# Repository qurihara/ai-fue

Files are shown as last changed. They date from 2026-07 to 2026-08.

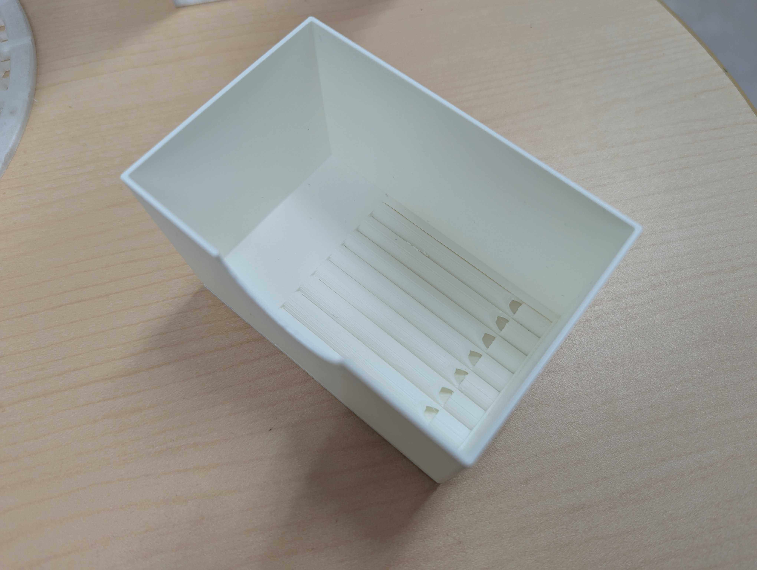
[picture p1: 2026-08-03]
paper/figs/2of3_box.jpg

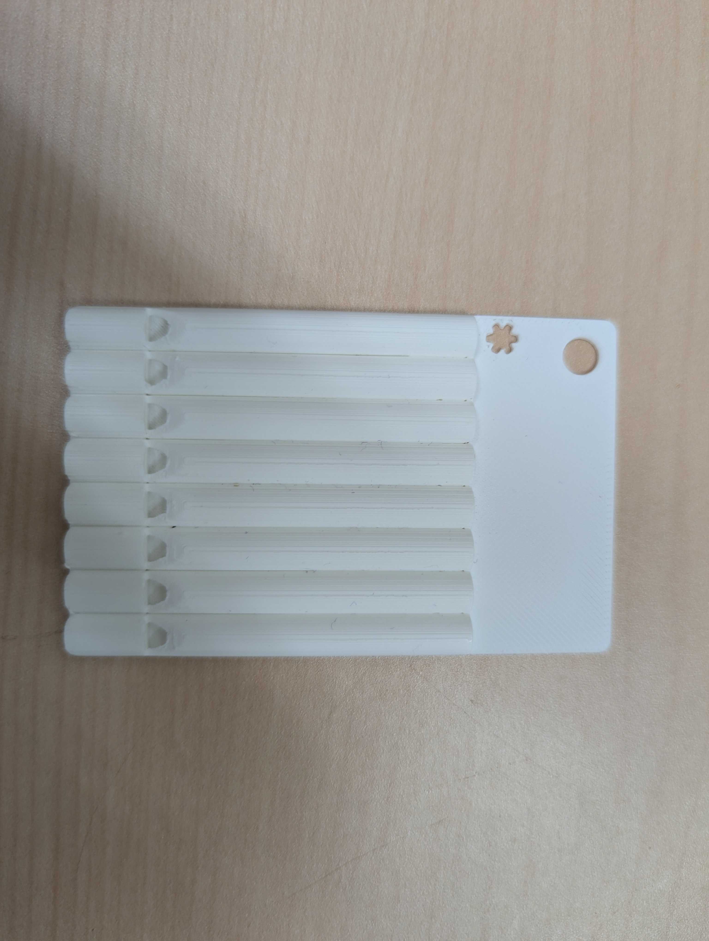
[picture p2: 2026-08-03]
paper/figs/card.jpg

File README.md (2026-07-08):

# ai-fue — AI笛作り (compact scale-flute generator)

3Dプリント可能な「音階笛」をプログラムで生成するツールキット。
[/kuri-lab/AI笛作り] の再始動プロジェクト。母体研究:
[2024夏→秋→2025夏、栗原の楽器作り研究] / https://protopedia.net/prototype/6821

## しくみ

1本の笛 = **発音ヘッド**（`recorderhead.stl`、経験的にF#チューニング済み）
＋ **ボア円柱**（高さ = チューニング表の `length_inside`）。
両者を z=0 に立て x/y 中央寄せし、メッシュを**そのまま結合**する。

> boolean union は使わない。BambuStudio 等のスライサがスライス時に重なりを
> union するため堅牢（2025年に FreeCAD の boolean が繰り返し壊れた反省）。
> 各プリミティブは個別に water-tight。

`recorderhead.stl` が `assets/` に無い間は、パイプライン検証用の
**プレースホルダヘッド**（音響的に無効・要差し替え）で動く。

## チューニング表 `data/tuning_fsharp.csv`

F#5..F#6 の13半音。列: `note, length_outside, length_inside, filename, note_in_c`。
合計100mm（`length_outside + length_inside = 100`）。`length_inside` が印刷する円柱高。

## ToneDecoder 互換

`fue/notes.py` が音階↔MIDI↔hex を一元管理（auth.html とバイト互換）。
「パスワード」= MIDIノート列のhex表記。例 `5558564F` = MIDI 85,88,86,79 = C#6 E6 D6 G5。
https://github.com/qurihara/ToneDecoder

## 使い方

```bash
# パスワード(hex)から笛を生成（リボルバー配置）
python3 fue/build.py --pass-hex 5558564F --style ring

# 音階列から（1UPキノコ）
python3 fue/build.py --notes "C6 G#5 A#5 C6 A#5 C6" --style ring

# パンフルート列
python3 fue/build.py --notes "F#5 G5 A5 B5" --style row

# 別の本体STLを使う（既定は assets/body_v6.stl）
python3 fue/build.py --pass-hex 5558564F --body assets/body_v6.stl
```

出力は `out/` に STL。`--style ring` は回して吹く用の円環、`--style row` はパンフルート列。
F#5..F#6 の外の音は自動で演奏可能オクターブに折り返す。

STLを保存すると同時に、A1 miniでそのまま印刷できる 3mf（`out/<名前>_a1mini.3mf`）も自動で書き出す（`--no-3mf` で抑止）。
既存のSTLから単体で作るときは次のようにする。

```bash
python3 fue/make_3mf.py out/flute_ring_5558564F.stl                 # A1 mini（既定）
python3 fue/make_3mf.py out/compact_calibration_comb.stl --printer h2d   # H2D
```

### 3mf の作り方（導電性ゲームコントローラの方式を踏襲）

Bambu Studio が実際に生成した動作実績のある3mfを骨組みとして持ち、形状とモデル設定だけを差し替える。

- **A1 mini**: 骨組みはコントローラ用3mf。印刷設定（`templates/a1mini_project_settings.config`）は
  単一フィラメント版に固定してあり、「mixed filament is not supported」で弾かれないようにしている。
  ベッド180×180の中央へ自動配置。BambuStudioのCLIでスライスが通り（return code 0）、G-codeまで生成できることを確認済み。
- **H2D**: 骨組みは栗原さんの印刷実績のあるH2D 3mf（`templates/h2d_skeleton.3mf`）。ベッド350×320の中央へ配置。
  H2Dはデュアル押出機のため、フィラメントの最終割り当ては Bambu Studio 側で調整する前提
  （MCP/CLIでのH2D自動スライスは現状通らないため、3mfの整形性のみ検証）。

### 音程測定・較正Webアプリ

`docs/index.html`（GitHub Pagesで公開）。印刷した笛を吹くと周波数と音名を測る。較正コームの各音を測って、
結果をコピーしてClaudeへ貼り付けると、管長と音程の対応表を作れる。音程検出は pitchy を使用（ToneDecoderと同系統）。

## 状態 / TODO

- [x] 音階↔MIDI↔hex マッピング（ToneDecoder互換・自己検証済み）
- [x] チューニング表復元
- [x] straight-bore 笛生成 + row/ring レイアウト + 台座（numpy-stl, water-tight検証）
- [x] 実機の笛本体 v6 を組み込み（本体＋内挿する棒＝length_inside）
- [x] A1 mini 印刷用 3mf の自動生成（CLIスライス通過を確認）
- [ ] 実機チューニング再検証（v6は再設計版のため旧F#表の再測定が必要）
- [x] **コンパクト化（目標①）**: 実績ヘッド＋必要長の閉管。棒も死んだ材料も無し。全長=26.5mm＋管長。管長60mmで全長86.5mm（従来169mmの約半分）
- [x] **管長↔音程の実測較正**（H2Dで4本測定、`f = 91891.5/(L+14.23)`、RMS 0.28mm。片閉じ管の1/4波長則）
- [x] **音階列→音程の合ったコンパクト笛**（`fue/compact.py --notes` / `--pass-hex`）
- [x] **ボア折返しで背を縮小**（`fue/fold.py`、trimesh+manifold3d）。C6は直管112mm→3折り54mm。サポート無しで印刷（要実機確認）
- [ ] 折り補正・細ボア・小ヘッドの実測較正（テストパネル `panel_fold_c6` / `panel_high_octave`）
- [x] **全体を直方体に統一（箱モジュール・A案）**（`fue/box.py`）。3モデル（折りなし/折り1/折り2）とも共通16mmフットプリントの直方体に。実績の円筒ヘッドを角shellで内包し窓面だけ開口＝音は不変で既存較正を流用
- [ ] **角ネイティブ フィッポルヘッド（B案）の実機ボイシング**（`fue/box.py --fipple-comb`）。円筒ヘッド不使用の完全一体押し出し。要 較正やり直し
- [ ] 断面の涙滴/菱形化
- [ ] ② リボルバー/ジェノバ回転機構、③ 3Dモデルへの秘密音階埋め込み

### コンパクト笛（目標①）

```bash
# 較正コーム（管長を変えた笛を一列に。1回印刷して各笛の音程を測り、管長↔音程の表を作る）
python3 fue/compact.py                      # 既定 管長 40,70,100,130mm の4本
python3 fue/compact.py --comb 40,80,120     # 本数を減らして時短

# 単一のコンパクト笛（管長を直接指定）
python3 fue/compact.py --single 60          # 全長 86.5mm

# 音階列から、音程の合ったコンパクト笛を生成（較正済み）
python3 fue/compact.py --notes "C6 D6 E6 F6 G6 A6 B6 C7" --style row   # ドレミの音階笛
python3 fue/compact.py --pass-hex 5558564F --style ring                # パスワードから
python3 fue/compact.py --notes "C6 D6 E6" --printer h2d                # H2D用3mf
```

較正式は `f = 91891.5 / (L + 14.23)`（L=管長mm, f=周波数Hz）。2026/7/1にH2Dで管長40/70/100/130mmの
4本を印刷し実測してフィットした（RMS 0.28mm）。片閉じ管の1/4波長則そのもので、端補正は約14mm。
`fue/compact.py` の `CALIB_K` / `CALIB_DELTA` に格納。再測定で更新できる。

`assets/head_v6.stl` は v6本体の上端26.5mm（吹き口＋ウインドウェイ＋フィッポル窓）を切り出した実績ヘッド。
その下へ必要な長さの中空管と閉端キャップを足す。管長と音程の対応は端補正等で物理式では正確に出ないため、
較正コームを印刷して実測で対応表を作る想定。音程が確定すれば、音階列から直接コンパクト笛の並びを生成できる。

### 箱モジュール（目標①・全体を直方体に）`fue/box.py`

小型笛の外形を1個の直方体に統一してモジュール性を上げる（スタック／タイル／目標③の3Dモデル埋め込みに直結）。
3モデル（折りなし／折り1／折り2）とも**共通フットプリント奥行き16mm**の直方体にする。折るほど背は低く・幅が広い。
実行には `fold.py` / `plenum.py` と同じ trimesh + manifold3d が要る。

```bash
# A案（推奨）: 実績の円筒ヘッドを角shellで内包し、窓面だけ凹ませて開口＝音は不変（既存較正を流用）
python3 fue/box.py --note C6 --N 1     # 折りなし   16×16×100mm
python3 fue/box.py --note C6 --N 2     # 折り1     22×16×69mm
python3 fue/box.py --note C6 --N 3     # 折り2     32×16×57mm
python3 fue/box.py --note C6 --panel   # 3モデルを同じ音で横一列（out/box_panel_C6.stl + a1mini.3mf）

# B案（実験的）: 角ネイティブのフィッポルヘッド（円筒ヘッド不使用の完全一体押し出し）。音は変わるので要 実機ボイシング
python3 fue/box.py --fipple-comb       # flue-labiumオフセットとcutupを振ったボイシング変奏コーム
```

A案は**円筒ヘッドとボアをそのまま内包**するので音響は不変。外側16角柱の四隅は詰め物になるが少量で、
窓（歌口）の1面だけ角shellを凹ませて噴流の前を開けてある（塞ぐと鳴らない）。まずA案で確実に一体化し、
B案は「鳴るボイシング」を変奏コームで見つけてから管長較正に進む2段構え。

### 極小笛 mini-c-v2 と パンフルート（目標①・最小化の本命）`fue/mini.py`

`mini/recorder-mini-c-v2.stl`（7×7×40mmの極小閉管リコーダー・印刷&発音実績）の発音ヘッドを
z=18で切り出し、上に任意長の閉じボアを生やして音程を振る。**flat（寝かせ印刷・窓横向き・丸ボアの
面内蛇行）** が本命で、横向き丸ボアがブリッジで架かるため実質サポートフリー・背が低く安定。

**実機較正（閉端・A1 mini）:** `ENDCORR=1.9`（端補正）＋ `FLAT_FOLD_CORR=3.5mm/折`（折り補正。折り1回
ごとに実効長が縮み音程が上がる。旧compact.pyの3.3mmと一致）。C6/E6は狙い±25c以内でドンピシャ。
発音性のスイートスポットは **N=2（1折り）**。高音(G6〜C7)はヘッド固有コア(≈F7)に近づくと不安定
＝1ヘッドの綺麗な帯域は約1オクターブ。2オクターブにはヘッドのサイズ違い（ファミリー化）が要る。

**端穴の教訓:** 蛇行の折り返し(半径r=3)が端キャップ(旧2mm)を突き抜けて+x端に穴が開いた
→ `H=z_high+r+end_wall(1.2)` で解決（flat_fluteは閉端）。

```bash
python3 fue/mini.py --flat --note C6 --flat 2      # 単一flat笛（面内蛇行N本）
python3 fue/mini.py --flat-comb                    # flat測定コーム(C7/A6/F6/C6)
python3 fue/mini.py --fold-sweep C6 --Ns 1,2,3     # 音固定・折り数スイープ（折り補正/発音性の計測）
python3 fue/mini.py --pan-flute                    # 1オクターブ パンフルート（z方向スタック・一体）
```

**パンフルート `pan_flute`:** 1オクターブ(C6..C7)の管を z方向に積んだ一体ブロック（土台なし・
51×14×56mm）。`mirror_y`（段ごとにy鏡像＝窓を+y/-yへ）でハーモニカ的な配置に、`notes` の並べ替えで
カリンバ配列などに。段間が近い(1mm壁)と音響結合してフラット化・偶数倍音が出るのが課題（互い違い等で回避を検討中）。

**A1 mini 印刷（MCP）:** 定着に必須の設定（ベッド65℃ Textured PEI＋ブリム＋support critical_regions_only）
を持つ `temp/box_brim_profile.json` に、開始gcode(M620 AMSロード＋G29)を移植した `temp/box_brim_ams_profile.json`
でスライス → `bambu-swaplist-batch` skillの `make_swap.py` でswap化 → `print_3mf(ams_slots=[0])`。
反復印刷はflow/振動キャリブOFF・レベリングON（同一フィラメントで流量キャリブ毎回は無駄）。

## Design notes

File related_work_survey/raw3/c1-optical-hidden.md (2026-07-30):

# 反例検証：「隠蔽と可読性の両立は光学符号には原理的に得られない」は成立するか

対象となる主張（CipherFlute側）
- 主張A：符号を担体の外観にまったく現さずに機械可読に保てる。光学的な符号は表面に露出していなければ読めないため日用品に埋めると読めなくなるが、共鳴管は物体の内部空洞として存在でき、外部に必要なのは窓と吸込口という小さな開口だけである。この隠蔽と可読性の両立は光学符号には原理的に得られない構造的な差である。
- 主張B：既知の値を持つ基準素子を同じ物体に同居させ、比で読んで環境変動を打ち消すという構造的な自己補正は、造形物への情報埋め込みの文脈で前例がない。

評価者の反論
- AirCodeは符号を表面下の空隙として埋め、通常照明下では外観を変えず、投影と撮影で機械可読にしている。
- InfraredTagsは肉眼では見えない内部のQRコードやArUcoマーカーを低価格の近赤外カメラで最大250センチメートルから読む。
- したがって「符号が表面に露出していなければ光学的に読めない」という前提自体が偽である。

結論を先に書く。**この反論は正しい。** 主張Aのうち「光学的な符号は表面に露出していなければ読めない」という前提は、一次資料に当たると成り立たない。したがって「隠蔽と可読性の両立は光学符号には原理的に得られない」という主張Aは撤回する必要がある。ただし、両方式には材料と読み取り装置に関する強い制約があり、そこにCipherFluteとの差分が残る。以下、一次資料の記述で確認した内容を順に書く。

---

## 1. 書誌の確認

### AirCode

| 項目 | 内容 |
| --- | --- |
| 題名 | AirCode: Unobtrusive Physical Tags for Digital Fabrication |
| 著者 | Dingzeyu Li, Avinash S. Nair, Shree K. Nayar, Changxi Zheng（Columbia University） |
| 会議 | Proceedings of the 30th Annual ACM Symposium on User Interface Software and Technology（UIST 2017） |
| 年・ページ | 2017年、449〜460ページ |
| DOI | 10.1145/3126594.3126635 |

確認先
- Crossref（DOIの解決先）：https://api.crossref.org/works/10.1145/3126594.3126635
- DBLP：https://dblp.org/search/publ/api?q=AirCode%20Unobtrusive%20Physical%20Tags&format=json
- 著者公開版（arXiv、本文と補足資料を含む）：https://arxiv.org/abs/1707.05754 および https://arxiv.org/pdf/1707.05754

以下の引用はすべてarXiv版（1707.05754v2）の本文から取った。arXiv版の1ページ目に `DOI: https://doi.org/10.1145/3126594.3126635` が印字されており、UIST 2017版と同一の原稿であると判断した。なお、ACM Digital Libraryの本文ページは取得時にHTTP 403を返したため、出版社ページ本体は読めていない。

### InfraredTags

| 項目 | 内容 |
| --- | --- |
| 題名 | InfraredTags: Embedding Invisible AR Markers and Barcodes Using Low-Cost, Infrared-Based 3D Printing and Imaging Tools |
| 著者 | Mustafa Doga Dogan, Ahmad Taka, Michael Lu, Yunyi Zhu, Akshat Kumar, Aakar Gupta, Stefanie Mueller（Aakar Guptaのみ Facebook Reality Labs、他はMIT CSAIL） |
| 会議 | CHI Conference on Human Factors in Computing Systems（CHI '22）、2022年4月29日〜5月5日、New Orleans |
| 論文番号・ページ | Article 269、12ページ |
| DOI | 10.1145/3491102.3501951 |

確認先
- DBLP：https://dblp.org/search/publ/api?q=InfraredTags+Embedding+Invisible+AR+Markers&format=json
- 著者公開版（MIT CSAIL HCI Engineering Group）：https://hcie.csail.mit.edu/research/infraredtags/infraredtags.html
- 本文PDF：https://groups.csail.mit.edu/hcie/files/research-projects/infraredtags/2022-CHI-InfraredTags-paper.pdf

以下の引用はこの著者公開版PDFから取った。

---

## 2. AirCodeのタグは肉眼で見えないのか

### 論文が外観について述べていること

見えないと明言している。原文をそのまま引く（訳は筆者による）。

図1のキャプション（1ページ目）
> "An AirCode tag is embedded inside the object, without changing its geometry or appearance. (d) The fabricated tag is invisible under environmental lighting."

（AirCodeタグは物体の内部に埋め込まれ、その形状も外観も変えない。(d) 製造されたタグは環境光の下では見えない。）

概要
> "the air pockets affect only the scattering light transport under the surface, and thus are hard to notice to our naked eyes. But, by using a computational imaging method, the tags become detectable."

（空気ポケットは表面下の散乱光輸送だけに影響するので、肉眼では気づきにくい。しかし計算撮像の手法を使えば、タグは検出可能になる。）

不可視性を数値で担保している箇所（Human Vision Sensitivityの節）
> "Exploiting the results of [2], we choose air pocket size and depth such that the resulting contrast (or the change of surface radiosity) is within 5%. This way, by construction the air pockets are invisible to the human eye"

（[2]の結果を利用し、生じるコントラスト（すなわち表面放射輝度の変化）が5%以内になるように空気ポケットの大きさと深さを選ぶ。こうすることで、構成上、空気ポケットは人間の目には見えないものになる。）

ここでいう5%は、Bijlらの心理物理実験で示されたガウシアン状のぼやけた斑点に対する人間のコントラスト感度閾値である。論文はさらに、極端な照明下でも見えないままであることを実験で確認したと書いている（補足資料の図18のキャプション）。

> "Under different extreme lighting, the embedded AirCode tags remain invisible. We capture these photos while moving a strong light source around the statue and the mug. The light source we use is a 45W photography light bulb at 6500K."

（さまざまな極端な照明の下でも、埋め込まれたAirCodeタグは見えないままである。これらの写真は、強い光源を彫像とマグカップの周りで動かしながら撮影した。使用した光源は6500Kの45Wの撮影用電球である。）

### 判定

「AirCodeのタグは通常照明下で肉眼に見えない」という評価者の指摘は、論文の記述どおりであり、正しい。

---

## 3. AirCodeの読み出しに何が必要か

### 装置の構成

Fabrication and Imaging Setupの節に明記されている。

> "For global component imaging, we project checkerboard illumination patterns using a Mitsubishi PK20 DLP projector (800×600 resolution). Images were captured using a Point Grey Grasshopper3 monochrome linear camera (2048×1536 resolution). We use a monochrome camera to avoid Bayer demosaicing, as we consider scattering at a single wavelength."

したがって必要なのは、DLPプロジェクタ1台（三菱PK20、800×600）と、モノクロ産業用カメラ1台（Point Grey Grasshopper3、2048×1536）である。さらに次の2つが加わる。

偏光板について（Polarizationの節）
> "We mitigate the negative effect of specular light by placing linear polarizers in front of both the projector and the camera lens [41, 6]. ... we place the two polarizers that are out of phase with each other to maximally eliminate the specular light."

（プロジェクタとカメラレンズの両方の前に直線偏光板を置く。2枚の偏光板は互いに位相をずらして配置し、鏡面反射光を最大限に取り除く。）

波長について（Wavelength Choiceの節）
> "we take advantage of our full control of the projector and illuminate the object with the longest light wavelength, the red light. ... In all of our imaging experiments, we use red light unless otherwise specified."

（プロジェクタを完全に制御できることを活かし、最も長い波長である赤色光で物体を照らす。すべての撮像実験では、特に断らない限り赤色光を使う。）

つまり、プロジェクタとカメラと交差偏光板からなる据え置きの光学ベンチを構成し、赤色の市松模様を何度もずらしながら投影して、NayarらのDirect-Global分離を行う。手に持って向けるだけの装置ではない。

### 撮像にかかる時間

Discussion and Future Workの節に明記されている。

> "the capturing process still takes 3-4 minutes. This is because a checkerboard sweeping takes about 10 seconds. To reduce imaging noise, we take multiple sweeps and average them."

（撮像の処理には依然として3〜4分かかる。市松模様の走査1回に約10秒かかるためである。撮像ノイズを減らすため、複数回の走査を行って平均する。）

さらにノイズ対策として、Fabrication and Imaging Setupの節に次の記述がある。

> "Under low-light, the output from this camera sensor is noisy. We, therefore, averaged 16 images for each projected checkerboard pattern."

（低照度ではこのカメラセンサの出力はノイズが多い。そのため、投影する市松模様1枚ごとに16枚の画像を平均した。）

InfraredTags側もAirCodeの所要時間を表1で「3-4 minutes」と記載しており、2つの一次資料で一致している。

### 物体との距離

**確認できなかった。** 論文には、カメラおよびプロジェクタと物体との距離を示す数値が見当たらない。論文中に出てくる75センチメートルという数値は、カメラの距離ではなく、人間がタグを見るときの標準的な視距離として不可視性の解析に使われたものである。

> "In our problem, an AirCode tag has a size typically around 2cm. When viewed from a normal distance (e.g., around 75cm) away, the view angle spanned by the codes is around 100 min arc."

代わりに論文が示しているのは角度の許容範囲である。

> "Figure 17 shows that our method is able to read the subsurface codes for rotations in the range of [-40, 40] with respect to the camera view direction."

（図17は、カメラの視線方向に対して[-40度, 40度]の範囲の回転であれば表面下の符号を読めることを示している。）

### 必要な照明条件

論文は読み取り時の周囲照度を数値で規定していない。ただし方式上、プロジェクタが投じる構造化光そのものが照明であり、そのうえで低照度でのセンサノイズを16枚平均で潰していると書かれている。したがって、周囲の環境光は制御された（暗めの）状態が前提だと読める。この点は論文が明示的に書いていないので、推測であることを断っておく。

### 材料と製造装置の制約（重要）

AirCodeが機能する条件は、材料が均質で半透明であることに強く依存する。

> "We fabricated objects with subsurface air pocket tags using Stratasys Eden260VS, a PolyJet 3D printer with 16-micron layer accuracy (Z direction) and 200-micron planar accuracy (XY plane). We use a white opaque material (VeroWhitePlus, RGD835) and a water-soluble support material (SUP707)."

限界について、論文自身が次のように書いている。

> "Our analysis assumes that the 3D printing material is largely homogeneous and semitransparent. While this assumption is valid for many 3D printing systems that fabricate with plastic materials, other printers cannot produce nearly homogeneous materials. For example, many fused-deposition modeling (FDM) printers deposit relatively thick filaments, and the printed object is not homogeneous. Moreover, it is a common postprocess to paint the surface of a 3D printed object. While our method can account for semitransparent paint, it will fail if the paint is completely opaque."

（我々の解析は、3Dプリント材料がおおむね均質で半透明であることを仮定している。この仮定はプラスチックで造形する多くの3Dプリント方式では妥当だが、他のプリンタではほぼ均質な材料を作れない。たとえば多くの熱溶解積層方式のプリンタは比較的太いフィラメントを積むため、造形物は均質にならない。さらに、3Dプリント物の表面を塗装するのは一般的な後処理である。半透明の塗料なら我々の手法で扱えるが、完全に不透明な塗料であれば失敗する。）

またタグの深さは表面直下に限られる。透過アルベドの解析から `dmax = 3mm`、機械的強度から `dmin = 1mm` と定めている。タグの寸法は2センチメートル角で約106ビット、5センチメートル角で500ビット超である。

---

## 4. InfraredTagsは肉眼で見えないのか

見えないと明言している。概要の冒頭に次のようにある。

> "We present InfraredTags, which are 2D markers and barcodes imperceptible to the naked eye that can be 3D printed as part of objects, and detected rapidly by low-cost near-infrared cameras."

（InfraredTagsを提案する。これは肉眼では知覚できない2次元マーカーおよびバーコードであり、物体の一部として3Dプリントでき、低価格の近赤外カメラで素早く検出できる。）

不可視性の担保も、AirCodeと同じ5%のコントラスト閾値で行っている（Shell Thicknessの節）。

> "our goal is to find a value that achieves a contrast in the image smaller than 5% when the image is taken with a regular camera (i.e., with an IR cut-off filter). ... We chose 5% because this is the contrast value at which humans cannot differentiate contrast anymore [3]."

具体的な殻の厚さは表2にある。単一材料（IR PLAのみ）で殻1.08ミリメートル・符号2.00ミリメートル、多材料（IR PLA＋白PLA）で殻1.32ミリメートル・符号0.50ミリメートル、IR PLA＋黒PLAで殻1.08ミリメートル、IR PLA＋青PLAで殻1.20ミリメートルである。

ここで見落としてはならないのは、母材そのものの制約である。

> "We acquired the IR filament from manufacturer 3dk.berlin [1] (ca. $5.86/100g). It is made out of polylactic acid (PLA) ... To the naked eye, the filament has a slightly translucent black color, however, when 3D printed in multiple layers it looks opaque."

さらに議論の節で、色が黒に限られることを認めている。

> "While we only used black IR PLA in this project, manufacturers could produce filaments of other colors that have similar transmission characteristics"

つまり、物体全体を特定メーカーの黒い赤外透過フィラメントで印刷しなければならない。任意の材料・任意の色の日用品に後から埋めることはできない。

---

## 5. InfraredTagsの読み出しに何が必要か

### 市販のスマートフォン単体で読めるのか

**読めない。追加の撮像モジュールが要る。** 論文は明確に、専用の後付けモジュールを自作したと書いている。

> "Today, several recent smartphones already come with an IR camera either on the front (Apple iPhone X) or the rear (OnePlus 8 Pro), however, the phones' APIs may not allow developers to access these for non-native applications. Furthermore, not all mobile phones contain such a camera at the moment. To make our method compatible independent of the platform, we built an additional imaging add-on that can easily be attached to existing mobile phones."

（今日、いくつかの最近のスマートフォンは前面（iPhone X）または背面（OnePlus 8 Pro）に赤外カメラを備えている。しかし、電話機の提供する応用機能の窓口が、開発者に対してこれらを純正以外の応用から使わせない可能性がある。さらに、現時点ではすべての携帯電話がそうしたカメラを備えているわけではない。手法を機種に依存しないようにするため、既存の携帯電話に簡単に取り付けられる追加の撮像用付属品を作った。）

モジュールの構成（Attaching the IR camera moduleの節）
> "our add-on contains an infrared camera (model: Raspberry Pi NoIR). This camera can see infrared light since it has the IR cut-off filter removed that normally blocks IR light in regular cameras. Additionally, to remove the noise from visible light and improve detection, we added a visible light cut-off filter, as well as 2 IR LEDs (940nm) which illuminate the object when it is dark. This add-on has two 3D printed parts: a smartphone case from flexible TPU filament that can be reprinted based on the user's phone model, and the imaging module from rigid PLA filament that can be slid into this case. The imaging module has a Raspberry Pi Zero board and a battery and weighs 132g."

したがって必要なものは、赤外カットフィルタを外したカメラ（Raspberry Pi NoIR）、可視光カットフィルタ、940ナノメートルの赤外発光ダイオード2個、Raspberry Pi Zero基板、電池、そしてTPUで印刷した専用ケースである。

加えて、処理は端末上で完結しない。

> "the imaging module continuously streams the images to our image processing server. If the server detects any tags, it sends the location and the encoded message to the smartphone app to show to the user."

（撮像モジュールは画像を我々の画像処理サーバへ連続的に送り続ける。サーバがタグを検出すれば、位置と符号化されたメッセージをスマートフォンの応用へ送り、利用者に表示する。）

なお論文は、赤外カットフィルタを手で外した通常のUSBウェブカメラでも読めると述べている。

> "Even conventional USB webcams for personal computers can be used for this purpose by manually removing their infrared cut-off filter."

いずれにせよ、改造していない市販のスマートフォンだけでは読めない。

### 費用と重さ

- 赤外透過フィラメント：100グラムあたり約5.86米ドル（"ca. $5.86/100g"）
- Raspberry Pi NoIRカメラ：約20米ドル（"such as the Raspberry Pi NoIR ($20)"）
- 比較対象として挙げられている高価な赤外カメラ：FLIR ONE Proが400米ドル超（"may cost more than $400"）
- 撮像モジュールの重さ：132グラム（"weighs 132g"）
- **モジュール全体の合計費用は確認できなかった。** 論文はカメラ単体とフィラメントの価格しか書いておらず、可視光カットフィルタ、Raspberry Pi Zero、電池を含む総額を示していない。

### 必要な近赤外の照度

Lighting conditionsの節に数値がある。

> "We measured the minimum NIR intensity needed to detect 4x4 ArUco markers using a lux meter which had a visible light cut-off filter (720nm) attached. We found that just a tiny amount of NIR is sufficient for this, i.e., that at least 1.1 lux is needed for single-material prints, and 0.2 lux for multi-material prints."

（720ナノメートルの可視光カットフィルタを取り付けた照度計を使い、4×4のArUcoマーカーを検出するのに必要な最小の近赤外強度を測った。ごくわずかな近赤外で十分であり、単一材料の造形物には少なくとも1.1ルクス、多材料の造形物には0.2ルクスが必要だと分かった。）

続けて、実運用の照明環境についても書いている。

> "Because sunlight also contains NIR wavelengths, the tags are detectable outdoors and also in an indoor areas that have windows during daytime. We also noticed that many lamps used for indoor lighting emit enough NIR to detect the codes at nighttime (e.g., 1.5 lux in our office). Furthermore, the IR LEDs on our imaging module (Section 4.2) provide high enough intensity to sufficiently illuminate multi-material markers even in complete darkness"

つまり、屋外や窓のある屋内では太陽光の近赤外成分で足り、夜間も一般的な室内照明の近赤外成分（著者らの居室で1.5ルクス）で足り、完全な暗闇でもモジュール上の赤外発光ダイオードで多材料の符号なら読める。単一材料の場合は完全な暗闇では不足すると認めている。

> "In the future, brighter LEDs can be added to support single-material prints in such difficult detection scenarios."

### 読み取り距離

概要に「250センチメートル」がある。

> "Our evaluation shows that the tags can be detected with little near-infrared illumination (0.2lux) and from distances as far as 250cm."

本文のDistanceの段落によれば、この評価は4×4のArUcoマーカーについて、マーカーの幅を10ミリメートルから80ミリメートルまで振って最大検出距離を測ったものである。

> "The marker size range we evaluated was 10-80mm for 4x4 ArUco markers, which would translate to a range for 42-336mm for 21x21 QR codes (can store up to 25 numeric characters). The results are given in Figure 10a, which shows that multi-material codes can be detected from further away than single single-material ones."

**どのマーカー寸法で250センチメートルに達したのかは、図10aが図版であるため本文の文字情報からは確認できなかった。** 250センチメートルは評価した範囲の最大値であり、マーカーの大きさに依存する値である点は注意が要る。QRコードの検出精度を測った実験は15センチメートルから80センチメートルの範囲で行われている。

> "We captured 124 images of a 21x21 QR code from different distances (15-80cm from the camera)."

その条件でのQRコードの復号精度は、フィルタのパラメータの組み合わせを3通り試して79.03%である（表3）。

### 復号にかかる時間

> "On average, it takes 6ms to decode a 4x4 ArUco marker and 14ms to decode a 21x21 QR code from a single original frame. The images we use as input are 512x288 pixels"

単一のフレームから復号するので、実時間で動く。これはAirCodeの3〜4分と比べて桁違いに速く、CipherFluteの吹奏による読み出しよりも速い。

### 最小のマーカー寸法

> "we determined that the smallest detectable 4x4 ArUco marker printable is 9mm wide for single-material prints and 6mm wide for multi-material prints."

---

## 6. 日用品に埋め込んだ実例はあるか

### AirCode

論文が示す実物は、Moai像、三角形の引き出し、マグカップ、iPhoneを支える猫の置物、ケーブル収納、工具立て、そして紙の透かしである。マグカップや引き出しは日用品と呼べる。ただし、これらはすべて著者らがPolyJetプリンタ（Stratasys Eden260VS）でVeroWhitePlusを使って自ら造形したものである。既製の日用品にあとから埋め込んだ例ではない。

> "We demonstrate with two objects (see Figure 3). In the triangular drawer (Figure 3-a), we embed three different AirCode tags on each side of the drawer. In the mug (Figure 3-b), we embed six tags under the curved surface of the mug."

紙への拡張だけは材料が異なる。

> "here we embed watermarks in a paper by stacking a few thinner papers together. We carve a pattern on one paper and sandwich it in other papers, and then stick all thin papers together."

### InfraredTags

応用の節で、家庭用スピーカー、サーモスタット、無線ルータ、マグカップ、ゲーム用のハンドルを示している。

> "In the application shown in Figure 7a and b, a user points their smartphone camera at the room and smart home appliances are identified through their InfraredTags, which are imperceptible to the human eye."

> "Figure 9 shows a 3D printed wheel with no electronics, being used as a game controller."

これらも、方式の制約上、黒い赤外透過PLAで印刷した筐体でなければならない。論文は既製の家電の元の筐体に埋め込んだとは書いていない。

### まとめ

**両者とも日用品の形をした造形物への埋め込みは示している。ただし、どちらも「その方式が要求する特定の材料で自ら造形した物体」に限られており、任意の材料でできた既製の日用品にあとから埋める例は示していない。**

---

## 7. 判定

### 主張Aについて

**反論は正しい。主張Aは成立しない。**

主張Aの中核は「光学的な符号は表面に露出していなければ読めない」という前提にある。この前提は偽である。AirCodeは表面から1〜3ミリメートルの深さにある空気ポケットを、投影と撮影による大域成分の分離で読む。InfraredTagsは表面から1.08〜1.32ミリメートルの殻の内側にあるQRコードやArUcoマーカーを、近赤外カメラで読む。どちらも肉眼のコントラスト閾値5%を下回るように設計されており、外観を変えていない。したがって「隠蔽と可読性の両立は光学符号には原理的に得られない」とは書けない。

さらに、主張Aの言い回しにはCipherFluteにとって不利な事実が隠れている。AirCodeとInfraredTagsは外部に開口をまったく必要としない。CipherFluteは窓と吸込口という2つの開口を外気に露出させなければならない。「外部に必要なのは小さな開口だけである」という言い方は、開口が不要な方式が実在する以上、優位性の主張にならない。むしろ外観の点では、CipherFluteのほうが露出が多い。

### 主張Bについて

**この反例の検証中に、主張Bも強い形では成り立たないことが分かった。**

AirCodeは、符号の格子の中に「既知の値を持つセル」を散らして配置し、それを使って復号器を現場で訓練している。Code Generationの節に次のようにある。

> "More remarkably, we place a few known bits. The blue cells are always filled with printing material as bits of 1, while the orange cells are filled with air pockets to indicate bits of 0. These bits are scattered on the grid to enable on-the-fly supervised training for our decoding algorithm."

（さらに注目すべきこととして、いくつかの既知のビットを配置する。青いセルは常に造形材料で埋めて1のビットとし、オレンジのセルは空気ポケットで埋めて0のビットとする。これらのビットは格子上に散らして配置され、復号アルゴリズムのその場での教師あり学習を可能にする。）

Decodingの節では、この既知ビットで訓練した分類器の特徴量を局所的な明るさの変化に合わせて正規化するとも書いている。

> "Each feature vector is normalized to adapt to local intensity changes."

これは、既知の値を持つ基準素子を同じ物体に同居させ、データと同時に読んで撮像条件と造形の個体差を打ち消す仕組みである。CipherFluteの基準笛とは、補正する物理量（一方は画像の明るさ、他方は音速すなわち気温と息の強さ）も、補正の演算（一方は分類器の訓練と正規化、他方は周波数の比）も異なる。しかし「同一物体に既知の基準を同居させて環境変動を吸収する」という構造そのものには前例がある。したがって「前例がない」とは書けない。「既存例は撮像系の変動を吸収するために使われており、担体の物理量（気温による音速変化）を打ち消すために基準素子の比を使った例は見当たらない」という程度まで主張を弱める必要がある。ただし、造形物への情報埋め込みの文献を網羅的に調べたわけではないので、この弱めた形が成立するかどうかは別途の確認が要る。

---

## 8. CipherFluteに残る差分

主張Aは撤回するとして、では何が残るのか。依頼された4つの観点で整理する。誇張も過小評価もせずに書く。

### 8.1 装置の必要性

**ここが最大の残る差分である。**

- AirCodeは、DLPプロジェクタ（三菱PK20）、モノクロ産業用カメラ（Point Grey Grasshopper3）、両者の前に置く交差した直線偏光板からなる据え置きの光学ベンチを必要とする。手持ちで物体に向けるという使い方はできない。
- InfraredTagsは、赤外カットフィルタを外したカメラ、可視光カットフィルタ、940ナノメートルの赤外発光ダイオード2個、Raspberry Pi Zero、電池を組んだ132グラムの付属品をスマートフォンに装着する必要がある。さらに画像処理はサーバ側で行う構成になっている。改造していない市販スマートフォン単体では読めない。
- CipherFluteは、利用者が既に持っているスマートフォンのマイクだけで読む。追加の部品も、改造も、専用のフィラメントも要らない。

**この差は「原理的」ではなく「装置の入手性と携帯性」の差である。** 光学で隠しつつ読むことは可能だが、そのために専用の撮像系が要る。音響で読むのは、既存の端末に既に載っている入力装置で足りる。主張は「光学では不可能」ではなく「光学では専用装置が要るが、音響では要らない」という形に書き換えるべきである。

なお、CipherFlute側の論文はこの点を既に第4章の性質(4)として「特別な機器なしに、息とスマートフォンだけで復元できる」と書いている。この記述は一次資料に照らして妥当であり、変更の必要はない。

### 8.2 読み出しの時間

**ここはCipherFluteが一方的に有利とは言えない。正直に書く必要がある。**

- AirCodeは3〜4分かかる。CipherFluteより明らかに遅い。
- InfraredTagsは1フレームから復号し、4×4のArUcoマーカーで6ミリ秒、21×21のQRコードで14ミリ秒である。実時間で動く。CipherFluteは笛を1本ずつ吹いて読むため、本数に比例した秒単位の時間がかかる。**InfraredTagsのほうが速い。**

したがって「光学は遅い」と一般化してはならない。AirCodeに限れば遅いが、それはAirCodeが構造化光の掃引を必要とするからであり、InfraredTagsはその問題を解いている。InfraredTags自身が表1で、AirCodeの「3-4 minutes」やInfraStructsの「2 minutes for a 100x100 pixel scan」に対して自分たちは「On the order of milliseconds」だと明示的に比較している。

### 8.3 外観

**ここもCipherFluteが有利とは言えない。**

- AirCodeとInfraredTagsは、いずれも肉眼のコントラスト閾値5%を下回るように設計されており、外部に開口をまったく持たない。外観上、符号の存在はどこにも現れない。
- CipherFluteは、窓と吸込口という2つの開口を外気に露出させなければならない。開口自体は小さいが、ゼロではない。

CipherFluteに残る外観上の利点は、符号の見えなさではなく、**材料と色の自由度**である。

- AirCodeは、均質で半透明な材料（PolyJet方式のVeroWhitePlusなど）を要求する。論文自身が、熱溶解積層方式では材料が均質にならないこと、不透明な塗装をすると失敗することを限界として認めている。
- InfraredTagsは、特定メーカーの赤外透過PLA（3dk.berlin製、黒）で物体全体を印刷することを要求する。論文自身が、他の色は今後の課題だと書いている。加えて、同じメーカーの異なる時期のスプールで透過特性が変わったので、スプールごとに較正をやり直すよう勧めている。
- CipherFluteは共鳴管の形状だけで符号を担うので、材料の光学的性質に依存しない。PLA、PETG、TPU、金属、どの色でも原理的には成り立つ。この点は、家庭用の3Dプリンタで、手元にある任意のフィラメントで作れるという実用上の差につながる。

したがって主張は「外観に符号が現れない」ではなく、「符号の担い手が形状であるため、担体の材料と色を選ばない」と書き換えるべきである。

### 8.4 読み出しの行為

**ここは構造的な差として残る。**

AirCodeもInfraredTagsも、読み出しは無音であり、所有者の身体的な関与を必要としない。装置を持ち、どこに向ければよいかを知っている者が、物体に触れることなく、所有者に気づかれずに読める。AirCodeは物体を光学ベンチに置く必要があるので実際には持ち去りが要るが、InfraredTagsは最大250センチメートル離れた位置から読める。

CipherFluteは、誰かが息を吹き込まなければ音が出ない。読み出しは必ず能動的な身体行為を伴い、その行為は音として周囲に露出する。これは秘匿の仕組みではなく手続きの性質であり、CipherFlute側の論文が既に性質(3)として「正規の読み出しが目立つ」と書いているとおりである。立会人の前で儀式として実行できるという利点も、この性質から出る。

ただし、この差を過大評価してはならない。CipherFlute側の論文が第4章で自ら明示しているとおり、管の長さは静的な形状なので、攻撃者は吹かずにノギスや透過撮像で読める。つまり「吹かなければ読めない」わけではない。残るのは「正規の手続きが音を伴う」という一点だけであり、攻撃者に対する防御にはならない。

なお、InfraredTags自身も発見しやすさの問題を限界として認めている。

> "For InfraredTags to be detected, the user should orient the near-infrared camera such that the embedded marker is in the frame. However, similar to related projects such as AirCode [20] and InfraStructs [34], this might be challenging since the marker is invisible to users and thus they might not know where exactly on the object to point the camera at."

これは光学方式にとって不利な点だが、CipherFluteの窓と吸込口も同じ問題を抱える（どの開口を吹けばよいか分からない）ので、差分にはならない。

---

## 9. 論文への具体的な反映案

1. 「隠蔽と可読性の両立は光学符号には原理的に得られない」という文は削除する。一次資料に照らして偽である。
2. 代わりに、光学方式との差を次の3点に絞って書く。第一に、読み出し装置が既存のスマートフォンのマイクで足り、専用の撮像系（プロジェクタとカメラの光学ベンチ、または赤外カメラ付属品）を必要としないこと。第二に、符号の担い手が形状であるため、担体の材料と色を選ばず、任意の家庭用フィラメントで作れること。第三に、正規の読み出しが能動的な吹奏を伴い、音として露出すること。
3. 読み出しの速さは差分として主張しない。InfraredTagsはミリ秒で読む。
4. 外観については「符号がまったく見えない」を主張しない。窓と吸込口は露出する。AirCodeとInfraredTagsは開口ゼロである。
5. InfraredTags（Doganら、CHI 2022、DOI 10.1145/3491102.3501951）を関連研究に追加する。現行稿はAirCode（文献[3]）とInfraStructs（文献[4]）しか挙げていないが、InfraredTagsは「安価な装置で速く読める隠された光学符号」という最も強い比較対象であり、これを挙げずに光学方式の限界を論じると、査読で必ず指摘される。
6. 基準笛の自己補正について「前例がない」とは書かない。AirCodeが既知ビットによる現場訓練という形で同種の仕組みを持っている。「撮像系の変動を吸収する既知ビットの例はあるが、担体の物理量（気温による音速変化）を比で打ち消す例は見当たらない」という限定した書き方にする。

---

## 10. 確認できなかったこと

- ACM Digital Libraryの本文ページは、AirCode・InfraredTagsとも取得時にHTTP 403を返したため読めていない。書誌はCrossrefとDBLPで、本文は著者公開版（arXivおよびMIT CSAILの公開PDF）で確認した。
- AirCodeにおける、カメラおよびプロジェクタと物体との距離は、論文に数値が見当たらない。
- AirCodeの読み取り時に必要な周囲照度は、論文に数値が見当たらない。
- InfraredTagsの撮像モジュール全体の合計費用は、論文に記載がない。カメラ単体20米ドルとフィラメント100グラム約5.86米ドルのみが示されている。
- InfraredTagsの250センチメートルという最大検出距離が、どのマーカー寸法に対応するかは、図10aが図版であるため文字情報から特定できなかった。評価したマーカー幅の範囲は10〜80ミリメートルである。
- 主張Bを弱めた形（担体の物理量を基準素子の比で打ち消す例の有無）については、造形物への情報埋め込みの文献を網羅的に調べていないため、成立するかどうかを判定していない。

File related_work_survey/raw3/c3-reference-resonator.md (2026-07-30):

# C3　反例検証：基準共鳴器を同居させて比で読み共通モードを除く設計

対象とする主張は、CipherFluteの新規性主張のうち「既知の値を持つ基準素子を同じ物体に同居させ、比で読んで環境変動を打ち消すという構造的な自己補正は、造形物への情報埋め込みの文脈で前例がない」という部分である。評価者はこれに対して、Smith と Senturia が1995年に同じ構成を「conventional sensing setup」と呼んでいること、および2014年に表面弾性波共鳴器の一方を基準に使う無線受動センサが実装されていることを反例として挙げた。

調査日は2026年7月30日である。

## 0. 結論

反例は正しい。評価者が挙げた2件はどちらも実在し、内容も評価者の説明どおりである。とくにSmithとSenturiaの論文は、基準共鳴器と検出共鳴器の二つを置いて比を取る構成を、自分たちの新規性としてではなく前提となる「従来の構成」として明示的に記述している。したがって「基準素子を同居させ比で読んで共通モードを打ち消す」という着想そのものをCipherFluteの新規性として主張することは成立しない。ただし後述するとおり、主張を「共鳴管を3Dプリントで一体成形した情報担体における実装と、そのもとでの読み取り誤り率の測定」に限定して書き換えれば、誇張のない形で残せる。

## 1. 反例1：Smith と Senturia（1995年）

### 1.1 書誌の確定

- 著者は James H. Smith（Sandia National Laboratories）と Stephen D. Senturia（Massachusetts Institute of Technology）である。
- 題名は "Self-Consistent Temperature Compensation for Resonant Sensors with Application to Quartz Bulk Acoustic Wave Chemical Sensors" である。
- 掲載は Proceedings of the International Solid-State Sensors and Actuators Conference（TRANSDUCERS '95）、開催地はスウェーデンのストックホルム、掲載ページは724ページから727ページ、発行者は IEEE、発行年は1995年である。
- デジタルオブジェクト識別子は 10.1109/SENSOR.1995.721934 である。

確認先は次の2つである。

- 著者所属機関が公開している原稿本文（Sandia National Laboratories）: https://www.sandia.gov/app/uploads/sites/145/2021/11/5_7SelfConsistent.pdf
- Crossref の書誌レコード: https://api.crossref.org/works/10.1109/sensor.1995.721934

Sandiaが公開している原稿の1ページ目の版面上部には "Transducers, June 1995." と刷られており、Crossrefの登録内容と一致する。本文はこのPDFから `pdftotext -layout` で抽出して読んだ。

### 1.2 原文の記述

温度補償の節の冒頭に次の一文がある。

> "The temperature compensation scheme uses the conventional sensing setup of two resonators, a sense resonator (with frequency f1) and a reference resonator (with frequency f2)."

評価者が指摘した "conventional sensing setup" という語は、この文のとおり原文に存在する。著者自身が、検出共鳴器と基準共鳴器を二つ置く構成を「従来からある構成」と位置づけたうえで、その上に自分たちの回路上の工夫を載せている。

比を取ることについては、次の記述がある。

> "Thus the result of the counting operation (N) can be represented by the divider (D) and the ratio of f1 to f2."

そして共通モードの除去については、式 `N = D f1/f2 = D f01 T(t) X(x) / (f02 T(t) X(0)) = D f01 X(x) / f02` を導いたうえで、次のように述べている。

> "Thus the first-order effects of temperature and other common mode interferents can be eliminated from the final signal."

温度依存項 `T(t)` が分子と分母で同じであるために比を取ると消える、という論法であり、CipherFluteの基準笛の説明とまったく同じ構造である。

さらに、著者たちは1995年の時点ですでにこの種の手法に先行研究があることを明示している。

> "A number of methods for temperature compensation utilizing two resonators have been described in the literature [1, 2]."

> "A method similar to the compensation scheme used here has been previously described for use with external frequency counters, although no temperature-stability data was reported [4]."

参照されている文献は、[1] が Slobodnik, Colvin, Roberts, Silva, "A Digitally Compensated SAW Oscillator", Proc. 1981 Ultrasonics Symposium, pp. 135–138、[2] が Alder, Fox, Przybylko, Rezgui, Snook, Analyst, 114(9), p. 1163, 1989、[4] が Joshi, "A Temperature Compensated High Voltage Probe Using Surface Acoustic Waves", Proc. 1982 Ultrasonics Symposium, pp. 317–320 である。つまり二共鳴器による温度補償という考え方は、1995年よりさらに10年以上さかのぼる。

なお、この論文自身の新規性は「比を取ること」ではなく「基準共鳴器の周波数を分周して周波数カウンタの時間基準そのものに使い、比の計算を外部の演算ではなくカウント動作の中で行い、それを共鳴器駆動用の集積回路に載せたこと」である。結論部でも、比較対象は二つの外部カウンタの読みを引き算する従来手法である。

> "This circuit has shown approximately an order of magnitude improvement in compensation over the conventional frequency-subtraction temperature compensation method using external frequency counters."

化学センサとしての使い方についても、被覆した検出用共鳴器と無被覆の基準用共鳴器を並べる図が示されている（図4の説明文）。

> "Use of a poly-(isobutylene)-coated sense resonator and an uncoated reference resonator to sense three different concentrations of trichloroethylene (4.4%, 0.9%, and 0.2%)."

## 2. 反例2：Wang ら（2014年）

### 2.1 書誌の確定

- 著者は Wen Wang、Xufeng Xue、Yangqing Huang、Xinlu Liu である。
- 題名は "A Novel Wireless and Temperature-Compensated SAW Vibration Sensor" である。
- 掲載は Sensors 誌の第14巻第11号、20702ページから20712ページ、発行年は2014年である。
- デジタルオブジェクト識別子は 10.3390/s141120702 であり、PubMed識別子は25372617、PubMed Central識別子は PMC4279507 である。
- 受理と公開の日付は、受領が2014年9月23日、採録が2014年10月27日、公開が2014年11月3日である。

確認先は次の2つである。

- Crossref の書誌レコード: https://api.crossref.org/works/10.3390/s141120702
- PubMed Central の全文: https://pmc.ncbi.nlm.nih.gov/articles/PMC4279507/

出版社であるMDPIのページ（https://www.mdpi.com/1424-8220/14/11/20702）は自動取得が拒否されたため、CrossrefとPubMed Centralで確定させた。評価者が示したデジタルオブジェクト識別子のリンクは、実際にこのMDPIのページへ転送される。

### 2.2 原文の記述

同一の水晶片持ち梁の上に一端子型の表面弾性波共鳴器を二つ作り込み、一方を検出用、他方を基準用としている。

> "One resonator acts as the sensing device adjacent to the clamped end for maximum strain sensitivity, and the other one is used as the reference located on clamped end for temperature compensation for vibration sensor through the differential approach."

効果についても数値が示されている。

> "the difference frequency-dependence is only 18.6 Hz/°C in testing temperature range of 20∼120, far less than the cross-temperature sensitivity of the single sensing resonator (8.6 kHz/°C)"

ここで注意すべき差異が一つある。この論文が取っているのは周波数の比ではなく差である。共通モードを打ち消すという目的と、基準素子を同じ物体に同居させるという構造は同じであるが、演算は差分である。比を取る形での記述はSmithとSenturiaの側にある。

この論文において著者たちが自分の新規性としているのは、無線受動の振動センサとして片持ち梁の寸法と表面弾性波素子の設計を最適化して高い感度を得たことであり、差動構成そのものは達成手段として位置づけられている。

> "This sensor presents many advantages over other currently available vibration sensors: (1) it provides high sensitivity through optimal design by using the established theory model on response mechanism; (2) the temperature dependence is compensated effectively by using the differential structure..."

## 3. 分野における確立度

「基準素子を同居させて共通モードを除く」という設計が、微小電気機械システム、水晶振動子、表面弾性波デバイスの各分野でどの程度定着しているかを、総説と査読論文の一次資料で確認した。

### 3.1 微小電気機械システムの総説

- 著者は Yusi Zhu、Zhan Zhao、Zhen Fang、Lidong Du である。
- 題名は "Dual-Resonator-Based (DRB) and Multiple-Resonator-Based (MRB) MEMS Sensors: A Review" である。
- 掲載は Micromachines 誌の第12巻第11号、論文番号1361、発行年は2021年である。
- デジタルオブジェクト識別子は 10.3390/mi12111361 である。
- 確認先は https://api.crossref.org/works/10.3390/mi12111361 と https://pmc.ncbi.nlm.nih.gov/articles/PMC8621490/ である。

この総説には次の一文がある。

> "Therefore, environmental effect is cancelled to the first order with the ratio-based output."

「比による出力では環境の影響が一次の範囲で打ち消される」という言明が、2021年の総説において当然の前提として書かれている。総説という形式で「複数共鳴器を使う微小電気機械システムのセンサ」がひとまとまりの研究領域として整理されている事実そのものが、この設計が確立していることの証拠である。ただしこの総説の本文に "reference resonator" という語そのものは出現せず、差動構成やモード局在型の語彙で書かれている点は正確に述べておく。

### 3.2 水晶振動子の分野

- 著者は Marianna Magni、Diego Scaccabarozzi、Bortolino Saggin である。
- 題名は "Compensation of Thermal Gradients Effects on a Quartz Crystal Microbalance" である。
- 掲載は Sensors 誌の第23巻第1号、論文番号24であり、電子公開は2022年12月20日である。
- デジタルオブジェクト識別子は 10.3390/s23010024 である。
- 確認先は https://api.crossref.org/works/10.3390/s23010024 と https://pmc.ncbi.nlm.nih.gov/articles/PMC9824633/ である。

序論に次の記述がある。

> "Compensation of temperature effects based on the dual crystal configuration exploits the beating frequency of a reference crystal and the active one. The system is conceived to remove the effect of the average crystal temperature, assuming that both crystals have the same temperature, but the effect of temperature gradients is neglected."

基準用の水晶と実働の水晶を組み合わせる構成が、既知の標準的手法として紹介されており、この論文の新規性はその手法が温度勾配を無視している点を改良することにある。つまり2022年の時点では、基準素子との組み合わせ自体はすでに批判的検討の対象になる程度に古い。

### 3.3 表面弾性波デバイスの分野

第2節で確認した Wang ら（2014年）が、この分野における実装例そのものである。加えて、SmithとSenturiaが1995年に引用した Slobodnik ら（1981年）と Joshi（1982年）は、いずれも Ultrasonics Symposium における表面弾性波デバイスの温度補償の論文である。

なお、表面弾性波センサの総説として Mandal と Banerjee の "Surface Acoustic Wave (SAW) Sensors: Physics, Materials, and Applications"（Sensors, 22巻, 論文番号820, 2022年, デジタルオブジェクト識別子 10.3390/s22030820, 確認先 https://pmc.ncbi.nlm.nih.gov/articles/PMC8839725/ ）を当たったが、基準素子や二重遅延線による共通モード補償に触れた記述は見つからなかった。表面弾性波の分野で総説レベルの明示的な記述を押さえることは、今回の調査ではできなかった。

## 4. 判定

反例は正しい。

「既知の値を持つ基準素子を同じ物体に同居させ、比を取って共通モードの環境変動を一次の範囲で打ち消す」という設計は、遅くとも1981年から1995年の間に共鳴型センサの分野で標準的な構成として確立しており、1995年の時点で当事者自身が "conventional sensing setup" と書いている。2014年には表面弾性波共鳴器での実装例があり、2021年と2022年の総説および査読論文でも既知の手法として扱われている。したがって、この着想を一般的な形で「前例がない」と述べることはできない。

一方で、次の3点は反例によって否定されていない。

第一に、CipherFluteの基準素子は電子回路も電源も持たない受動的な共鳴管であり、読み取りは人間の呼気と携帯電話の内蔵マイクだけで行われる。挙げられた反例はいずれも発振回路と周波数カウンタを前提とする。

第二に、CipherFluteの基準素子は「センサの環境補償」ではなく「離散符号の復号における基準」として働く。打ち消す対象は温度だけでなく吹奏者の息の強さや個体差であり、出力は連続量の測定値ではなく離散スロットの番号である。この用途の違いは、評価指標が測定確度ではなく記号誤り率になる点に現れる。

第三に、造形物への情報埋め込みという文脈における前例の有無は、今回の調査では確定していない。参考として、受動音響で情報を担う3Dプリント造形物の代表例である Lamello（Savage、Head、Hartmann、Goldman、Mysore、Li、Proceedings of CHI 2015、著者公開版 https://people.eecs.berkeley.edu/~bjoern/papers/savage-lamello-chi2015.pdf ）の本文を全文抽出して調べたところ、"reference"、"calibration"、"temperature" のいずれの語も本文中に出現せず、既知周波数の基準要素を同時造形する設計は取られていなかった。ただしこれは1件の確認にすぎず、この文脈での網羅的な調査には至っていない。

## 5. 書き換え案

現在の論文本文（`paper/v11_text_dump.txt` の第163行から第167行、および貢献を列挙した第29行）では、基準笛について「通信で使われるパイロット信号と同じ発想であり」と既存概念への言及がすでに入っている。ここをさらに正確にするには、次の2点を直すとよい。

第一に、貢献の記述から「新しい」という含意を外し、既知の原理の移植であることを明示する。たとえば次のように書き換える。

> 第二に、共鳴型センサで確立している基準素子との比による共通モード補償の考え方を、電源も回路も持たない受動的な共鳴管の離散符号復号へ移し、温度と吹奏条件の変動下での記号誤り率を実測して有効性を示す。

第二に、3.3節の説明にひとこと出典を添える。たとえば次のように書く。

> この考え方自体は新しいものではなく、検出用の共鳴器と基準用の共鳴器を並べて比あるいは差で読むことで温度などの共通変動を打ち消す構成は、共鳴型センサの分野で古くから用いられてきた［Smith and Senturia 1995］。本研究の位置づけは、この原理を電子回路も電源も持たない受動的な共鳴管に移し、連続量の測定ではなく離散スロットの復号に用いた点にある。

このように書けば、査読者が反例を出したときに崩れる部分がなくなる。逆に「前例がない」と書き続けた場合、この分野を知る査読者からは高い確度で指摘を受ける。

## 6. 確認できなかったこと

- 出版社であるMDPIの論文ページ（https://www.mdpi.com/1424-8220/14/11/20702 ）は HTTP 403 で取得できなかったため、Crossref と PubMed Central を一次確認先として用いた。
- IEEE Xplore における Smith と Senturia の論文ページ本体は取得していない。書誌は Crossref の登録内容と、著者所属機関が公開している原稿本文で確定させた。
- 表面弾性波デバイスの分野について、基準素子との差または比による共通モード補償を「標準的手法」と明記した総説レベルの一次資料を見つけることはできなかった。個別論文と1981年および1982年の会議録の引用にとどまる。
- 造形物への情報埋め込みという文脈における基準素子の同時造形の前例について、網羅的な調査は行っていない。Lamello 1件を確認したのみである。

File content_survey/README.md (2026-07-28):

# 暗号笛関連コンテンツ探し

CipherFlute（暗号笛）の研究紹介で引用するための、大衆文化における「音を鍵として使う」描写の調査結果。

- 調査日: 2026年7月26日
- 生データ: `sound_auth_catalog.json`（作品209件、うち裏取り済み113件、一部確認55件、明確な否定4件）
- 調査方法: 3つの多角調査（脚本の全文検証、10の切り口による掃き出し、残った穴の詰め）を実行した。延べ182のエージェントが1000万トークン規模でWeb検索と一次資料の取得を行った。

## 依頼の3件についての結論

### 1. 『グーニーズ』(The Goonies, 1985) — 記憶はおおむね正しい

骨のパイプオルガンで音を鳴らして先へ進む場面は確実に実在する。ただし細部に2点の訂正がある。

- **「和音進行」ではない**。宝の地図の裏に手書きされた**数小節の楽譜**を、1音ずつそのとおりに弾く。既存の名曲ではなく本作のために書かれた音型である。
- **開くのは「扉」ではなく「通路を塞ぐ巨岩」**。正しい音を鳴らすたびに1インチずつ開く。

誤った音（脚本の表記は SOUR CHORD）を鳴らすたびに床の一区画が抜け落ち、約30メートル下の石筍の上へ落ちかける。地図の謎かけ自体が「間違いが多すぎれば命はない」と警告している。

さらに面白いのは、**地図の経年劣化で一部の音符が判読不能になっている**点である。アンディは最後の音を当てずっぽうで弾かざるを得ない。鍵素材の一部が欠損した状態で復号を試みるという、誤り訂正の話そのものである。

- 場所: 製作側が「Organ Chamber（オルガンの間）」と呼ぶ洞窟内の一室。撮影用脚本のシーン148〜156。
- 出典: Chris Columbus 第4稿（1985年1月11日青稿、Internet Archive と scriptslug の2経路で同一文言を確認）、American Cinematographer 誌1985年12月号、ILM公式40周年オーラルヒストリー。
- 注意: American Cinematographer 誌は開く対象を跳ね橋(drawbridge)と書いており脚本の巨岩と食い違う。引用は脚本の記述を採るのが安全である。
- 配信: **U-NEXTで見放題**。Amazon Prime Videoは400円の有料レンタルのみ。Netflix・Disney+は配信なし。

### 2. 『ハドソン・ホーク』(Hudson Hawk, 1991) — 記憶違いであり、元ネタは『ザ・コア』

**『ハドソン・ホーク』にその場面は存在しない。** 撮影用脚本の全文検索でも、公開版の英語字幕の全文でも、gum / wrapper / whistle / tone / 2600 / DTMF のいずれも、音で装置を起動する意味では一度も現れない。本作で音楽が担うのは別の役割で、ホークと相棒は「Swinging on a Star」などを歌い、**その曲の長さを体内時計代わりにして強盗の作業時間を計る**。

**記憶の実際の出どころは『ザ・コア』(The Core, 2003) とみてほぼ間違いない。** ハッカーの青年タズ・"ラット"・フィンチが、主人公キーズ博士の**携帯電話を取り上げ、櫛とチューインガムの銀色の包み紙で即席の笛のようなものをこしらえ、それを電話に吹き込んで**操作を加え、「これでこの電話は長距離通話がずっと無料だ」と告げる。

栗原さんの記憶にある「携帯電話に向かって」「ガムの包み紙で即席に作った笛のような道具で」「特定の音を送ると」「システムが作動する」の4要素がすべて揃っている。日本語の映画ブログでも語り草になっている場面である。なおこの描写は1960〜70年代の電話フリーキングを下敷きにした楽屋落ちで、2003年当時のデジタル交換機や携帯電話網では実際には成り立たないと IMDb の間違い欄でも指摘されている。

『ハドソン・ホーク』の側にも記憶を引き寄せる要素は複数あった。相棒の綽名が**「トミー・ファイヴ・トーン（五つの音）」**であること、CIA工作員の暗号名がチョコレート菓子の名前であること、そして音楽が仕掛けを進行させる印象を強く残すことである。

もう一つの有力な元ネタ候補が **『007 リビング・デイライツ』(1987)** である。QがボンドMに渡すキーホルダー型の装置は、「ルール・ブリタニア」の冒頭を口笛で吹くと催涙ガスを噴射し、冷やかしの口笛（wolf whistle）を吹くと爆発する。**吹く曲によって機能が切り替わる**という点で、音を鍵として使う思想そのものである。

- 配信: 『ハドソン・ホーク』はU-NEXTで見放題。『007 リビング・デイライツ』は4サービスとも見放題なし（U-NEXTで199円前後のレンタル）。

### 3. 『ゼルダの伝説』シリーズ — 初代ではなく『時のオカリナ』以降が本命

**初代『ゼルダの伝説』(1986) の笛に、旋律を入力する認証要素は無い。** 任天堂公式マニュアルは「人々は笛がリンクのために道を開くと言う」と伝聞形で述べるにとどまり、断定的に説明されている効果はトライフォースの最後の欠片を集めた後に第9迷宮入口へワープする機能だけである。求められるのは笛を所持していることであって、正しい音を知っていることではない。

CipherFluteの類比として適切なのは『時のオカリナ』以降である。

| 作品 | 仕組み | 認証性 |
|---|---|---|
| 時のオカリナ (1998) | 十字キーとAボタンが5つの音階に対応し、プレイヤーが6音の旋律を自分で入力する | **強く該当**。「ゼルダの子守唄」は王家に連なる者だけが知る旋律という設定で、知識そのものが鍵 |
| ムジュラの仮面 (2000) | 逆順に吹く「逆さ歌」、同じ音を重ねて吹く「重ね歌」。神殿ごとに異なる曲 | 該当。半分だけのゴロンの子守歌は断片のままでは効かない |
| 夢をみる島 (1993) | 8つの楽器を集めて合奏する「目覚めの歌」 | 該当。**8つの断片を全部集めないと開かない = しきい値が k=N の秘密分散** |
| 風のタクト (2002) | 指揮棒で3拍子や4拍子を振り、賢者と合奏する | **きわめて明確に該当**。曲という知識と、賢者という他者の存在の両方が要る |
| 大地の汽笛 (2009) | パンフルート。マイクへの**実際の吹き込み**とタッチによる運指の組み合わせ | 該当。光の石像が提示した音のパターンを正しく返す |
| スカイウォードソード (2011) | ハープをリズムに合わせて弾く。音高よりタイミングの一致を判定 | 該当。勇者の詩は三箇所から一節ずつ集める |
| トワイライトプリンセス (2006) | 提示された旋律を遠吠えで復唱する（音高の一致判定） | 該当。**チャレンジ・レスポンスそのもの** |

---

## 研究紹介に特に効きそうな事例

### 音を鍵にする方式の長所と弱点が同時に描かれているもの

**『007 ムーンレイカー』(1979)** — ヴェネツィアの秘密研究所の扉で、研究員が数字パネルに暗証番号を打つと**押した数字ごとに音階が鳴り**、その5音は『未知との遭遇』の五音動機そのものである。ボンドは**音を聞き取って同じ列を打ち直して侵入する**。音を鍵にする方式と、その音が漏れれば破れるという弱点が、一場面に同居している。（U-NEXTで199円レンタル、Amazon Prime Videoで400円レンタル。見放題はなし）

**『ワンダーウーマン』「Judgment from Outer Space」前後編（1977年1月15日・17日放送）** — 異星人アンドロスが特別な口笛で自分の宇宙船のハッチを開けてみせ、後編でワンダーウーマンが**その口笛を耳で覚えて真似ることでハッチを開け、船内の力場も解除する**。音を鍵にする描写と、それを耳で聞いて真似ることで破る描写が同じ二部作に並ぶ。ファンサイトが「惑星評議会の技術はiPhone並みのセキュリティも必要だ」と皮肉っている。（U-NEXTで見放題。邦題は「空飛ぶ鉄腕美女ワンダーウーマン」）
※「6音」という数字の出どころはTV Tropesで、それ以上に信頼できる出典は見つからなかった。音数を断定して引用しないほうがよい。

**『スニーカーズ』(1992)** — 声紋認証の「Hi. My name is Martin Bishop. My voice is my passport. Verify me.」は、まず**正規の登録フレーズとして観客に提示される**。チームは標的のブランデスをデートに誘い出して「passport」という単語を言わせ、編集して繋ぎ合わせた音声を扉の前で再生して開ける。世間ではしばしば「My voice is my passport. Verify me.」と引用されるが、実際には名乗りが前置きされる三文構成で、**同じ定型文を正規利用者も攻撃者も唱える**点が要点である。（4サービスとも見放題なし。Amazon Prime Videoで400円レンタル）

**『ディスオナード デス・オブ・ジ・アウトサイダー』(2017)** — 歌声と旋律の錠を、録音の再生で破る。声紋を鍵にする設計への反例。

### 秘密分散に直結するもの

**『007 ユア・アイズ・オンリー』(1981)** — Q課のアイデンティグラフ室の扉に音楽錠が付いていて、鍵は7音、旋律は『私を愛したスパイ』主題歌「Nobody Does It Better」の冒頭である。**Qが5音まで弾いて手を止め、ボンドが残りの2音を補って扉が開く。** 鍵を二人で分担して入力する描写として読める。

**『ゼルダの伝説 夢をみる島』** — 8つの楽器を全部集めないと目覚めの歌にならない（k=Nのしきい値）。

**『舞-乙HiME』** — 旋律と歌詞を三人がそれぞれ一節ずつ保持する分割形式。

### 較正・精度・誤り訂正に直結するもの

**『極限脱出 9時間9人9の扉』(2009)** — 一等船室の脱出扉はピアノを弾いて開ける。楽譜を手に入れたあと、**そのピアノが正しく調律されていないことが判明し、本当の課題は楽譜の音を狂った鍵盤上の正しい位置に読み替えること**になる。演奏される曲はウェストミンスターの鐘である。装置の較正がずれている状況を人間側が補正するという、CipherFluteがずっと格闘してきた問題そのものである。

**『テイルスピン』「For Whom the Bell Klangs」前後編（1990年11月27日・28日放送）** — 失われた古代都市ティナブラ（鐘の都）は都市全体が音と倍音の原理の上に築かれていて、扉や門はそれぞれ異なる音高に反応する。パート2で考古学者ケイティが碑文から**扉を開ける音が「B（シ）」であること**を読み取り、歌える者を探す。必要な音高の精度という論点の実例。（Disney+で見放題）

**『グーニーズ』の判読不能になった音符** — 鍵素材の欠損。

### 「鍵が音である以上、発音体は何でもよい」を示すもの

**『冒険野郎マクガイバー』第1シーズン第5話「The Heist」（1985年11月3日放送）** — 悪役の金庫はトーン・ロックで、正規の持ち主はキーホルダーの装置から**4つのトーン**を鳴らして開ける。マクガイバーはメルロー1本と4個のワイングラスを用意し、注ぐ量を変えて音程を作り分けて金庫を開ける。しかも**飼っているオウムの声を音程の基準として使う**。同じ鍵が、電子音・ワイングラスの共鳴・鳥の声という三つの発音体をまたいで扱われている。
※「1オクターブ高い」と言ってからワインを飲む（＝液体を減らす）演出は、グラスの縁をこする場合は逆に音が高くなるはずで、物理的には矛盾している。引用するなら承知のうえで。
※日本では1985年版の配信は4サービスとも確認できなかった。Amazon Prime Videoと日本のHuluにある「MACGYVER／マクガイバー」は2016年のリメイク版で別作品である。

### チャレンジ・レスポンスの実例

**『ターミネーター2』(1991)** — Blu-ray版で約43分過ぎ。ジョンが里親宅に電話するが、応答したのはジャネルになりすましたT-1000である。T-800が受話器を取り、まず自分の声でジョンに「What's the dog's name?」と尋ねてジョンから「Max」を得る。次に**ジョンの声を真似て**電話口に「Wolfie」という偽の名を問いかけ、相手が訂正せずに受け入れたことで偽物だと判明する。
※**偽名を口にしたのはジョンではなくT-800である**（ジョンが言ったという記憶は誤り）。首輪の名札「MAX」を見てT-1000が騙されたと気づく場面は劇場公開版では削除され、特別編で復活している。（U-NEXTで見放題）

### 脅威モデルの裏返し（音が漏洩経路になる）

**現金自動預払機のキーパッドは、数字ごとに異なる音程をあえて割り当てない。** これは俗説ではなく、決済業界の認定規格に逐語で書かれた必須要件である。

> PCI PIN Transaction Security (PTS) Point of Interaction (POI) v6.1 要件B3:
> "If PIN entry is accompanied by audible tones, the tone for each entered PIN digit is indistinguishable from the tone for any other entered PIN digit."

同じ文言は v3.1（2011年、要件A5）と v4.0（2013年、要件A11）にもあり、少なくとも2011年から一貫している。物理セキュリティ要件A5には、音・電磁放射・消費電力から入力桁を判定することが現実的に不可能でなければならないとも書かれている。実機の測定でも、市販PINパッド2機種は全キー共通の単一周波数（2900Hzと2500Hz）を出していた。

対比の側も正確である。押しボタン電話は ITU-T Q.23 で、低群と高群から1つずつ選んだ2周波の組をキーごとに割り当てると規定されている。さらにPCI SSCの文書「Protecting Telephone-Based Payment Card Data」v3.0（2018年）は、**訓練された耳なら電話のキー音から数字を聞き取れる**と公式に認めている。

**ただし重要な留保がある。** 音の高さを揃えても打鍵の時刻は漏れる。ESORICS 2020 の Cardaioli らは、ATMのフィードバック音から打鍵時刻を平均誤差1.8ミリ秒・検出率98パーセントで復元し、そこから得た打鍵間隔で暗証番号の推測回数を大幅に減らせることを示した。**音の内容を秘匿しても、音が鳴った事実と時刻は秘匿できない。**

関連して **音響サイドチャネル攻撃**（Genkin・Shamir・Tromer, CRYPTO 2014）は、計算機が復号中に発する音から4096ビットのRSA秘密鍵を丸ごと抽出できることを示した。市販の携帯電話を30センチに置いて成功し、指向性マイクなら4メートル離れても鍵を得られた。

### 実話の先行事例

**キャプテン・クランチの笛と2600ヘルツ** — シリアル『カプン・クランチ』の景品のプラスチック製ボースン笛は、二つある穴の一方を塞ぐと約2600ヘルツを出す。当時の北米長距離網は帯域内信号方式で、2600ヘルツが「この中継線は空いている」を意味した。通話中にこの音を送ると遠端の交換機だけが通話終了と誤認し、利用者は生きた中継回線をつかんだまま残る。**量産された安価な玩具の笛が、そのまま現実の機械に対する音の鍵として機能した実例**である。
※よく語られる「ドレイパーがその笛の使い道を発見した」という筋は誤りで、名乗りの由来としては正しいが発見者ではない。

**ジョー・エングレシア（ジョイバブルズ）** — 生まれつき全盲で絶対音感を持ち、四歳のころから受話器に向かって口笛を吹くだけで交換機を操作できることに気づいた。装置は要らず、**彼の唇そのものが鍵だった**。1968年に大学生として長距離通話を1回1ドルで売り、電話会社に摘発された。
※「2600ヘルツを口笛で正確に出せた」と踏み込む強い主張は、3票の検証で否決された。断定しないほうがよい。

**ゼニス・スペースコマンド（1956年のテレビ用リモコン）** — 電池を使わず、**長さの違う4本のアルミ棒を叩いて固有振動数の超音波を出し、周波数の違いで命令を区別した**。電源不要の機械的な音響キーという点で、CipherFluteの直接の先祖にあたる実在の製品である。（今回の調査では未検証のまま残ったので、引用するなら裏を取ること）

### 明確に否定されたもの（記憶違い・都市伝説）

- **『インディ・ジョーンズ／最後の聖戦』**: 三つの試練はいずれも音と無関係である（回転刃、神の名を綴る敷石、強制遠近法による偽装橋）。冒険映画の定番だという印象は事実に反する。
- **『ダ・ヴィンチ・コード』『ナショナル・トレジャー』**: 音が錠を開ける場面は一箇所も無い。ただしクリプテックスの**誤入力で中身が破壊される自己破壊機構**は、誤りに寛容であるべきか厳格であるべきかという設計論として引用価値がある。
- **『ウォー・ゲーム』(1983)**: しばしば「キャプテン・クランチへの目配せ」と紹介されるが、デヴィッドが公衆電話でやっているのは缶のプルタブによる**回路の短絡**であって、音のトーンを送り込む手口ではない。
- **『ハドソン・ホーク』**: 上述のとおり。

---

## 日本の作品

| 作品 | 仕組み | 認証性 | 配信 |
|---|---|---|---|
| **メイドインアビス** | 白笛は一級遺物「命を響く石」を削り出して作り、**「命の紋」で所有者ただ一人と結ばれる**。紋の合う者が鳴らすと遺物が応じ、合わない者が吹いても応じない | **該当**。所持と本人性の二要素に近い | Netflix・Amazon Prime Video・U-NEXTで見放題 |
| **名探偵コナン**（黒ずくめの組織のボスの連絡先 #969#6261） | 携帯電話のテンキーを押したときのプッシュ音が童謡**「七つの子」**の旋律をなぞる。コナンは旋律から番号を復元する | **該当**。旋律を知る者だけが番号に到達できる | 単行本第46巻、アニメ第394〜396話 |
| **名探偵コナン 戦慄の楽譜** (2008) | 終盤、コナンと怜子が**二人で声でDTMFの二つの周波数をそれぞれ発声し、合成音で110番に発信する**。また灰原がリコーダーで音階を暗号に変換して伝える | 該当しない（機械への命令） | Netflix・Disney+・U-NEXT・Amazon Prime Videoで見放題 |
| **マグマ大使** (1965) | 笛を3回吹くとマグマ大使、2回でモル、1回でガムが応答する。**吹いた回数が宛先を指定するコード** | 部分的に該当 | 1966年の実写版は4サービスとも配信なし（「マグマ大使」として配信されているのは1993年のアニメ版） |
| **人造人間キカイダー** (1972) | プロフェッサー・ギルの笛の音が、良心回路の不完全なジローを苦しめて命令に従わせる | 該当しない | U-NEXTで見放題 |
| **仮面ライダーキバ**（フエッスル）/ **響鬼**（音叉） | 笛や音叉の音が変身システムや武器を起動する | 該当しない（対応する道具を持てば誰でも作動する） | — |
| **機動警察パトレイバー the Movie** (1989) | 特定の低周波と建築物の共振が、機械の暴走を引き起こす | 該当しない（逆向きの事例） | U-NEXTで見放題 |
| **ONE PIECE エピソード オブ 空島** | 一音の誤りも許されない演奏。欠けた鍵は記憶による補完で復元される | 要確認 | — |
| **舞-乙HiME** | 旋律と歌詞を三人が一節ずつ保持する分割形式 | 要確認 | — |
| **モスラ** (1961) | 小美人の歌がモスラを呼ぶ | 要確認 | — |
| **NARUTO**（多由也の魔笛） | 旋律と運指の組み合わせで、召喚した怪物の行動が変わる | 要確認 | — |

---

## 全体の傾向として言えること

1. **「音を鍵にする」描写は、ほぼ必ず「その音を盗み聞きして真似る」描写とセットで現れる。** ムーンレイカー、ワンダーウーマン、スニーカーズ、ディスオナードがいずれもそうである。大衆文化のほうが先に、音を鍵にする方式のリプレイ攻撃への弱さを直感していたことになる。これはCipherFluteの脅威モデル（音は公開チャネルであり、秘匿はデジタルのShamir層のみが担う）と正確に一致する。
2. **「知識」と「所持」と「本人性」のどれを鍵にしているかで、作品はきれいに分かれる。** グーニーズと時のオカリナは知識、初代ゼルダと魔笛は所持、ハリー・ポッターの蛇語とスニーカーズの声紋は本人性である。**メイドインアビスの白笛だけが、所持と本人性を同時に要求している。**
3. **音を鍵にすると音が漏洩経路になる、という裏返しが現実には規格として明文化されている。** ATMのキーパッドの要件がそれである。研究紹介では、フィクションの華やかな事例と、この地味な規格の一文を並べると効く。
4. **電源不要の機械的な音響キーは、1956年のゼニス・スペースコマンドという実在の先祖を持つ。**

---

# 追記（2026年7月26日）— 配信一覧、ゼニス・スペースコマンドの裏取り、神話・昔話

## 配信一覧（2026年7月25〜26日時点）

◎＝見放題、△＝有料レンタルまたは購入、×＝取り扱いなし。日本のHuluはHJ Holdings運営でDisney+とは別サービスなので、Disney+欄には入れていない。配信は頻繁に変わるので、視聴前に各サービスで確認すること。

### 映画

| 作品 | Netflix | Prime Video | Disney+ | U-NEXT |
|---|:-:|:-:|:-:|:-:|
| ザ・コア (2003) | × | △100円 | × | ◎ |
| グーニーズ (1985) | × | △400円 | × | ◎ |
| ハドソン・ホーク (1991) | × | △400〜600円 | × | ◎ |
| ターミネーター2 (1991) | × | △300〜605円 | × | ◎ |
| ハッカーズ (1995) ※邦題「サイバーネット」 | × | × | × | ◎ |
| マーズ・アタック！ (1996) | × | △440円 | × | ◎ |
| バットマン ビギンズ (2005) | × | △400円 | × | ◎ |
| 知りすぎていた男 (1956) | × | △400円 | × | ◎（情報が割れる） |
| バルカン超特急 (1938) | × | ◎ | × | ◎ |
| ミッション:インポッシブル (1996) | × | ◎ | × | ◎ |
| プロメテウス (2012) | ◎ | △300円 | ◎ | × |
| ハリー・ポッターと賢者の石／秘密の部屋 | ◎ | ◎ | × | ◎ |
| パディントン2 (2017) | ◎ | △300円 | × | ◎ |
| 怪盗グルーのミニオン危機一発 (2013) | × | ◎（情報が割れる） | × | ◎ |
| パイレーツ・オブ・カリビアン／ワールド・エンド | × | △400円 | ◎ | × |
| ナルニア国物語／カスピアン王子の角笛 | × | △400円 | ◎ | × |
| マスターズ／超空の覇者 (1987) | × | ◎ | × | × |
| スター・トレックIV 故郷への長い道 (1986) | × | △440円 | × | ◎ |
| 未知との遭遇 (1977) | × | ◎か×（情報が割れる） | × | ◎か×（同左） |
| 007 ムーンレイカー (1979) | × | △400円 | × | △199円 |
| 007 ユア・アイズ・オンリー (1981) | × | △400円 | × | △199円 |
| 007 リビング・デイライツ (1987) | × | △400〜600円 | × | △199円 |
| 007 ダイヤモンドは永遠に (1971) | × | △400円 | × | △199円 |
| スニーカーズ (1992) | × | △400円 | × | × |
| 夢のチョコレート工場 (1971) | × | △440円 | × | ◎か×（情報が割れる） |
| ウォー・ゲーム (1983) | × | チャンネル「MGM+」（月額500円）でのみ◎ | × | × |
| インディ・ジョーンズ／最後の聖戦 ※音の鍵は無い | ◎ | ◎か△ | × | ◎ |

### テレビシリーズ

| 作品 | Netflix | Prime Video | Disney+ | U-NEXT |
|---|:-:|:-:|:-:|:-:|
| ワンダーウーマン「Judgment from Outer Space」 | × | △ | × | ◎（HBO Max枠） |
| テイルスピン「For Whom the Bell Klangs」 | × | × | ◎ | × |
| LOST シーズン3最終話 | × | △200円/話 | ◎ | × |
| CSI:科学捜査班「Suckers」(S4E13) | × | × | ◎（日Huluに全話） | ◎（当該話の収録は未確認） |
| スター・トレック：ピカード シーズン3 | × | ◎ | × | × |
| アドベンチャー・タイム「What Was Missing」 | × | × | × | ◎ |
| ストレンジャー・シングス | ◎ | × | × | × |
| ホワイトカラー | × | ◎ | ◎ | × |
| 冒険野郎マクガイバー（1985年版） | × | × | × | × |
| 新スタートレック／宇宙大作戦 | × | × | × | × |
| ドクター・フー 旧シリーズ | × | × | × | × |
| スクービー・ドゥー各種 | × | × | × | × |

マクガイバーは日本に配信が来ていない。Prime Videoと日本のHuluにある「MACGYVER／マクガイバー」は2016年のリメイク版で別作品である。

### 日本の作品

| 作品 | Netflix | Prime Video | Disney+ | U-NEXT |
|---|:-:|:-:|:-:|:-:|
| メイドインアビス（TVアニメ） | ◎ | ◎ | × | ◎ |
| 名探偵コナン（TVアニメ本編） | ◎ 3シーズンのみ | ◎ 31シーズン | ◎ 31シーズン | ◎ |
| 名探偵コナン 戦慄の楽譜 (2008) | ◎ | ◎ | ◎ | ◎ |
| 機動警察パトレイバー the Movie | × | チャンネル「アニメタイムズ」で◎ | × | ◎ |
| 人造人間キカイダー (1972) | × | チャンネル「MY HERO」で◎ | × | ◎ |
| 仮面ライダーキバ (2008) | × | △3,696円 | × | ◎ |
| 仮面ライダー555 (2003) | × | △110円/話 | × | ◎ |
| 恐竜戦隊ジュウレンジャー | × | チャンネル「MY HERO」で◎ | × | ◎ |
| 仮面ライダー響鬼 (2005) | × | △3,696円 | × | × |
| モスラ (1961) | ◎ | △300円 | × | ◎ |
| NARUTO -ナルト-（2002年版） | ◎ | ◎ | × | ◎ 1シーズン |
| 舞-乙HiME | × | ◎ | × | × |
| 戦姫絶唱シンフォギア | × | ◎ | × | × |
| ONE PIECE エピソード オブ 空島 | × | チャンネル「Anime Times」等で◎ | × | △440円 |
| マグマ大使（1966年の実写版） | × | × | × | × |

マグマ大使は、各サービスに「マグマ大使」として並んでいるのは1993年のアニメ版である。実写版は配信がない。

**U-NEXT契約者なら、確認すべき映像はほぼ網羅できる。** 足りないのは007の4本（各199円レンタル）、スニーカーズ、テイルスピンとLOST（Disney+）、そして日本では見られないマクガイバーである。

## ゼニス・スペースコマンド（1956）— 裏が取れた

Zenith公式の企業史ページに逐語で書かれている。

> "The first such remote control used four rods, each approximately 2-1/2 inches long"
> "The transmitter used no batteries; it was built around aluminum rods that were light in weight"
> 棒は "very carefully cut to lengths that would generate four slightly different frequencies"

割り当ては**チャンネル送り・チャンネル戻し・音声の入切・電源の入切の4機能**である。1956年秋に生産開始、開発はRobert Adler、前身は1955年のEugene Polley「Flash-Matic」（光式）。1956年から1982年までに900万台以上が売れた。The Henry Ford の収蔵品解説も「ボタンを押すと内部の小さなハンマーがアルミ棒を叩き超音波を出す。テレビはそのクリック音を命令として解釈した」と一致する。

**引用するうえで最も効くのは誤動作の話である。** 鍵束の触れ合う音、犬の首輪の鑑札、電話のベルが、たまたま近い超音波を出してチャンネルを変えてしまうことが頻繁に起きた。**音を鍵にする方式の誤受理が、実際に量産品で起きた歴史上の実例**であり、暗号笛のスロット間隔とマージンの議論にそのまま接続できる。

留保が一点ある。4本が具体的に何キロヘルツずつだったかの数値は、Zenith公式にもThe Henry Fordにも書かれていない。二次資料は40キロヘルツ帯としているが個々の値は確認できていない。**「4本のアルミ棒で4つのわずかに異なる周波数」までは公式で断定でき、具体的な数値は断定しないほうが安全**である。

出典: https://zenith.com/heritage/remote-background/ / https://www.thehenryford.org/collections/explore/artifact/365218 / https://content.time.com/time/specials/packages/article/0,28804,2023689_2023681_2023586,00.html / https://hackaday.com/2017/04/02/command-alexa-with-a-completely-mechanical-vintage-remote-control/

## ゼルダの読み替え（訂正）

初回のまとめは「音階認証か」という軸だけで見て初代の笛を切り捨てたが、本来の関心は「笛を吹くと扉が開く・楽器を鳴らすとギミックが働く」全般だった。**その枠で見るなら初代『ゼルダの伝説』(1986) も該当する。** リコーダーを吹くと湖の水が引いて第7迷宮への階段が現れる。

| 作品 | 楽器 | 何が起きるか |
|---|---|---|
| ゼルダの伝説 (1986) | リコーダー | 湖が干上がって第7迷宮の階段が現れる／既訪の迷宮へワープ |
| 神々のトライフォース (1991) | オカリナ | 呼び出しによる移動 |
| 夢をみる島 (1993) | 8つの楽器 | 全部揃えて奏でると風のさかなの卵が開く |
| 時のオカリナ (1998) | オカリナ | 時の歌で時の扉が開く／太陽の歌で墓が開き昼夜が入れ替わる／嵐の歌で雨が降る |
| ムジュラの仮面 (2000) | オカリナ | 逆さ歌で時が戻る／重ね歌で時の流れが遅くなる |
| 風のタクト (2002) | 指揮棒 | 風向きを変える／賢者との合奏で神殿が力を取り戻す |
| トワイライトプリンセス (2006) | 遠吠え | 提示された旋律を返すと相手が現れる |
| 大地の汽笛 (2009) | パンフルート | 本体のマイクへ実際に吹き込む |
| スカイウォードソード (2011) | ハープ | 演奏で異界への門が開く |

## 神話・伝承・古典で、演奏や歌が物事を起こすもの

単に生物を呼び寄せる・操るだけのものは除外した。

### 手順（回数・順序）が定められているもの

- **エリコの城壁と角笛**（旧約聖書ヨシュア記6章）: 七人の祭司が七つの雄羊の角笛を携え、六日は一日一周、七日目は七周してから吹き鳴らし、全民が鬨の声を上げると城壁が崩れる。**回数と順序が厳密に定められている**点で、この一覧でもっとも「手順そのものが鍵」に近い。
- **ヨハネの黙示録の七つのラッパ**（8章から11章）: 七人の御使いが順に吹き、一つごとに定められた災厄が起きる。音の列に意味の順序がある。
- **師曠の清角**（『韓非子』十過）: 晋の平公の求めに応じて師曠が清角を奏でる。**一奏すると北西から黒雲が起こり、再奏すると大風と大雨が来て幕を裂き祭器を壊し廊の瓦を落とす。** 晋は三年の大旱に見舞われ、平公自身も病んだ。原文は「一奏之，有玄雲從西北方起；再奏之，大風至，大雨隨之，裂帷幕，破俎豆，隳廊瓦」。演奏の回数が段階的に効果を強める。

### 音そのものが物体を動かすもの

- **アムピーオーンの竪琴**（ギリシア神話）: 竪琴を弾くと**石が自ら地から起き上がり、テーバイの城壁として自分で組み上がった。** 兄弟ゼトスは石を手で運んで汗をかいたという対比で語られる。パウサニアス『ギリシア案内記』9.5.6-8 は、テーバイ人がアムピーオーンの墓のふもとの粗石を「竪琴に従った石」として旅人に見せたと記録している。建造そのものが音の産物という、最も物理的な例である。
- **オルフェウスの竪琴**: 岩と木を動かし、冥界の王の心を動かす。ケルベロスを眠らせる部分は生物なので除外する。

### 音が世界の状態を変えるもの

- **万波息笛（マンパシクチョク）**（新羅の伝承、『三国遺事』）: 吹けば敵兵が退き、病が癒え、旱に雨が降り、長雨に晴れ、風が静まり波が平らぐ。国宝として保管された。
- **タンセーンのラーガ**（ムガル朝インド）: ラーガ・ディーパクを歌うと消えていた灯明に火が灯り、メーグ・マルハールを歌うと雨が降る。**ただしこれは伝説であり史実ではない。** アクバルの宮廷史家アブル・ファズルは技量を絶賛しているが奇跡は記していない。旋法（音の集合そのもの）が符号になっている点が面白い。
- **カレワラのカンテレ**（フィンランド叙事詩）: ヴァイナモイネンの演奏に万物が聞き入る。
- **ダグザの竪琴**（アイルランド『マグ・トゥレドの戦い』）: **真名を呼ぶと壁から飛んで持ち主の手に来る。** 三つの調べ（眠り・笑い・嘆き）を弾き分ける。楽器と持ち主が名前で結ばれている点で、メイドインアビスの白笛に近い。
- **モーツァルト『魔笛』**(1791): 魔法の笛の音が、タミーノとパミーナを火と水の試練に通す。

### 音が閉じたものを開けさせるもの

- **天の石屋戸**（『古事記』）: 天宇受賣命が桶を伏せて踏み鳴らし、神々がどっと笑う。その音に誘われて天照大御神が岩戸を細く開ける。**機構が開くのではなく、中にいる者が自分の意思で開ける**点で他と性格が違う。
- **源博雅と玄象**（『今昔物語集』巻二十四）: 鬼に奪われた琵琶の名器を、その音色だけを頼りに羅城門で見つけ出す。扉は開かないが、**音色による個体の同定**であり、暗号笛の造形ばらつきによる個体識別（PUF）に最も近い古典である。

### 除外したもの（生物を呼ぶ・操るだけのもの）

ハーメルンの笛吹き男、クリシュナの笛、オルフェウスとケルベロス、ダビデの竪琴、メルクリウスの葦笛とアルゴス、『風の谷のナウシカ』の蟲笛、『マグマ大使』の笛、『ドラえもん』のハメルンチャルメラ。

なお『アリババと四十人の盗賊』の「開けゴマ」は、音ではなく語の意味に依存する音声の合言葉なので別枠として扱うのが正確である。

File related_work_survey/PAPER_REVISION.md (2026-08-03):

# 論文の全面改訂の方針

2026年7月30日に全面的に書き直した。**旧版（改訂案として節ごとの差し替え文を並べたもの）は破棄した。** 理由は、論旨の重心が変わったため、既存の文章を部分的に直す方式では新しい主張に沿った文章にならないからである。**新しい本文を白紙から書き起こす。**

根拠は `SURVEY.md`（調査の記録、一部は訂正済み）と `REVIEW_AND_REPOSITIONING.md`（外部評価の検証と位置づけの立て直し。こちらが最新）にある。

## 新しい重心

> **特別な装置を持たない人が、そのへんにある楽器ひとつで復号できる、電源も電子部品も持たない秘密の担体。**

旧稿は「暗号資産のリカバリーシードの物理バックアップの新方式」として自分を売っていた。**この土俵では、仮定を最善にしても勝てない。** 容量ではCompactSeedQR（128bitが70mm角1枚）に、電源不要の徹底度ではcodex32（紙と鉛筆だけで復号でき計算機すら不要）に、耐火性では市販の金属板（29ユーロ、耐火試験済み）に、読み出し速度ではカメラ1回に負ける。いずれも実装の未熟さではなく物理と経済の差である。

**勝てるのは「読み出しに機械が要らない」という一点だけであり、そこは誰も埋めていない。**

| | 日用品に偽装できる | 符号として見えている |
| --- | --- | --- |
| **機械なしで人が読める** | **本研究（空白）** | codex32、視覚暗号、大川さんと栃窪さんの方式、SeedQRの手読み |
| **機械が必須** | AirCode、InfraredTags、DNA-of-things、Acoustic Barcodes、Blowhole、Lamello | — |

## 重心から決まること

**書き方の原則が3つ出てくる。**

第一に、**娯楽性を主張に使わない。** 半音刻みを選んだ理由は「エンタテインメント価値」ではなく「**既存の鍵盤楽器がそのまま対照表になるから**」である。音楽性は主張ではなく、可読性を選んだ結果として副次的に生じる性質であり、1文触れて先へ進む。旧稿3.2節の「音感に優れた人により認識・記憶されやすいという欠点にもなる」は削る。**物理層に秘匿を求めないと宣言している以上、人が聞き取れることによる損失はゼロである。**

第二に、**評価実験を入れない。** WISS 2026の募集要項は「『評価（User StudyやEvaluation）』については、記述が無い場合でも減点対象とはしません」と明記し、重視するのは「アイデアの斬新さ」と「デモや実装による有効性のアピール」である。したがって統計を伴うユーザスタディは不要で、**鍵盤楽器または較正用コームで1回復号してみせる実演**を1つ置けばよい。存在証明として1回通ればよく、「音感のある人なら分かるのは自明ではないか」という批判も受けない。

第三に、**主張と証拠を1対1に対応させる。** 旧稿は概要で「128bit暗号のエンコードとデコードを検証した」と書いていたが、実機の通しは4桁の数「2026」だけであった。**実証していないことを実証したと書くのは、引用漏れよりも重い正確性の失敗である。**

## 章立て

| 新 | 内容 | 旧稿との対応 |
| --- | --- | --- |
| 1 | はじめに（機械が要らないことを中心に置く） | 1章を全面的に書き直す |
| 2 | 関連研究（6小節。大幅に増やす） | 2章を全面的に書き直す |
| 3 | 設計（読み出しの3経路を新設して中核に置く） | 3章を再構成する |
| 4 | 脅威モデル（エントロピーと製造時の側チャネルを追加） | 4章に2項目を足す |
| 5 | 実装と実証（装置なしの復号の実演を新設） | 5章と6章を統合する |
| 6 | 議論と限界 | 7章を再構成する |
| 7 | おわりに | 8章 |
| 8 | 未来ビジョン | 9章（ページ数に含まれない） |

## 各章に何を書くか

### 1章　はじめに

課題の立て方を変える。旧稿は「金属板は秘密の保管物に見えるので狙われる」から入っていた。**新稿は「保管した秘密を将来ほんとうに読み出せるのか」から入る。**

- 少量の秘密（暗証番号や合言葉から、128bitのリカバリーシードまで）を物理的に保管する需要がある。
- 既存の担体は、紙、金属板、二次元コードである。いずれも**符号が見えているから読める**。見えているから、隠すと読めなくなる。
- そして**読み出しに何が要るかが、担体の寿命を決める**。リカバリーシードは10年20年の話であり、応用ソフトウェアや特定のカメラに依存する形式はその期間で壊れる。
- 提案は、3Dプリントした笛の音の高さに符号化することである。**日用品の内部空洞として存在でき、外に必要なのは窓と吸込口だけである。**
- **中心の主張。読み出しに特別な装置が要らない。** スマートフォンで読めるだけでなく、**鍵盤楽器ひとつ、あるいは較正用のコーム1本があれば、人間が読める。**
- 貢献は4点（下の「主張してよいこと」を参照）。

### 2章　関連研究

6小節に増やす。旧稿は3小節しかなく、直接の先行研究を2件落としていた。

**2.1　造形物への情報埋め込み。** InfraStructs、AirCode、LayerCode、G-ID、StructCode、Seedmarkers、AnisoTag、InfraredTags、InfoPrint。国内の3系統（神奈川工科大学の上平さんら、日本電信電話の久保さんらのFabAuth、大阪大学の宮武さんら）。**この節では「隠しながら読めること自体は既に実現している」と正直に書く。** 差分は装置と材料の制約に置く。

**2.2　音で読む無電源の物体。** WhooshのFluteCase（**旧稿は未引用。最重要**）、Blowhole、Acoustic Barcodes、Lamello、Acoustic Voxels、SoundOff、Print-and-Play。FluteCaseとの差分は「情報の向き」で書く。

**2.3　3Dプリントされた笛の設計。** Printone（**旧稿は未引用**）、Dabinら、demakein、openwind、モデル共有基盤の実装。**管長から音高を計算することに新規性はないと明記する。**

**2.4　音でデータを送る通信方式。** Schenkerの二群音声周波数符号、ITU-Tの勧告、8B/10B、ggwave、Audio Networking。

**2.5　秘密の物理的バックアップ。** SLIP-39、SSKR、codex32、SeedQR、QR SafeShare、金属板、Casascius、視覚暗号、大川さんと栃窪さんの方式、カードベース暗号、伊藤さんらの3Dプリント装置。**「電源不要の物理媒体に誤り訂正付きで秘密を格納する」ことにcodex32という先例があると明記する。**

**2.6　位置づけ。** 比較表（下の「表」を参照）。

### 3章　設計

**3.5節「読み出しの3つの経路」を新設し、章の中核に置く。** これが新しい重心を支える節である。

1. 機械の経路（スマートフォンの復号ページ。速く、誤り訂正つき）
2. 楽器の経路（鍵盤楽器で同音を探し、鍵の数を数える）
3. コームの経路（較正用コームと突き合わせる。**電子機器がどこにも登場しない**）

**同音判定であって音程推定ではないことを強調する。** 2つの音が同じ高さかどうかの判定はほぼ誰にでもでき、ずれればうなりが聞こえ、合えば消える。ギターの調弦と同じ原理である。2kHz帯で1セントは約1.2Hzなので、うなりが数Hzで聞き取れれば数セントの精度が出る。**スロット幅100セントに対して桁違いに細かい。**

**基準笛の役割を3つに整理する。** 温度と息の共通変動の打ち消し、絶対音感を不要にすること、そして楽器がA=440Hzに合っている必要をなくすこと。

**隣接同音禁止の最適性を書く。** 記号がq種類で隣り合う記号が同じにならない制約のもとでの容量の上限は log₂(q−1) bit であり、本方式の差分写像は有限長でもこれをちょうど達成する。**先例（Goldmanら、Acoustic Barcodes）を認めたうえで、最適であることを主張する。**

### 4章　脅威モデル

旧稿の骨格（主張しないことを先に書く）は良いので残す。2項目を足す。

- **秘密のエントロピーが小さいときに何が守れなくなるか。** 検証値の公開は、低エントロピーの秘密では秘密の公開に近い。カードの20.8bitで暗号化しても強度は20.8bitである。
- **製造時の側チャネル。** ネットワークから切り離すことはデータの経路を守るだけで、造形機の音・振動・電力・磁界は守れない。スライサとファームウェアの真正性まで運用に含める必要がある。

### 5章　実装と実証

**5.4節「装置を用いない復号」を新設する。** 鍵盤楽器または較正用コームで1回復号してみせる。図1枚と短い記述でよい。

**5.3節の通しの実証は、実際にやったことだけを書く。** 4桁の数「2026」を5本の笛で往復させた。128bitについては、片側24本の発音と相対位置の設計どおりであることを確認した段階だと正直に書く。

### 6章　議論と限界

- **「機械が要らない」の適用範囲を書き分ける。** 完全に成立するのは誤り訂正を付けないカジュアルな用途である。128bit級ではReed–Solomonの復号を手で回すのは現実的でないので、機械の経路が主で人の経路は確認や非常時の補助になる。**曖昧にすると突かれるが、書き分ければ設計の強さになる。**
- 限界（容量と密度で負けること、偽装の効果に天井があること、逐次吹奏では息の補正が効かないこと、複製が容易で痕跡が残らないこと、アプリと端末を信頼せざるを得ないこと）。
- 今後の課題（同時吹鳴、紙の対照表による手復号、素材、偽装の定量化）。

## 主張してよいこと（貢献の4点）

1. **読み出しに機械が要らないこと。** 鍵盤楽器ひとつ、あるいは較正用コーム1本で人が読める。同音判定なので訓練を要しない。半音刻みは、既存の鍵盤楽器を対照表として使えるようにするための選択である。
2. **担体の材料と色を選ばないこと。** 符号の担い手が形状なので、担体の光学的性質にいっさい依存せず、任意の家庭用フィラメントで作れる。AirCodeは均質で半透明な材料を、InfraredTagsは特定の黒い赤外透過フィラメントで物体全体を印刷することを要求する。
3. **既知の音高の基準体を同じ物体に同居させ、比で読んで環境変動を打ち消すことを、受動的な共鳴管と離散符号の復号へ移したこと。** 原理そのものは共鳴型センサで確立している（Smith and Senturia 1995 が "conventional sensing setup" と呼んでいる）ので、移植であることを明示する。
4. **どの層が秘密を守り、どの層は守らないのかを明示した脅威モデル。** 造形タグ13件のいずれも脅威モデルを持たない。ただしQR SafeShareが同じ立場を実物として先に公開しており、Secure Information Embedding in Forensic 3D Fingerprinting が明示的な攻撃者モデルを置いていることは注記する。

## 書いてはならないこと

反例が原典で確定しているものである。

| 書いてはならない | 反証 |
| --- | --- |
| 隠蔽と可読性の両立は光学符号には原理的に得られない | AirCodeとInfraredTagsは**外部開口ゼロ**で内部の符号を読む。露出は本研究のほうが多い |
| 光学方式は読み出しが遅い | InfraredTagsは単一フレームから6msから14ms、250cmから |
| 基準体との比による正規化に前例がない | Smith and Senturia 1995。AirCodeも既知値セルでその場訓練と正規化を行う |
| 100bitを超える秘密を電源なしの日用品に埋めた先行研究がない | DNA-of-thingsが老眼鏡に約1120万bit。著者自身が抄録でsteganographyと明記 |
| 半音格子を符号語彙にした例がない | Whooshが管長式 L = 14.956 × 2^(i/12) と識別語彙を同じ節に書いている。Lamelloはalphabet sizeとde Bruijn列 |
| 電源も電子部品も持たない3Dプリントの笛を複数本融合し吹いて読む | WhooshのFluteCase、US4821670A、US5113784、US10147410B2 |
| 管長と音高の対応式にもとづいて設計し実機で検証した | Printone、demakein、openwind。US5251569Aの明細書が1991年に「通常の場合」と記載 |
| 1つの印刷物から複数の音高を出す | Printoneが指孔5個で9音 |
| 薄くサポート材なしで鳴る平板型のフィップル笛を作った | Flat Pocket Whistle（ダウンロード97,000件） |
| 隣り合う記号が同じにならない制約を導入した | Acoustic Barcodesが0の連続禁止を明記、Goldmanら2013 |
| 電源不要の物理媒体に誤り訂正符号付きで秘密を格納した | codex32。しかも復号に電子機器を要しない |
| この分野で脅威モデルを持つのは初めてである | Secure Information Embedding in Forensic 3D Fingerprinting（2024） |
| 網羅的に探して存在しなかった | 「今回の検索範囲では確認できなかった」と書く |

## 使う数値

### 確定しているもの（一次資料で確認済み）

比較表に使う先行研究の実証容量である。全13件の本文を取得して確認した。

| 研究 | 読み出しに要する装置 | 動作 | 実証容量 | 誤り訂正 | 脅威モデル |
| --- | --- | --- | --- | --- | --- |
| InfraStructs (2013) | テラヘルツ分光装置 | 受動 | 27 bit | なし | なし |
| Acoustic Voxels (2016) | スマートフォン1台 | 白色雑音／叩く | 4 bit | なし | なし |
| AirCode (2017) | プロジェクタとカメラと偏光板（撮像3〜4分） | 受動 | 約106 bit（2cm角）、約500 bit（5cm角） | Reed–Solomon（冗長40%） | なし |
| LayerCode (2019) | 一般的なカメラ | 受動 | 24 bit（近赤外の変種は12 bit） | なし（あえて付けないと明記） | なし |
| G-ID (2020) | スマホカメラと小型光源 | 受動 | 7.672 bit（204通り）、14.065 bit（17,136通り） | 訂正なし（36通りのうち2通りを誤り検査に予約） | なし |
| Acoustic Barcodes (2012) | 圧電接触マイク | こする | **訂正後12 bit**（4096通り）。生の符号長は最大24 bit | 拡張Golay、短縮BCH、短縮Hamming | なし |
| Lamello (2015) | 接触マイク | はじく | 2.0 bit相当（櫛歯4枚で適合率93%） | なし | なし |
| Blowhole (2018) | ノートPC内蔵マイク | 吹く | 2.585 bit相当（6個を98%）、上限9個で3.170 bit相当 | なし | なし |
| Seedmarkers (2021) | 一般的なカメラ | 受動 | 23.437 bit（11,358,880通り） | なし（著者が欠点と明記） | なし |
| InfraredTags (2022) | 自作の近赤外撮像モジュール（20ドル、132g） | 受動 | 83.05 bit相当（21×21のQRコード） | QRコード規格の機能に依拠 | なし |
| AnisoTag (2023) | 自作の検出装置（レーザーと光導電素子16個） | 滑らせる | 51 bit（クレジットカード同寸）、画像処理併用で160 bit | 記述なし | なし |
| StructCode (2023) | 一般的なカラーカメラ | 受動 | 最大228.23 bit | なし（対応表の暗号化に一言） | なし |
| SoundOff (2025) | 超音波マイク（384kHz） | 受動 | 3.907 bit相当（15個を93.75%） | なし | なし |
| FluteCase (2016) | スマートウォッチのマイク | 吹く | **情報量の概念がない**（8鍵の選択） | なし | なし |

**表に添える注意。** AnisoTagが本文で「同寸のタグでAnisoTagは51 bit、LayerCodeは25 bit、acoustic barcodeは40 bitを符号化する」と三者比較を書いている。寸法はクレジットカードと同寸である。**本研究のカード実装はこの3つと直接並べられるので、査読者が持ち出す前に自分から書く。**

**引用の事故を避けること。** Blowholeの予稿集のファイル名は `gi2018-18.pdf` である。`gi2018-16.pdf` はFittsの法則に関する無関係な論文であり、番号を誤ると存在しない引用になる。

### 【要確認】著者に判断を仰ぐべきもの

**スロット体系が3つ並存している。** 実装を読んだ結果である。

| 場所 | 音域 | スロット数 | 隣接同音禁止 | パリティ |
| --- | --- | --- | --- | --- |
| `fue/cipher_codec.py` の既定値 | F#6〜F#7 | 13 | 無効 | 2 |
| `docs/cipher/cipher_config.json`（復号ページの既定） | G#6〜F#7 | **11** | — | 0 |
| `fue/cipher_card.py`、`fue/spool_128bit.py`、`fue/bookstand_flutes.py` の `SLOT12` | G#6〜G7 | **12** | 有効 | 2 |
| 旧稿の本文 | F#6〜F#7 | **13** | — | — |

**実際に印刷した物体はすべて12スロット（G#6〜G7）・隣接同音禁止である。** したがって新稿は12スロットで統一して書くのが実装と一致する。1本あたりの生の容量は log₂12 = 3.585 bit、隣接同音禁止のもとでは log₂11 = 3.459 bit である。

ただし復号ページの既定が11スロットなので、**符号化と復号で設定が食い違っていないかを確認する必要がある**（設定をURLで渡しているため、実際には物体ごとに正しい設定が渡っている可能性が高い）。

**較正定数も複数ある。**

| 対象 | 式 | 出典 |
| --- | --- | --- |
| 厚壁ヘッド（mini10） | f = 86718/(L − 11.81) | 旧稿5.1節 |
| 外形統一版（実装の既定） | f = 91891.5/(L + 14.23) | `fue/cipher_codec.py` の `calib_k`、`calib_delta` |

**どちらを本文の代表値とするかは著者の判断による。** 埋め込んだ物体は外形統一版を使っているので、そちらを主とし、厚壁ヘッドの値は較正の節で併記するのが実装と一致する。

## 秘密分散の扱い（案Bで確定）

論文にはこう書く（著者承認済みの文面）。

> 秘密分散の断片を運ぶ場合、業界標準のSLIP-39に準拠すれば、断片1つが200bitとなり笛64本を要するが、標準の道具で復元でき、紙や金属板に保管した断片と混在できる。一方、物体の同一性がメンバー番号を担うことを利用して付加情報を省けば、断片の値128bitのみで足り笛49本に収まるが、復元には本手法の知識が必要になる。相互運用性と符号量のどちらを取るかは、運用の設計変数である。

そのうえで**実装したのは後者である**と明記する。旧稿の表5にあった「断片は各148 bit」という数字は誤りなので、上の記述に置き換える。

**SLIP-39には関連研究として触れる価値のある設計がもう1つある。** パスフレーズが正しいかを検証する方法を意図的に持たないため、違うパスフレーズからは違う、しかし一見正当なシードが得られる。強要されたときに囮のパスフレーズを渡せるという、**もみ消し可能性のための設計**である。本研究が物理層の偽装で狙っているものを**データ層で実現した既存の標準**にあたるので、脅威モデルか関連研究で1文触れる。

## 実装は変更しない

検証の過程で挙げた3点は、いずれも**実装の修正を要しない**ことが確認された。直すのは論文の文章だけである。印刷済みのものも1つも無駄にならず、笛を増やす必要もない。詳細は `REVIEW_AND_REPOSITIONING.md` の「実装は変えなくてよい」の節にある。

## 追加する参考文献

`REFERENCES_TO_ADD.md` にすべての書誌と確認先のURLがある。**最小限に絞るなら次の8件が必須である。** WhooshのFluteCase、Printone、codex32、SeedQR、QR SafeShare、SoundOff、InfraredTags、造形機の音響側チャネル（Chhetriら）。

国内の近接研究として、久保さんらのFabAuth、上平さんらの一連の研究、水木さんらのカードベース暗号、伊藤さんらの3Dプリント装置、大川さんと栃窪さんの視覚復号型秘密分散も入れる。**WISSの読者が最初に想起する研究群なので、落とすと国内先行を調べていないと見なされる。**

## ページ数について

**当面は気にしない。** 言うべきことが言える分量で書き、削り方は後から著者が判断する。最終的な制限は本文6ページ以内（参考文献、謝辞、未来ビジョンは含まない）である。

削る候補は次のとおりである。通信方式の歴史を一段落から一文へ、利用プロファイルの表を削除、ユースケースをカードと128bitの担体の2つに絞る、印刷の向きの実験を結果2文だけにする、モスキート音の節を削除、未実施の評価の小節を一段落にまとめる、脅威モデルの2つの表を1つに統合する、比較表を5件程度に絞る。

一方で、**差分符号化により1つの音高の誤りが2記号へ波及するため、Reed–Solomon符号のブロックをインターリーブして分散させる**という設計は残す。この研究に固有の工学的内容であり、一般的な制約符号の理論を長く書くより価値がある。

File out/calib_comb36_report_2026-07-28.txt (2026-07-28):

較正コーム36本 2026-07-28 実測の集計（確定版）
生データ: out/calib_comb36_measured_2026-07-28.txt

前提
  吹いた向きは36番側から1番側（測定値から判定。正順との費用比は58対723）。
  1番から3番（G#6・A6・A#6）は造形不良で鳴らず、34番から36番は吹いていない。
  低音4音が並ぶ21番から24番と29番から32番は、続けて吹く測り方では対応が
  1スロットずれても同程度に尤もらしいので、1本ずつ吹き直した値を使っている。
  較正定数の当てはめには、STLから実測した空洞の長さを使った。
  G#6だけは外形の長さに頭打ちされて設計より1.57mm短い。他の11音は0.09mm以内。

較正コーム36本の集計（吹鳴3回ぶん）

[位置ごとの測定値]
  番号 音名   測定値                     狙いからのずれ  吹鳴ばらつき
    1  G#6  （鳴らず）                            - cent       - cent
    2  A6   （鳴らず）                            - cent       - cent
    3  A#6  （鳴らず）                            - cent       - cent
    4  B6   1986.3 1992.2 2003.9         +16.2 cent     7.8 cent
    5  C7   2158.0 2147.6 2141.9         +45.8 cent     6.6 cent
    6  C#7  2276.7 2319.2 2299.9         +62.2 cent    16.0 cent
    7  D7   2399.5 2407.7 2396.9         +37.9 cent     4.1 cent
    8  D#7  2597.1 2600.7 2537.0         +60.9 cent    24.1 cent
    9  E7   2756.5 2770.1 2756.5         +79.6 cent     4.9 cent
   10  F7   2888.7 2896.0 2963.1         +73.9 cent    24.3 cent
   11  F#7  3073.2 3090.5 3101.4         +73.5 cent     8.0 cent
   12  G7   3258.2 3261.6 3268.6         +68.6 cent     2.8 cent
   13  C7   2158.8 2192.0 2132.8         +55.4 cent    23.7 cent
   14  C#7  2296.4 2345.3 2275.7         +67.5 cent    26.8 cent
   15  D7   2388.2 2438.4 2438.6         +52.5 cent    20.8 cent
   16  D#7  2540.8 2545.5 2571.4         +43.6 cent    11.2 cent
   17  E7   2709.0 2706.2 2760.1         +56.8 cent    19.2 cent
   18  F7   2873.6 2911.7 2886.0         +58.8 cent    11.6 cent
   19  F#7  3070.3 3080.7 3096.8         +70.3 cent     7.5 cent
   20  G7   3247.1 3267.7 3283.2         +70.3 cent     9.6 cent
   21  G#6  1740.2                       +80.4 cent       - cent
   22  A6   1804.7                       +43.4 cent       - cent
   23  A#6  1910.2                       +41.8 cent       - cent
   24  B6   2009.8                       +29.8 cent       - cent
   25  E7   2714.6 2701.2 2724.6         +49.5 cent     7.5 cent
   26  F7   2933.2 2890.6 2919.6         +73.2 cent    12.9 cent
   27  F#7  3057.0 3048.5 3102.5         +62.8 cent    16.3 cent
   28  G7   3258.4 3262.8 3250.9         +65.8 cent     3.2 cent
   29  G#6  1728.5                       +68.7 cent       - cent
   30  A6   1803.6                       +42.4 cent       - cent
   31  A#6  1917.4                       +48.3 cent       - cent
   32  B6   2029.9                       +47.0 cent       - cent
   33  C7   2133.7 2133.5 2089.3         +21.1 cent    21.0 cent
   34  C#7  （鳴らず）                            - cent       - cent
   35  D7   （鳴らず）                            - cent       - cent
   36  D#7  （鳴らず）                            - cent       - cent

[音ごとの集計（同じ音の3本）]
  音名   本数 鳴った  平均のずれ   3本の散らばり
  G#6     3    2      +74.6 cent     8.3 cent
  A6      3    2      +42.9 cent     0.7 cent
  A#6     3    2      +45.0 cent     4.6 cent
  B6      3    3      +31.0 cent    15.4 cent
  C7      3    3      +40.8 cent    17.7 cent
  C#7     3    2      +64.8 cent     3.8 cent
  D7      3    2      +45.2 cent    10.3 cent
  D#7     3    2      +52.2 cent    12.2 cent
  E7      3    3      +61.9 cent    15.7 cent
  F7      3    3      +68.6 cent     8.5 cent
  F#7     3    3      +68.9 cent     5.5 cent
  G7      3    3      +68.2 cent     2.3 cent

[鳴らなかった位置（造形不良）]
  6本／36本。1番(G#6)、2番(A6)、3番(A#6)、34番(C#7)、35番(D7)、36番(D#7)

[指標]
  吹き方のばらつき: 15.2 セント（自由度44）
  造形のばらつき  : 11.0 セント（自由度18、そのまま）
  造形のばらつき  : 吹き方のばらつきに埋もれて検出できない
      → 本どうしの散らばりは、吹き方のばらつきだけで説明がつく大きさである。
      → 造形のばらつきは多くとも 11.0 セント程度と言える（それ以上の主張はできない）。
      → 50セント刻みには有利な結果だが、確かめるには吹き方のばらつきを小さくした測り直しが要る。
  全音に共通するずれ: +55.4 セント（基準笛との比で読むので復号では消える）
  音によって違うずれ: 13.6 セント（実効値）、最大は B6 の -24.4 セント
      → ずれはほぼ全音一律なので、較正定数を直すだけで済む。
  G7: 3本中3本が鳴った。共通のずれを引いた残りは +13.3、+15.0、+10.4 セントである。
      → 3本とも±50セント以内なので、12スロット体系を既定へ昇格できる。

[較正定数の再推定]
  現行 A=88811.7 e=-8.612
  再推定 A=87985.1 e=-10.010（30本で当てはめ、残差の実効値 11.3 セント、管長は実測値）
  out/cipher_mini10_calib.txt をこの値へ書き換えると、以後の笛がこの較正で刷られる。

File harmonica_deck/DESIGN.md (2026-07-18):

# ハーモニカライク・カード笛デッキ 設計

ダイアトニック・ハーモニカは調ごとに1本あり、転調したらその調のものに持ち替える。C のハーモニカは
（同じ白鍵で）**C メジャーと、その平行調 A マイナー**の両方を担当する。これをコード笛カードで再現し、
**1枚のカード＝1本のハーモニカ（1調）**、クレジットカードサイズのデッキにする。

コード笛の素性は本体リポジトリの `fue/chordflute.py` と `fue/namecard.py`、クリーン音域の実測は
cosense「AI笛作り」を参照。

---

## (1) C のハーモニカで鳴らせるコード＝1枚が含むべきコードセット

### 実機ハーモニカ（Richter配列）で実際に出るコード
10穴ダイアトニック（C）は吹き（blow）と吸い（draw）でコードが決まる:
- **吹き**: C E G の並び ＝ **C major**（トニック）
- **吸い（低音側）**: D G B D … ＝ **G(7)**（ドミナント。G B D + F で G7）
- **吸い（中央）**: D F A ＝ **D minor**（ii）

つまり実機は「吹けば I、吸えば V7 と ii」くらいに限られる（ベンドしない普通吹き）。これが
「普通に吹いて鳴らせるコード」の実態。

### カード笛は各管を独立に吹けるので、ダイアトニック和音を全部並べられる
我々のカードは吹き/吸いの制約が無く、隣り合う管を選んで吹く。だから **その調のダイアトニック三和音を
すべて**カードに載せられる（実機の上位互換）。C major ＝ A minor（白鍵7音 C D E F G A B）の
ダイアトニック三和音は:

| 度数(C major / A minor) | 和音 | 種類 |
|---|---|---|
| I / III | C  | major |
| ii / iv | Dm | minor |
| iii / v | Em | minor |
| IV / VI | F  | major |
| V / VII | G  | major |
| vi / i | Am | minor |
| vii° / ii°| Bdim | dim（常用しない） |

**主要和音の和集合**＝ C major の I·IV·V（C F G）＋ A minor の i·iv·v（Am Dm Em）
＝ **{C, F, G, Am, Dm, Em} の6つ**。これが1枚が含むべきコアのコードセット。
（Bdim は実用されないので割愛。和声的短調のドミナント E major は導音 G# を要し白鍵に無い＝後述の制約。）

---

## (2) メジャーとマイナーで別カードが要るか → **要らない（1枚で両方）**

平行長短調は**同じ7音**（C major と A minor はどちらも白鍵）。だから1枚のカードに7音を三度連鎖で
並べれば、隣接3本がメジャーの和音にも平行ナチュラルマイナーの和音にもなる。実際、本デッキの
8本カード（下記）は隣接3本で

    Dm · F · Am · C · Em · G   （＝ ii·IV·vi·I·iii·V）

の6和音を出し、これは **C major の I·IV·V·ii·iii·vi** と **A minor(自然的短音階) の i·iv·v·III·VI·VII** を
**まるごと両方**含む。よって **メジャー＋平行ナチュラルマイナーは1枚で足りる**。

### 唯一の例外＝和声的短調のドミナント
A マイナーを「終止感のある短調」にするには V=**E major**（E G# B）が要り、これは導音 **G#** を含む。
G# は C major の白鍵に無いので、この1枚（＝白鍵ハーモニカ）では出せない。**これは実機のダイアトニック・
ハーモニカとまったく同じ制約**。もし和声的短調まで欲しければ、導音を上げた「短調専用カード」を別に作る
（→ 拡張として12枚の短調デッキ。ナチュラルマイナーは既に本デッキでカバー済みなので、追加価値は
和声的短調のドミナントだけ）。**基本デッキではメジャー1枚＝平行ナチュラルマイナー兼用**とする。

---

## (3) ハーモニカの調の種類 → **12種（クロマチックの全キー）**

ダイアトニック・ハーモニカは12キーで売られる: **C, Db, D, Eb, E, F, F#, G, Ab, A, Bb, B**。
（Low版・High版はオクターブ違いの同一キー。ナチュラル/ハーモニックマイナー・チューニング品も各12キーで
存在するが、キーの種類としては12。）よって

> **基本デッキ＝12枚**（各キーのメジャー＋平行ナチュラルマイナー兼用カード）。

これで24調（12メジャー＋12平行短調）を担当できる。

### 全12調が本当に作れるか（幾何の裏づけ）
コード笛のクリーン音域 **F6→E7 は半音でちょうど長7度＝12ピッチクラスが1つずつ入る「窓」**。
だから**どの調の7音も、オクターブ一意でこの窓に必ず収まる**。実際に12調すべてを生成して
watertight・クレジットカード寸法に収まることを確認済み（`deck_preview.png`、`cards/`）。

---

## (4) カード仕様（クレジットカード）

- 外形 **85.60 × 53.98 × 4.0 mm**（ISO/IEC 7810 ID-1）。
- **8本の半割り笛**を三度連鎖（度数 **2·4·6·1·3·5·7·2**）で並べる。8本＝幅約53.9mmが短辺53.98mmに
  ちょうど収まる（片側0.04mm）。四隅の角丸は両端の笛口元を守るため 1.2mm。
- 隣接3本（ステップ1）で6和音 **ii·IV·vi·I·iii·V**。度数2が両端に重複＝同じ長さの管が左右端に来る
  （幾何的に無問題。両端の管が ii と V の両方に効く）。
- 並びは既定で反転（大きい＝低い音の笛が並びの大側）。刻印は帯にステンシル貫通穴で調性（例 `C / Am`）を
  z軸180°回転で入れる（`fue/stencil.py`・`fue/namecard.py` の既定）。
- 刻印フォント＝**Black Ops One**（`fue/fonts/` に同梱・SIL Open Font License）。設計段階で橋が入った
  本物のステンシル書体なので、字の中の島（O/A/D等）が脱落せず美しく確実に型抜きできる。全12ラベルで
  島0・全グリフ（`#` `/` 小文字 `b`）を検証済み。非ステンシルフォントを渡した場合の橋の自動生成も
  `stencil.py` にフォールバックとして残す。
- 板0.5mm壁のため、印刷は**外壁/内壁線幅0.5mmのcareful条件**が前提（実機成立の要点、cosense参照）。

### 各カードの並びと和音（生成器の実出力）

| カード | 並び (F6→E7窓) | 隣接3本の6和音 |
|---|---|---|
| C / Am | D7 F6 A6 C7 E7 G6 B6 D7 | Dm F Am C Em G |
| G / Em | A6 C7 E7 G6 B6 D7 F#6 A6  | Am C Em G Bm D |
| D / Bm | E7 G6 B6 D7 F#6 A6 C#7 E7 | Em G Bm D F#m A |
| A / F#m  | B6 D7 F#6 A6 C#7 E7 G#6 B6| Bm D F#m A C#m E |
| E / C#m  | F#6 A6 C#7 E7 G#6 B6 D#7 F#6 | F#m A C#m E G#m B |
| B / G#m  | C#7 E7 G#6 B6 D#7 F#6 A#6 C#7 | C#m E G#m B D#m F# |
| F# / D#m | G#6 B6 D#7 F#6 A#6 C#7 F6 G#6 | G#m B D#m F# A#m C# |
| Db / Bbm | D#7 F#6 A#6 C#7 F6 G#6 C7 D#7 | D#m F# A#m C# Fm G# |
| Ab / Fm  | A#6 C#7 F6 G#6 C7 D#7 G6 A#6 | A#m C# Fm G# Cm D# |
| Eb / Cm  | F6 G#6 C7 D#7 G6 A#6 D7 F6 | Fm G# Cm D# Gm A# |
| Bb / Gm  | C7 D#7 G6 A#6 D7 F6 A6 C7  | Cm D# Gm A# Dm F |
| F / Dm | G6 A#6 D7 F6 A6 C7 E7 G6 | Gm A# Dm F Am C |

（和音名はシャープ表記。A#=Bb, D#=Eb, G#=Ab, C#=Db。カード刻印は慣用の平行短調ラベル。）

---

## 演奏の統一性（すべてのカードを「同じように吹ける」か）

ハーモニカのアナロジーで最重要なのは「1つの運指を覚えれば、キーの違うハーモニカに持ち替えても同じ操作で
移調して演奏できる」こと。本デッキはこれを満たしている:

- **機能→位置の対応は全カード同一**。全調で度数連鎖 2·4·6·1·3·5·7·2 を使うので、
  「位置0-2=ii、1-3=IV、2-4=vi、3-5=I、4-6=iii、5-7=V」がどのカードでも同じ。
  例: どのカードでも「位置3-5の3本を吹く＝そのキーの I（トニック）」。和音の中身だけが移調する。
- **吹き口インターフェースも全カード同一**。8つの吹き口はすべて片端(x=0)に整列し、ピッチ6.70mm一定。
  口を当てる面は全カードまったく同じ格子。

つまり「同じ運指で移調」が成立している。

### では、なぜカードごとに笛の長さ（階段の形）が違って見えるのか
違うのは**足側の管長（＝隠れたチューニング）だけ**。理由は、コード笛のクリーン音域が
**F6→E7＝長7度（約1オクターブに1歩足りない）しかない**ため、各キーの7音をこの狭い窓に「折り畳んで」
収めているから。ある機能の音でも、キーが変わるとピッチクラスが変わり、窓の中で長さが飛ぶ（窓端で巻き戻る）。
これは**実機ハーモニカが、キーごとに違うチューニングのリードを、同一の穴配置の裏に隠している**のと同じ構図。
吹き口（インターフェース）は同一、隠れた長さ（チューニング）だけが違う。

### 「階段の形」まで完全に同一にしたい場合（剛体移調）
全カードで長さパターンまで同一にする＝1枚を丸ごと平行移動した剛体移調にするには、トニックを動かしても
全音が収まる **1.5〜2オクターブ以上のクリーン音域**が要る。現行の半割り笛は高音側の約長7度しか綺麗に
鳴らないので剛体移調は全12調では成立しない（遠いキーで音域外に出て鳴らない）。実現するには、低音・高音で
ヘッドサイズを変えた**笛ファミリー化**（リコーダー属のような大小のヘッド）が必要で、これは別途の大きな設計。
→ 当面は「機能→位置は同一・チューニングだけ窓に折り畳む」現行方式を推奨（全調がクリーン域で確実に鳴る）。

---

## 実機化での注意（cosense実測より）

- **印刷信頼性**: 堅く鳴るのは概ね〜D7(2349Hz)。窓の上端 D#7/E7 の管は個体差でムラが出やすい。窓が
  F6→E7 なので各カードに上端寄りの管が1本前後含まれる（その和音の1音が弱く出る可能性）。低音側 F6 は余裕。
- **0.5mm壁**: 素の0.08mmスライスでは全滅（かすれ無音）。**線幅を壁厚0.5mmに合わせる**と鳴る（H2D白PLAで
  実証）。デッキ印刷もこの条件で。材料切り分け（PLA Basic/PETG）が別途進行中。
- **演奏**: 隣接3本を同時に吹く／転がす。8本・ピッチ6.7mmで幅いっぱいなので、口の当て方に慣れが要る。

## 生成方法

```
# 解析だけ（STLを作らず全調のコード表を出す）
mesh_venv/bin/python harmonica_deck/deck.py --analyze
# 12枚のSTLを harmonica_deck/cards/ に生成
mesh_venv/bin/python harmonica_deck/deck.py
```

`deck.py` は本体の `fue/chordflute.py`（三度連鎖・窓配置）と `fue/namecard.py`（カード融合・刻印）を
再利用する。低レベルのスライス・印刷は既存スキル／別セッションの印刷キューに委ねる。

## ファイル

- `deck.py` … デッキ生成器（12調・8本カード）
- `cards/card_*.stl` … 12枚のカードSTL（クレジットカード・調性刻印つき）
- `deck_preview.png` … 12枚一覧プレビュー
- `DESIGN.md` … 本文書

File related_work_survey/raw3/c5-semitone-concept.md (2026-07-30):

# 反例検証 c5: 半音格子を符号語彙とする発想は先行研究に存在しないのか（語ではなく概念で探し直す）

調査日: 2026年7月30日
調査者: 反例検証担当（第三段）
検証対象の批判: 「`semitone` という語が0件だから半音格子を符号語彙とする発想は先行研究に存在しないという結論は、単語の不在と概念の不在を混同している。Whooshは本文で管長を 2^(i/12) によって定めており、`semitone` という語がなくても概念として半音格子を使っている」

---

## 0. 結論

**この批判は正しい。反例は成立する。**

概念で探し直した結果、次の三つが一次資料で確認できた。

第一に、Whoosh の FluteCase は、管長を公比 2^(1/12) の等比数列で定めているだけでなく、そこから生じる8つの離散した共鳴周波数を「どの領域を吹いたかを見分けるため」に使うと本文に明記している。すなわち「等比数列で並べる」ことと「その離散周波数の集合を識別の語彙として使う」ことの両方が、2016年に既に一つの論文の中で揃っている。単語の不在を根拠に概念の不在を言うことはできない。

第二に、公比が半音比かどうかを問わなければ、「受動的な造形物に複数の共鳴体を並べ、その離散周波数の集合を識別や符号化の語彙として使う」研究は複数存在する。CHI 2015 の Lamello は櫛歯の長さを変えて7つの離散周波数を作り、どの歯が叩かれたかを識別し、さらにドブラン列で位置を符号化している。Journal of Applied Physics 2022 の水中音響バーコードは、球の半径を変えて共鳴峰の有無を3ビットの二進符号として読み出している。

第三に、平均律の格子そのものを符号の語彙として使う先行例も存在する。Google の特許「Communicating data with audible harmonies」は、平均律の音名から成る音階を記号写像として指定している。日本語文献では、中沢誠と山崎芳男による「1/12Nオクターブ分析を用いた音の符号化」が、12音平均律に基づく対数等間隔の周波数分割を符号化の格子として使い、分割数 N を設計変数として扱っている。

したがって、SURVEY.md 第180行の「半音刻みの格子を符号の語彙とする発想は、この系譜の後続に一切現れない」という文は、そのままでは維持できない。ただし後述するとおり、CipherFlute に残るものは依然としてある。格子そのものではなく、格子の使い方の側にある。

---

## 1. 観点1: 櫛歯、管、板、共鳴器を等比数列で並べた受動的なデバイス

### 1.1 Whoosh / FluteCase（ISWC 2016）——決定的な反例

| 項目 | 内容 |
|---|---|
| 題名 | Whoosh: Non-Voice Acoustics for Low-Cost, Hands-Free, and Rapid Input on Smartwatches |
| 著者 | Gabriel Reyes, Dingtian Zhang, Sarthak Ghosh, Pratik Shah, Jason Wu, Aman Parnami, Bailey Bercik, Thad Starner, Gregory D. Abowd, W. Keith Edwards |
| 掲載 | Proceedings of the 2016 ACM International Symposium on Wearable Computers, pp. 120-127 |
| DOI | 10.1145/2971763.2971765 |
| 書誌の確認先 | https://api.crossref.org/works/10.1145/2971763.2971765 （題名、著者10名、会議名、120-127ページ、2016年をそのまま返した） |
| 全文の確認先 | https://sites.cc.gatech.edu/fac/keith/pubs/iswc2016-whoosh.pdf （本調査で自分で取得し、pdftotext で本文を抽出して該当箇所を目視した） |

本文6ページの該当箇所を抽出したままの形で示す。

> "The cases have 8 closed pipe tubes of different lengths, each with an open hole. ... The eight tubes are designed to resonate at eight distinct frequencies between 2kHz to 10kHz, allowing blows near particular regions of the watch face to be readily disambiguated."

日本語訳: 「ケースは長さの異なる8本の閉管を持ち、それぞれに開いた穴が一つある。（中略）8本の管は2キロヘルツから10キロヘルツの間の8つの異なる周波数で共鳴するよう設計されており、これにより時計面の特定の領域の近くへの吹奏を容易に見分けられる。」

そして設計式が続く。

> "The length of each tube is defined by:  L = 14.956 ∗ 2^(i/12) [mm] (2)  where L is the length of each tube as a function of i, which denotes the ith tube."

日本語訳: 「各管の長さは次式で定義される。ここで L は i の関数としての各管の長さであり、i は i 番目の管を表す。」

さらに図5Gの説明文にも次の一文がある。

> "(G) bezel blows (labeled on the figure) starting from the lowest to highest resonant frequency."

日本語訳: 「(G) 最低の共鳴周波数から最高の共鳴周波数へと順に並べたベゼル吹き（図中に名前を付した）。」

この三つを並べると、批判の言うとおりのことが確認できる。第一に、公比は 2^(1/12) であり、これは平均律の半音比そのものである。第二に、その8つの離散周波数は「見分ける（disambiguate）」ために設計されたと明言されている。すなわち離散周波数の集合が識別の語彙として使われている。第三に、著者たちは図の説明で管を共鳴周波数の順に並べており、周波数の並びを構造として意識している。

`semitone` という語が0回であることは事実だが、それは概念の不在を意味しない。前段の推論は誤りである。

なお、前段の報告（raw2/v1-whoosh-flutecase.md）が指摘した差分は今回も変わらず成り立つ。読み取り側はメル周波数ケプストラム係数とサポートベクターマシンによる利用者ごとの学習分類であって、基本周波数の推定と量子化ではない。また管長は論文に公開された固定の定数であり、すべての複製が同一形状になることを意図している。この二点は後述する。

### 1.2 Lamello（CHI 2015）——語彙としての離散周波数は先取りされている。ただし等比ではない

| 項目 | 内容 |
|---|---|
| 題名 | Lamello: Passive Acoustic Sensing for Tangible Input Components |
| 著者 | Valkyrie Savage, Andrew Head, Björn Hartmann, Dan B. Goldman, Gautham Mysore, Wilmot Li |
| 掲載 | Proceedings of the 33rd Annual ACM Conference on Human Factors in Computing Systems, pp. 1277-1280 |
| DOI | 10.1145/2702123.2702207 |
| 書誌の確認先 | https://api.crossref.org/works/10.1145/2702123.2702207 （題名、著者6名、CHI 2015、1277-1280ページ、2015年を返した） |
| 全文の確認先 | https://people.eecs.berkeley.edu/~bjoern/papers/savage-lamello-chi2015.pdf （本調査で自分で取得し、pdftotext で抽出した） |

Lamello は、長さの違う櫛歯（tine）を並べた受動的な3Dプリント部品であり、叩かれた歯の基本周波数から「どの歯が叩かれたか」を判定する。名前は親指ピアノの類（ラメロフォン）に由来すると本文が述べている。

重要なのは、Lamello が離散周波数の集合を明示的に符号の語彙として扱っている点である。

> "Encoding information: We use unique f0s to differentiate buttons and directions on a D-pad. For position sensing, f0 can increase across the range of motion. If more distinctions are needed than can be reliably recognized by varying f0, we create de Bruijn patterns. ... A de Bruijn sequence D(k, n) is one which, given an alphabet size k and a subsequence length n, contains each subsequence exactly once: we can uniquely infer sequence position from n recognitions."

日本語訳: 「情報の符号化: 我々は固有の基本周波数を使って、ボタンと十字キーの方向を区別する。位置検出については、可動域にわたって基本周波数を増加させることができる。基本周波数を変えることで確実に認識できる数より多くの区別が必要なら、ドブラン模様を作る。（中略）ドブラン列 D(k, n) とは、字母の大きさ k と部分列の長さ n が与えられたとき、各部分列をちょうど一度ずつ含む列である。すなわち n 回の認識から列中の位置を一意に推定できる。」

`alphabet size k`（字母の大きさ）という語がそのまま使われている。つまり「離散した基本周波数の集合を字母とし、その列で情報を符号化する」という発想は、2015年に完全に成立している。この点は CipherFlute の新規性ではない。

ただし**格子は等比ではない**。本文は次のように書いている。

> "for dials and sliders that encode position with linearly increasing tine lengths"

日本語訳: 「歯の長さを線形に増加させて位置を符号化するダイヤルとスライダについては」

論文が報告した7本の歯の基本周波数（図6）は、スライダが 924, 1103, 1340, 1662, 2116, 2784, 3824 ヘルツ、ダイヤルが 840, 1003, 1218, 1511, 1923, 2530, 3478 ヘルツである。私がこれらから計算した結果を示す（論文が報告した値ではなく私の計算である）。

| 隣接する2本の間隔（セント） | スライダ | ダイヤル |
|---|---|---|
| 1本目と2本目 | 306.6 | 307.0 |
| 2本目と3本目 | 337.0 | 336.2 |
| 3本目と4本目 | 372.8 | 373.2 |
| 4本目と5本目 | 418.1 | 417.4 |
| 5本目と6本目 | 475.0 | 474.9 |
| 6本目と7本目 | 549.5 | 550.9 |

対数軸上の間隔は307セントから550セントへ単調に広がっており、等間隔からはほど遠い。片持ち梁の基本周波数は長さの2乗に反比例するので、1/√f が長さに比例するはずである。実際に 1/√f の隣接差を計算すると、スライダで 278.7, 279.2, 278.9, 279.0, 278.7, 278.1（いずれも10のマイナス5乗単位）となり、0.4パーセント以内で一定である。すなわち歯の長さは厳密に等差数列であり、周波数は等比数列ではない。

さらに Lamello 自身が、周波数の配り方をまだ決めていないと述べている。

> "Future work can also probe optimal frequency distributions to avoid overlap between tine harmonics."

日本語訳: 「今後の課題として、歯の倍音どうしの重なりを避けるための最適な周波数分布を調べることもできる。」

したがって「対数軸上で等間隔に切る」という選択は Lamello にはない。Lamello が達成できなかったのは2キロヘルツを超える帯域の分類であり（7本のときの再現率はスライダで56パーセント、ダイヤルで54パーセントまで落ちる）、その原因を高い周波数のエネルギーの低さと減衰の速さに帰している。

### 1.3 水中音響バーコード（Journal of Applied Physics 2022）——符号語彙だが等分割は線形

| 項目 | 内容 |
|---|---|
| 題名 | Passive underwater acoustic barcodes using Rayleigh wave resonance |
| 著者 | Yanling Zhou, Jun Fan, Jinfeng Huang, Bin Wang |
| 掲載 | Journal of Applied Physics, 131巻12号, 論文番号124901, 2022年 |
| DOI | 10.1063/5.0086290 |
| 書誌の確認先 | https://api.crossref.org/works?query.title=Passive+underwater+acoustic+barcodes+using+Rayleigh+wave+resonance |
| 全文の確認先 | https://arxiv.org/pdf/2107.13860 （本調査で自分で取得し、pdftotext で抽出した。出版社のページ https://pubs.aip.org/aip/jap/article-abstract/131/12/124901/2836637/ は403を返して読めなかった） |

アクリル球のレイリー波共鳴を使い、球の半径を変えて後方散乱の共鳴峰の位置を制御し、周波数領域に白黒のバーコードを作る研究である。抽出した本文から関係する記述を示す。

> "The frequency spectrum of the broadband signal over the range 6-10.5 kHz is divided into three uniform subbands, and each subband width is Δf = 1.5 kHz."

日本語訳: 「6キロヘルツから10.5キロヘルツの範囲の広帯域信号の周波数スペクトルは、三つの一様な副帯域に分割され、各副帯域の幅は1.5キロヘルツである。」

> "spheres with radii of a1 = 0.045 m, a2 = 0.05 m, a3 = 0.06 m, and a4 = 0.065 m are separately selected."

日本語訳: 「半径 0.045メートル、0.05メートル、0.06メートル、0.065メートルの球がそれぞれ選ばれた。」

そして「Binary codes 001 010 100 101 110 011 111」という表があり、7通りの組み合わせが3ビットの二進符号に対応する。

すなわち「受動的な物体の共鳴周波数の集合を符号語彙として読み出す」という枠組みは成立しているが、帯域の分割は一様（線形）であり、半径も等比数列ではない（比は 1.111, 1.200, 1.083 とばらばらである）。したがって対数格子の反例にはならない。ただし「物体の形状が符号を担い、読み取り側は事前にその値を知らない」という向きは、Whoosh よりも CipherFlute に近い。この点は素直に認めるべきである。

なお、この論文は参考文献として Harrison らの Acoustic Barcodes（UIST 2012, DOI 10.1145/2380116.2380187, 563-568ページ, https://api.crossref.org/works/10.1145/2380116.2380187 で確認）を引いている。Acoustic Barcodes は刻みの間隔から時間領域で二進の識別子を作るものであり、周波数の格子は使っていない。

### 1.4 反例にならなかったもの

- **FabAuth（CHI Extended Abstracts 2019）**。題名は Printed Objects Identification Using Resonant Properties of Their Inner Structures、著者は Yuki Kubo, Kana Eguchi, Ryosuke Aoki, Shigekuni Kondo, Shozo Azuma, Takuya Indo、1-6ページ、DOI 10.1145/3290607.3313005（https://api.crossref.org/works/10.1145/3290607.3313005 で確認）。3Dプリント物体の内部構造の違いから生じる共鳴特性の差で個体を識別する。ただし共鳴周波数は設計された格子上に置かれるのではなく、任意の内部構造から創発するものを照合するだけである。本文は dl.acm.org が403を返して読めず、内容は検索結果の要約に留まる。
- **SoundOff（IMWUT 2025）**。題名は SoundOff: Low-cost Passive Ultrasound Tags for Non-invasive and Non-Intrusive Smart Home Sensing、著者は Yibo Fu, Vivian Shen, Víctor Riera Naranjo, Bolei Deng, Alex Adams, Josiah Hester、9巻4号、DOI 10.1145/3770666（https://api.crossref.org/works/10.1145/3770666 で確認）。電子部品を持たない受動的な超音波発生タグを幾何形状の違いで数千通り作り分けるという、CipherFlute に近い枠組みである。ただし本文が読めず（ACM は403、NSF の公開版は2026年12月2日まで公開猶予）、周波数を対数格子上に置いているかどうかは**確認できなかった**。今後の追跡対象として最優先で挙げておく。

---

## 2. 観点2: 周波数の集合を対数軸上で等間隔に配置して識別に使う研究（音響以外を含む）

### 2.1 人工基底膜と蝸牛模倣の共振子アレイ

長さの異なる片持ち梁を並べて、蝸牛の場所ごとの周波数対応を機械的に再現する研究群がある。一次資料として次を確認した。

| 項目 | 内容 |
|---|---|
| 題名 | Mechanical frequency selectivity of an artificial basilar membrane using a beam array with narrow supports |
| 著者 | Sangwon Kim, Won Joon Song, Jongmoon Jang, Jeong Hun Jang, Hongsoo Choi |
| 掲載 | Journal of Micromechanics and Microengineering, 23巻9号, 論文番号095018, 2013年 |
| DOI | 10.1088/0960-1317/23/9/095018 |
| 確認先 | https://iopscience.iop.org/article/10.1088/0960-1317/23/9/095018 （要旨全文を取得した） |

要旨には「Each ABM contained 16 beams with various lengths in a one-dimensional array」（各人工基底膜は一次元配列に長さの異なる16本の梁を含む）とあり、周波数選択性の範囲は2キロヘルツから20キロヘルツと書かれている。ただし**長さの与え方が等比なのか等差なのかは要旨に書かれていない**。

もう一つ、Scientific Reports の Jang らの論文（A microelectromechanical system artificial basilar membrane based on a piezoelectric cantilever array and its characterization using an animal model, Scientific Reports 5巻 論文番号12447, 2015年, DOI 10.1038/srep12447, https://pmc.ncbi.nlm.nih.gov/articles/PMC4521187/ で確認）も見たが、「片持ち梁の幅は300マイクロメートル、長さは600から1350マイクロメートルまで変化させた」とあるだけで、分布則の記述は見つからなかった。

検索結果の要約には「resonance frequency of the beam changes exponentially along the array」（梁の共鳴周波数は配列に沿って指数関数的に変化する）という文が Electronic Materials Letters の別論文（DOI 10.1007/s13391-014-4053-2）について現れたが、出版社のページが認証を要求して開けず、**一次資料では確認できなかった**。

いずれにせよ、この系譜は「音を分析するための共振子の並び」であって、「情報を符号化するための語彙」ではない。CipherFlute の新規性への脅威としては弱い。ただし「対数的に周波数を並べた受動的な共振子アレイ」という物理の作り方それ自体が既知であることは、控えめに認めておくべきである。

### 2.2 チップレスRFIDのスペクトル署名

複数の共振器をそれぞれ別の周波数に同調させ、共鳴峰の有無で1ビットずつ符号化するという方式は確立している。すなわち「離散周波数の集合を符号語彙にする」という発想は電波の領域では標準的である。ただし今回調べた範囲では、周波数の割り当てを対数軸上の等間隔にすると明記した一次資料は見つからなかった。見つかったものはいずれも帯域を一様に割る方式か、共振器の形状から決まる位置をそのまま使う方式であった。したがって**観点2に対する反例としては、対数格子の部分は確認できなかった**。

---

## 3. 観点3: 楽器の音階を情報の符号語彙として使った研究

### 3.1 Communicating data with audible harmonies（Google の特許）

| 項目 | 内容 |
|---|---|
| 題名 | Communicating data with audible harmonies |
| 発明者 | Boris Smus, Pascal Tom Getreuer |
| 権利者 | Google LLC |
| 特許番号と日付 | US 9,755,764 B2（出願優先日2015年6月24日、登録2017年9月5日）、および継続出願の US 9,882,658 B2（登録2018年1月30日） |
| 確認先 | https://patents.google.com/patent/US9755764B2/en および https://patents.google.com/patent/US9882658B2/en |

記号写像（symbol map）が特定の調の特定の音階を指定し、その音階の音と和音から記号を作ると書かれている。取得した本文には次の記述がある。

> "the symbol map may specify that the C pentatonic major scale is to be used, meaning that symbols will be formed by selecting notes and chords from the notes of that scale (e.g., [C, D, E, G, A])."

日本語訳: 「記号写像はハ長調のペンタトニック音階を使うと指定することができ、これは記号がその音階の音（たとえばド、レ、ミ、ソ、ラ）から音と和音を選ぶことで作られることを意味する。」

周波数は平均律の値（たとえば C4 は 261.6 ヘルツ、D5 は 587.3 ヘルツ）で与えられている。すなわち「平均律の格子上の離散音高を記号の字母とする」という発想は、2015年の優先日を持つ特許として既に存在する。ただし、これは能動的なスピーカから音を出す音響通信であり、物理的な共鳴体を持つ物体ではない。

なお、検索結果の要約には「半音の間隔をビット0に、全音の間隔をビット1に対応させる」という趣旨の文が現れたが、私が二つの特許本文に当たった限りではその記述を見つけられなかった。**この点は確認できなかった**ものとして扱う。

### 3.2 音楽性信号への符号化による携帯端末用音響通信（三重大学 修士論文, 2014年）

| 項目 | 内容 |
|---|---|
| 題名 | 音楽性信号への符号化による携帯端末用音響通信 |
| 著者 | 大石 智久 |
| 種別 | 三重大学大学院工学研究科情報工学専攻 修士論文（2014年） |
| 確認先 | https://cir.nii.ac.jp/crid/2120307889675241344 および機関リポジトリ https://mie-u.repo.nii.ac.jp/records/9533 |

12音階から協和する音を選んで和音を組み、データのビット値（1と0）を音の有無に一対一で対応させ、音楽理論に従って和音を切り替えながら送信する方式である。CM7、DM7、G7、CM7 という進行を4拍ごとに循環させる実装が書かれている。すなわち「音階を符号の語彙にする」という発想は日本語の学位論文としても存在する。

---

## 4. 観点4: 対数的な周波数の刻みを設計変数として決めた研究

### 4.1 1/12Nオクターブ分析を用いた音の符号化（中沢誠, 山崎芳男, 2003年）

| 項目 | 内容 |
|---|---|
| 題名 | 1/12Nオクターブ分析を用いた音の符号化 |
| 著者 | 中沢 誠, 山崎 芳男（早稲田大学国際情報通信研究科） |
| 掲載 | GITS/GITI research bulletin, 2002巻, 81-85ページ, 2003年, 早稲田大学 |
| 確認先 | https://cir.nii.ac.jp/crid/1572261551695122304 |

これが観点4に最も近い。人間の聴覚が音高に対して比で一定の感度を持つことと、楽譜が12音平均律に基づくことを根拠に、1オクターブを12N分割した対数等間隔の格子を分析と符号化の格子として採用している。分割数 N と分析の基準周波数を自由に選べることを設計の自由度として扱い、聴覚特性を考慮したうえで 705.6 キロビット毎秒の信号をおよそ80.0キロビット毎秒から130.0キロビット毎秒まで落とせたと報告している。

すなわち「対数軸上で半音（またはその N 分の1）刻みに周波数を切り、その格子を符号化に使い、刻みの細かさを設計変数として品質と量の兼ね合いで決める」という発想は、2003年の日本語文献に存在する。これは CipherFlute の「等間隔のセントで切って復号の判定を確実にする」という考え方と、目的こそ違うが構造は同じである。

### 4.2 定Q変換（Brown, 1991年）

| 項目 | 内容 |
|---|---|
| 題名 | Calculation of a constant Q spectral transform |
| 著者 | Judith C. Brown |
| 掲載 | The Journal of the Acoustical Society of America, 89巻1号, 425-434ページ, 1991年 |
| DOI | 10.1121/1.400476 |
| 書誌の確認先 | https://api.crossref.org/works?query.title=Calculation+of+a+constant+Q+spectral+transform&query.author=Brown |

周波数の分点を等比数列に置き、1オクターブあたりの分点数を平均律の半音（あるいは四分音）に合わせることで、音楽の音高の識別に適した分析を行う手法である。書誌は Crossref で確認したが、入手できた全文の写し（https://www.ee.columbia.edu/~dpwe/papers/Brown91-cqt.pdf）は画像として取り込まれた走査版であり、文字が抽出できなかったため、**分点の式そのものを一次資料の文言として引用することはできなかった**。したがってここでは「対数等間隔の周波数格子を音高識別の語彙として使う手法が1991年から標準的に存在する」という一般的な事実を、書誌の確認までに留めて記す。

---

## 5. どこまで探して、何が見つからなかったか

### 5.1 実際にかけた検索

英語の検索語として次を試した。geometric progression resonator array logarithmically spaced resonant frequencies identification tag、Lamello passive acoustic sensing 3D printed tine comb frequency、Acoustic Voxels 3D printed acoustic filters tagging、artificial basilar membrane cantilever beam array exponentially varying length、chipless RFID logarithmically spaced resonant frequencies bit encoding、frequency spacing chipless RFID tag design tradeoff detection error constant fractional bandwidth、musical scale notes as data encoding vocabulary acoustic communication、data over sound semitone spacing frequency shift keying、graded metamaterial resonator array geometric progression rainbow trapping、passive resonator tag logarithmic geometric frequency spacing barcode identification、acoustic barcodes Harrison Xiao Hudson UIST 2012、Rayleigh wave resonance underwater acoustic barcode、3D printed passive object encoded identifier tuned resonant pitches musical scale、SoundOff passive ultrasound tags。

Crossref の書誌検索の機能（query.bibliographic）に対して、logarithmically spaced resonant frequencies identification tag と geometric progression resonator array encoding と artificial basilar membrane beam array exponentially varying resonance frequency の三つをかけた。いずれも語句の一致に引きずられた雑多な結果を返し、当たりは Broadband Transducer Composed of Three Elements with Proportionately Spaced Resonant Frequencies（JASA 1960）くらいであった。これは広帯域変換器の設計であって符号化ではない。

日本語では CiNii Research の検索に対して、「共鳴 等比 周波数 符号化」（0件）、「共鳴器アレイ 周波数 識別」（0件）、「音階 符号化 音響 情報埋め込み」（0件）、「共鳴管 識別」（0件）、「音階 符号化」（6件）、「1/12Nオクターブ分析」（1件）、「音楽性信号への符号化による携帯端末用音響通信」（1件）をかけた。当たりは第4節と第3節に挙げた2件である。

### 5.2 見つからなかったもの

次のものは、探した範囲では見つからなかった。

- **公比 2^(1/12) の等比数列で共鳴体を並べ、その音高を絶対値として推定して量子化し、多ビットのデータとして読み出す造形物**。Whoosh は等比で並べるが読み方が学習分類であり、Lamello は読み方が周波数照合だが並べ方が等差である。両方を兼ねた先行例は見つからなかった。
- **チップレスRFIDで周波数の割り当てを対数等間隔にすると明記した一次資料**。
- **人工基底膜の梁の長さを等比数列で与えると明記した一次資料**（二次的な要約にはその記述があったが、一次資料には到達できなかった）。
- **半音の間隔と全音の間隔をビット0とビット1に対応させるという記述**（検索結果の要約には現れたが、二つの特許の本文には見つけられなかった）。

### 5.3 読めなかった資料

- https://pubs.aip.org/... （AIP、403を返した。arXiv 版で代替した）
- https://dl.acm.org/... （ACM、403を返した。Crossref と著者公開版で代替した。FabAuth と SoundOff の本文は代替できなかった）
- https://link.springer.com/article/10.1007/s13391-014-4053-2 （認証画面に転送された）
- https://www.mdpi.com/1424-8220/15/8/18851 （403を返した）
- https://www.researchgate.net/... （403を返した）
- https://www.cs.columbia.edu/cg/lego/acoustic-voxels-siggraph-2016-slides-li-et-al.pdf （10メガバイトの上限を超えて取得できず、Acoustic Voxels の音響タグの周波数の置き方は確認できなかった）
- https://www.ee.columbia.edu/~dpwe/papers/Brown91-cqt.pdf （走査画像で文字が抽出できなかった）

---

## 6. この反例のもとで CipherFlute に残るもの

誇張も過小評価もせずに書く。

**放棄すべき主張**。「半音格子を符号の語彙とする発想は先行研究に存在しない」とは書けない。等比数列で共鳴管を並べること（Whoosh）、離散周波数の集合を字母として列で符号化すること（Lamello）、平均律の音階を記号の字母にすること（Google の特許、大石の修士論文）、対数等間隔の格子の細かさを設計変数にすること（中沢と山崎）は、いずれも先行例がある。また「semitone という語が0件だった」という語句照合の結果を新規性の根拠に使うことは、今後やめるべきである。語の不在は概念の不在ではない。

**それでも残る主張**。残るのは格子そのものではなく、格子の使い方の側にある。具体的には次の四つである。

第一に、**情報の向きである**。Whoosh の管長は論文に公開された定数であり、すべての複製が同一形状になることを意図している。情報は形状ではなく利用者の選択に載る。Lamello も同じで、歯の長さは部品の設計に固定されており、情報は利用者の操作に載る。CipherFlute はこれと逆で、格子上のどの位置に管を置くかが個体ごとに違い、その違いこそが運ぶべき値である。読み取り側は事前にその値を知らない。水中音響バーコードだけはこの向きが同じだが、そちらは対数格子を使っていない。

第二に、**読み方である**。Whoosh はメル周波数ケプストラム係数とサポートベクターマシンによる利用者ごとの学習分類であり、基本周波数を推定しない。したがって未知の管長を読むことができない。Lamello は基本周波数を照合するが、照合先は部品ごとに与えられる既知の周波数表であって、格子ではない。CipherFlute は絶対的な音高を推定して格子上に量子化するので、事前に知らない値を読める。

第三に、**格子の刻みを何から決めたかである**。Lamello は最適な周波数分布を今後の課題として明示的に残している。中沢と山崎は聴覚特性と符号量から刻みを決めており、造形の誤差や吹奏の揺らぎからではない。CipherFlute が刻みを実測の造形誤差と吹奏誤差から決めているのなら、その決め方は先行例と違う。ただしこれは「対数格子を設計変数にする」という発想そのものの新規性ではなく、「何を根拠に決めたか」の新規性であるから、論文では慎重に、決め方の具体を数字で示す形で書くべきである。

第四に、**符号列としての扱いである**。Lamello はドブラン列を使って字母数を減らしているが、誤り訂正は行っていない。多ビットの容量、符号語への連結、誤り訂正の付与という組み立ては、今回見た先行例のいずれにもない。

まとめると、CipherFlute が主張できるのは「半音格子を使うこと」ではなく、「半音格子を、未知の値を運ぶ担体の形状として使い、絶対音高の推定と量子化で読み、造形と吹奏の実測誤差から刻みを決め、誤り訂正を載せて多ビットの秘密として運ぶこと」の組み合わせである。個々の部品はいずれも先行例があるので、論文では組み合わせであることを明示し、部品ごとの先行例を正しく引くのがよい。とくに Whoosh は「半音比の等比数列で受動的な多管構造を作った先行例」として、Lamello は「離散周波数の集合を字母として列で符号化した先行例」として、明示的に引くべきである。

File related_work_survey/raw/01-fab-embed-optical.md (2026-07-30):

# 造形物への情報埋め込み（光学読み取り）

本稿は CipherFlute の関連研究調査のうち、「デジタルファブリケーションで作った物体の内部や表面に情報を埋め込み、撮像装置で読み出す」という切り口を担当したものである。読み出しの原理は光学に限定せず、赤外線、蛍光、熱、テラヘルツ、X線、電波、磁気、生体分子まで含めて洗い出した。書誌情報は原則としてdblp、Crossref、OpenAlex、arXiv、出版社ページ、著者・研究室の公式ページ、J-STAGE、CiNii Research、Europe PMC、PubMed、WISS予稿集ページのいずれかを直接取得して確認し、確認先のURLを各項目に記した。2026年7月30日に別の担当者が全項目を独立に再検証しており、その経緯は末尾の「検証の記録」に書いた。

## この切り口の要約

この分野は2013年の InfraStructs 以降、十年以上にわたって連続的に積み上げられており、CipherFlute が「日用品に符号を埋め込む」と主張する部分については、光学系の先行研究が圧倒的に厚い。到達点を数字で押さえると次のようになる。AirCode は2センチメートル角の埋め込みタグに約106ビット、5センチメートル角に約500ビットを収め、しかもリードソロモン符号で40パーセントの冗長度を与えている。InfraredTags は赤外線を透過するフィラメントと内部空隙で21×21のQRコードを物体内部に丸ごと隠し、外見はまったく変わらない。AnisoTag はクレジットカードと同じ寸法の面に51ビット、RGBカメラと画像処理を併用する構成なら160ビットを刻み、読み取り装置は10ドル程度で作れる。上平員丈らの一連の研究は、数センチメートルの造形物の内部に空洞や近赤外蛍光染料や強磁性セルを作り込み、X線、サーモグラフィ、近赤外線で数百ビットを非破壊で読み出す方法を2015年から継続的に発表している。したがって「消費者向けFDMプリンタで日用品に情報を仕込み、電子部品も電源も使わずに読み出す」という枠組み自体は、まったく新しくない。

一方で、この分野の全論文に共通する空白がはっきり見えた。第一に、脅威モデルを明示した研究がほぼ皆無である。AirCode、InfraredTags、LayerCode、G-ID、AnisoTag のいずれも、攻撃者が誰で、何を守り、何を守らないのかを書いていない。唯一の例外は2024年の Secure Information Embedding in Forensic 3D Fingerprinting で、これは破断と隠匿を行う敵を明示して符号理論で対処している。第二に、読み出しに所有者の身体的な行為を要する設計が存在しない。光学系はすべて、物体を撮像装置の前に置きさえすれば所有者の関与なく読める。第三に、秘密分散や暗号資産のリカバリーシードの保管を目的として設計された造形タグは見つからなかった。第四に、基準素子を同一物体に混ぜて環境変動を正規化する設計も、隣接シンボルの同値禁止のような遷移保証も、造形タグの文脈では見当たらなかった。CipherFlute の新規性は、埋め込みという行為そのものではなく、この四点に置くのが正確である。

## 新規性への脅威が大きい文献

### 1. InfraredTags: Embedding Invisible AR Markers and Barcodes Using Low-Cost, Infrared-Based 3D Printing and Imaging Tools

- 著者: Mustafa Doga Dogan, Ahmad Taka, Michael Lu, Yunyi Zhu, Akshat Kumar, Aakar Gupta, Stefanie Mueller
- 発表: CHI 2022, pages 269:1-269:12, DOI 10.1145/3491102.3501951
- 確認先: https://dblp.org/search/publ/api?q=InfraredTags&format=json （書誌）、https://ar5iv.labs.arxiv.org/html/2202.06165 （本文）

赤外線を透過する市販フィラメントで物体本体を印刷し、内部に空隙を作ることでタグのビットを表現する。可視光では完全に不透明な普通の物体に見えるが、近赤外線カメラで撮ると内部の空隙が輝度差として現れ、QRコードやArUcoマーカーが読める。本文で用いているのは21×21のQRコード（数字なら25文字まで）と4×4のArUcoマーカーである。読み取り装置は Raspberry Pi NoIR カメラ、940ナノメートルの赤外線LEDを2個、可視光カットフィルタ、Raspberry Pi Zero を組み合わせた132グラムのモジュールで、TPUのケースでスマートフォンに取り付ける（ケースは柔らかいTPUで刷り、撮像モジュール本体は硬いPLAで刷って差し込む）。照明については、多材料で印刷した符号なら0.2ルクス、単一材料で印刷した符号なら1.1ルクスの微弱な赤外照明で検出でき、250センチメートル離れても読める。

CipherFlute との関係は正面衝突である。消費者向けFDMプリンタで、追加の電子部品も電源も使わず、日用品の外見をまったく損なわずに機械可読な情報を埋め込むという枠組みが完全に一致する。しかも情報量は笛40本から49本ぶんの128ビットを大きく上回り、体積あたりの密度も比較にならない。差分として主張できるのは、赤外線を透過する特殊なフィラメントを必要としない点、追加の撮像モジュールを必要としない点、読み出しが所有者の身体的な行為（吹くこと）と結びついている点の三つに限られる。

脅威の度合いは高である。「日用品に隠して埋め込み、消費者向け機材で読む」という主張のうち、隠蔽性と容量の両面で CipherFlute より優れた手段がすでに存在するため、論文はこの研究との差分を数字で書かないと立たない。

### 2. 上平員丈・鈴木雅洋らによる造形物内部への情報埋め込みの一連の研究

代表的な文献を五つ挙げる。いずれも書誌情報を一次資料で確認した。

- Masahiro Suzuki, Pailin Dechrueng, Soravit Techavichian, Piyarat Silapasuphakornwong, Hideyuki Torii, Kazutake Uehira, "Embedding Information into Objects Fabricated With 3-D Printers by Forming Fine Cavities inside Them", IS&T International Symposium on Electronic Imaging: Media Watermarking, Security, and Forensics, vol. 29, no. 7, pp. 6-9, 2017, DOI 10.2352/ISSN.2470-1173.2017.7.MWSF-317
  確認先: https://library.imaging.org/ei/articles/29/7/art00002 （出版社の論文ページで題名・著者6名・巻号・頁・抄録を確認した）
- Kazutake Uehira, Masahiro Suzuki, Piyarat Silapasuphakornwong, Hideyuki Torii, Youichi Takashima, "Copyright Protection for 3D Printing by Embedding Information Inside 3D-Printed Objects", International Workshop on Digital Watermarking (IWDW) 2016, Lecture Notes in Computer Science, vol. 10082, pp. 370-378, Springer, 2017, DOI 10.1007/978-3-319-53465-7_27
  確認先: https://link.springer.com/chapter/10.1007/978-3-319-53465-7_27 （出版社ページでLNCSの巻号10082と頁370-378を確認した）
- Hideo Kasuga, Piyarat Silapasuphakornwong, Hideyuki Torii, Masahiro Suzuki, Kazutake Uehira, "Technique to Embed Information in 3D Printed Objects Using Near Infrared Fluorescent Dye", IIEEJ Transactions on Image Electronics and Visual Computing, vol. 8, no. 1, pp. 2-9, 2020, DOI 10.11371/tievciieej.8.1_2
  確認先: https://www.jstage.jst.go.jp/article/tievciieej/8/1/8_2/_article （J-STAGEで題名・著者5名・巻号・頁・抄録を確認した）
- Piyarat Silapasuphakornwong, Hideyuki Torii, Kazutake Uehira, Apisara Funsian, Kewalee Asawapithulsert, Tattawat Sermpong, "Embedding Information in 3D Printed Objects Using Double Layered near Infrared Fluorescent Dye", International Journal of Materials, Mechanics and Manufacturing, vol. 7, no. 6, pp. 230-234, 2019, DOI 10.18178/ijmmm.2019.7.6.465
  確認先: https://api.crossref.org/works/10.18178/ijmmm.2019.7.6.465 （Crossrefに出版社が登録した書誌で著者6名・巻号・頁・年を確認した。上のIIEEJ論文と同じ二層構成の手法を扱っている）
- Masahiro Suzuki, Piyarat Silapasuphakornwong, Youichi Takashima, Hideyuki Torii, Kazutake Uehira, "Number of Detectable Gradations in X-Ray Photographs of Cavities Inside 3-D Printed Objects", IEICE Transactions on Information and Systems, vol. E100.D, no. 6, pp. 1364-1367, 2017, DOI 10.1587/transinf.2016EDL8213
  確認先: https://api.crossref.org/works/10.1587/transinf.2016EDL8213 （Crossrefで題名・著者5名・巻号・頁を確認した。内部空洞をX線で読むときに識別できる階調数を扱った短報である）

この研究群は、造形中に物体内部へ微小な空洞、高反射率の突起、近赤外蛍光染料の層、金属混入樹脂、強磁性フィラメントのセルなどを作り込み、X線撮影、サーモグラフィ、近赤外線の透過像や反射像、磁力計で非破壊に読み出す。Electronic Imaging 2017の論文は抄録で、数センチメートルの大きさの造形物であれば著作権情報として十分な量、すなわち数百ビットを埋め込めると明記している。IIEEJ論文では蛍光染料の層を二つの深さに作り分けて4状態を作り、深層学習で判別することで情報量を倍にしている。2021年の IS&T Printing for Fabrication（NIP37）では強磁性セルを再着磁して書き換え可能にした（Piyarat Silapasuphakornwong, Hideyuki Torii, Masahiro Suzuki, Kazutake Uehira, "Effects of Embedded Depth of Internal Printed Ferromagnetic Cell on Data Clarity of Rewritable 3D Objects", NIP & Digital Fabrication Conference, vol. 37, pp. 28-31, 2021, DOI 10.2352/ISSN.2169-4451.2021.37.28、確認先 https://library.imaging.org/admin/apis/public/api/ist/website/downloadArticle/print4fab/37/1/art00004_1 で本文PDFの取得を確認し、巻号と頁は https://api.crossref.org/works/10.2352/ISSN.2169-4451.2021.37.28 で確認した）。金属混入樹脂とサーモグラフィの組み合わせは Piyarat Silapasuphakornwong, Chaiwuth Sithiwichankit, Kazutake Uehira, "Information Embedding in 3D Printed Objects Using Metal-Infused PLA and Reading with Thermography", NIP & Digital Fabrication Conference, vol. 34, pp. 202-207, 2018, DOI 10.2352/issn.2169-4451.2018.34.202 にある（確認先 https://api.crossref.org/works/10.2352/issn.2169-4451.2018.34.202 ）。この系列の起点が2015年であることは Masahiro Suzuki, Piyarat Silapasuphakornwong, Kazutake Uehira, Hiroshi Unno, Youichi Takashima, "Copyright Protection for 3D Printing by Embedding Information Inside Real Fabricated Objects", VISAPP 2015, pp. 180-185, DOI 10.5220/0005342401800185 で確認した（確認先 https://dblp.org/rec/conf/visapp/SuzukiSUUT15 ）。日本語の技術報告も多数あり、中村耕介・鈴木雅洋・高嶋洋一・鳥井秀幸・上平員丈「内壁の構造化による3Dプリンター造形物への情報埋め込み技術」電子情報通信学会技術研究報告、第116巻第132号、19頁、2016年7月が確認できる（確認先 https://cir.nii.ac.jp/crid/1520009407351160576 で著者5名・誌名・巻号・頁・年月を確認した）。

CipherFlute との関係は、内部構造で情報を担わせるという発想の直接の先行研究にあたる。CipherFlute の笛は内部の空洞（管）の長さで符号を表すが、これは「内部に空洞を作って情報を表す」という上平らの枠組みの一変種と読める。読み出しの物理が撮像ではなく共鳴音である点だけが異なる。

脅威の度合いは高である。造形物内部の空洞に数百ビットを入れて非破壊で読むという主張が2015年からすでに確立しており、しかも著作権保護という安全性寄りの動機まで持っている。CipherFlute はこの研究群を引用したうえで、「読み出しに専用撮像装置ではなく人間の息とマイクを使う」ことがなぜ意味を持つのかを説明しなければならない。

### 3. AnisoTag: 3D Printed Tag on 2D Surface via Reflection Anisotropy

- 著者: Zehua Ma, Hang Zhou, Weiming Zhang
- 発表: CHI 2023, pages 420:1-420:15, DOI 10.1145/3544548.3581024
- 確認先: https://api.crossref.org/works/10.1145/3544548.3581024 （出版社が登録した書誌）、https://dblp.org/search/publ/api?q=AnisoTag&format=json （論文番号420。dblpの検索APIは混雑時にHTTP 500を返すことがある）、https://ar5iv.labs.arxiv.org/html/2301.10599 （本文の数値）

3Dプリンタが作る表面微細構造の異方性反射を使い、平滑な円筒状の微細くぼみの角度で情報を符号化する。コリメートしたレーザーを当てると、くぼみの角度に応じて異なる照明パターンが反射する。既定の構成では53.98ミリメートル×85.6ミリメートル、つまりクレジットカードと同じ面に水平方向17区画×3ビットで51ビットを収める。RGBカメラと画像処理を併用する構成では160ビットまで伸びる（本文6.2節）。読み取り装置は3ドルのクラスIIIAレーザーポインタ、半径1.5センチメートルの円周上に並べた16個のフォトレジスタ、7ドルのSTM32F103マイクロコントローラで構成され、カメラを必要としない。

CipherFlute との関係は、カード型実装との形状の一致が痛い。CipherFlute はクレジットカード大のカードに笛を並べる実装を持つが、同じ面積に AnisoTag は51ビットから160ビットを、外見をほとんど変えずに、10ドル程度の装置で読める形で刻む。CipherFlute のカード1枚あたりのビット数と直接比較される。

脅威の度合いは中である。CipherFlute の主要な主張を壊しはしないが、カード型の実装を「情報を運ぶ媒体」として提示するときには必ず比較対象になる。差分は、AnisoTag が専用の読み取り治具を要するのに対し CipherFlute は口とマイクだけで済む点、および AnisoTag が表面のみで内部を使わない点である。

### 4. BrightMarker: 3D Printed Fluorescent Markers for Object Tracking

- 著者: Mustafa Doga Dogan, Raul Garcia-Martin, Patrick William Haertel, Jamison John O'Keefe, Ahmad Taka, Akarsh Aurora, Raul Sanchez-Reillo, Stefanie Mueller
- 発表: UIST 2023, pages 55:1-55:13, DOI 10.1145/3586183.3606758
- 確認先: https://api.crossref.org/works/10.1145/3586183.3606758 （出版社が登録した書誌）、https://dblp.org/search/publ/api?q=BrightMarker&format=json （論文番号55。dblpの検索APIは混雑時にHTTP 500を返すことがある）、https://hcie.csail.mit.edu/research/brightmarker/brightmarker.html （著者順と本文の数値）

赤外蛍光フィラメントを使い、入射光の波長をずらして返す性質でマーカーを物体内部に埋め込む。赤外カメラ側で長波長透過フィルタによりマーカー以外の要素を落とすため、物体表面の色にかかわらず高いコントラストで追跡できる。1インチ角の小さなマーカーでも2メートル以上離れて追跡でき、既存の不可視マーキング手法を検出率で上回ると主張している（プロジェクトページ本文に「even small markers (1"x1") can be tracked at distances exceeding 2m」とある。速度実験では InfraredTags の平均検出率60.73パーセントに対して BrightMarker が上回ったと報告している）。既存の携帯端末やAR・VRヘッドセットに取り付けるハードウェアモジュールを作っている。

CipherFlute との関係は、InfraredTags の後継として「日用品に見えない印を埋める」路線の最新到達点にあたる。CipherFlute が「見えない情報を日用品に入れる」ことの価値を論じるとき、この系列の到達点を無視できない。

脅威の度合いは中である。主眼が追跡であって少量の秘密情報の保管ではないため主張は直接ぶつからないが、隠蔽性の水準を示す基準として必ず引用して差分を述べる必要がある。

### 5. 3D printing wireless connected objects

- 著者: Vikram Iyer, Justin Chan, Shyamnath Gollakota
- 発表: ACM Transactions on Graphics, vol. 36, no. 6, pages 242:1-242:13, 2017（SIGGRAPH Asia 2017）, DOI 10.1145/3130800.3130822
- 確認先: https://api.crossref.org/works/10.1145/3130800.3130822 （出版社が登録した書誌。第36巻第6号）、https://dblp.org/search/publ/api?q=wireless+connected+objects+Gollakota&format=json （論文番号242。dblpの検索APIは混雑時にHTTP 503を返すことがある）、https://printedwifi.cs.washington.edu/ （手法の記述。プロジェクトページは第三著者を Shyam Gollakota と略記しているが、出版社の書誌は Shyamnath Gollakota である）

電池も電子部品も使わず、市販の3Dプリンタと市販のフィラメントだけで無線通信するオブジェクトを作る研究である。バックスキャッタでWi-Fi受信機に直接データを送る機構に加えて、鉄粉入りフィラメントを使って磁界の形で物体内部にデータを埋め込み、市販スマートフォンの磁力計で復号する仕組みを含んでいる。眼鏡フレームや腕輪に磁気データを埋めた例が示されている。後続の Wireless Analytics for 3D Printed Objects（Vikram Iyer, Justin Chan, Ian Culhane, Jennifer Mankoff, Shyam Gollakota, UIST 2018、確認先 https://printedanalytics.cs.washington.edu/ ）では、ラチェットと歯車で通信圏外の事象を記録して後から読み出す機構まで作っている。

CipherFlute との関係は、「電子部品も電源も持たない印刷物体に情報を仕込み、追加装置なしの市販スマートフォンで読み出す」という主張が完全に一致する点にある。CipherFlute はマイクを使い、この研究は磁力計を使うという違いしかない。しかも磁気の読み出しは所有者の身体的な行為を必要としない。

脅威の度合いは中である。CipherFlute の「電源不要・電子部品不要・市販端末で読める」という主張は、この研究が2017年にすでに達成している。差分として言えるのは、特殊な鉄粉入りフィラメントを必要としない点と、埋め込んだ笛が物体の意匠に溶け込む点である。

### 6. InfoPrint: Embedding Interactive Information in 3D Prints Using Low-Cost Readily-Available Printers and Materials

- 著者: Weiwei Jiang, Chaofan Wang, Zhanna Sarsenbayeva, Andrew Irlitti, Jing Wei, Jarrod Knibbe, Tilman Dingler, Jorge Goncalves, Vassilis Kostakos
- 発表: Proceedings of the ACM on Interactive, Mobile, Wearable and Ubiquitous Technologies (IMWUT), vol. 7, no. 3, pages 102:1-102:29, 2023, DOI 10.1145/3610933
- 確認先: https://dblp.org/search/publ/api?q=InfoPrint+Embedding+Interactive+Information&format=json （書誌と論文番号102）、抄録は https://api.openalex.org/works/doi:10.1145/3610933 で確認した

安価な市販のデュアルエクストルーダFDMプリンタと一般的なPLAだけを使い、材料の熱特性の違いで情報を物体内部に埋め込む。物体に触れて温度を移したあと、サーマルカメラ付きスマートフォンで撮ると隠された情報が現れる。近赤外撮像への一般化も示している。物体に触るという人間の行為が読み出しの引き金になる点が特徴である。

CipherFlute との関係は、「人間の行為（触る）を経て初めて情報が現れる」という設計思想が、CipherFlute の「吹く」に最も近い先行例である点にある。ただし触れるだけで読めるので、所有者でなくても読める。

脅威の度合いは中である。特殊材料を使わず市販の一般材料だけで日用品に情報を隠す点、および人間の行為を読み出しに組み込む点の二つで先行しているため、CipherFlute の「材料を選ばない」「行為が読み出しの一部」という論点は差分を丁寧に書く必要がある。

### 7. 内部構造パターンの差異を利用した3Dプリントオブジェクト識別手法

- 著者: 久保勇貴、江口佳那、青木良輔、近藤重邦、東正造、犬童拓也（日本電信電話株式会社）
- 発表: WISS 2019（インタラクティブシステムとソフトウェアに関するワークショップ）、口頭発表8
- 確認先: https://www.wiss.org/WISS2019Proceedings/ （題名と著者6名、所属がNTTであること）、本文PDF https://www.wiss.org/WISS2019Proceedings/oral/8.pdf 、査読コメント https://www.wiss.org/WISS2019Proceedings/oral/8.html

提案手法には FabAuth という名前が付いている。スライサの標準機能である内部充填パターンの設定を変えることで、外見が同一の3Dプリント造形物に固有の振動特性を割り当て、その違いから識別する。読み出しはアクティブ音響センシングによる音響周波数応答の解析であり、加振と受振にピエゾ素子を使い、機械学習で判別する。予稿の概要は「平均識別精度99.3%にて8つのオブジェクトを識別できることを確認した」と述べている。査読コメントでは、実用的な用途が不明である点、ピエゾ素子の設置位置の許容範囲が狭い点、識別できる個体数の増加に対する拡張性が不明である点が指摘されている。さらに、権利保護のためにタグを付けたいという動機と、誰でも同じ設定で複製できる充填パターンをタグに使うことのあいだに矛盾があるのではないかという指摘もある。

CipherFlute との関係は二重に危険である。第一に、投稿先である WISS に「3Dプリント造形物の内部構造に情報を持たせ、振動という力学的・音響的な現象で読み出す」という論文がすでに存在する。第二に、著者らが日本の同一コミュニティに属するため、査読者が想起する可能性が高い。ただし識別できるのは少数のクラスであって、ビット列の格納ではない。

脅威の度合いは中である。CipherFlute のビット容量と誤り訂正、日用品への偽装という論点は残るが、「内部構造に情報を持たせて非光学的に読む」という着想の先行例として必ず引用し、識別と情報格納の違いを明確に述べる必要がある。

### 8. Secure Information Embedding in Forensic 3D Fingerprinting

- 著者: Canran Wang, Jinwen Wang, Mi Zhou, Vinh Pham, Senyue Hao, Chao Zhou, Ning Zhang, Netanel Raviv
- 発表: arXiv preprint arXiv:2403.04918, 2024年3月7日投稿（第5版が2025年2月3日）
- 確認先: https://arxiv.org/abs/2403.04918 （題名・著者8名・投稿日と改訂日・抄録を確認した。査読付き会議や雑誌に採録された記録は見つからず、現時点ではプレプリントである）

提案手法には SIDE（Secure Information Embedding and Extraction）という名前が付いている。3Dプリント造形物に法科学的な指紋情報を埋め込む枠組みで、敵が造形物を破断して一部の断片を隠すという明示的な脅威モデルを置き、断片化と欠損に耐える符号理論的な埋め込みを設計している。さらに埋め込み処理そのものを Trusted Execution Environment で保護する。動機は、消費者向け3Dプリンタによる追跡不能な偽造品や銃器の製造を防ぐことにある。

CipherFlute との関係は、造形物への情報埋め込みに明示的な攻撃者モデルと符号理論を持ち込んだ数少ない例である点にある。CipherFlute が「この分野で脅威モデルを明示したのは我々が初めてである」と書くと、この研究に反証される。

脅威の度合いは中である。目的が正反対（こちらは所有者に無断で追跡するための埋め込み、CipherFlute は所有者のための秘密保管）なので主張は衝突しないが、「脅威モデルの明示」という新規性の言い方は必ず調整が必要である。

### 9. すでに把握している六件についての追加の数値

論文が既に挙げている六件についても、差分を数字で書くために必要な情報を一次資料から取り直した。

- InfraStructs（Karl D. D. Willis, Andrew D. Wilson, ACM Transactions on Graphics, vol. 32, no. 4, pp. 138:1-138:10, 2013, DOI 10.1145/2461912.2461936、確認先 https://www.microsoft.com/en-us/research/publication/infrastructs-fabricating-information-inside-physical-objects-imaging-terahertz-region/ および本文PDF https://www.microsoft.com/en-us/research/wp-content/uploads/2016/10/WillisSiggraph2013.pdf ）。単純な一次元タグで8ビット、行列型タグで27ビットを実証している。行列型タグは3×3×3の立体格子であり、レーザーカットしたポリスチレンの層を3Dプリントしたケースに収めて作っている。読み出しには Picometrix T-Ray 4000 というテラヘルツ時間領域分光装置が要り、走査速度が毎秒約100画素なので100×100画素の走査に約2分かかる。リードソロモン符号は将来課題として言及されるにとどまる。認証や偽造防止に触れるが、攻撃者モデルは書いていない。
- AirCode（Dingzeyu Li, Avinash S. Nair, Shree K. Nayar, Changxi Zheng, UIST 2017, pp. 449-460, DOI 10.1145/3126594.3126635、確認先 https://arxiv.org/abs/1707.05754 および本文PDF https://www.cs.columbia.edu/cg/aircode/aircode-uist-2017-li-et-al.pdf ）。2センチメートル角で約106ビット、5センチメートル角で500ビット超。読み出しにはプロジェクタとカメラ、偏光板を使った直接成分と大域成分の分離が必要で、撮像に3分から4分かかる。重要なのは、リードソロモン符号で40パーセントの冗長度を与えている点である。つまり「造形タグにリードソロモン符号を使う」こと自体はすでに先行例がある。安全性や攻撃者の議論はない。
- LayerCode（Henrique Teles Maia, Dingzeyu Li, Yuan Yang, Changxi Zheng, ACM Transactions on Graphics, vol. 38, no. 4, pp. 112:1-112:14, 2019, DOI 10.1145/3306346.3322960、確認先 https://dblp.org/search/publ/api?q=LayerCode&format=json および本文PDF https://www.cs.columbia.edu/cg/layercode/LayerCode_Maia_et_al_2019_lowRez.pdf ）。24ビットの符号を用い、近赤外の変種では12ビットである。読み出しは普通のカメラで、近赤外の変種でも近赤外フィルタと光源（テレビのリモコンで足りる）を足すだけでよい。二つの連続する層の厚さの比で1を表し、比が1のときに0を表すという設計で、印刷方向や曲率に対して不変になっている。誤り訂正は「任意の符号を載せられるが本実験では純粋な性能を見るためあえて付けない」と明記している。
- G-ID（Mustafa Doga Dogan, Faraz Faruqi, Andrew Day Churchill, Kenneth Friedman, Leon Cheng, Sriram Subramanian, Stefanie Mueller, CHI 2020, pp. 1-13, DOI 10.1145/3313831.3376202、確認先 https://dblp.org/search/publ/api?q=G-ID+Identifying+3D+Prints&format=json および本文PDF https://groups.csail.mit.edu/hcie/files/research-projects/G-ID/2020-CHI-GID-paper.pdf ）。カメラのみで204通り、光源を併用して17,136通り、すなわち約7.7ビットから約14ビットに相当する。読み取りは市販スマートフォンのカメラだけで足り、内部の充填を見る場合にのみ小型懐中電灯（Nitecore Tini）を造形物の側面に当てる。偽造対策の応用例には触れるが、攻撃者モデルはない。
- StructCode（Mustafa Doga Dogan, Vivian Hsinyueh Chan, Richard Qi, Grace Tang, Thijs Roumen, Stefanie Mueller, SCF 2023, pp. 6:1-6:13, DOI 10.1145/3623263.3623353、確認先 https://api.crossref.org/works/10.1145/3623263.3623353 およびプロジェクトページ https://hcie.csail.mit.edu/research/structcode/structcode.html ）。レーザーカットの指型継手で3値符号により約12文字、リビングヒンジで最大21文字を格納する。読み出しは携帯端末やヘッドセットのRGBカメラで足りる（この点は同じ著者の博士論文 arXiv:2407.11748 に「StructCode only requires a conventional RGB camera for detection, and thus can be used on off-the-shelf mobile devices and headsets」とある）。プロジェクトページには「最も機微なタグでは符号とラベルの対応を暗号化してその利用者だけが持てばよい」という一文があり、秘匿を暗号に負わせる発想が既に述べられている点は注意を要する。
- Seedmarkers（Christopher Getschmann, Florian Echtler, TEI 2021, pp. 26:1-26:11, DOI 10.1145/3430524.3440645、確認先 https://dblp.org/search/publ/api?q=Seedmarkers&format=json ）。重み付きボロノイ図で位相的な最適化を行い、任意形状の面に埋め込める形状非依存の位相マーカーを生成する。読み出しは普通のカメラで、3自由度または6自由度の追跡に対応する。
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

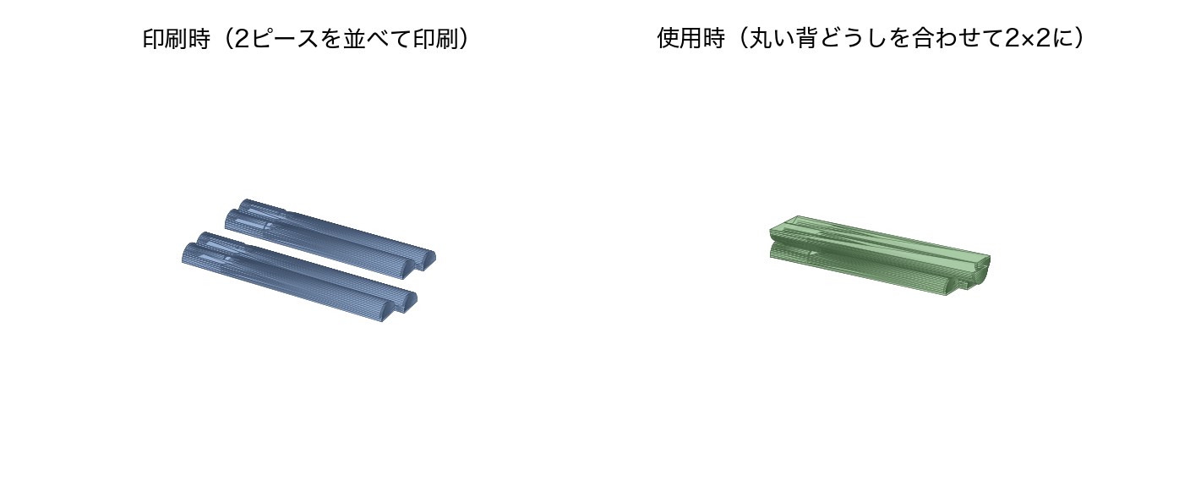
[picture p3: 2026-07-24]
paper/figs/fig5_pairs.png

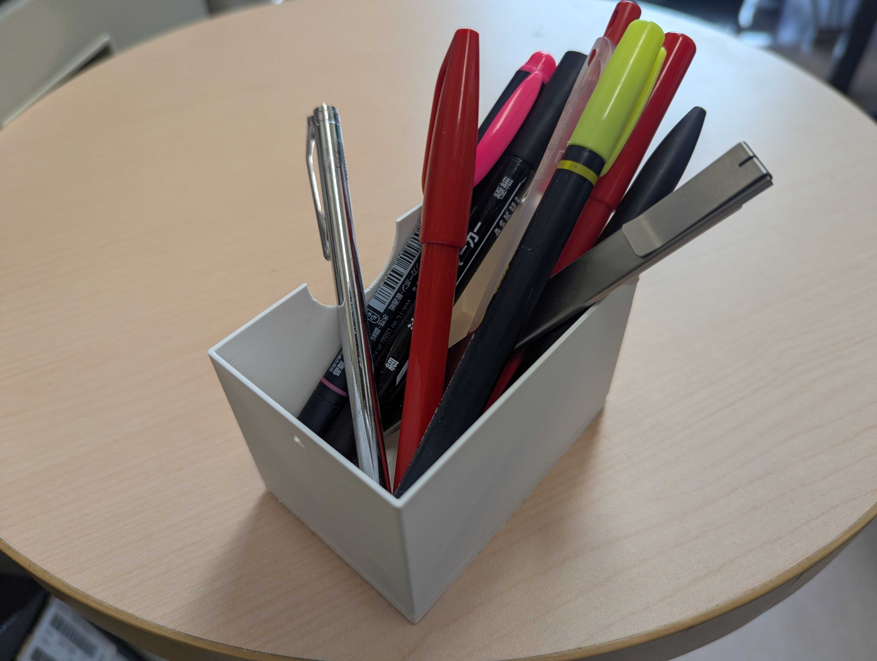
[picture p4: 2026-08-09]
paper/figs/2of3_box_with_pens.jpg

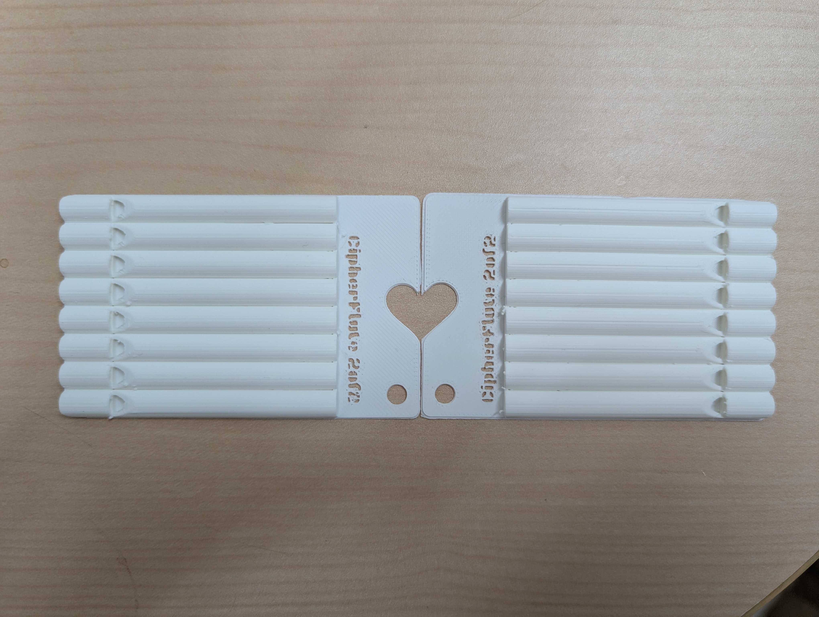
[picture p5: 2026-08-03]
paper/figs/pair_cards.jpg

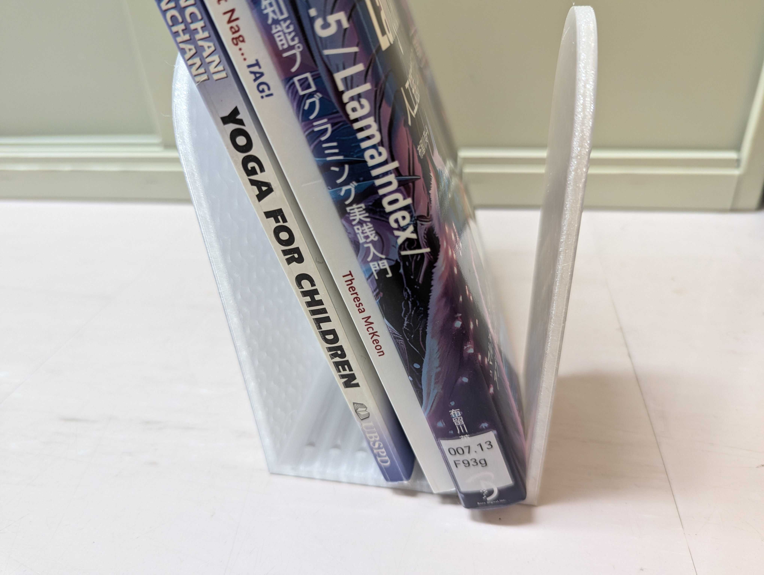
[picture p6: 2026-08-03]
paper/figs/2of3_bookstand2.jpg

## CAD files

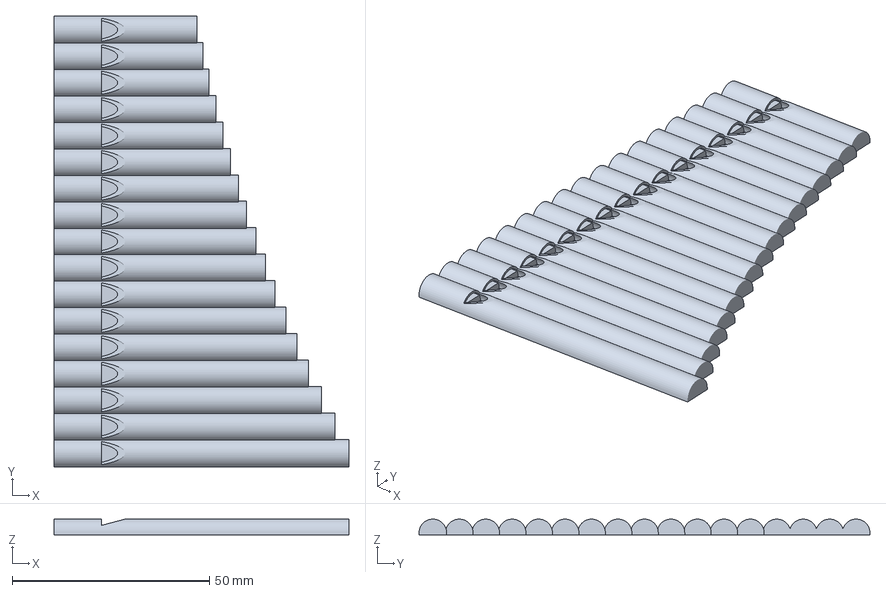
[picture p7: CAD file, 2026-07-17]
out/halfcut_scale_fullrange.swap.3mf
74.7 x 114.2 x 4.00 mm

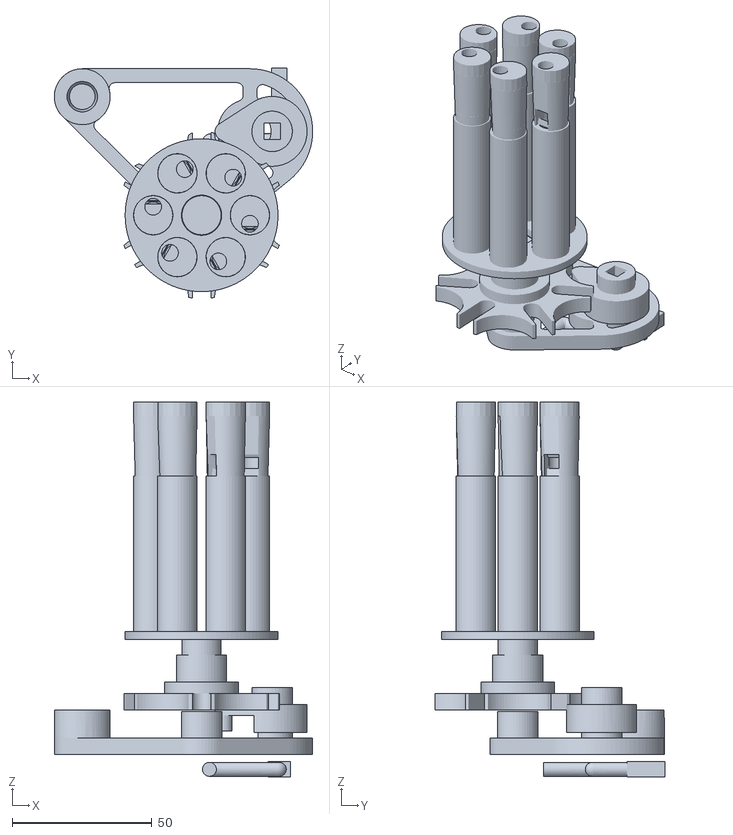
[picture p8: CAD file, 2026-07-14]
out/revolver_asm_v1.stl
92.4 x 82.3 x 134.1

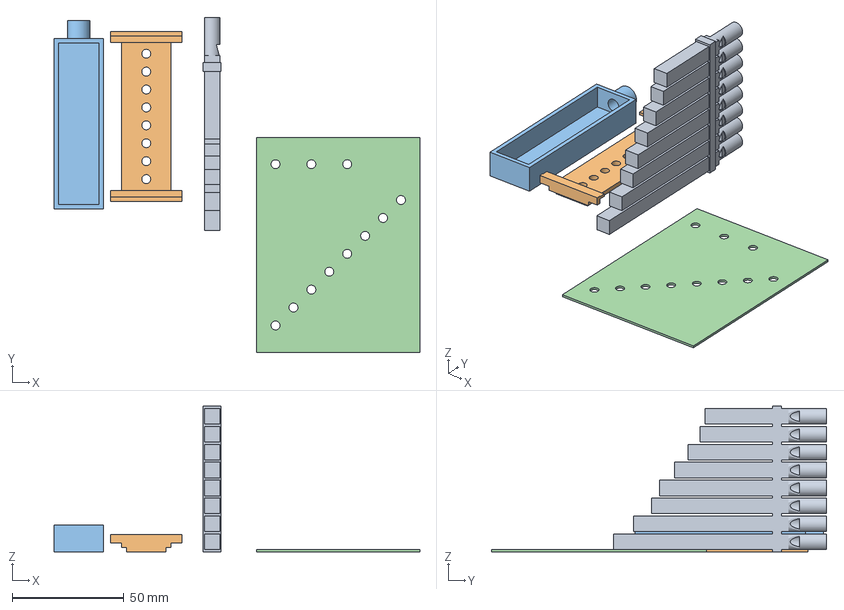
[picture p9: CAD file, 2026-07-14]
out/organ_full_set_4obj.3mf
163.4 x 149.4 x 65.0 mm
panflute
reader_lid
reader_base
sheet

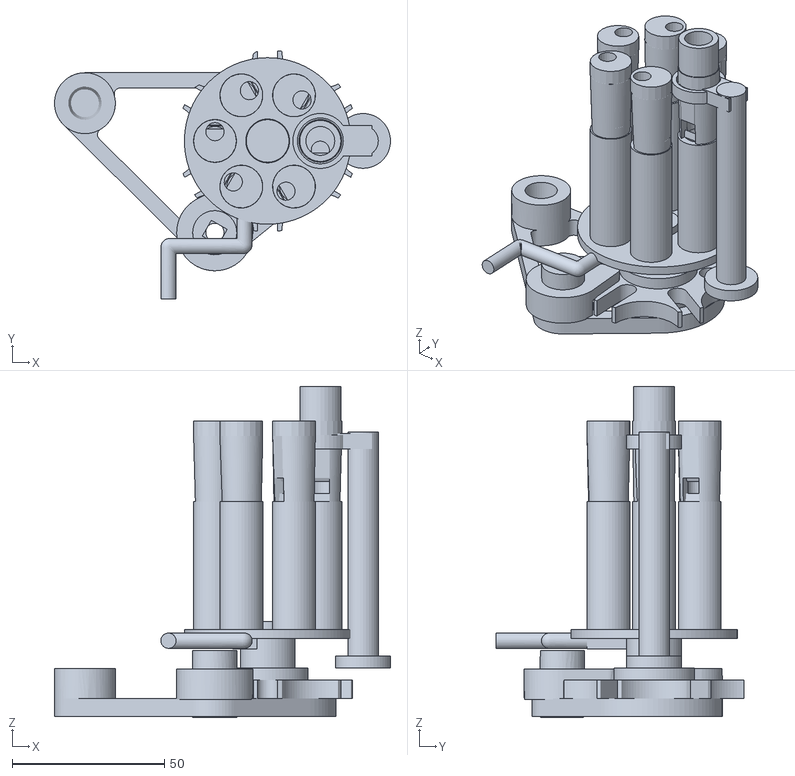
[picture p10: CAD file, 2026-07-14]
out/revolver_assembled_current.stl
110.3 x 81.6 x 108.8

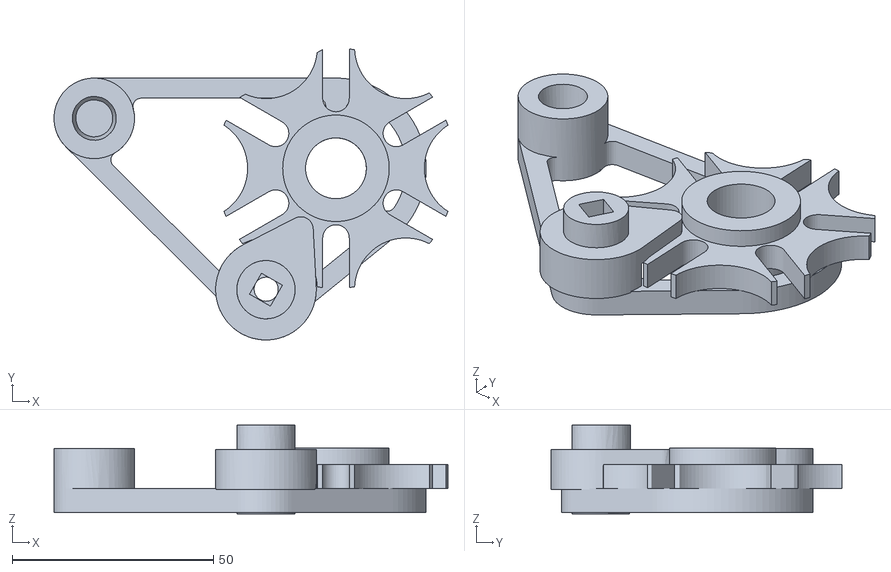
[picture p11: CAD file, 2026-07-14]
out/geneva_ref_asm_v4.stl
97.8 x 72.3 x 22.0

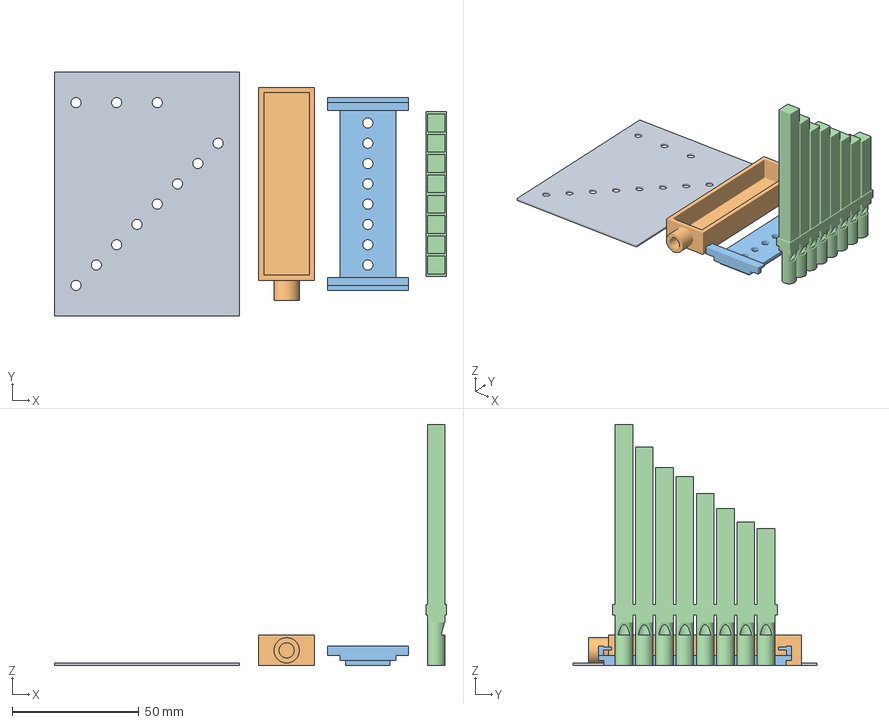
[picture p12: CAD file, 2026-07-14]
out/organ_full_set_objects.3mf
154.5 x 96.0 x 95.0 mm
sheet
reader_base
reader_lid
panflute

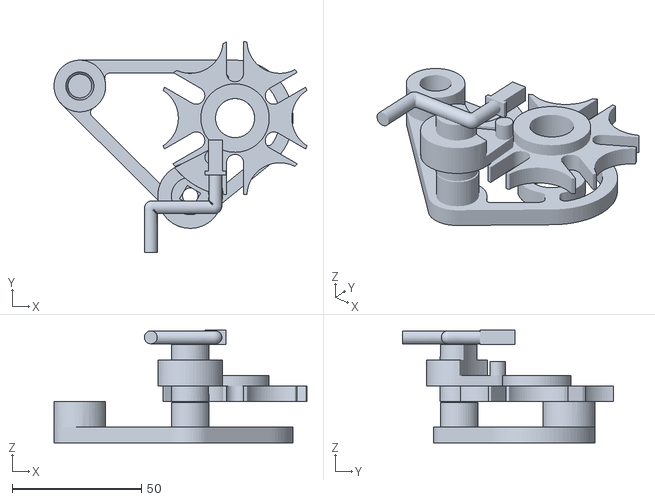
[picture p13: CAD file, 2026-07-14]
out/geneva_ref_assembled.stl
97.8 x 81.6 x 43.5

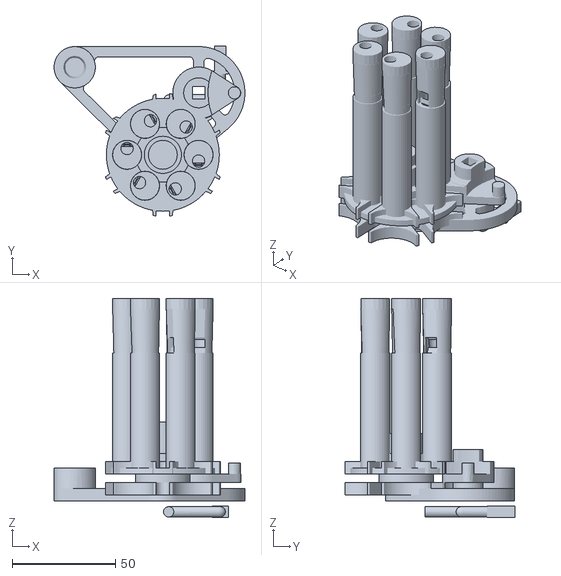
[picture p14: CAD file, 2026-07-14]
out/revolver_assembled_SWAP.stl
92.4 x 82.3 x 106.0

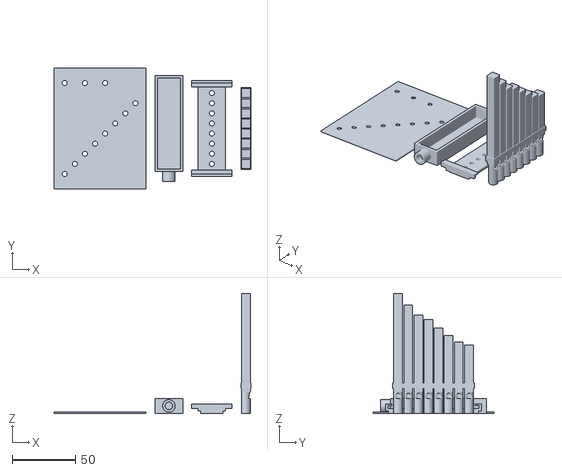
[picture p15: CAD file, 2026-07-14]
out/organ_full_set_plate.stl
156.0 x 96.0 x 95.0

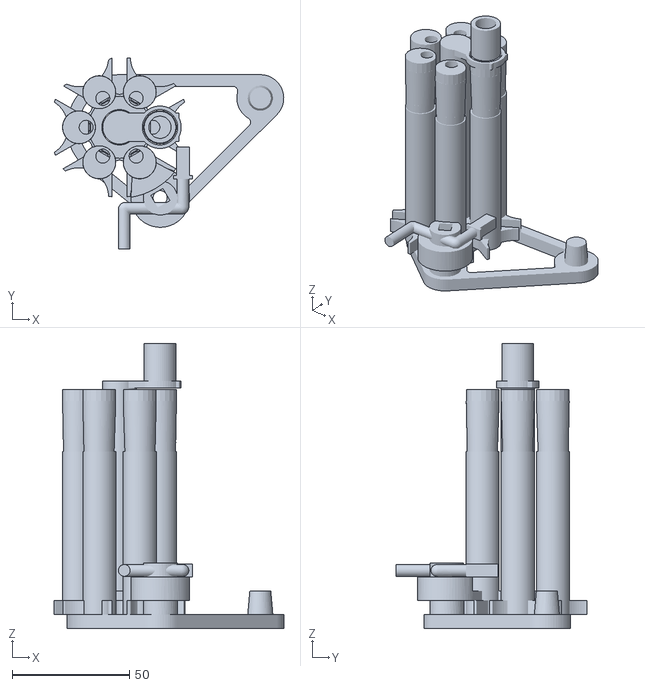
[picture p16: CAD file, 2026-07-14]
out/revolver_geneva_assembled.stl
97.8 x 81.6 x 121.4

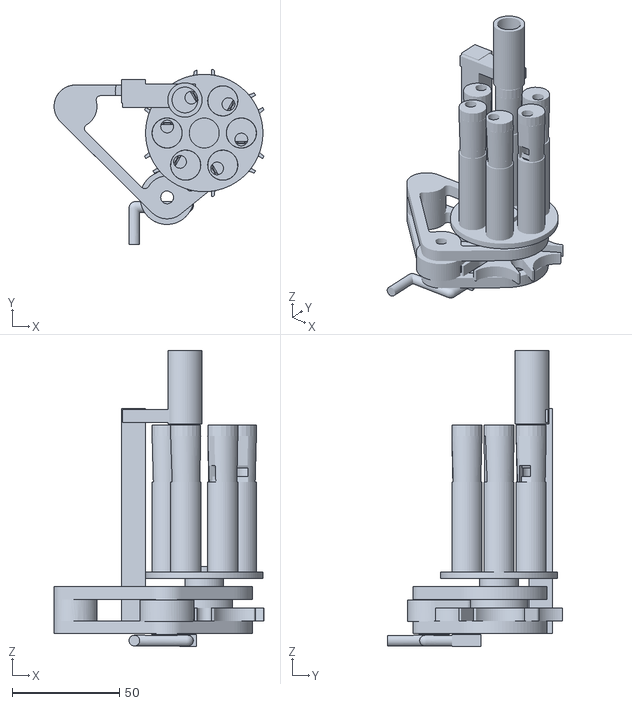
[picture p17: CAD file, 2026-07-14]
out/revolver_assembled_v6.stl
97.8 x 81.6 x 138.0

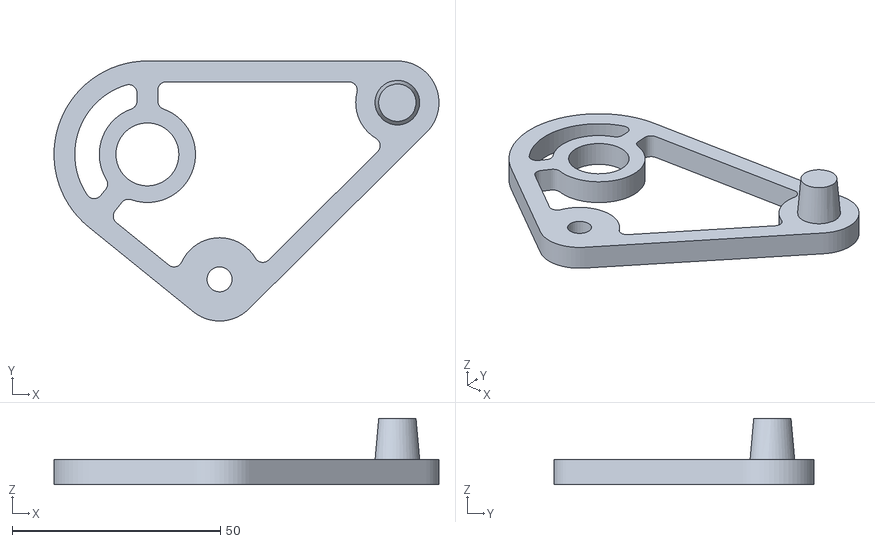
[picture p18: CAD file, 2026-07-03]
assets/geneva_ref/ref_frameA.stl
92.4 x 62.4 x 15.9

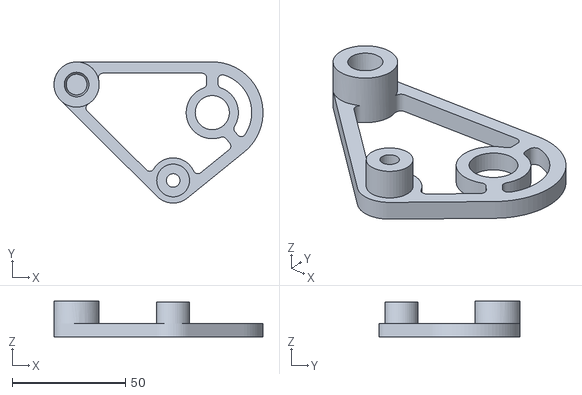
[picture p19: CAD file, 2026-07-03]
assets/geneva_ref_split/part0.stl
92.4 x 62.4 x 15.9

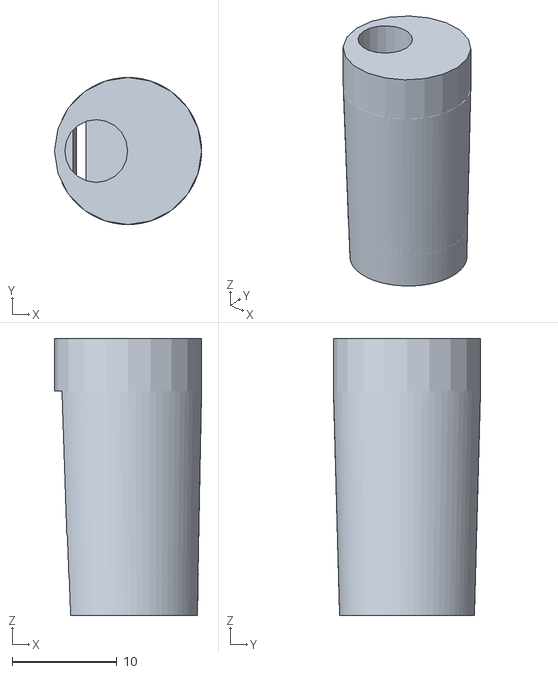
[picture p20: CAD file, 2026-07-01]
assets/head_v6.stl
14.1 x 14.1 x 26.5

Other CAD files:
out/halfcut_scale_fullrange.stl
out/revolver_geneva_assembled_a1mini.3mf
out/organ_full_set_1plate.swap.3mf
assets/body_v6.stl
assets/geneva_ref/ref_crank.stl
assets/geneva_ref/ref_driver.stl
assets/geneva_ref/ref_frameB.stl
assets/geneva_ref/ref_wheel.stl
assets/geneva_ref_split/part1.stl
assets/geneva_ref_split/part2.stl
assets/geneva_ref_split/part3.stl
assets/geneva_ref_split/part4.stl
assets/rod_v6.stl
assets/slide-recorder-head-v5.stl
assets/slide-recorder-head-v5x8.stl
assets/slide-recorder-head-v6.stl
harmonica_deck/cards/card_A_Fsm.stl
harmonica_deck/cards/card_Ab_Fm.stl
harmonica_deck/cards/card_B_Gsm.stl
harmonica_deck/cards/card_Bb_Gm.stl
harmonica_deck/cards/card_D_Bm.stl
harmonica_deck/cards/card_Db_Bbm.stl
harmonica_deck/cards/card_E_Csm.stl
harmonica_deck/cards/card_Eb_Cm.stl
harmonica_deck/cards/card_F_Dm.stl
harmonica_deck/cards/card_Fs_Dsm.stl
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

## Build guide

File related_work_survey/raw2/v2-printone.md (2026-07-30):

# v2 追検証: Printone を原典で確定し、印刷笛の音高精度をセントで報告した研究を整理する

検証日は2026年7月30日である。検証者は前段の調査とは別に、対象論文の本体（ACM Transactions on Graphics 版の全14ページ）を実際に取得して全文を読み、数値と語彙をすべて原文で照合した。前段の調査で未達成のまま残されていた「PrintoneのACM Transactions on Graphics版の本文に到達できていない」という項目は、この検証で解消した。

---

## 0. 結論の要旨

前段の報告は**おおむね正しいが、最も重要な数値の解釈に一箇所の重大な誤解がある**。

「56個の目標周波数のうち53個が実測範囲に入った」という記述は、短縮版（International Symposium on Musical Acoustics 2017）に一字一句そのまま存在する。しかし本体であるACM Transactions on Graphics版は、同じ評価について**まったく違う数え方をしており、「104個の目標周波数のうち、目標を出せなかったのは4個だけであった」と書いている**。さらに決定的なのは、この「実測範囲」がセント単位の精度を表す量ではまったくないという点である。実測範囲とは、**吹く速さを徐々に上げていったときに明瞭な音が鳴った最低周波数から最高周波数までの幅**である。つまりこの評価が言っているのは「奏者が吹き方を調整すれば目標音を出せる」ということであって、「設計どおりの音高が何セントの精度で出た」ということではない。Printoneの本文には「セント」という語が一度も現れない。

したがって、前段の「Printoneは目標周波数への合わせ込みを実機で検証しているため、CipherFluteの実測評価も同じ土俵で比較される」という警告は、**同じ土俵ではないという方向に修正されるべきである**。Printoneは吹き方で音高を動かせることを前提として、目標がその可動範囲に入るかどうかを見ている。CipherFluteは逆に、吹き方によるずれを基準笛で打ち消して離散スロットに落とすことを目指している。両者は音高の扱いに対する態度が正反対である。

一方で、「境界要素法で共鳴周波数を予測しながらフィップル吹き口を配置する」ことと「情報を符号として載せる発想がまったく無い」ことは、いずれも原典で完全に裏が取れた。

---

## 1. 対象論文の書誌を確定する

### 本体

Nobuyuki Umetani, Athina Panotopoulou, Ryan Schmidt, Emily Whiting, "Printone: Interactive Resonance Simulation for Free-form Print-wind Instrument Design", ACM Transactions on Graphics, 第35巻第6号, 論文番号184, pp. 184:1-184:14, 2016年11月11日（SIGGRAPH Asia 2016 Technical Papers, 12月5日から8日, マカオ）。所属はUmetaniとSchmidtがAutodesk Research、PanotopoulouがDartmouth CollegeとAutodesk Research、WhitingがDartmouth Collegeである。

- 書誌の確認先は https://doi.org/10.1145/2980179.2980250 に対するコンテンツネゴシエーションであり、著者4名・掲載誌名・巻号・ページ・出版年・出版者を直接取得して照合した。なおCrossrefに登録されている題名は副題のない「Printone」だけであり、ページは「1-14」と登録されている。
- **本文の確認先は https://www.dropbox.com/s/xyt2ixcpisl3wpi/2016_sigga_printone.pdf である。** これは著者本人が運営する研究室ページ https://cgenglab.github.io/en/publication/sigga16_printone/ が公開版として掲げているリンクであり、全14ページのPDFを取得できた。ACM Digital LibraryとDartmouth大学のページ（https://www.cs.dartmouth.edu/~athina/papers/a184-umetani.pdf）はいずれもHTTP 403を返して取得できなかったため、著者公開版で代替した。PDFの内部の題名情報にも「Printone: Interactive Resonance Simulation for ree-form Print-wind Instrument Design」と記録されており（先頭のFが欠けているのは製作時の不具合である）、本体であることを確認した。
- 補足資料の動画は https://www.youtube.com/watch?v=dWHYLqcCPuU で公開されている。

### 短縮版

Nobuyuki Umetani, Athina Panotopoulou, Ryan Schmidt, Emily Whiting, "Printone: Interactive Resonance Simulation for Print-wind Instrument Design", Proceedings of the 2017 International Symposium on Musical Acoustics, 6月18日から22日, モントリオール, カナダ, pp. 18-21, 2017年。

- 確認先は https://isma2017.cirmmt.mcgill.ca/proceedings/pdf/ISMA_2017_paper_47.pdf であり、全4ページの本文を取得した。各ページの下部に18から21までのページ番号が印字されていることも確認した。題名から「Free-form」が落ちている点は本体と異なる。
- 短縮版は本体を参考文献[1]として自己引用し、「ACM Trans. Graph., vol. 35, no. 6, pp. 184:1-184:14, Nov. 2016」と記載している。前段の報告が論文番号184の根拠としてこれを挙げていたのは正しい。

---

## 2. 確認事項への回答

### 2.1 境界要素法で共鳴周波数を予測しながらフィップル吹き口を配置するという記述は本当にあるか

**本当にある。完全に裏が取れた。**

境界要素法については、本体の概要が「we present a novel efficient method to estimate the resonance frequency based on the boundary element method by formulating the resonance problem as a minimum eigenvalue problem」と述べている。本文の第5節では、ヘルムホルツ方程式を境界要素法で離散化して A(k)p = f という行列形式に落とし、波数 k について非線形に変化する係数行列 A(k) の最小固有値が小さくなる波数を共鳴と定義している。第6節では、この非線形固有値問題を波数について一次のテイラー展開で近似し、一般化非エルミート固有値問題に帰着させて逆べき乗法で解くという高速化を示している。

吹き口の配置については、本体の第4節「User Interface」の冒頭が「The 3D user interface consists of geometric editing tools to place finger holes and the fipple.」と明記している。同節の「Geometric editing」の項は、利用者が物体表面をクリックしてフィップルと指孔を置き、フィップルの向きも調整できると述べている。しかも「Design procedure」の項は、フィップルの位置を変えると達成済みの共鳴周波数がすべて変わってしまうため、設計の最初に吹き口を置くよう推奨し、図17の形状ではフィップルの移動によって共鳴周波数が最大20ヘルツ変化したという実測値まで挙げている。つまり吹き口の配置と共鳴予測は明確に連動している。

フィップルを選んだ理由も明示されている。「Our mouthpiece is the fipple, which is commonly used for recorders or ocarinas.」と述べ、リードを避けた理由として「the vibration properties of reeds are very sensitive to material stiffness and thus are difficult to fabricate with commonly available FDM printers」と説明している。**家庭用の熱溶解積層方式で作りやすいからフィップルを選ぶという判断は、CipherFluteとまったく同じである。**

なお、フィップルの発音そのものは物理的に解いていない。本体の第3節は、吹き口の振動と共鳴の結合を無視して「passive resonator（受動共鳴器）」として扱うと明言し、結合を解くには計算流体力学による乱流解析が必要であるとしている。したがってPrintoneが計算しているのは共鳴器の共鳴周波数であって、笛が実際に鳴らす音そのものではない。

### 2.2 「16本を製作し56個の目標周波数のうち53個が実測範囲に入った」は本当にその論文に書かれているか。書かれているならその「実測範囲」は何セントに相当するか

これは**三つに分けて答える必要がある**。

**(a) 「16本」は本体に書かれている。** 本体の第9節「Results」の冒頭が「Figure 1, 10, 15 and 17 show sixteen wind instruments created using our tool.」と述べている。短縮版も「Figure 1 and Figure 3 show five out of sixteen wind instruments created using our tool.」と述べており、16本という総数は両版で一致する。

**(b) 「56個中53個」は短縮版にだけ書かれており、本体はまったく違う数を挙げている。** 短縮版の第5節は「We observe that the target frequencies generally (53 out of 56 target frequencies) fall within measured ranges」と書いており、前段の報告の引用は正確である。しかし本体の同じ「Accuracy」の段落は、次のように書いている。

> 「Among the 104 target frequencies we created with various instrument shapes, we experienced only 4 instances where the instrument could not play a target frequency: at the highest frequencies of BEETHOVEN, BUNNY, LIZARD and FLUTE3.」

つまり本体は**目標周波数を104個作って、出せなかったのは4個だけであった**と述べている。本体の全文を機械的に検索したが、「56」という数は14ページのどこにも現れず（唯一の一致はページ番号である）、「53」も参考文献のページ番号としてしか現れない。

この二つの数の食い違いについて、失敗した本数の側は説明がつく。本体が名指しした4本の失敗のうち、BEETHOVEN、BUNNY、LIZARDの3本は短縮版の図3にも載っている形状であり、残るFLUTE3は本体の図10にしかない笛である。したがって短縮版の「3個の失敗」は、短縮版が載せた範囲での失敗数として整合する。しかし**母数の側は整合しない**。本体の図17に列挙された笛の目標音数を合計すると65音になり、短縮版が言う56にも本体が言う104にも一致しない。短縮版の「56」がどの範囲を数えたものかは、両版の本文からは確定できなかった。**論文に書くのであれば、本体の「104個中4個が失敗」を使うべきである。** これが著者が全16本について報告した公式の数である。

**(c) 「実測範囲」はセント単位の精度ではない。ここが前段の報告の最大の誤解である。** 本体の該当箇所を引く。

> 「Red lines are the target frequencies, while the measured frequencies are shown as ranges between the light and dark green lines. This range occurs because the sound is influenced by the speed of blowing (higher speed produces higher frequencies). We gradually increased the blowing speed and recorded the lowest and highest frequencies that produce clear sound.」

すなわち実測範囲とは、**吹く速さを徐々に上げながら、明瞭な音が出た最低の周波数と最高の周波数を記録した幅**である。続く文が「i.e., the user can play the exact tones with proper blowing speed. This type of fine-scale tuning by adjusting the blowing speed is very common in wind instruments.」と述べているとおり、この評価の主張は「奏者が吹き方を選べば目標音に当てられる」ということである。設計誤差の大きさを示す量ではまったくない。したがって「53個が実測範囲に入った」を音高精度の実績として読むのは誤りである。

**本体の全文に「cent」および「cents」という語は一度も現れない。** 機械的な語境界検索で0件であることを確認した。Printoneはセント単位の精度をいっさい報告していない。

ただし本体には、セントに換算できる数値がいくつか別の文脈で書かれている。以下の換算は検証者による計算であり、論文が書いた値ではないことを明記する。

| 論文が報告している値 | 出典箇所 | 検証者によるセント換算 |
| --- | --- | --- |
| 失敗した4個は目標より最大3パーセント低い（「These frequencies are at most 3% lower than the target frequency」） | 本体 第9節 Accuracy | 約マイナス52.7セント |
| 受動共鳴の実測とシミュレーションの差は最大10ヘルツ（「We observed up to 10 Hz deviation between the simulation and the experiment」、立方体は一辺4センチメートル） | 本体 第9節 Accuracy | 1000ヘルツ付近で約17.2セント、1500ヘルツで約11.5セント、3000ヘルツで約5.8セント |
| フィップルの位置を移すと共鳴周波数が最大20ヘルツ変化する | 本体 第4節 Design procedure | 1000ヘルツ付近で約34.3セント |
| 感度解析による一次近似の誤差は10パーセント未満（孔径の変化が半音相当のとき） | 本体 第7節 | 対話中の粗い近似の誤差であり、完成品の音高精度ではない |

論文自身が精度の妥当性を主張する論拠は、「Since changes in the blowing speed can easily compensate for a 10Hz error, we believe the parameters we used are reasonable.」という一文である。**10ヘルツ程度の誤差は吹き方で吸収できるから十分だ**という立場であり、CipherFluteが必要とする「吹き方によらず離散スロットに落ちること」とは要求が真逆である。同様に材料の議論でも「at the object scales we explored, fabrication error is small compared to the range of frequencies the mouthpiece can produce by changing the blowing speed」と述べており、造形誤差を吹奏可変範囲より小さいという相対評価で片づけている。

### 2.3 複数の音を1つの物体で出す設計を扱っているか。同時発音か切り替えか

**扱っている。ただし完全に切り替えであり、同時発音ではない。**

本体は1つの物体に1つのフィップルと3個から5個の指孔を設け、指孔の開閉の組合せで4音から9音を出している。図17に列挙された笛の内訳は、指孔3個で4音または5音、指孔4個で6音から8音、指孔5個で9音（DOUGHNUT）である。本体は「we have been able to achieve between 5 to 8 target frequencies for the shapes we have tested, with three to four finger holes」と述べ、設計手順の節では「N holes are sufficient to produce N+1 target tones」「there are actually 2^N finger configurations for N holes, fewer holes can also be used」と、指孔の組合せ論を明示的に使っている。

同時発音については、本体の全文に「simultaneous」「chord」「polyphony」に相当する語が**いずれも0件**である。基本周波数のみを対象とし、倍音も音色も扱わないと繰り返し明言しており（「we do not simulate the timbre of the instrument」）、出力は常に単音である。目的も単音の旋律を奏でること（「play a specific song」「familiar songs」）に限られている。吹き口も1個だけであり、複数のフィップルを1物体に共存させる設計は現れない。

したがって「1つの印刷物から複数の異なる音高を得る」ことそれ自体は、Printoneが2016年に達成済みである。**しかもDOUGHNUTは1物体で9個の異なる音高を出しており、CipherFluteの13スロットという語彙の大きさと桁は同じである。** ここはCipherFluteが新規性として主張してはいけない部分である。区別できるのは、Printoneが「1本の笛を指で切り替えて旋律を奏でる」構成であるのに対し、CipherFluteが「多数の単音笛を並べて順に吹き、音高の並びを符号列として読む」構成である点だけである。

### 2.4 情報を符号として載せる発想がまったく無いことの確認

**まったく無い。機械的な語彙検索で確定した。**

本体の全文（14ページ、約11万文字の抽出テキスト）に対して語境界つきの検索を行った結果は次のとおりである。

| 語 | 出現回数 | 備考 |
| --- | --- | --- |
| bit / bits | 0 / 0 | |
| code / codes / coding | 0 / 0 / 0 | |
| encode / encoding / decode | 0 / 0 / 0 | |
| information | 1 | 「the sensitivity information（感度情報）」を使って孔径を最適化するという文脈だけである |
| data | 1 | 「measured ground truth data（実測の真値データ）」という文脈だけである |
| secret | 0 | |
| message | 0 | |
| identification | 0 | |
| identify | 1 | 「To identify the resonance frequencies（共鳴周波数を同定するには）」という文脈だけである |
| tag / tags | 0 / 0 | |
| watermark | 0 | |
| steganography | 0 | |
| cryptography | 0 | |
| key | 0 | |
| storage / store | 0 / 0 | |
| capacity | 0 | |
| symbol / alphabet | 0 / 0 | |

「情報」「符号」「ビット」「秘密」「識別子」「記憶」「容量」に相当する語が、情報を物体に載せる意味では**一度も使われていない**。Printoneの目的は一貫して「自由形状の物体を機能する管楽器に変えて旋律を奏でさせること」であり、限界と将来課題の節も音色のシミュレーションと吹き口の設計最適化を挙げるにとどまる。**この確認は、CipherFluteの符号化という貢献がPrintoneに先取りされていないことを積極的に支持する証拠である。**

### 2.5 追加の重要な発見: 造形方法が根本的に違う

前段の報告には現れていないが、論文に書くうえで決定的に重要な差がある。Printoneの造形は次のとおりである。

> 「We print the designed wind instruments using PLA filament on a MakerBot Replicator 2 printer, which is a widely available printer/material combination. In order to create an empty cavity inside the shape, we cut the model in half, print each half separately, and then glue the halves together. The cutting was done manually using a standard mesh editing software, with the cut placed such that we can remove the support material inside the cavity after printing.」

つまりPrintoneは、**空洞を作るために模型を手作業で半分に割り、別々に印刷し、内部のサポート材を取り除いてから接着している**。粉末方式の装置なら分割は不要だと述べているが、実際に使ったのは家庭用の熱溶解積層方式の装置である。材料の影響を調べるために追加でPolyJet方式（Objet Connex 260、VeroWhitePlus材）と光造形方式（Autodesk Ember、紫外線硬化樹脂）でも印刷しているが、基本音に可聴な差はなかったと報告している。

CipherFluteは、円筒を軸方向に半分に割った断面という形を選ぶことで、**サポート材なしの平置き一体印刷**を実現し、分割も接着も後処理も要らない。さらに同じ物体に多数本を融合できる。この造形上の性質は、Printoneが明示的に妥協した点をまさに解消するものであり、CipherFluteの実装上の貢献としてはっきり主張できる。逆にPrintoneを引用しないままだと、この差が読者に見えない。

---

## 3. 印刷した笛の音高精度をセント単位で報告した研究の整理

### 3.1 Matthew Dabin ら（NIME 2016）の数値は原典で完全に一致した

Matthew Dabin, Terumi Narushima, Stephen Beirne, Christian Ritz, Kraig Grady, "3D Modelling and Printing of Microtonal Flutes", Proceedings of the 16th International Conference on New Interfaces for Musical Expression (NIME 2016), pp. 286-290, 2016年7月11日から15日, グリフィス大学, ブリスベン。

確認先は https://www.nime.org/proceedings/2016/nime2016_paper0056.pdf であり、本文と表1を取得して照合した。書誌は https://nime.org/proc/nime2016_dabin/ で確認した。

表1の原文の数値をそのまま書き出す。第7から第12下方倍音にあたる6音と、オーバーブローによる2音について、目標周波数との差をセントで報告している。

| 下方倍音 | 目標(ヘルツ) | リコーダー1(ヘルツ) | 差(セント) | リコーダー2(ヘルツ) | 差(セント) | リコーダー2改(ヘルツ) | 差(セント) |
| --- | --- | --- | --- | --- | --- | --- | --- |
| 12分の1 | 616 | 628 | +34 | 617 | 1 | 612 | -10 |
| 11分の1 | 672 | 681 | +23 | 664 | -21 | 673 | 5 |
| 10分の1 | 739 | 749 | +24 | 738 | -3 | 745 | 14 |
| 9分の1 | 821 | 828 | +14 | 810 | -24 | 815 | -13 |
| 8分の1 | 924 | 932 | +16 | 908 | -30 | 923.5 | -1 |
| 7分の1 | 1056 | 1060 | +6 | 1031 | -40 | 1049 | -12 |
| 12分の1（オーバーブロー） | 1232 | 1246 | +19 | 1228 | -5 | 1236 | 5 |
| 11分の1（オーバーブロー） | 1344 | 1359 | +20 | 1335 | -11 | 1351 | 9 |

前段の報告が挙げた数値は**すべて正しい**。リコーダー1は+6から+34セント、リコーダー2は-40から+1セント、指孔2個をやすりで手修正したリコーダー2改は-13から+14セントである。

目標についても原文を確認した。「our goal is to continue to improve the pitch accuracy of our 3D-printed designs to no more than a five cent error so that manual adjustments are not needed.」であり、5セント以内という将来目標も正しい。

評価方法は、無響環境でBehringer ECM8000測定用マイクロフォンとBehringer ADA8000プリアンプで録音し、Melodyneソフトウェアで音高を求めるものである。

### 3.2 同じ研究グループの短報が「既存モデルは30セント程度」という有用な基準を与えている

Christian Ritz, Matthew Dabin, Terumi Narushima, Kraig Grady, Stephen Beirne, "3D printing for custom design and manufacture of microtonal flutes", SPIE Newsroom, 2015年9月18日。書誌の確認先は https://doi.org/10.1117/2.1201508.006082 であり、本文は https://spie.org/news/6082-3d-printing-for-custom-design-and-manufacture-of-microtonal-flutes で取得した。

この短報は「existing mathematical models gave approximate solutions to finger hole locations, usually with an accuracy of 30 cents compared with the desired frequency」と述べ、続けて「Our goal is to achieve no more than a five-cent error, which we consider to be an acceptable deviation for wind instruments such as the flute」と書いている。

**「既存の数理モデルによる指孔位置の解は目標周波数に対して通常30セント程度の精度である」という一文は、CipherFluteが100セント刻みという粗い量子化を選ぶ判断を外部から裏づける、きわめて使いやすい基準である。** 前段の報告にはこの30セントという数値が現れていなかったので、新たな収穫として記録する。ただし査読論文ではなく学会の広報媒体の短報であることに注意が必要である。

### 3.3 セント単位の報告はDabinらがほぼ唯一であることを、前段の資料群全体に対して機械的に確認した

前段の調査で取得された文献群（作業領域に蓄積されていた抽出テキスト群、印刷楽器・受動音響タグ・音響センシング・物理符号など全切り口にわたる119件のテキストファイル、うち内容のある3000文字超のものが106件、合計約768万文字）に対して、語境界つきで「cent」および「cents」を機械的に検索した。結果は次のとおりである。

- **印刷した楽器の音高精度をセントで報告しているのは、Dabinら（NIME 2016）ただ1件であった。**（「cents」が5件、「cent」が1件であり、いずれも音高の差または5セント以内という目標の文脈である。）
- Printone は本体（ACM Transactions on Graphics 2016）も短縮版（International Symposium on Musical Acoustics 2017）も、ともに0件である。
- FlueBricks（CHI 2026）は0件である。
- Blowhole（Graphics Interface 2018）は0件である。
- 残る一致はすべて通貨のセント（封印の単価が75セント、無線タグの単価が10セントなど）であり、音高とは無関係であった。

したがって前段の「音高精度をセント単位で報告した査読文献はDabinらがほぼ唯一である」という判断は、**この文献群のもとで正しい**と確認できた。しかもDabinらの装置はPolyJet方式であり、家庭用の熱溶解積層方式で多数本の笛の音高分布をセントで測った報告は、依然として見つかっていない。

### 3.4 参考: 楽器音響の分野にはセント単位の報告があるが、印刷とは結びついていない

Nathan Szwarcberg, Tom Colinot, Christophe Vergez, Michaël Jousserand, "Geometric sensitivity of modal parameters in wind instrument models: a case study on saxophone intonation", Acta Acustica, 第9巻, 論文番号57, 2025年。確認先は https://doi.org/10.1051/aacus/2025039 に対するコンテンツネゴシエーションと、本文 https://acta-acustica.edpsciences.org/articles/aacus/full_html/2025/01/aacus250082/aacus250082.html である。

サクソフォンの音程の非調和性をセントで報告しており（例として上流側の孔で最小プラス68.8セント、下流側の孔でプラス18.6セント、レジスターホールの半径を0.2ミリメートル小さくすると3.4セント改善するという見積もり）、幾何形状の微小な変化が音程に効く感度を定量化している。3Dプリントは扱わず、情報の符号化も扱わない。

**この研究は、CipherFluteが「寸法の小さな誤差が音高に効く」ことを述べる際の音響学側の裏づけとして使える。** 同時に、セント単位で音程を論じることは楽器音響では当然の作法であって、CipherFluteがセントで測ること自体には新規性がないことも示す。

---

## 4. demakein と openwind の位置づけ

### demakein

作者はPaul Francis Harrisonである。公式ページ http://www.logarithmic.net/pfh/design の自己説明は「Software to design and make woodwind instruments using a 3D printer or CNC mill. The 'design' phase determines the size and placements of holes, and shape of the bore.」である。つまり**設計段階で孔の寸法と位置、およびボアの形状を決める**ソフトウェアである。組み込みの楽器はフルート、ホイッスル（フィップル笛）、ショームであり、いずれも移調や変形の指定ができるパラメトリックな楽器として用意されている。Pythonに慣れた利用者は「play exactly the scale you want」（望む音階をそのまま鳴らす）ように独自の楽器を記述できると書かれている。バージョン1.1が2025年7月に公開され、Python 3へ移行している。

**査読論文としての位置づけはまったく無い。** 公式ページに論文の引用はなく、学術的な発表媒体を持たない。ただしDabinら（NIME 2016）が参考文献[10]としてこのソフトウェアを引用しているので、印刷楽器の分野の査読論文がこの道具を認知していることは確認できる。

なお、公式ページが自動最適化を行うと明言しているかどうかは、今回の取得でも断定できなかった。前段の報告が書いた「与えた運指と音階に対して正しい音が出るように数値最適化する」という記述のうち、「孔の寸法と位置とボア形状を設計段階で決める」ことは自己説明のとおりであるが、それが最適化アルゴリズムによるものだという明示は公式ページには見当たらない。実装コードを読まないかぎり断定できない。

### openwind

InriaのMakutuチームが開発するPythonライブラリであり、ライセンスはGPL-3.0である。公式ページ https://openwind.inria.fr/ が挙げる機能は三つである。第一に入力インピーダンスの計算であり、放射、断面変化、側孔、各種のボア形状を扱う。第二に音のシミュレーションであり、リードや唇の力学と管の音響を結合して時間領域の有限差分で解く。第三に楽器形状の最適化であり、**測定したインピーダンスからボア形状を復元する逆問題を含む**。

**openwindには査読論文としての位置づけが明確に存在する。** 三つ確認した。

1. Augustin Ernoult, Christophe Vergez, Samy Missoum, Philippe Guillemain, Michael Jousserand, "Woodwind instrument design optimization based on impedance characteristics with geometric constraints", The Journal of the Acoustical Society of America, 第148巻第5号, pp. 2864-2877, 2020年11月1日。確認先は https://doi.org/10.1121/10.0002449 に対するコンテンツネゴシエーションである。
2. Augustin Ernoult, Juliette Chabassier, Samuel Rodriguez, Augustin Humeau, "Full waveform inversion for bore reconstruction of woodwind-like instruments", Acta Acustica, 第5巻, 論文番号47, 2021年。確認先は https://doi.org/10.1051/aacus/2021038 に対するコンテンツネゴシエーションである。
3. A. Ernoult, J. Cabaret, J. Chabassier, "Openwind: a software to simulate wind instruments, as a tool for acoustic teachers", Proceedings of the 10th Convention of the European Acoustics Association Forum Acusticum 2023, pp. 4873-4876, 出版者はEuropean Acoustics Associationである。確認先は https://doi.org/10.61782/fa.2023.0233 に対するコンテンツネゴシエーションであり、公開版は https://inria.hal.science/hal-04217988 にある。これは道具そのものを主題とする査読つき会議論文である。

したがって前段の整理は正しい。**「管の形状から音高を求める順問題」も「音の測定から管形状を復元する逆問題」も、査読論文として確立した技術である。** とくに逆問題の存在は、CipherFluteが脅威モデルで宣言している「物理層に秘匿の力はない」という主張を補強する材料になる。音を録るだけでも管の形状が推定できる技術が公開ライブラリとして存在するのだから、「音を録られたら読まれる」という前提は誇張ではなく実在の技術に裏づけられている。

なお、openwindの公式ページのうち、引用先を列挙しているとされる contributions.html と publications.html はいずれもHTTP 404を返した。上記の3件は検索結果とHAL、およびCrossrefの登録情報から確定した。

---

## 5. 前段の報告に対する判定

### 正しかったこと

- Printoneが境界要素法で共鳴周波数を予測し、フィップル吹き口と指孔を配置する対話的な設計道具であること。
- フィップルを選んだ理由が家庭用の熱溶解積層方式で作りやすいことであり、CipherFluteと同じ発音機構であること。
- 16本の楽器を設計・印刷したこと。
- 短縮版に「56個の目標周波数のうち53個が実測範囲に入った」と書かれていること（引用そのものは正確である）。
- 共鳴を非線形行列の最小固有値問題として定式化し、一次のテイラー展開で一般化固有値問題に帰着させていること。
- 指孔径の連続変更中は感度解析による一次近似で毎秒30フレーム以上を保ち、待機中に数秒かけて精確な計算を回すこと。
- 目標周波数を複数の運指について指定して指孔径を自動最適化するAutoTune機能があること。
- 音色を扱わず基本周波数だけを対象とすると明記していること。
- 短縮版が道具全体の平均動作速度を毎秒5フレームと報告していること。
- Dabinら（NIME 2016）が報告したセント値と、5セント以内という将来目標を掲げていること。
- 印刷楽器の音高精度をセントで報告した査読文献がDabinらほぼ唯一であること。
- demakeinが査読論文を持たない設計道具であり、openwindが査読論文に裏づけられた順問題と逆問題の道具であること。

### 誤り、または重大に不十分だったこと

1. **「実測範囲」の意味を取り違えている。** これが最大の誤りである。実測範囲は吹く速さを上げながら明瞭に鳴った最低周波数から最高周波数までの幅であり、設計精度を表す量ではない。前段の要約は文言としては「吹く速さを徐々に上げながら明瞭に鳴る最低周波数と最高周波数を記録し」と正しく書いているのに、脅威の判定では「Printoneが目標周波数への合わせ込みを実機で検証しているため、CipherFluteの実測評価も同じ土俵で比較される」と結論しており、両者が同じ土俵だという誤った含意を残している。実際には音高精度に対する要求が正反対である。
2. **本体の公式の数値である「104個中4個が失敗」を見落としている。** 短縮版の「56個中53個」だけを引いており、しかも「16本を製作し56個の目標周波数のうち」と続けたために、56個が16本すべてを数えたものだと読める。本体は104個を数えている。論文に書くなら104個中4個を使うべきである。
3. **Printoneがセントをいっさい報告していないという事実を明示していない。** 前段は「セント換算の定量値を取れていない」と未達成項目に書いていたが、正しくは「原典にセント表記が存在しない」である。これは調査の欠落ではなく原典の性質である。
4. **造形方法の根本的な違いを見落としている。** Printoneは模型を半分に割って別々に印刷し、内部のサポート材を除去して接着している。CipherFluteのサポートなし一体平置き印刷との差は、実装上の貢献として主張できる重要な論点である。
5. **1つの物体から出せる音高の数を押さえていない。** Printoneは指孔5個のDOUGHNUTで9音を出している。CipherFluteの13スロットと桁が同じであり、「1つの印刷物から多数の音高を出す」ことを新規性に数えられないという厳しい事実である。
6. **Ritzらの短報にある「既存モデルは30セント程度の精度」という数値を拾っていない。** CipherFluteの100セント刻みを正当化する最良の外部基準である。

---

## 6. この文献群のもとでCipherFluteに残る新規性の厳しい判断

前段は「Printoneが印刷された笛の計算設計という技術的貢献をほぼ完全に先取りしている」と判定した。原典に当たった結果、**この判定は結論としては維持されるが、理由は前段が書いたものとは違う**。

まず、崩れた主張を並べる。第一に、「管の長さと音の高さの対応を計算して笛の形を決め、家庭用の熱溶解積層方式で印刷し、狙った音高が出ることを実機で確かめる」という工程は、Printoneが2016年に、より一般的な自由形状に対して、より厳密な物理（境界要素法による三次元の波動方程式）で達成している。しかもPrintoneが引く先行研究のとおり、円筒管の共鳴を管長から求める一次元モデルは、Printone自身が「既知の単純な近似式」として本文の図3で紹介して脇に置いた出発点である。CipherFluteの f = A/(L+e) は、まさにその脇に置かれた側の式である。**したがって「管長と周波数の対応式を作った」ことに新規性はいっさい無い。**これは10年前の論文が前提として図解している既知の関係であり、demakeinが2012年から実装し、openwindが査読論文つきで一般化している領域である。CipherFluteは較正定数AとeをPETGや自機の造形条件に合わせて実測で当てはめたにすぎず、それは工学的な較正であって学術的な新規性ではない。

第二に、「1つの印刷物から複数の音高を出す」ことにも新規性が無い。Printoneは指孔の組合せで最大9音を1物体から出している。

第三に、「印刷した笛の音高を実機で測って目標と比べる」ことにも新規性が無い。PrintoneとDabinらの両方がやっている。

次に、残る新規性を述べる。**残るものは、前段が書いたとおり「符号化」の側にあり、それは原典の確認によってむしろ強固になった。** 具体的には次の四つである。

1. **音高の並びを符号語として読むという発想そのものが、Printoneに完全に存在しない。** 語彙検索で「bit」「code」「encode」「information」「data」「secret」「message」「capacity」「symbol」がいずれも情報を載せる意味では0件であることを確認した。Printoneの音高は演奏されるための音であって、読み取られるための記号ではない。この差は言葉遊びではなく、設計目標が根本的に違うことの帰結である。Printoneは「吹き方で音高を動かせるから目標に当てられる」ことを長所として報告する。CipherFluteは「吹き方で音高が動くこと」を打ち消すべき雑音として扱う。**同じ物理現象に対して、一方が可変性を資源とみなし、他方が可変性を敵とみなしている。** ここがCipherFluteの土台である。
2. **音高が既知の基準笛を同居させて比で読む較正は、この文献群に見つからなかった。** Printoneは吹く速さによる幅を「奏者が調整すればよいもの」として受け入れ、Dabinらは奏者の影響を「常に存在するもの」として受け入れる。物体の中に較正用の音源を混ぜて相対量で読む設計は、通信のパイロット信号からの転用としてCipherFlute固有と言える。
3. **誤り訂正符号と隣接同音禁止の制約を、物理的な形状設計の制約として持ち込む発想は見つからなかった。** Printoneが解いているのは「目標周波数を達成する形状を探す」最適化であり、「読み出し誤りに耐える符号語の集合を設計する」問題ではない。
4. **サポート材なしで平置き一体印刷できる小型フィップル笛を、多数本融合して日用品に偽装して埋め込む構成は見つからなかった。** Printoneは1物体を1つの楽器にし、しかも空洞を作るために分割と接着を要した。CipherFluteは分割も接着も要らない。ただし「多数の管を1つの印刷物にまとめる」ことそのものには前例があるので（前段が挙げたSzabóのパンフルート合奏体、FlueBricksの息を分配する連結部）、融合そのものではなく「単音笛を情報担体として日用品に偽装する」点に限って主張すべきである。

以上を踏まえた厳しい結論は次のとおりである。**CipherFluteは「管の長さと音の高さの対応式にもとづく符号化」という貢献の主張のうち、前半の「対応式」を新規性として掲げてはならない。掲げれば直ちに反証される。主張できるのは後半の「符号化」だけである。** すなわち貢献の言い方は、「既知の管長と周波数の関係を、離散スロットからなる符号の語彙として再定義し、基準笛による正規化と誤り訂正と隣接制約を伴う読み出し系として組み立てた」という形に限定すべきである。設計計算の新規性は明示的に放棄したほうが、査読者に対してかえって強い立場になる。

そして実務上の指示を一つ加える。**Printoneは必ず引用しなければならない。** 引用しないことの危険は前段が書いたとおりだが、引用したうえで書くべき差分は前段が想定したものとは違う。書くべきは「対話的な自由形状設計が不要な理由」ではなく、**「Printoneが長所として報告した吹奏による音高可変性が、情報を読み出す目的では最大の敵になること」**である。この一文があれば、CipherFluteが基準笛と100セント刻みという設計を選んだ理由が、先行研究との関係のなかで自然に説明される。あわせてDabinらの数十セント規模の実測値とRitzらの「既存モデルは30セント程度」という基準を並べれば、100セント刻みという粗い量子化は妥協ではなく必然として読める。

---

## 7. 確認できなかったこと

1. **短縮版の「56個の目標周波数」がどの範囲を数えたものかを確定できなかった。** 本体の図17に列挙された笛の目標音数の合計は65であり、56とも104とも一致しない。本体と短縮版のいずれの本文にも母数の内訳が書かれていない。失敗した3本が短縮版の図に載っている3本（BEETHOVEN、BUNNY、LIZARD）と整合することは確認したが、母数の56は説明がつかないまま残った。
2. **Printoneの実測範囲の幅そのものを数値で取り出せなかった。** 幅は図17と図10のグラフとして示されるだけで、最低値と最高値の表は本文に無い。したがって「吹き方で何セント動くのか」という、CipherFluteにとって最も知りたい数値は原典から読み取れない。図の画素を測れば概算できるが、それは論文に書ける精度の値ではない。もし論文で「吹奏による音高変動が数十セント規模である」と書きたいなら、CipherFlute自身の実測で示すべきである。
3. **Printoneの補足資料（Appendix Aを含む supplemental material）を取得していない。** 本文が「see (A.5) in the supplemental material」と参照しており、スケーリング不変性の証明が入っている。符号化には影響しないが、一次元近似との関係を数理的に厳密に書きたい場合は必要になる。
4. **demakeinが実際に最適化アルゴリズムを使っているかを、実装コードで確認していない。** 公式ページの自己説明は「孔の寸法と位置とボアの形状を決める」までであり、それが最適化によるものかどうかは断定できない。CipherFluteの経験式との包含関係を厳密に述べるには、リポジトリのコードを読む必要がある。
5. **openwindの公式な引用要請ページに到達できていない。** contributions.html と publications.html はいずれもHTTP 404であった。上記の3件は検索結果、HAL、Crossrefから確定したが、プロジェクトが「これを引用せよ」と指定している論文がどれかは確認できていない。
6. **Printone以後の被引用をたどっていない。** Printoneを引用した後続研究のなかに、音高を符号として読む方向へ進んだものがあるかどうかを確認していない。Semantic Scholarの被引用一覧を当たるべきである。
7. **前段が未確認として残した Blowhole の本文の数値は、この検証でも解消していない。** 抽出テキストは作業領域に存在するものの、本検証の対象範囲外としたため、識別クラス数や正解率をあらためて照合していない。CipherFluteの最重要の比較対象であるから、別途確定させるべきである。

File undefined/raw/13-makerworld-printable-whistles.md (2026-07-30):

# モデル共有基盤における3Dプリントの笛と情報を埋め込んだモデル

この文書は、CipherFluteの新規性を検討するために、3Dモデル共有基盤（MakerWorld、Printables、Thingiverse、Cults3D）に実際に公開されているモデルを一件ずつブラウザで開いて調べた結果である。学術論文ではなく実物のページを一次資料として扱い、確認したページのURLと、そのページ上で確認できた数値をそのまま記載した。数値はすべて2026年7月30日に確認したものである。

なお、この調査では検索エンジンの利用枠を使い切ったため、各基盤の内部検索機能とサイトマップを直接叩くという方法をとった。そのぶん基盤内部の網羅性は高いが、基盤の外側（ニュース記事や市場調査レポート）についてはWikipediaなどの二次資料に頼った箇所がある。該当箇所は明示した。

---

## この切り口の要約

3Dプリントできる笛は、モデル共有基盤において巨大かつ成熟したジャンルである。Printablesでは「whistle」の検索で1,150件が該当し、最上位のFlat Pocket Whistleは厚さ3mm、43×22mmで財布に入る平板型の笛で、いいね12,926件、ダウンロード97,000件、実作と書き込みの合計2,965件、リミックス99件に達している。MakerWorldでも同種の平板型笛や超大音量笛が数万ダウンロード級で多数存在する。したがってCipherFluteが前提とする「薄く小さくサポート材なしで平置き印刷でき、確実に鳴るフィップル笛」という工作技術それ自体は、すでにコミュニティの共有財産であって新規ではない。さらにdp makesのWhistle Pan Fluteは「長さの異なる笛を一列につないだ」構成を明言しており、CipherFluteの物理形態（複数の笛を融合した一体物）に最も近い先行実装である。音高の設計についても、ThreeD-Michaelは4.2kHzから23kHzまで周波数を明示した犬笛のシリーズを公開し、スマートフォンのアプリで周波数を検証する手順まで書いている。半音階を扱うモデルも存在し、Chromatic Pan Fluteの作者は「管長を理論値どおりに計算すると高音側が高くなりすぎて下げられないので全管に2cm足して直した」と書いており、CipherFluteが f = A/(L+e) の e で扱う端補正に相当する現象を経験的に把握している。

一方で、笛の音高を符号として情報を運ぶモデルは、4つの基盤のいずれにも1件も見つからなかった。多音笛はすべて「同時に鳴らして大音量や不快な音を作る」ためのものであり、1本ずつ順に吹いて記号列として読む発想は存在しない。他方、暗号資産の復元情報を3Dプリント物に「機械可読な符号として」載せる系譜はすでに確立している。QR SafeShareは秘密をShamirの秘密分散またはXORで分割し、各シェアを3MFとして書き出して3Dプリントする道具であり、脅威モデルの立て方（数学的な安全性は秘密分散だけが担い、物理層は走査コストを上げるだけ）がCipherFluteとほぼ同型である。SeedQRおよびその3Dプリント用テンプレートも同じ位置にある。CipherFluteの新規性は、この既存の系譜のなかで「読み出し経路が光学ではなく音である」ことと「日用品に偽装できる」ことに絞られる。

---

## 基盤の規模（公開されている数字）

第四の設問に対する回答である。各基盤の公式なプレスリリース上の数字は見つけられなかったので、各基盤が自ら公開しているサイトマップと検索画面の表示から数えた。サイトマップは検索エンジン向けに基盤自身が生成している一次データである。

| 基盤 | 公開モデル数の推定 | 数え方 |
|---|---|---|
| MakerWorld | 約2,329,861件 | サイトマップ索引（https://makerworld.com/sitemaps/index.xml ）に models.xml のページが p=0 から p=2329 まで2,330枚あり、1枚に10,000のURLが入るが、同一モデルが10言語分並ぶので1枚あたり1,000モデルである。最終ページ（p=2329）は8,610URL、すなわち861モデルであった。したがって2,329×1,000＋861＝2,329,861件となる。 |
| Thingiverse | 約2,248,046件 | sitemap_thing_1.xml から sitemap_thing_45.xml まで45枚あり、1枚50,000件、最終ページのみ48,046件であった。sitemap_thing_46.xml はHTTP 500を返し、45枚で打ち止めであることも確かめた。 |
| Printables | 約1,383,000件 | sitemap-model.xml が1,383ページあり、1ページ1,000件であった（最終ページ p=1383 も1,000件で満杯であった）。 |
| Cults3D | 3.5M（350万件）と自称 | 検索窓のプレースホルダに "Search 3.5M designs…" と表示される。ただし内訳の定義は示されていない。 |

- MakerWorldの1枚あたり1,000モデルという数え方は、実際に p=0 を取得して確かめた。10,000件のURLに含まれるモデルIDは1,000種であり、言語は en、zh、de、fr、it、es、ja、ko、sv、pt の10種であった。
- MakerWorldのサイトマップの先頭に置かれているモデルは、Bambu Lab自身が2023年4月13日に公開した「Bambu Christmas Cabin」（https://makerworld.com/en/models/12682-bambu-christmas-cabin 、投稿者名はBambu Lab、作成日時は2023-04-13、ダウンロード8,984件）である。サイトマップはモデルIDの昇順に並んでいるので、これが最古のモデルだと考えられる。つまりMakerWorldは公開から3年3か月で約233万件に達し、2008年開設のThingiverse（約225万件）を件数で追い抜き、Printables（約138万件）の1.7倍規模になっている。この成長速度は、CipherFluteが「日用品に埋め込んだモデルを配布する」ことを想定するうえでの流通基盤の実勢を示す数字として使える。
- 検索語「whistle」の該当件数は、Printablesが1,150件、Cults3Dが836件、MakerWorldが2,021件であった（いずれも2026年7月30日の再確認値である。前回の調査時点ではCults3Dが838件、MakerWorldが2,018件であった）。MakerWorldについては、検索画面の表示が「モデル (999+)」で打ち切られるため、件数は基盤自身の内部APIである https://makerworld.com/api/v1/search-service/select/all?keyword=... が返す design.total の値を用いた。ただしこの値はあいまい一致を含む緩い数字であって、厳密な該当件数としては扱えない。同じ方法で「ocarina」は1,180件、「pan flute」は1,069件を返す一方、笛と無関係な「flute cipher」でも1,191件、「shamir secret sharing」でも1,266件、「acoustic barcode」でも1,238件を返すからである。Thingiverseは検索結果が「Showing 10,000 results」で打ち切られるため件数が取れなかった（この打ち切り表示も再確認した）。
- Bambu Lab社の規模については、Wikipedia英語版のBambu Labの項に、年間売上が15億人民元に迫るというEqualOceanの記事が出典として挙げられている（https://en.wikipedia.org/wiki/Bambu_Lab 、出典の題名は "Bambu Lab, Consumer-Grade 3D Printing Manufacturer, Nears CNY 1.5 Billion in Annual Revene"、参照日は2025年2月11日）。この15億人民元という数字は出典の題名に現れるものであって、Wikipediaの本文が「2024年の」年間売上と明記しているわけではない。二次資料であり、EqualOceanの原典まで当たれていない。
- 業界地図として、Thingiverseは2026年2月12日にMyMiniFactoryに買収された。Thingiverse自身のブログ記事「Thingiverse joins the MyMiniFactory family!」（Arun Chapman、2026年2月12日、https://www.thingiverse.com/blog?p=thingiverse-joins-the-myminifactory-family ）で確認した。同記事は「MyMiniFactory has acquired 100% of Thingiverse」と明記している。Printablesを運営するPrusa Research、MakerWorldを運営するBambu Labと合わせ、造形機メーカーが共有基盤を垂直統合する構図になっている。

---

## 新規性への脅威が大きい文献

脅威の大きい順に並べた。ここでいう「文献」は、実際に公開されているモデルのページ、付随するソフトウェア、および仕様文書である。

### 1. QR SafeShare — 秘密をShamirの秘密分散で分割し、各シェアを3Dプリント可能なQRコードとして書き出す道具

- 題名: QR SafeShare – Split and protect secrets in QR codes / QR SafeShare
- 著者: Jurgen（GitHubのアカウント名は cmd1982）
- 発表: GitHubリポジトリの最初のコミットが2025年9月11日、MakerWorldに2026年1月14日公開、Printablesに公開（2026年7月26日更新）、専用サイトを併設
- 確認先のURL:
  - https://makerworld.com/en/models/2244875-qr-safeshare （投稿者名Jurgen、作成日時2026-01-14、ダウンロード0件、いいね1件、造形プロファイル0件）
  - https://www.printables.com/model/1419250-qr-safeshare-split-and-protect-secrets-in-qr-codes （投稿者名Jurgen、2026年7月26日更新、いいね2件、ダウンロード6件、閲覧159件、ファイル4個）
  - https://qrsafeshare.com/ （道具の本体。「split secrets into offline QR fragments」と掲げる）
  - https://github.com/cmd1982/qr-safeshare （スター3件、ライセンスは "QR SafeShare License (Non-Commercial)"、コミット129件。GitHub APIで確認したところ、リポジトリ作成と最初のコミット "Initial commit" がいずれも2025年9月11日、最後のプッシュが2025年10月5日であった）
- 内容の要約: ブラウザ内で完結する道具であり、パスワードや暗号資産の復元用フレーズを複数のQRコードに分割する。分割方式としてShamirの秘密分散（例として3個作って2個で復元する構成）とXORによる2分の2分割を選べる。各シェアを3MFファイルとして書き出せるので、そのまま3Dプリントして完全にオフラインの耐久バックアップにできる。作者は自ら「CryptoSteelは頑丈だが、泥棒に見つかればフレーズ全体が即座に渡ってしまう」「物理バックアップを2つに割るのも安全ではない、半分ずつが既に部分情報を漏らすからだ」と既存手法の弱点を整理し、そのうえで秘密分散に安全性を負わせている。さらに「QR SafeShare Sleeve」という覆いを併せて印刷することを勧め、その理由を「本気の攻撃者は壊して開けられるが、覆いはその場での素早い、気づかれない走査を防ぎ、不正なアクセスに必要な労力を上げる」と説明している。
- CipherFluteとの関係: CipherFluteの脅威モデルの骨格、すなわち「物理層と符号層には暗号学的な秘匿の力はまったく無い」「秘匿はShamirの秘密分散やSLIP-39だけが担う」「物理層が担うのは探索コストの引き上げと正当な利用者の手軽さだけである」という3点を、この道具はすでにそのまま実装し、文章として明言している。運ぶ情報も同じく暗号資産の復元用フレーズである。異なるのは読み出し経路だけであり、こちらは光学的なQRコード、CipherFluteは吹いた音である。
- 脅威の度合い: 高。CipherFluteの応用上の主張「3Dプリント物を秘密分散のシェアの器にする」と、脅威モデルの主張「安全性は秘密分散に、物理層は探索コストの引き上げに」の両方が、すでに実物として存在してしまっている。CipherFluteはこれを必ず引用し、差分を「読み出しが音であること」「日用品への偽装で符号の存在そのものを隠せること」「電源も撮像装置も不要で人間の口と耳だけで読めること」に明確に絞り込む必要がある。時間的な前後関係については、最初のコミットが2025年9月11日であることを確認したので、WISS 2026に投稿するCipherFluteからみて明確に先行する研究外の実装として扱わなければならない。
- 検証の注記: 上に引用した4つの文言は、いずれもPrintablesのページ本文に原文で存在することを確かめた。原文は "A CryptoSteel is tough, but if a burglar finds it, they instantly have your entire phrase."、"Splitting a physical backup in two isn't secure either, because each half already exposes part of your phrase and you yourself are left knowing only half of it."、"While a determined attacker could force it open, the sleeve prevents quick or unnoticed scans and raises the effort required for unauthorized access."、および "Each QR code on its own is worthless." である。Shamirの秘密分散を3個のうち2個で復元する例、XORによる2分の2分割、3MFでの書き出し、覆い（Sleeve）の推奨も、すべてページ本文に記述がある。

### 2. SeedQRとCompactSeedQR、およびその3Dプリント用テンプレート — 復元用シードを機械可読な符号として物理媒体に載せる確立した規格

- 題名: SeedQR（およびCompactSeedQR）仕様、ならびに「21x21 Modular QR-Code for Seedsigner」「21x21 SeedQR template」
- 著者: SeedSignerプロジェクト（仕様）、happy（アカウント名は happyonion_1659843、Printablesのモデル）、arlm（Cults3Dのフォーク）
- 発表: 仕様はSeedSignerのリポジトリに文書化、Printablesのモデルは2024年3月18日更新、Cults3Dのフォークは2025年3月20日公開
- 確認先のURL:
  - https://github.com/SeedSigner/seedsigner/tree/dev/docs/seed_qr （README.md、img、printable_templates を含む。本文は https://raw.githubusercontent.com/SeedSigner/seedsigner/dev/docs/seed_qr/README.md で確認した）
  - https://www.printables.com/model/786967-21x21-modular-qr-code-for-seedsigner （いいね11件、ダウンロード90件、閲覧952件、ファイル3個）
  - https://cults3d.com/en/3d-model/various/21x21-seedqr-template （投稿者arlm、2025年3月20日、無料。作者自身が「an unchanged fork」すなわち上記Printablesのモデルの無改変のフォークであると書いている）
- 内容の要約: SeedQRは、BIP39の復元用フレーズをQRコードに載せるための最小化された符号化方式である。標準方式は各語をBIP39単語表の索引（0から2047）に直し、4桁のゼロ詰め十進数として連結してQRの数値モードで詰める。CompactSeedQRは索引を11ビット二進数に直してビット列として連結し、末尾のチェックサムに相当するビット（12語で4ビット、24語で8ビット）は数学的に導けるので省く。仕様書の原文は「The checksum is trivially calculated from the prior bits」と述べている。この圧縮により12語のシードは25×25から21×21へ、24語は29×29から25×25へ縮み、金属板に手で打刻する面積が12語で61パーセント、24語で65パーセントに減る、すなわち35から40パーセント減る。以上の数値はすべて仕様書の本文で裏を取った。3Dプリント用テンプレートは70×70×6mmの板である（Printablesのページに "Dimension Plate: 70x70x6mm" と明記されている）。なお題名にある「Modular」が具体的にどういう組み替えを指すのかは、ページの説明文には書かれていない。
- CipherFluteとの関係: 「128ビットの復元用情報を、最小の物理量で、機械可読な符号として物理媒体に固定する」という問題設定が完全に一致している。CipherFluteが13スロットの語彙で1本あたり約3.7ビットを運び、40本から49本で128ビットを運ぶという計算をしているのに対し、CompactSeedQRは11ビット×12語からチェックサムを引いて128ビットにするという同じ最適化を、すでに規格として済ませている。チェックサムを省いて後で導く発想も、CipherFluteの誤り訂正符号の設計と同じ土俵にある。
- 脅威の度合い: 高。CipherFluteの「符号としての情報量の設計」と「復元用シードを物理媒体に載せる」という部分は、この規格の前でほとんど新規性を主張できない。CipherFluteは、SeedQRが撮像装置を必要とし、また模様として見れば符号の存在が明白であることに対して、音による読み出しと日用品への偽装がどう違うのかを述べる必要がある。なおCipherFluteの現在の先行研究一覧にはSLIP-39とSSKRが入っているが、SeedQRは入っていない。この抜けは埋めるべきである。

### 3. Bitcoin binary seed storage（BIP39 12語）とBitCard — クレジットカード大の3Dプリント板に穴でシードを符号化し、偽装で探索コストを上げると明言した実装

- 題名: Bitcoin binary seed storage. BIP39 12 words. / Bitcoin BitCard. Seed storage 1248 card size.
- 著者: ErnestoFer
- 発表: Thingiverse、2024年10月28日
- 確認先のURL:
  - https://www.thingiverse.com/thing:6811428 （題名「Bitcoin binary seed storage. BIP39 12 words.」、公開日2024年10月28日、いいね1件、コメント2件、ファイル1個）
  - https://www.thingiverse.com/thing:6811420 （題名「Bitcoin BitCard. Seed storage 1248 card size.」、公開日2024年10月28日、いいね12件、コメント0件、ファイル1個）
- 内容の要約: クレジットカードと同じ寸法の3Dプリント板であり、釘などで穴を開けて記録する。前者は最大12語を二進数に直して記録し、後者は最大24語をBIP39の公式単語表（bitcoin/bips のenglish.txt）の索引に直して記録する。作者は用途を3点挙げている。第一に、樹脂製なので金属探知機に反応せず空港を通過できる。第二に、財布に入るので携帯できる。第三に、「これらのカードの目的は暗号の層をもう一枚重ねることであり、12語や24語が何を意味するか完全に分かっている者からビットコイン保有者を守ることである」。原文は "the purpose of these cards is to add an extra layer of encryption, protecting bitcoiners from individuals who fully understand what 12/24 words mean" である。金属板の欠点を論じたポッドキャスト（Renato Amoedo教授の発言）が着想の元だと述べている。なお後者の題名にある「1248」が1・2・4・8の重みを指すことは、題名からの推測であって説明文には明記されていない。
- CipherFluteとの関係: CipherFluteが物理層に負わせている役割、すなわち「日用品への偽装によって探索コストを上げる」という論法が、そのままの言葉で書かれている。また媒体の形状（クレジットカード大の薄板）も、CipherFluteのカード実装と一致している。異なるのは、読み出しが目視と手作業であり、笛のような能動的な発音を伴わない点である。
- 脅威の度合い: 中。CipherFluteの主要な主張である音による読み出しは無傷だが、「カード形状の3Dプリント物にシードを符号として刻み、偽装で探索コストを上げる」という発想の部分は先行している。引用して差分を述べる必要がある。

### 4. Whistle Pan Flute — 長さの異なるフィップル笛を一列に融合した、サポート材なしで印刷できるモデル

- 題名: Whistle Pan flute
- 著者: dp makes
- 発表: Printablesに2023年のPrintables「Musical Instruments」コンテストの応募作として公開（最終更新2024年11月18日、入賞作）、MakerWorldに2023年8月8日公開
- 確認先のURL:
  - https://makerworld.com/en/models/13026-whistle-pan-flute （作成日時2023-08-08、ダウンロード49,149件、いいね12,767件、印刷36,729件、造形プロファイル9種、コメント4,738件、コレクション登録34,557件）
  - https://www.printables.com/model/444168-whistle-pan-flute （いいね10,835件、ダウンロード表示は「48 k」、閲覧135千件、実作と書き込みの合計516件、コレクション登録11,614件、レビュー370件）
- 内容の要約: 作者は説明文で「長さの異なる笛をつないで一列にすることでパンフルートを作るという私の考えは、面白く創造的なものだと思う」「注意深く笛を選んで並べれば、従来のパンフルートより広い音域が得られるかもしれない」と述べている。原文は "I think my idea of creating a \"Whistle Pan flute\" by connecting whistles of different lengths in a line is an interesting and creative one." および "By carefully selecting and aligning the whistles, it may be possible to achieve a greater range of notes than a traditional pan flute." である。印刷設定はサポートなし、層厚0.2mm、インフィル15パーセントである。「このモデルは進行中であり、良いホイッスル・フルートの音が出るモデルになるまで調律を続ける」とも書いている。無断転載を受けたためライセンスを再配布禁止に変更したという注記もある。Printablesのページには「Awarded in the contest Musical Instruments」と表示されており、385件の応募のなかで入賞していることも確認した。
- CipherFluteとの関係: CipherFluteの物理形態、すなわち「複数のフィップル笛を長さを変えて融合し、サポート材なしで平置き印刷する一体物」という構成に最も近い先行実装である。ダウンロード数が両基盤合計で約9万7千件に達しており、無名の実験ではなく広く知られたモデルである。
- 脅威の度合い: 中。CipherFluteが物理形態そのものを新規性として主張するなら、この1件で大きく弱まる。ただしこのモデルは楽器であって、各管を符号のスロットとして読む設計は無く、調律も作者が「継続中」と述べる段階にとどまる。CipherFluteは「複数の笛を融合する」ことではなく「融合した笛の集合を半音刻みのスロット語彙として読み、基準笛で正規化し、誤り訂正を付ける」ことに新規性を置くべきである。

### 5. Flat Pocket Whistle — 厚さ3mmで財布に入る平板型フィップル笛、Printablesの笛カテゴリ最上位

- 題名: Flat Pocket Whistle
- 著者: Jonas Daehnert（Printablesのアカウント名は PhoneDesigner）
- 発表: Printables、2023年6月以降に段階的に更新（最終更新2026年3月28日）
- 確認先のURL: https://www.printables.com/model/495173-flat-pocket-whistle （いいね12,926件、ダウンロード97,000件、実作と書き込みの合計2,965件、閲覧227,000件、リミックス99件、コレクション登録14,231件、レビュー1,154件、評価4.9）。ページ上のタブ表示は「Makes & Comments 2,965」であり、2,965件は実作報告と書き込みを合算した数である。実作報告だけの件数はページ上では分離されていない。
- 内容の要約: 厚さ3mmで財布に入り、平板でありながら非常に大きな音が出ると説明されている。音については「明瞭な二重音である。寸法が小さいため音はかなり高いが、注意を引くには十分である」と述べ、音声サンプルを添付している。原文は "It has a clear double tone. Due to the size, the sound is quite high. But it is enough to get attention. An audio sample is attached." である。寸法は43×22×3mm、43×22×4mm、43×22×5mm、39×11.5×3mmの4種である。印刷はノズル0.4mm、層厚0.2mm以下、外周2本、サポートなしを推奨し、「上下の壁厚が0.6mmしかないので第一層が完璧であることが極めて重要である」と書いている。うまく鳴らない場合の対処として層厚と外周数の調整、上下ソリッド層を各5層以上にすることを挙げている。
- CipherFluteとの関係: CipherFluteの発音体は厚さ4mm、幅7mmであり、この平板型笛と同じ設計空間にある。0.6mmの薄壁が第一層の品質に強く依存するという記述は、CipherFluteのメモにある「0.5mm壁は実機で安定造形できず無音になる」という経験と一致し、薄壁フィップル笛の造形限界がコミュニティで共有された知識であることを示す。
- 脅威の度合い: 中。CipherFluteの「厚さ4mmの平板でサポートなしに鳴る笛を作った」という工作面の主張は、この先行実装の前では新規性を主張しにくい。背景として必ず引用し、CipherFluteの寄与は薄板化ではなく符号化にあると位置づけ直すべきである。

### 6. 周波数を明示した犬笛のシリーズ（4.2kHzから23kHzまで） — 目標周波数を狙って印刷し、スマートフォンで検証する実践

- 題名: Dog Whistle 7 kHz、10 kHz Dog Whistle、Ultrasonic Dog Whistle 21 kHz、Ultrasonic Dog Whistle 23 kHz、Dog Whistle 9 kHz、18 kHz Dog Whistle、Dog Whistle 4.2 kHz、First 3d printable Ultrasonic Whistle ほか
- 著者: ThreeD-Michael（Printablesのアカウント名は ThreeDMichael）
- 発表: Printables（7kHz版、10kHz版、23kHz版はいずれも2024年3月17日更新）およびMakerWorld
- 確認先のURL:
  - https://www.printables.com/model/808031-dog-whistle-7-khz （いいね638件、ダウンロード5,852件、閲覧13,000件、実作と書き込みの合計50件、レビュー35件、評価4.9）
  - https://www.printables.com/model/664240-10-khz-dog-whistle （いいね1,224件、ダウンロード9,376件、閲覧24千件、レビュー69件）
  - https://www.printables.com/model/732469-ultrasonic-dog-whistle-23-khz （いいね1,014件、ダウンロード13.3千件、閲覧26千件、レビュー68件、評価4.3）
  - https://makerworld.com/en/models/151111-ultrasonic-dog-whistle-23-khz （作成日時2024-01-21、ダウンロード18,185件、いいね2,316件、印刷15,438件）
  - https://www.printables.com/@ThreeDMichael/models （公開モデル76件。笛の系列として Dog Whistle 4.2 kHz、Long Range Dog Whistle 5.2 kHz／5.7 kHz／6.2 kHz、Dog Whistle 7 kHz、Dog Whistle 9 kHz、10 kHz から19 kHz までの各1kHz刻み、Ultrasonic Dog Whistle 21 kHz／22 kHz／23 kHz、First 3d printable Ultrasonic Whistle、Ultimate Referee Whistle、Loudest Emergency Whistle、Steam Train Whistle が並んでいることを一覧で確認した。すなわち周波数を明示した笛の下限は4.2kHz、上限は23kHzである）
- 内容の要約: 作者は「安定した周波数」を特徴として掲げ、犬ごとに反応する周波数が違うので音高の異なる一連の笛を用意したと説明している。印刷条件として線幅0.4mm、層厚0.2mm、上下6層を指定し、さらに「Zシームが笛の内部の狭い空気通路に来てはいけない」としてシーム位置を画像で指定し、Cura、PrusaSlicer、Bambu Studioでのシーム制御の設定名まで書いている。仕上げの鋭いエッジを得るために低速で印刷せよとも書く。周波数を確認したい人にはAndroidの測定アプリを案内している。23kHzのモデルでは「波長が短いため笛の内部の微細構造が0.4mmノズルの限界に達しており、すべてのプリンタでは動作しない」「22kHzでは多くのスマートフォンが録音できない」と限界を明示している。
- CipherFluteとの関係: 「目標周波数を決めて笛を設計し、印刷し、スマートフォンで実測して確認する」という作業ループが、すでにコミュニティの標準的な実践として成立していることを示す。CipherFluteが13スロットの半音刻みを設計するときの前提技術は、この水準の知識のうえに乗っている。またZシームの位置が空気通路を塞ぐという指摘は、CipherFluteが実機で遭遇する造形不良（固まった不良に対するインターリーブの必要性など）と同じ問題である。
- 脅威の度合い: 中。CipherFluteが「印刷した笛の周波数を設計で狙える」ことを寄与として挙げるなら、この一連のモデルが先行する。ただし単一周波数の設計であり、スロット語彙、基準笛による正規化、誤り訂正は無い。差分を述べるために引用すべきである。

### 7. TeleTunes Octo Tune Major Flute / Whistle (F#) と3Dprintableflutes.comのカタログ — 平置きサポートなしで音階が出る笛の商業的な系列

- 題名: TeleTunes Octo Tune Major Flute / Whistle (F#)（MakerWorld上の正式な題名にハイフンは無い。前回の記載「Octo-Tune」は誤りである）
- 著者: Tele Tunes（アカウント名は TeleTunes）
- 発表: MakerWorld、2024年5月22日
- 確認先のURL:
  - https://makerworld.com/en/models/471686-teletunes-octo-tune-major-flute-whistle-f （作成日時2024-05-22、ダウンロード31,371件、いいね5,314件、印刷27,313件、造形プロファイル8種、コメント2,777件）
  - https://www.3dprintableflutes.com/ （販売サイト。トップページで確認できたのは Best Sellers、Latest Flutes、Maker's Picks の各4件という抜粋の掲示だけであり、掲載総数は表示されていない）
- 内容の要約: 捻れた管を持つ縦笛であり、F#メジャーの音階が出る。作者は「指穴を造形板側にして平らに印刷し、サポートは一切要らない」と明記している。演奏はネイティブアメリカンフルートやペニーホイッスルに近く、端から順に穴を開けて音階を上げるが、管が捻れているため上3つの穴だけ順序が反転する。印刷上の注意として「管楽器の3Dプリントは難しく結果はばらつく。小さな不完全さや寸法誤差が最終結果に大きく影響する。同じ機械、同じ設定、同じフィラメントでも複数回の印刷で異なる結果になりうる」と率直に書いている。風道を研磨すると音が明瞭になりオーバーブローも容易になるが調律に影響するとも述べている。説明文の末尾で自身のサイトに「70本以上の印刷可能な笛のカタログ」があると案内している。
- CipherFluteとの関係: 「平置き、サポートなし、指穴を下向き」という印刷方針はCipherFluteと同じである。さらに「同一条件でも印刷ごとに結果がばらつく」という記述は、CipherFluteが基準笛による比読みを導入する動機（気温や息の強さだけでなく造形のばらつきも吸収する必要がある）を外部から裏づける。F#メジャーという調の選択が、CipherFluteのクリーン域F#6からF#7と偶然一致しているのも興味深い。
- 脅威の度合い: 中。音階が出る印刷笛の設計と、その調律の難しさに関する実務知識が先行しているため、CipherFluteは「音高を設計できる」ことではなく「音高のばらつきを基準笛と誤り訂正で工学的に押さえ込んだ」ことを寄与として立てる必要がある。

### 8. 多音笛の系列（12音、6音、4音、3音、8音） — 複数のフィップルを一体化して同時に鳴らすモデル群

- 題名と著者、確認先のURL:
  - Infinity Whistle!  12 Tone.  Extremely Loud Benchy（bloodVixen、2024年7月29日、ダウンロード13,985件、いいね3,589件、印刷10,128件）https://makerworld.com/en/models/562104-infinity-whistle-12-tone-extremely-loud-benchy
  - Super Loud 6 Tone Whistle - Thunderstorm V4（Chox、2026年7月1日、ダウンロード17,697件、いいね4,772件、印刷17,118件。公開から1か月足らずの新作であり、数字は日ごとに増えている）https://makerworld.com/en/models/2999228-super-loud-6-tone-whistle-thunderstorm-v4
  - Echo | 3 tone whistle（LetsMakeThings、2015年12月12日、いいね24,731件、実作134件、リミックス7件、書き込み169件）https://www.thingiverse.com/thing:1192426
  - Micro fischietto bitonale（ACstudio、2025年3月6日、ダウンロード20,483件、いいね3,927件、印刷15,475件）https://makerworld.com/en/models/1181642-small-two-tone-whistle 。MakerWorldに登録されている題名はイタリア語の「Micro fischietto bitonale」であり、英語圏の表示や短縮URLに現れる「Small Two Tone Whistle」は自動翻訳と短縮URLの側の表記である。
  - Eight whistles ( 8 grams of consumables required)（淘淘和小年糕、2025年5月12日、ダウンロード80件、いいね24件、印刷56件）https://makerworld.com/en/models/1408568-eight-whistles-8-grams-of-consumables-required
- 内容の要約: いずれも複数の共鳴室を一体に持ち、一度に吹いてすべてを同時に鳴らす設計である。12音のInfinity Whistleは「息子と一緒に、これまでで最も強烈なものを作った。12の別々の音、耳を貫くほど大きい」「サポートは不要である」と述べ、後継版では「壁を厚くし、3つのサイズを用意し、ポートを調律した（tuned ports）」と書いている。Echoは「3Dプリンタで最も大きな笛を作るという着想から始まった」もので、印刷は横倒しが最も大きく鳴るとし、サポートは不要である。8音のモデルも「サポート不要の超大音量」であり、超薄型笛の設計を発展させて8グラムで印刷できるとする。
- CipherFluteとの関係: 「複数のフィップルを一体化する」構造はすでに一般的である。ただし目的が音量と不快さの最大化であり、各音を個別に、順番に、独立した記号として鳴らす発想はどのモデルにも無い。CipherFluteの符号化はここを分岐点にしている。
- 脅威の度合い: 中。物理構造の新規性を弱める一方で、符号化の新規性を際立たせる。引用して「先行は同時発音による音量最大化であり、本研究は逐次発音による記号列である」と書き分けるべきである。

### 9. 半音階パンフルートと端補正の経験知 — 管長の理論値を実測で補正した記録

- 題名: Chromatic pan flute 7 Octave Customisable、Chromatic Pan Flute 4 octave Tunable、Chromatic DOUBLE BASS pan flute 4 octave Tunable、およびその原典 Chromatic Tenor Panflute
- 著者: AskMe（アカウント名は AskMe_221856、リミックス）、Caran（原典）
- 発表: Printables（7オクターブ版は2023年4月7日更新、4オクターブ版は2023年4月6日更新、いずれもPrintablesの「Musical Instruments」コンテストへの応募作）、Thingiverse（Caran版は2015年11月14日）
- 確認先のURL:
  - https://www.printables.com/model/442532-chromatic-pan-flute-7-octave-customisable （いいね54件、ダウンロード203件、閲覧1,565件、ファイル61個。更新日はページ上では April 7, 2023 と表示される。前回の記載「2023年4月8日更新」は1日ずれていた）
  - https://www.printables.com/model/139274-chromatic-pan-flute-4-octave-tunable （いいね26件、ダウンロード169件、閲覧1,297件、ファイル16個、更新日 April 6, 2023）
  - https://www.thingiverse.com/thing:1129462 （題名は「Chromatic Tenor Panflute」、著者Caran、2015年11月14日、いいね85件、書き込み4件、実作1件。説明文に "A chromatic panflute from C3 to C6" および "Prints without supports" とあることを確認した）
- 内容の要約: C2からC9までの半音階のパンフルートである。AskMeは原典の問題点を次のように記録している。「元のモデルには大きな問題があった。管は正確にその音になるように計算されていたが、高い音では高すぎて、下げる方向に調律できなかった。そこで全部の管に2cm足して直した」。原文は "The original had a major issue. The tubes where calculates to be exactly on the right note. But for the high ones they were too high and one cannot tune it down. So I have corrected the model by adding it 2 cm on all the tubes." である。調律は蜜蝋で行うと指示し（"You'll must tune it with bee wax!"）、音域ごとに必要なノズル径（C8からC9は0.4mm以下、C2からC3は1mm以上）を細かく書き分けている。原典のCaranのモデルはサポートなしで印刷でき、大きなプリンタが無ければ管を個別に印刷してエポキシで接着するという分割方法を示している。
- CipherFluteとの関係: 「管長から周波数を計算すると高音側で系統的にずれ、一律の補正が必要である」という現象を、コミュニティが実測で把握して対処している記録である。CipherFluteが f = A/(L+e) の e として定式化した端補正に対応する。またPrintablesの「Musical Instruments」コンテスト（2023年4月1日から5月31日23時59分まで、応募385件、1人あたり5件まで、https://www.printables.com/contest/368-musical-instruments ）は、印刷可能な楽器の設計が組織的に大量生産された場であり、印刷笛の技術水準を示す指標として使える。前回の記載では終了日を6月1日としていたが、コンテストのページは "April 1, 2023 – May 31, 2023 at 11:59 PM" と表示している。運営側は「すべての有効な応募作は演奏でき音が出なければならない。楽器に見えるだけで鳴らない玩具は求めない」と条件を明記している。
- 脅威の度合い: 中。CipherFluteの f = A/(L+e) は、この経験知を素直に定式化しただけと見なされる余地がある。CipherFluteは、単に補正するのではなく較正定数を実測で求め、13スロットを100セント刻みで安全に分離できることを検証した点に寄与を置くべきである。

---

## 背景として押さえるべき文献

脅威の度合いは低いが、CipherFluteの位置づけを説明するために有用な実物である。

- Loud Whistle（Federico、MakerWorld、作成日時2024-01-02、ダウンロード90,546件、いいね12,817件、印刷78,447件、https://makerworld.com/en/models/119995-loud-whistle ）は、120dBを謳う笛である。説明文には設計者の氏名としてFederico Franceschelliが記されている。今回確認したMakerWorldの笛のなかで最多のダウンロード数であるが、MakerWorldの検索はダウンロード数での並べ替えが効かず全件を通した順位が取れないため、「MakerWorldで最も普及した笛」と断定はできない。前回の記載はこの点で言い過ぎであった。いずれにせよ印刷笛が一般家庭で日常的に量産されている現実を示す。
- Mini Flat Whistle - Flat Design, Full Power（ACstudio、MakerWorld、作成日時2025-12-10、ダウンロード13,608件、いいね3,097件、https://makerworld.com/en/models/2099305-mini-flat-whistle-flat-design-full-power ）は、「財布に入れて邪魔にならないように、より平たく、より小さく」と明言する平板型笛であり、CipherFluteのカード実装と同じ携帯形態を狙っている。説明文はイタリア語であり、原文は "più piatto, più piccolo e con la stessa potenza! Pensato per poter essere inserito comodamente in un portafogli senza dare il minimo fastidio" である。作者は笛だけを集めたコレクション（https://makerworld.com/it/collections/5266584-whistles ）を運営している。
- Whistle Magic - create your own whistle - Your Whistle your Music（nischi、Thingiverse、2013年2月4日、いいね1.3千件、リミックス1,800件、実作26件、書き込み35件、https://www.thingiverse.com/thing:46825 ）は、OpenSCADによる媒介変数化された笛の生成器である。高さ、半径、内部の穴、内球を変えて「たくさんの違う音」を作れると書くが、音名や周波数との対応は与えていない。媒介変数化の系譜として引ける。前回は題名を「Whistle Magic - create your own whistle」と短く記していたが、正式な題名は上記のとおり後半まで続く。
- Recorder / Flute Musical Instrument（HumbleBee、MakerWorld、作成日時2025-02-25、ダウンロード9,328件、いいね2,529件、https://makerworld.com/en/models/1149042-recorder-flute-musical-instrument ）は、C管のバロック式ソプラノリコーダー（説明文ではPeripole Baroque Soprano recorder PB6000を範としたと述べている）を模したモデルであり、「作ったとおりでよく鳴り、すべての音が正しい音高で出る」と主張する。原文は "The 3D model as built plays great and all the notes come out at the right pitch and sound." である。印刷楽器が実用的な調律に達しうるという主張の例である。
- Native American Drone Flute（F#、A=432hz）（MakerWorldの投稿者はblackpixel、作成日時2025-06-04、ダウンロード4,205件、いいね1,154件、https://makerworld.com/en/models/1485827-native-american-drone-flute-f-a-432hz ）は、基準ピッチをA=432Hzと明記し、設計の主要な参考文献としてflutopedia.comを挙げている。「造形板から出た状態で調律されているはずだが、材料設定や穴径をいじる必要があるかもしれない」とも書かれている。ただし説明文は "From the original author:" と前置きして引用されており、blackpixelは再投稿者であって原設計者ではない。引用するときは原設計者が別人であることに注意が必要である。
- PANPIPES - PAN FLUTE（Savy_Maker、MakerWorld、作成日時2025-02-25、ダウンロード11,696件、いいね2,893件、https://makerworld.com/en/models/1148458-panpipes-pan-flute ）は、一体で全音が出ると謳い、サポート不要で速く印刷できるとする。原文は "With this little pan flute you can play all the notes. 1 PIECE NO SUPPORTS EASY AND FAST PRINT" である。
- Stimmbare Panflöte in C-Dur (2 Oktaven) C´-C´´´（g3d-Solutions、MakerWorld、作成日時2025-02-27、ダウンロード600件、いいね205件、https://makerworld.com/en/models/1157247-tunable-pan-flute-in-c-major-2-octaves-c-c ）は、ねじ込み栓と8×2の密封リングで各管の長さを最大5mm変えて精密に調律する仕組みを持つ。栓は6mmの六角レンチで回す。管は15本、音域はC´からC´´´である。物理的な後調律の実装例である。なおMakerWorldに登録されている題名はドイツ語であり、「Tunable pan flute in C major 2 octaves」は短縮URLと自動翻訳の側の表記である。
- 32-note pipe organ（Chrysibulum、MakerWorld、作成日時2025-12-23、ダウンロード609件、いいね414件、印刷103件、https://makerworld.com/en/models/2151850-32-note-pipe-organ ）は、G3からD6までの32鍵の本格的なパイプオルガンである。歴史的ピッチ（A415、A392、A466）に対応し、風圧の測定値（65mm、すなわち2 5/8インチ水柱で発音調整した）と単管の音圧（80から85dBA、和音では90dBAを超える）まで記録している。印刷部品数について説明文は「鍵盤に204点、ストップト・フルート管に158点、ストリング・プリンシパル管に139点」と別々に書いており、合計501点は当方が足した数である。印刷した気柱楽器の到達点として引ける。
- 音量のための多音笛はきわめて多い。実在を確かめた例として、Ultimative Trillerpfeife mit 3 Tönen（Scheggy、ダウンロード1,352件、https://makerworld.com/en/models/1066613 ）、超大声哨子、口哨、125 db三频、户外求生、带孔可挂绳（22min）（3D Miker、ダウンロード17,908件、https://makerworld.com/en/models/1617101 ）、双响口哨 超过130dB（Hung3d、ダウンロード791件、https://makerworld.com/en/models/2821933 ）、Low Pitch Dual-Frequency Whistle | 125dB+ | 1.7g（Radu | Design & 3D、https://makerworld.com/en/models/3007466 ）がある。いずれも音量のための多音であり、音高を情報として使わない。前回はこれらを「Ultimate Triller Whistle with 3 tones」「Super Loud Whistle 125 dB Triple Tone」「Dual Tone Whistle over 130dB」「Low pitch dual frequency whistle 125dB 1.7g」という英語の題名で挙げていたが、実際に登録されている題名はドイツ語や中国語であり、英語表記は自動翻訳を写したものであった。多音笛の題名を引用するときは、必ずモデルIDとともに原語の題名を書くべきである。
- 1880 "Secret" Whistle. Really Loud! Easy print :)（bloodVixen、MakerWorld、作成日時2026-05-18、ダウンロード14件、いいね10件、https://makerworld.com/en/models/2819109-1880-secret-whistle-really-loud-easy-print ）は、Popular Science Monthly第33巻（1888年6月）の記事「Whistles Ancient and Modern」に載った設計の再現である。「secret」の意味は「指で環を閉じないと可聴音が出ない」ことであり、情報の秘匿とは無関係である。原文は "The \"secret\" was that it produces no audible sound without the fingers closing the ring" である。題名は1880年としているが説明文の出典は1888年であり、作者自身の記述のなかで年が食い違っている。「秘密の笛」という語がすでに別の意味で使われていることを注意点として押さえておく価値がある。
- Pocket Whistle with secret compartment（H2Jack Concepts、MakerWorld、作成日時2026-02-04、ダウンロード457件、いいね345件、https://makerworld.com/en/models/2348284-pocket-whistle-with-secret-compartment ）は、笛と収納室を組み合わせた唯一の例だが、収納するのは薬（鎮痛剤、抗生物質、ビタミン、乳糖分解酵素の錠剤などを例示している）であり、情報を音高で運ぶ発想は無い。二重音で約118dBを謳う。
- QR Code Generator（SnaKKo、MakerWorld、作成日時2024-05-27、ダウンロード32,384件、いいね12,390件、https://makerworld.com/en/models/476280-qr-code-generator-qrcode-for-mail-wifi-ect ）は、OpenSCADでQRコードを立体化する媒介変数モデルであり、テキスト、Wi-Fi、電話、vCardの4種を扱える。印刷物に光学符号を載せる系譜の代表であり、ダウンロード数の大きさから「符号を印刷する」需要の規模が読める。
- Secure Snap Card - Bitcoin Seed/Passphrase Backup（BlackHawk、MakerWorld、作成日時2025-06-01、ダウンロード40件、いいね18件、https://makerworld.com/en/models/1475714-secure-snap-card-bitcoin-seed-passphrase-backup ）は、8.5cm×5.5cmのカードを封入し、開けるには物理的に壊すしかないという容器である。作者は「不透明な紙を挟むか黒フィラメントで印刷して透過を防げ」と助言する。改竄の痕跡が残ることを安全性の根拠にしている。原文は "Once sealed, the only way to open it is by physically breaking the case, providing clear evidence if it's ever been tampered with." である。
- Secret text / Password vault for one-time opening（JesseZhang、MakerWorld、作成日時2025-10-29、ダウンロード86件、いいね57件、https://makerworld.com/en/models/1936443-secret-text-password-vault-for-one-time-opening ）は、印刷を一時停止して付箋を挿入し、そのまま封止するカードである。核のコードを収めた「The Biscuit」に着想したと述べる。内部の収納空間は45mm×80mm×1.2mmで、付箋を3枚から4枚重ねられるとする。印刷過程そのものを封止手段に使う例である。
- Seed Phrase Keeper - Bitcoin Recovery Codebook（SRRN、MakerWorld、作成日時2025-01-24、ダウンロード121件、いいね61件、https://makerworld.com/en/models/1031732-seed-phrase-keeper-bitcoin-recovery-codebook ）は、シードを一度も計算機に入力せずに記録するための文字タイルの集合であり、Scrabbleの文字出現頻度に合わせてタイル枚数を割り振っている。作者自ら「火災で樹脂が溶ける」という弱点を挙げ、2部作って別の場所に保管せよと勧めている。文字は24行の溝にあり継ぎで差し込み、最後に外側のあり継ぎで閉じて改竄が分かる封をするとしている。
- Cults3Dの「seed phrase」検索で得られた15件（https://cults3d.com/en/search?q=seed+phrase ）は、打刻用の治具、Trezor用の容器、封止式の金庫が中心であり、符号として情報を刻むものはSeedQRのテンプレート2件、すなわち「21x21 SeedQR template」と「25x25 SeedQR template」だけであった。いずれも無料である。
- Thingiverseの秘密関連モデル群として、Corrugated Secret Sign（mathgrrl、thing:548191）、SimpleCrypt: Pocket Tube Cipher（enrohtkcalb、thing:2728148）、Caesar Cipher Decoder Ring Rounded（cymon、thing:14891）、Caesar Cipher Decoder Ring Flat（cymon、thing:18315）、Morse code keychain - FDM remix（MegaSaturnv、thing:3641800）などがある。いずれも人間が手で解く暗号の道具であり、機械可読な符号ではない。前回はシーザー暗号の輪とモールス符号のキーホルダーの題名を短く記していたが、正式な題名は上記のとおりである。
- Wallet Card Morse Code（danyelol、MakerWorld、作成日時2024-02-14、ダウンロード8,454件、いいね4,524件、https://makerworld.com/en/models/186023-wallet-card-morse-code ）は、モールス符号の一覧を刻んだ財布サイズのカードである。符号表を印刷物に載せる例だが、情報そのものは載っていない。
- Cryptocurrency-seed break card vault（Heigre、Thingiverse、2018年1月15日、いいね140件、書き込み5件、https://www.thingiverse.com/thing:2757112 ）は、暗号資産の12語または24語のシードを収めるための「割って開ける」カード容器である。作者は核ミサイルの発射認証カードを模したと述べ、Ledger Nano Sに同梱される空欄のカードが収まる寸法にしている。中身をアルミ箔で包めば透過光や放射線による読み取りを防げるとし、印刷を封止の数層前で一時停止してカードを差し込み、そのまま閉じるという手順を示す。「カード自体の盗難は防げないが、誰にも見られていないことを保証し、見られた場合は改竄の痕跡で分かる」と、安全性の根拠を改竄検知に置いている。CipherFluteの脅威モデルと同じく物理層に暗号学的な力を求めていない好例である。
- Thingiverseの古い多音笛として、Multi-tone Whistle（conanh、2012年1月21日、いいね583件、https://www.thingiverse.com/thing:16286 ）、Duo Tone Whistle（jipvanleeuwenstein、2014年10月12日、いいね4.8千件、https://www.thingiverse.com/thing:497948 ）、Whistle（Zaggo、2009年9月23日、いいね2.7千件、https://www.thingiverse.com/thing:1046 ）がある。説明文を読んだところ、調律に関する記述はどれにも無かった。conanhのものはFox 40という審判用の笛を印刷できる形に作り直したもので、目的は「二重音で内玉が無い」ことの再現であり、8回の試作を要したと述べている。Zaggoのものは内玉を笛の中に一緒に印刷して後で折り取る設計であり、2009年という最初期の印刷笛である。いずれも音高を情報として使わない。
- Bitcoin seed coin（PeteLaric、Thingiverse、2019年3月10日、いいね18件、https://www.thingiverse.com/thing:3481293 ）は、シードを刻んだ硬貨状の板である。ABSで印刷すれば数千年もつとし、失われた鋳型法で金属に鋳造する手順も案内する。「樹脂製なので地面に埋めても金属探知機に反応しない」と述べる点はErnestoFerのカードと同じ論法である。JustinSDKのモデルの改変であるとも書いている。媒介変数化されてはいるが、符号化するのは人間が読む文字であって幾何形状ではない。

---

## 未検証のまま残ったもの

2026年7月30日の検証で確認が済んだものは、この節から本文の各節へ移した。以下は現在も裏が取れていないものである。

- Cults3Dの「Recovery Phrase Sealed Vault」（Bitcoin edition と no markings edition を含む3件、いずれもJP¥235）、「Hashpack cold seed」（無料）、「Cold-Storage Display Altar - Coin & Backup Plate Stand」（JP¥817）は、検索結果の一覧に題名と価格が載っていることまでは確認した（https://cults3d.com/en/search?q=seed+phrase ）。個別ページの説明文は読んでいないため、内部の符号化方式や脅威モデルの記述は不明である。有料モデルであり、説明文の全文が公開されていない可能性もある。
- 3dprintableflutes.com が「70本以上の印刷可能な笛のカタログ」を持つという記述は、MakerWorld上のTeleTunesの説明文に "my 70+ printable flute cataloque at www.3Dprintableflutes.com" とあることまでは確認した。しかしサイト側のトップページには Best Sellers、Latest Flutes、Maker's Picks の各4件という抜粋しか出ておらず、掲載総数の表示は無い。70本という数はサイト側では裏が取れていない。
- Bambu Lab社の年間売上が15億人民元に迫るという数値は、Wikipedia英語版のBambu Labの項が出典として挙げるEqualOceanの記事の題名に現れるものである。Wikipediaの本文がこれを2024年の売上と明記しているわけではなく、EqualOceanの原典にも当たっていない。造形機の出荷台数や市場占有率については、公開されている一次資料を見つけられなかった。
- Cults3Dが自称する「3.5M designs」は検索窓のプレースホルダ表示で確認したが、この数がCults3D自身に投稿されたモデルのみを指すのか、他基盤の索引を含むのかは判別できていない。
- MakerWorldの登録利用者数、累計ダウンロード数、累計印刷数といった全体統計は取得できなかった。https://makerworld.com/about と https://makerworld.com/en/about はいずれもHTTP 404を返す（前回の記載はHTTP 403としていたが、再確認では404であった）。Bambu Labのブログにも該当記事が見つからなかった。
- MakerWorldの検索が返す design.total の値は、あいまい一致を含む緩い数字である。厳密な該当件数として引用してはならない。今回の再確認で、笛と何の関係も無い「flute cipher」で1,191件、「shamir secret sharing」で1,266件が返ることを実際に確かめた。この値は「該当件数」ではなく「関連度で並べたときの候補集合の大きさ」に近いものだと考えるべきである。
- Printablesのモデル総数約138万件は、サイトマップの最終ページ（p=1383）がちょうど1,000件で満杯だったため、実際にはもう少し多い可能性がある。
- 前回「Super Loud Whistle 125 dB Triple Tone」として挙げた多音笛については、3D Miker の「超大声哨子、口哨、125 db三频、户外求生、带孔可挂绳（22min）」（https://makerworld.com/en/models/1617101 ）が最も近い候補だと判断したが、自動翻訳を経た英語表記との対応が一対一に決まらないため、同一のモデルであると断定できていない。

---

## この切り口で見つからなかったこと

ここに書くことは、CipherFluteの新規性の主張の根拠になる。いずれも、4つの基盤の内部検索を英語の複数の語彙で繰り返し、該当が無いことを確認した結果である。

1. **笛の音高を符号として情報を運ぶモデルは1件も存在しない。** MakerWorldで「acoustic code」「sound password」「whistle password」「whistle secret」「binary whistle」「whistle bit」「encode sound」「acoustic barcode」「flute cipher」「audio data」の10通りの検索を行ったが、返ってきたのはすべて大音量の笛、QRコード、吸音パネル、暗号解読の玩具であった。この10語について今回あらためて件数を取り直したところ、いずれも1,191件から1,808件という値を返した。前述のとおりこれはあいまい一致による候補集合の大きさであって、語の意味に対応する該当件数ではない。したがってこの否定的な結論は件数ではなく、返ってきたモデルを目で見て確かめたことに依拠している。Printablesでも「whistle」1,150件の上位36件を個別に確認したが、情報を運ぶ設計は無かった。Thingiverseの「secret message」検索でも、出てきたのは箱、シーザー暗号の輪、モールス符号のキーホルダーであった。すなわち「吹いた音の高さを読んで少量の秘密情報を復元する」という提案は、モデル共有基盤上に前例が無い。

2. **多音笛はすべて同時発音であり、1本ずつ順に吹いて記号列として読むものは無い。** 12音、8音、6音、4音、3音、2音の笛をすべて確認したが、どれも一度に吹いて全部を鳴らす設計であり、目的は音量、不快さ、警報である。「音の並びで情報を表す」という語彙は、どの説明文にも現れなかった。

3. **音高が既知の基準笛を混ぜて他の笛を比で読むという発想は、どのモデルにも無い。** 調律のばらつきに対する対処として基盤上に存在するのは、蜜蝋を詰める、ねじ栓で管長を変える、風道を研磨する、全管に一律の補正長を足すといった物理的な後調律だけである。測定時の正規化という考え方は見当たらない。

4. **誤り訂正符号を印刷物の符号に適用したモデルは無い。** 印刷される符号としてはQRコードが圧倒的に多く、そのReed–Solomon符号はQRコードの規格に内蔵されているので作者は意識しない。符号の設計者自身が誤り訂正を選んで付けた例は見つからなかった。SeedQRのCompactSeedQRがチェックサムのビットを省くという判断をしているのが、最も近い設計上の言及である。

5. **秘密分散を3Dプリント物に適用した例は、QR SafeShareのただ1件である。** MakerWorldで「shamir secret sharing」を検索しても、隠し引き出しや秘密の本型金庫といった無関係な物理的隠匿しか返らない。Printablesで「shamir」を検索した結果は2件で、どちらも人名や作品名の偶然の一致であった。この2件は2026年7月30日に再確認しており、内訳は shamir waldmann という利用者名の投稿した「Cup coaster Amsterdam logo」と、Samir という語を含む「Samir Duel Em Stars Tower of Fantasy Cosplay Prop」である。すなわち「秘密分散のシェアを3Dプリント物として配る」という設計は、基盤上でまだ1件しか実装されていない、きわめて薄い領域である。CipherFluteはこの薄い領域の2件目に当たる。

6. **日用品に偽装した情報保管モデルは、隠し収納の系譜しかない。** 「secret compartment」「hidden message」の検索で出てくるのは、本型の金庫、隠し引き出し、パズルボックス、日本の秘密箱である。いずれも中に物を入れる空洞であり、物体そのものの形状や音に情報を符号化して偽装するものではない。物体の形状に情報を持たせつつ日用品として通用させるという設計は見つからなかった。

7. **笛を日用品に埋め込んで、笛であること自体を隠したモデルは無い。** 「hidden whistle」「whistle disguised」「whistle in object」「whistle business card」「whistle spool」「whistle bookmark」で検索したが、笛は常に笛の形をしていた。ジッパー引き手、指輪、キーホルダーに付ける例はあるが、いずれも笛だと分かる外観である。唯一の例外である「secret compartment付きのポケット笛」も、笛の姿をしたまま薬を入れる容器である。

8. **和音を出す笛を情報表現に使った例は無い。** MakerWorldの「chord whistle」検索で返るのは3音や2音の大音量笛であり、和音という語で意図されているのは音の厚みである。楽理的な和音を情報の単位として扱う設計は見当たらない。

---

## 調べ残した穴

- MakerWorldのコメント欄と「実作報告（Makes）」を読んでいない。作者の説明文には書かれない実測周波数や、鳴らなかった条件の報告がコメント欄に蓄積している可能性が高い。特にFlat Pocket Whistleは実作と書き込みを合わせて2,965件あり、薄壁の造形限界に関する集合知が眠っているはずである。MakerWorld側でも、Whistle Pan fluteに4,738件、TeleTunes Octo Tuneに2,777件のコメントが付いていることを確認した。CipherFluteが「実機で鳴る条件」を論じるときの外部証拠として価値がある。
- Printablesの「remix」の系統樹をたどっていない。Flat Pocket Whistleには99件、Whistle Magicには1,800件のリミックスがあり、そのなかに音高を制御する派生や符号化に近い派生が混ざっている可能性を排除できていない。
- MakerWorldの「Maker Lab」および媒介変数化モデル（Customizer）の一覧を調べていない。利用者が寸法を指定して生成する仕組みのなかに、音名を選べる笛の生成器があるかもしれない。
- 中国語での検索を行っていない。MakerWorldは中国語圏の投稿が多く（八音笛の作者も中国語で書いている）、「口哨」「哨子」「暗号」「助记词」などの語で検索すれば、英語では引っかからないモデルが出る可能性がある。日本語での検索も、MakerWorldの表示が自動翻訳であるため原文の語彙とずれており、十分に試せていない。
- MyMiniFactory自体を調べていない。担当範囲の4基盤に入っていなかったが、Thingiverseを買収した基盤であり、有料モデルの比率が高いため、暗号資産の保管に関する商業モデルが集まっている可能性がある。
- Bambu LabとMakerWorldの規模を示す公式な数字を取れていない。MakerWorldのabout ページはHTTP 404であり、認証を通したブラウザで開いても存在しない。造形機の出荷台数や市場占有率については、CONTEXTなどの市場調査会社の公表値を報じた記事に当たる必要がある。
- Printablesの「Musical Instruments」コンテスト（2023年4月1日から5月31日、応募385件）の応募作を全件見ていない。2か月間に集中的に投稿された印刷楽器の集合であり、音高設計に関する記述の宝庫である可能性が高い。入賞作の一覧では、Hex ukulele（Tomek）、Steel String Mandolin（LoboCNC）、Electric Hurdy-gurdy（demagnetized）が上位3件であり、笛の系統ではPortable Air Horn（Wim V）、HEXADIDG（L3V3C）、Dragon Recorder（P1lotz）、Whistle Pan flute（dp makes）が入賞していることまでを確認した。
- MakerWorldの検索結果はサーバ側で描画されるため、URLを取得するだけでは結果一覧が読めない。今回はブラウザで実際に描画させてからモデルIDを拾い、IDごとに design API を叩いて原語の題名を取るという手順をとった。この手順を使えば網羅性を上げられるが、全件の走査は行っていない。

---

## 検証の記録

2026年7月30日に、この文書の書誌情報を独立に検証した。検証は原著者とは別の担当者が、この文書に書かれた記述を一度も前提とせず、すべて一次資料に当たり直すという方針で行った。

検証の方法は次のとおりである。MakerWorldとPrintablesは通常のHTTP取得に対してHTTP 403を返すため、実際のブラウザでページを開いて描画結果を読むという手順をとった。Thingiverseは取得自体はできるが、いいね数や公開日を含む本体が後から描画される仕組みなので、これもブラウザで開いた。MakerWorldについては各モデルの一次データである https://makerworld.com/api/v1/design-service/design/{ID} を直接取得し、題名、投稿者名、作成日時、ダウンロード数、いいね数、印刷数、造形プロファイル数、説明文の原文を得た。Printablesについては各モデルのページの描画結果から同じ項目を得た。Thingiverseについては各thingのページを描画し、いいね数はボタンのtitle属性に入っている正確な整数を読んだ。基盤の規模はサイトマップを実際に取得して数え、GitHubはWeb画面とGitHubのAPIの両方を用いた。Cults3D、Wikipedia、qrsafeshare.com、3dprintableflutes.com は通常のHTTP取得で読めた。

確認した対象は72件である。内訳はPrintablesが14件（モデル9件、コンテストのページ1件、検索2件、サイトマップ1件、投稿者の一覧1件）、Thingiverseが18件（thing 15件、サイトマップ1件、ブログ記事1件、検索1件）、MakerWorldが31件（モデル28件、サイトマップ1件、検索の件数取得1件、aboutページ1件）、Cults3Dが4件、GitHubが2件、その他のサイトが3件である。

訂正は40か所に加えた。内訳は、事実の誤りが1件、題名の誤りが9件、日付の誤りが2件、数の読み方の誤解が2件、断定が強すぎる記述の緩和が5件、時間の経過で動いた数値の更新が19件、未検証の節への移動が2件である。主なものを挙げる。

第一に、明確な事実の誤りが1件あった。Thingiverseの thing:6811420 について「ダウンロード12件相当の表示」と書かれていたが、この12はいいね数である。Thingiverseはthingのページにダウンロード数を表示していない。ダウンロード数を根拠にした記述は成り立たないので、いいね12件、書き込み0件と直した。

第二に、題名の誤りを9件直した。MakerWorldの471686は「TeleTunes Octo-Tune Major Flute/Whistle (F#)」ではなく「TeleTunes Octo Tune Major Flute / Whistle (F#)」である。MakerWorldの1181642に登録されている題名はイタリア語の「Micro fischietto bitonale」であり、1157247はドイツ語の「Stimmbare Panflöte in C-Dur (2 Oktaven) C´-C´´´」であり、1148458は「PANPIPES - PAN FLUTE」である。英語の題名は自動翻訳と短縮URLの側の表記であった。Thingiverseの thing:46825、thing:14891、thing:18315、thing:3641800 についても、正式な題名がもっと長いことを確かめて直した。MakerWorldの2819109も、正式には「1880 "Secret" Whistle. Really Loud! Easy print :)」である。この種の誤りは、自動翻訳された画面を見て英語に訳し戻したときに生じたものだと考えられる。MakerWorldのモデルを引用するときは、必ずモデルIDを併記し、design APIが返す原語の題名を使うべきである。

第三に、日付の誤りを2件直した。Printablesの442532の更新日は2023年4月8日ではなく4月7日である。Printablesの「Musical Instruments」コンテストの終了日は2023年6月1日ではなく5月31日である。

第四に、数の読み方に関する誤解を2か所直した。Printablesのモデルのページに出る「Makes & Comments」の数は実作報告と書き込みの合計であり、実作報告だけの件数ではない。Flat Pocket Whistleの2,965件と Dog Whistle 7 kHz の50件がこれに当たる。

第五に、時間の経過で動いた数値を19か所更新した。いいね数、ダウンロード数、印刷数、閲覧数は日ごとに増えるので、前回の値と数件から数十件のずれがあった。たとえばEcho | 3 tone whistleのいいね数は「24,700件」と丸めて書かれていたが、実際の値は24,731件である。公開から1か月足らずのSuper Loud 6 Tone Whistle - Thunderstorm V4はダウンロード数が17,681件から17,697件へ、いいね数が4,767件から4,772件へ動いていた。この種のずれは誤りではないが、論文で数字を引くときは確認した日付を必ず添えるべきである。

第六に、断定が強すぎる記述を3か所ゆるめた。MakerWorldのLoud Whistleを「最も普及した笛」と断定していたが、MakerWorldの検索はダウンロード数での並べ替えが効かず全件の順位が取れないため、「確認した範囲で最多」という言い方に直した。MakerWorldの多音笛4件の英語の題名は自動翻訳を写したものであったため、原語の題名とモデルIDに置き換えた。Wikipedia英語版がBambu Labの2024年の年間売上を約15億人民元と「記述している」という書き方も、実際には出典として挙がっているEqualOceanの記事の題名に現れる数字であって本文の記述ではないため、正確な言い方に直した。

第七に、確認が済んで未検証の節から本文へ移したものが5件ある。Thingiverseの thing:2757112、thing:3481293、thing:16286、thing:497948、thing:1046 である。とくに thing:3481293 については「シードを幾何形状に符号化している可能性」が疑問として残されていたが、説明文を読んだ結果、符号化するのは人間が読む文字であって幾何形状ではないことが分かった。またQR SafeShareのGitHubリポジトリの最初のコミットが2025年9月11日であることが分かったので、時間的な前後関係の疑問も解消した。

第八に、逆に未検証の節へ移した記述が1件ある。前回「Super Loud Whistle 125 dB Triple Tone」として挙げた多音笛は、自動翻訳を経た英語表記との対応が一対一に決まらず、どのモデルを指すのか断定できなかった。またMakerWorldのaboutページの応答はHTTP 403ではなくHTTP 404であった。

実在が確認できず削除した文献は無い。この文書に挙げられた文献と事例は、モデルの題名や数値の細部に上記の誤りがあったものの、すべて実在することを確認できた。

検証で裏が取れた重要な数値は次のとおりである。SeedQR仕様の符号長（標準方式が12語で25×25、24語で29×29、CompactSeedQRが12語で21×21、24語で25×25、打刻面積が12語で61パーセント、24語で65パーセントに減る）は、SeedSignerのリポジトリのREADME.mdの本文と完全に一致した。基盤の規模（MakerWorld約233万件、Thingiverse約225万件、Printables約138万件）は、サイトマップを実際に数えて再現できた。Thingiverseが2026年2月12日にMyMiniFactoryに買収されたという記述は、Thingiverseのブログ記事の本文に "MyMiniFactory has acquired 100% of Thingiverse" とあることで裏が取れた。QR SafeShareの脅威モデルに関する4つの引用も、Printablesのページの原文と一致した。

残る不確かさとして最も大きいのは、MakerWorldの検索が返す件数の意味である。今回、笛と何の関係も無い語でも1,000件から2,000件が返ることを実測で確かめた。この文書の否定的な結論、すなわち「笛の音高を符号として情報を運ぶモデルは1件も無い」という主張は、件数ではなく実際に返ってきたモデルを目で確かめたことに依拠している。したがってこの主張の強さは、走査したモデルの件数がどれだけあったかに依存する。CipherFluteの論文でこの否定的な結論に触れるなら、「網羅的に検索したが無かった」ではなく「上位N件を目視で確かめたが無かった」という形で、確かめた範囲を明示して書くのが誠実である。

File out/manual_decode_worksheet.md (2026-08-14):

# 装置を用いない復号　実演の手順と書き取り表

論文4.4節「装置を用いない復号」を実測で書き直すための実演である。
第3の経路（照合笛だけで読む）を1回通し、所要時間と誤りの有無を記録する。

**答えは伏せてある。** 読み取った結果は、終わってから照合する。

---

## 用意するもの

- 崇徳院のかるた札のうち **上の句の札** 1枚（笛8本）
- 照合笛 1枚（12本、足の先に 0 から 11 の番号が抜き文字で刻んである）
- 紙と鉛筆
- 時計（開始と終了の時刻だけ記録する）

**電子機器は使わない。** スマートフォンも調律器も使わない。
照合笛は、吸込口のある辺を下へ向けて持つと、左から右へ音が高くなる。

---

## 手順

### 1. 向きを確かめる

札の端の1本目を吹き、照合笛の **4番** を吹く。同じ高さに聞こえれば、その端が先頭である。
違えば札を逆さに持ち、反対の端から吹く。

（1本目は基準笛で、両方の札に共通して同じ音が入っている。）

### 2. 8本を順に読む

先頭から順に、札の笛を1本吹く。続けて照合笛の番号を1つずつ吹き、
**うなりが消える番号**を探す。見つけた番号を下の表に書く。

判定のこつは、音程を当てようとしないことである。
2つの音が同じかどうかだけを聞く。ずれていれば「わんわん」と唸り、合えば唸りが消える。

### 3. 逆写像で記号にする

2本目から8本目までについて、次を計算する。

```
記号 ＝ （その本の番号 － 直前の本の番号 － 1） を 12 で割った余り
```

負の数になったら 12 を足す。下の早見表を使ってもよい。

---

## 書き取り表

開始時刻 ______ ： ______

| 何本目 | 照合笛の番号 | 直前の番号を引く | さらに1を引く | 12で割った余り＝記号 |
|:---:|:---:|:---:|:---:|:---:|
| 1（基準笛） |  | — | — | — |
| 2 |  |  |  |  |
| 3 |  |  |  |  |
| 4 |  |  |  |  |
| 5 |  |  |  |  |
| 6 |  |  |  |  |
| 7 |  |  |  |  |
| 8 |  |  |  |  |

終了時刻 ______ ： ______

**記号の列（2本目から8本目）** ： ___ ___ ___ ___ ___ ___ ___

最後の1つはパリティなので、秘密の断片は前の6つである。

### 余りの早見表

引いた結果が負のときは、この表で読み替える。

| 引いた結果 | −11 | −10 | −9 | −8 | −7 | −6 | −5 | −4 | −3 | −2 | −1 |
|:---:|:---:|:---:|:---:|:---:|:---:|:---:|:---:|:---:|:---:|:---:|:---:|
| 記号 | 1 | 2 | 3 | 4 | 5 | 6 | 7 | 8 | 9 | 10 | 11 |

0 から 10 はそのままである。11 が出たら隣り合う笛が同じ音になっており、
符号としてありえないので、どこかを読み違えている。

---

## あわせて記録していただきたいこと

- かかった時間（分）
- 迷った笛があれば、何本目か
- 照合笛を何本くらい試して当たりに着いたか（おおよそでよい）
- 鳴らせなかった笛があればその本数

## 余力があれば

下の句の札も同じ手順で読むと、2枚の断片から秘密そのものまで戻せる。
1枚で終えても、4.4節の主張（記号の列まで人手で読める）には足りる。

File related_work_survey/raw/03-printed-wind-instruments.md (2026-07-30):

# 3Dプリントされた笛と気鳴楽器の計算設計

調査担当の切り口は、3Dプリントやデジタルファブリケーションで笛やオカリナなどの気鳴楽器を設計・製造する研究である。狙った音の高さに合わせ込む計算設計、共鳴のシミュレーション、自由な形の物体を楽器にする研究、複数の音を出す構造の設計、印刷後の調律を重点的に洗い出した。書誌情報はすべてCrossrefのDOI解決結果、DataCite、DBLP、Semantic Scholar、学会の予稿集ページ、著者や研究所の公式ページ、CiNii Researchのいずれかで確認した。確認先のURLを各項目に付けた。

このファイルは2026年7月30日に別の担当者が独立に検証し直した。訂正した箇所には、何をどう直したかを本文中に明記した。検証の全体像は末尾の「検証の記録」にまとめてある。

出力ファイルの指定パスに `undefined` という未展開の変数が含まれていたため、既存の `related_work_survey/raw/` ディレクトリに書き出した。

## この切り口の要約

この分野で最も危険な先行研究は、SIGGRAPH Asia 2016のPrintoneである。任意の自由形状の内部を中空化し、境界要素法で共鳴周波数を予測しながらフィップル(リコーダーやオカリナと同じ吹き口)と指孔を配置し、家庭用のFDM方式3Dプリンタで印刷して実際に旋律を演奏させている。16本の楽器を作り、56個の目標周波数のうち53個が実測範囲に入ったと報告している。つまり「印刷できる笛の形を計算して狙った音高に合わせ、実機で検証する」という部分は10年前にすでに達成されている。現在のCipherFluteの引用一覧にPrintoneが入っていないことは、この切り口で見つかった最大の穴である。

音高精度をセント単位で報告した査読文献はきわめて少なく、NIME 2016のDabinらの微分音リコーダーがほぼ唯一である。彼らはPolyJet方式で印刷したリコーダーで、初版が目標に対して+6から+34セント、次版が−40から+1セント、指孔をやすりで手修正した版が−13から+14セントという結果を出し、目標として「5セント以内」を掲げている。これはCipherFluteが半音(100セント)刻みのスロットを選び、基準笛による較正を必要とした判断の妥当性を、外部の数値で裏づける材料になる。

計算設計の道具としては、Paul Harrisonのオープンソースソフトウェアdemakeinが2012年から公開されており、管の断面形状と指孔の位置・径・深さを数値最適化して狙った運指と音階を実現し、3DプリンタやCNCで作れる形に変換する。フランスのInriaのopenwindは、インピーダンスの計算と管形状の最適化に加えて、測定したインピーダンスから管形状を復元する逆問題まで扱う。したがって「管の長さと周波数の対応を計算して形を決める」ことも「音から形を推定する」ことも既存技術である。加えて、今回の検証で新たに見つかったLanとWalthamのActa Acustica united with Acustica論文(2016年)とLanの博士論文(2015年)は、伝達行列法で中国の縦笛「簫」を設計するものであり、CipherFluteの一次元の経験式 f = A/(L+e) に最も近い位置にある。境界要素法のPrintoneより、こちらのほうがモデルの性質としては近い。

複数の共鳴管を1つの3Dプリント物体にまとめること自体にも査読つきの先行例がある。Szabóの3Dプリントのパンフルート合奏体(Jazz Research Journal, 2024年)である。したがって「多数の笛を1つの物体に融合した前例がない」という言い方は避けたほうがよい。差分は融合そのものではなく、音高の並びを符号語として読む点にある。

一方で、印刷した笛の音高を符号として読み、複数本の音高の並びで情報を運ぶという発想は、この切り口の文献にはまったく見つからなかった。最も近いのはGraphics Interface 2018のBlowholeであるが、これは開管の共鳴ではなくヘルムホルツ共鳴を使う。ただしBlowholeの識別クラス数や正解率といった数値は、今回の検証では本文に到達できず裏を取れなかった。系列符号化も誤り訂正も基準音による較正も持たないという点は、公開されている題名と概要の水準では確かめられる。

## 新規性への脅威が大きい文献

### 1. Printone: Interactive Resonance Simulation for Free-form Print-wind Instrument Design

- 著者: Nobuyuki Umetani, Athina Panotopoulou, Ryan Schmidt, Emily Whiting
- 発表: ACM Transactions on Graphics, Vol. 35, No. 6, 論文番号184, pp. 184:1-184:14, 2016年11月(SIGGRAPH Asia 2016)
- 確認先: https://doi.org/10.1145/2980179.2980250 (Crossrefで著者・巻号・ページ・年を確認), https://www.research.autodesk.com/publications/printone-interactive-resonance-simulation-for-free-form-print-wind-instrument-design/ (著者4名と掲載誌を確認)
- 論文番号184の確認先: 下記ISMA 2017版の参考文献[1]に「ACM Trans. Graph., vol. 35, no. 6, pp. 184:1-184:14, Nov. 2016」と自己引用されている
- 短縮版の確認先: Nobuyuki Umetani, Athina Panotopoulou, Ryan Schmidt, Emily Whiting, "Printone: Interactive Resonance Simulation for Print-wind Instrument Design", Proceedings of the 2017 International Symposium on Musical Acoustics, 6月18日から22日, モントリオール, pp. 18-21, 2017年, https://isma2017.cirmmt.mcgill.ca/proceedings/pdf/ISMA_2017_paper_47.pdf (本文を取得し、以下の数値をすべて原文で確認した)

内容の要約は次のとおりである。任意の三次元メッシュを取り込み、自動で中空化したうえで、フィップル型の吹き口と指孔をユーザーが対話的に配置していく。共鳴周波数の予測は境界要素法にもとづき、共鳴を非線形行列の最小固有値問題として定式化し、波数について一次のテイラー展開を行って一般化固有値問題に帰着させることで高速化している。指孔の径を連続的に変えるあいだは感度解析による粗い一次近似で毎秒30フレーム以上の応答を保ち、待機中により正確な計算を数秒で回す。なおISMA 2017版は、道具全体の平均動作速度を毎秒5フレームと報告している。目標周波数を複数の運指について指定すると、指孔の径を自動最適化する「AutoTune」機能がある。吹き口はFDM方式で作りやすいという理由でフィップルを選んでおり、CipherFluteと同じ発音機構である。ISMA 2017版は「16本のうち5本を図に示す」と述べており、設計・印刷した楽器は16本である。検証では、吹く速さを徐々に上げながら明瞭に鳴る最低周波数と最高周波数を記録し、「56個の目標周波数のうち53個が実測範囲に入った(53 out of 56 target frequencies)」と報告している。音色は扱わず基本周波数だけを対象にしていることを明記している。

CipherFluteとの関係を述べる。CipherFluteが行っている「フィップル笛の形状を計算で決め、家庭用FDM機で印刷し、狙った音高が出ることを実機で確かめる」という工程は、Printoneがより一般的な形状に対してすでに達成している。CipherFluteの近似式 f = A/(L+e) は、Printoneの境界要素法と比べれば著しく単純な一次元モデルであり、精度で勝る主張はできない。逆にCipherFluteの独自性は、単一の楽器で旋律を演奏することではなく、多数の単音笛を1つの日用品に融合して音高の並びに情報を載せる点にある。

脅威の度合いは「高」である。理由は三つある。第一に、印刷された笛の計算設計という技術的貢献をほぼ完全に先取りしている。第二に、現在の論文がこの研究を引用していないため、査読者に「最も基本的な先行研究を知らない」と受け取られる危険がきわめて大きい。第三に、Printoneが目標周波数への合わせ込みを実機で検証しているため、CipherFluteの実測評価も同じ土俵で比較されることになる。必ず引用し、「旋律を奏でる1本の楽器」対「情報を運ぶ多数の単音笛」という違いと、対話的な自由形状設計を必要としない理由を明示すべきである。

### 2. Blowhole: Blowing-Activated Tags for Interactive 3D-Printed Models

- 著者: Carlos Tejada, Osamu Fujimoto, Zhiyuan Li, Daniel Ashbrook
- 発表: Proceedings of the 44th Graphics Interface Conference, トロント, 5月8日から11日, pp. 131-137, 2018年
- 確認先: https://doi.org/10.20380/GI2018.18 (DOIのコンテンツネゴシエーションで著者・題名・ページ・年・出版者を確認), https://dblp.org/rec/conf/graphicsinterface/TejadaF0A18.bib (会議の正式名称・開催地・会期・編者・出版者ACMを確認), https://api.semanticscholar.org/graph/v1/paper/DOI:10.20380/GI2018.18 (著者4名と年を確認)
- 注意: 予稿集ページ http://graphicsinterface.org/proceedings/gi2018/gi2018-18/ は2026年7月30日時点でCloudflareのボット判定によりHTTP 403を返し、本文にも概要にも到達できなかった。ACM Digital Libraryの当該ページも403であった。出版者の表記はDOI登録情報ではCanadian Human-Computer Communications Society、DBLPではACMとなっており、両方が流通している。

内容の要約は次のとおりである。3Dモデルの内部に共鳴空洞を埋め込み、表面の目立たない開口から軽く息を吹き込むと固有の音が鳴り、計算機がその音でどの穴かを同定する。ここまでは題名と、CipherFluteが現に引用している内容と一致する。

以下の数値は、前任の調査担当者が書いたものであるが、今回の検証では本文に到達できなかったため裏が取れていない。引用するなら本文を入手して確かめ直す必要がある。すなわち、空洞が球形で細い管で表面につながりヘルムホルツ共鳴の式で共鳴周波数を見積もること、管の長さ・管の径・球の径で周波数を作り分けること、FDM機3種とSLA機で試作しSLA印刷のほうが予測値に平均で約100ヘルツ近いこと、1000ヘルツ未満は雑音が多いこと、管が長いほど雑音が増えること、ある空洞集合で全体98パーセントの正解率を得たが32ミリメートルの球を加えると90パーセントに下がること、同時に扱える穴が最大9個程度であること、既存モデルへ自動で穴を埋め込むソフトウェアを提供していることである。

CipherFluteとの関係を述べる。「印刷物に吹き込んで、鳴った音の高さから計算機が意味を読み取る」という一次的な仕組みが共通する。ただし発音機構がヘルムホルツ共鳴であって管の共鳴ではなく、1個の穴が1個の識別子を表すだけで、複数の音の並びを符号語として扱う設計、誤り訂正、基準音による較正、秘密の保管という発想はいずれもない。容量の比較については、Blowholeの識別クラス数が9個であるという前提が未検証であるため、「9クラスで約3.2ビット」という対比はそのままでは書けない。CipherFlute側の13スロットで約3.7ビットという数値は自分の設計であるから確かである。差は本数を並べて系列にする点と、環境変動を打ち消す基準笛を混ぜる点にある。

脅威の度合いは「高」である。現行論文がすでに引用してはいるが、読み出しの一次的な仕組みが最も近いため、査読者は真っ先にこの研究との差分を問う。ヘルムホルツ共鳴と開管共鳴の違い、識別クラス数と系列長、較正の有無、誤り訂正の有無を書き分ける必要がある。そのためには本文の入手が前提になるので、大学図書館経由などで確実に手に入れてから数値を書くべきである。

### 3. Demakein: design and make instruments

- 著者: Paul Francis Harrison
- 発表: ソフトウェア(査読論文ではない)。最初の版0.1をPyPIに2012年9月28日公開、GitHubのリポジトリは2013年5月31日作成、バージョン1.1を2025年7月26日公開
- 確認先: http://www.logarithmic.net/pfh/design (作者・機能・組み込み楽器・バージョン1.1が2025年7月であることを確認), https://github.com/pfh/demakein , https://pypi.org/pypi/demakein/json (全リリースの公開日時を確認), https://api.github.com/repos/pfh/demakein (リポジトリ作成日を確認)
- 前任の記述にあった「2014年公開」は誤りである。2014年という数字は、Dabinら(NIME 2016)の参考文献[10]が本ソフトウェアを「2014」と付記して引用していることに由来すると推測される。それは参照した年であって公開年ではない。

内容の要約は次のとおりである。Pythonで書かれた木管楽器の設計・製造ツールである。公式ページは「Demakein is software to design and make woodwind instruments using a 3D printer or CNC mill.」と自ら説明している。「design」段階では、与えた運指と音階に対して正しい音が出るように、管の断面形状と指孔の位置・径・深さを数値最適化する。「make」段階では、設計を三次元形状に変換し、3DプリンタやCNCで作れる部品に分割する。フルート、ホイッスル(フィップル笛)、ショームが組み込みで用意され、Pythonスクリプトを書けば任意の音階や運指の楽器を設計できる。作者は2025年時点でBambu Lab P1SによるPLA印刷を試していると記し、壁のループ数を非常に多くすれば中実に近い楽器が得られると述べている。なお「音響モデルは管が枝分かれした木構造の共鳴周波数を求める形で組まれている」という前任の記述は、公式ページとGitHubのREADMEには対応する明示的な記載がなく、今回の検証では裏が取れなかった。

CipherFluteとの関係を述べる。「狙った音階になるように笛の寸法を計算し、3Dプリンタで作る」というワークフローそのものが、査読論文の外で10年以上前から公開・実用されている。CipherFluteが提示する管長と周波数の対応づけは、この道具が扱う設計問題の最も単純な部分集合にあたる。

脅威の度合いは「中」である。査読論文ではないため学術的な先行性の主張は弱いが、デジタルファブリケーションの査読者はこの道具を知っている可能性が高く、「計算で笛を設計する」ことを新規性として掲げると即座に反証される。背景として引用し、CipherFluteの貢献が設計計算ではなく符号化にあることを述べるのが安全である。

### 4. 3D Modelling and Printing of Microtonal Flutes

- 著者: Matthew Dabin, Terumi Narushima, Stephen Beirne, Christian Ritz, Kraig Grady
- 発表: Proceedings of the 16th International Conference on New Interfaces for Musical Expression (NIME 2016), pp. 286-290, 2016年7月11日から15日, グリフィス大学, ブリスベン
- 確認先: https://nime.org/proc/nime2016_dabin/ (著者5名・題名・年・開催地・ページを確認), https://www.nime.org/proceedings/2016/nime2016_paper0056.pdf (本文を取得し、以下のセント値と設計手法をすべて原文の表1と本文で確認した)

内容の要約は次のとおりである。微分音音階を演奏するためのリコーダーと横笛を3Dプリントで作る研究である。設計にはBenadeの理論をHoekjeがまとめた簡略モデルをMATLABに書き直したものを使い、指孔を1つ開けたときの実効管長と管端補正を求め、開いた孔と閉じた孔の補正を順に積み上げて、目標周波数を出す孔の位置と径を決める。モデルの出典は本文中で二つに分かれており、全体のモデルはHoekjeの音楽音響のウェブ教材(参考文献[12])、リコーダー1の吹き口の管端補正はHoekjeがCatgut Acoustical Society Journalにまとめた要約(参考文献[11])に拠っている。吹き口はまずFDM機(Dimension uPrintPlus、ABS、層厚0.254ミリメートル)で作ったが、ラビウム(エッジ)の望む鋭さが出ず、ボア内壁の粗さのために奏者はより高い吹圧を出さねばならず、安定した音を立ち上げるまでに市販のフルートより長い時間がかかった。そこでPolyJet方式(Objet Connex 350、材料Objet MED610、層厚0.016ミリメートル)に切り替え、市販のアルトリコーダーの吹き口と比べて音高も必要な吹圧もほとんど区別がつかない品質を得ている。評価では無響環境でBehringer ECM8000により録音し、Melodyneで音高を求め、第7から第12の下方倍音にあたる音階について目標周波数との差をセントで報告している。初版のリコーダー1は+6から+34セント、リコーダー2は−40から+1セント、指孔2つをやすりで削って手修正したリコーダー2改は−13から+14セントであった。将来目標として「手作業の修正が不要になるよう、誤差を5セント以内に抑える」ことを掲げている。同一設計を複数本印刷すると音高がそろうことも、下方倍音リコーダーを同一設計で対にして印刷することで確認している。

CipherFluteとの関係を述べる。CipherFluteが半音(100セント)刻みのスロットを採用し、基準笛で全体のずれを打ち消す設計を選んだ根拠として、この論文の数値はきわめて有用である。数十セント規模の誤差が印刷楽器では普通に生じるという外部の実測があるため、100セント刻みという粗い量子化とパイロット較正の必要性を正当化できる。逆に、「印刷した笛の音高をセント単位で評価する」という評価方法自体は新しくない。

脅威の度合いは「中」である。CipherFluteの主要な主張は崩れないが、この論文の存在を無視して「印刷した笛の音高精度を測った」ことを新規性に数えると弱くなる。必ず引用し、報告されたセント値と自分の実測値を並べて示すべきである。

### 5. FlueBricks: A Construction Kit of Flute-like Instruments for Acoustic Reasoning

- 著者: Bo-Yu Chen(国立台湾大学), Chiao-Wei Huang(独立研究者), Lung-Pan Cheng(国立台湾大学)
- 発表: Proceedings of the 2026 CHI Conference on Human Factors in Computing Systems (CHI '26), 4月13日から17日, バルセロナ, 全18ページ, 2026年
- 確認先: https://doi.org/10.1145/3772318.3790595 (Crossrefで著者・会議名・年・ページを確認), https://arxiv.org/abs/2604.03636 (2026年4月4日投稿、CHI 2026採録と明記), https://arxiv.org/pdf/2604.03636 (本文全18ページを取得し、以下の記述をすべて原文で確認した)

内容の要約は次のとおりである。フィップル笛を「生成部(generator)」「共鳴部(resonator)」「連結部(connector)」の3種のモジュール族に分解し、組み替えながら吹いて音を確かめることで、吹き込み穴の形、管長、指孔の位置が立ち上がり・音高・音色をどう変えるかを体得させる構築キットである。LeMoの分類を引き継ぎつつ、笛は胴と孔から放射するという理由で「放射部」を省き、代わりに連結部を加えている。全モジュールをFFF方式またはFDM方式(Ultimaker S3およびS5)で作り、剛体部分をPLA、可撓部分(窓の調整具や締めリング)をTPUで印刷し、基準の設定は層厚0.1ミリメートル、充填率20パーセントである。生成部は8種の下位モジュール(Air intake, Air duct support, Air deflector, Air facade, Window regulator, Splitting edge, Labium support, Labium base)に分解されており、これらはオルガンのフルー管とフルートの音響研究から抽出した6つの内部形状、すなわちフルー管路(flue tunnel)、空気室(air chamber)、風道(windway)、窓(window)、分割エッジ(splitting edge)、発音室(sound chamber)に対応づけられている。前任の記述はここに「調律スロット」を含めていたが、これは誤りである。調律スロット(tuning node)は共鳴部の側の別モジュールであり、オルガンのフルー管の調律スロットに着想を得て、円形の指孔を縦長のスロットに置き換えるものである。連結部には、1つの息を複数の出口へ分配する「Air distribution hub」があり、二重音や持続低音のような多声構成を作れる。12名の参加者による探索的な利用調査を行い、楽器の足場づくり(instrument scaffolding)、規則の形成(rule formation)、再解釈(reinterpretation)、演奏的行為(performative acts)という4つの振る舞いを報告している。目標周波数を計算して寸法を決める機能は持たず、情報を載せる発想も現れない。本文全体を検索したところ、encode、information、identify にあたる語は数回現れるが、いずれも図の色が頻度を表すこと、参加者が発見を物理的な構成として定着させたこと、被験者の属性情報、6つの内部形状を特定したことを指しており、情報を符号として物体に載せる意味では一度も使われていない。secret に相当する語は1度も現れない。

CipherFluteとの関係を述べる。同じ年に同じ「3Dプリントしたフィップル笛」を扱う最新のCHI論文であり、査読者が知っている可能性が高い。しかも本文中で「Printone [53] provides sophisticated resonance modeling, and Acoustic Voxels [29] optimizes resonator geometry via simulation」と、この分野の計算設計研究を明示的に位置づけている。CipherFluteは同じ土俵の上で、教育でも演奏でもなく情報保存を狙う点で区別できる。なお1つの息を複数の管へ分配する連結部が存在することは押さえておくべきである。CipherFluteは笛を1本ずつ順に吹いて読むので構成は異なるが、「1つの物体に複数の発音体を同居させる」という点だけは重なる。

脅威の度合いは「中」である。技術的な主張は重ならないが、直近の関連研究として引用しないと調査不足に見える。特に、この論文が引く計算設計研究(PrintoneとAcoustic Voxels)がCipherFluteの引用一覧と食い違っている点は目立つ。

### 6. Woodwind instrument design optimization based on impedance characteristics with geometric constraints / Full waveform inversion for bore reconstruction of woodwind-like instruments

- 著者: Augustin Ernoult, Christophe Vergez, Samy Missoum, Philippe Guillemain, Michael Jousserand(前者) / Augustin Ernoult, Juliette Chabassier, Samuel Rodriguez, Augustin Humeau(後者)
- 発表: The Journal of the Acoustical Society of America, Vol. 148, No. 5, pp. 2864-2877, 2020年 / Acta Acustica, Vol. 5, 論文番号47, 2021年
- 確認先: https://doi.org/10.1121/10.0002449 (Crossrefで著者5名・巻号・ページ・年を確認), https://doi.org/10.1051/aacus/2021038 (Crossrefで著者4名・巻・論文番号47・年を確認), 実装は https://openwind.inria.fr/ (InriaのMakutuチームによる開発であること、および1次元スペクトル有限要素法または伝達行列法によるインピーダンス計算、時間領域の音の合成、形状最適化、測定インピーダンスからの管形状復元を備えることを公式ページで確認)

内容の要約は次のとおりである。前者は、入力インピーダンスの共鳴周波数と振幅を目的関数に取り、円錐でない管形状や半径と煙突高さの異なる複数の側孔といった幾何的制約のもとで、木管楽器の形状を勾配法で最適化する枠組みを示している。小さな幾何変化でインピーダンスの特徴が大きく変わって勾配法が破綻する問題に対し、共鳴周波数と振幅の新しい定式化を導入している。後者は、測定した音響応答から管の内径分布を復元する完全波形逆解析を提示しており、音の測定から形状を推定する逆問題を扱う。両者の実装はInriaのopenwindとして公開され、インピーダンス計算、時間領域シミュレーション、管形状と側孔位置の最適化、測定インピーダンスからの管形状復元を備える。

CipherFluteとの関係を述べる。順問題(形状から音高)も逆問題(音から形状)も、木管楽器の分野では確立した計算技術である。とくに逆問題の存在は、CipherFluteが脅威モデルで宣言している「形状を計測されれば無音で読める」という主張を裏づけると同時に、「音を録るだけでも形状が推定できる」というより強い攻撃が理論上可能であることを示唆する。

脅威の度合いは「中」である。CipherFluteの符号化の主張は崩れないが、物理層に秘匿性がないという宣言を補強する根拠として引用する価値が高い。また「管長から周波数を求める計算は既存技術である」という位置づけを明確にできる。

### 7. Aerophones in Flatland: Interactive Wave Simulation of Wind Instruments

- 著者: Andrew Allen, Nikunj Raghuvanshi
- 発表: ACM Transactions on Graphics, Vol. 34, No. 4, pp. 1-11, 2015年7月27日(SIGGRAPH 2015)
- 確認先: https://doi.org/10.1145/2767001 (Crossrefで著者2名・巻号・ページ・年・所属Microsoft Researchを確認), https://www.microsoft.com/en-us/research/publication/aerophones-flatland-interactive-wave-simulation-wind-instruments/
- 注意: Crossrefに登録された題名は「Aerophones in flatland」であり、副題は登録されていない。副題を含む完全な題名は上記Microsoft Researchのページで確認した。

内容の要約は次のとおりである。二次元に落とした仮想の管楽器に対して、波動方程式を直接解くことで全帯域の音を実時間合成する手法である。市販のグラフィックスカード上で毎秒128000サンプルの音を合成し、リードや唇のような非線形の励振機構を二次元の波動場に結合できる。指孔の開閉や吹く圧力を利用者の入力で制御し、仮想演奏を実現している。物理製作ではなく音響合成が目的であり、印刷は扱わない。

CipherFluteとの関係を述べる。「管楽器の共鳴を計算機で解く」系譜の代表的な研究であり、Printoneと並べて計算音響の背景として引用できる。CipherFluteが波動シミュレーションを行わず経験式で済ませている選択の位置づけを説明するのに使える。

脅威の度合いは「中」である。情報符号化とは無関係だが、気鳴楽器の計算的取り扱いの代表例として引用しないと網羅性を欠く。

### 8. ProtoHole: Prototyping Interactive 3D Printed Objects Using Holes and Acoustic Sensing / FabAuth: Printed Objects Identification Using Resonant Properties of Their Inner Structures

- 著者: Shohei Katakura, Keita Watanabe(前者) / Yuki Kubo, Kana Eguchi, Ryosuke Aoki, Shigekuni Kondo, Shozo Azuma, Takuya Indo(後者)
- 発表: Extended Abstracts of the 2018 CHI Conference on Human Factors in Computing Systems, pp. 1-6, 2018年 / Extended Abstracts of the 2019 CHI Conference on Human Factors in Computing Systems, pp. 1-6, 2019年
- 確認先: https://doi.org/10.1145/3170427.3188471 (Crossrefで著者2名・掲載巻・ページ・年を確認。Crossrefの題名登録は「ProtoHole」のみで副題を含まない), https://doi.org/10.1145/3290607.3313005 (Crossrefで著者6名・掲載巻・ページ・年を確認。同様に題名登録は「FabAuth」のみ), https://api.semanticscholar.org/graph/v1/paper/DOI:10.1145/3290607.3313005 (FabAuthの副題を含む完全な題名と概要を確認)

内容の要約は次のとおりである。ProtoHoleは3Dプリント物体に穴を設け、音響センシングによって対話を実現するプロトタイピング手法である。ただしProtoHoleの概要はACM Digital LibraryもSemantic Scholarも取得できず、この一文は副題からの読み取りにとどまる。FabAuthについては概要を確認できた。同じ外観の物体でも内部構造を変えることで個体ごとに固有の共鳴特性を与え、物体を透過する振動を用いて、一方のセンサから他方のセンサへ伝わる音波の違いから個体を同定する。予備実験で低充填率の印刷物にも適用でき、平均識別精度は92.2パーセントであったと報告している。いずれも国内の研究者による短報であり、印刷物の内部空洞と音を結びつける点でBlowholeと同じ系譜に属する。

CipherFluteとの関係を述べる。印刷物の内部形状を音で読むという枠組みが共通する。ただしFabAuthは笛としての発音(エッジトーン)を使わず、加振器とセンサを物体に当てて透過振動を測る能動的な方式であり、人が息を吹くだけでは読めない。得られる情報量も個体同定にとどまる。

脅威の度合いは「中」である。国内会議・国際会議のいずれでも査読者が指摘しうる近接研究であり、少なくともFabAuthは「印刷物の内部構造に情報を持たせる」文脈で引用しておくべきである。

### 9. The titanium 3D-printed flute: New prospects of additive manufacturing for musical wind instruments design

- 著者: Anastasia Kolomiets, Yasha J. Grobman, Vladimir V. Popov, Evgeny Strokin, G. Senchikhin, Ezri Tarazi
- 発表: Journal of New Music Research, Vol. 50, No. 1, pp. 1-17, 2020年オンライン公開(2021年の巻号に収載)
- 確認先: https://doi.org/10.1080/09298215.2020.1824240 (Crossrefで著者6名・題名・巻号・ページ・年を確認), https://api.semanticscholar.org/graph/v1/paper/DOI:10.1080/09298215.2020.1824240 (概要の冒頭を確認), https://doi.org/10.1007/s42452-021-04170-x (Damodaranらの総説が参考文献[26]としてこの論文を引用し、造形方式と特徴を要約している)

内容の要約は次のとおりである。概要は「チタン合金の積層造形は医療・航空・宇宙の特注部品に用いられているが、管楽器の分野では試みがなかった。本事例研究はチタン製フルートの設計と3Dプリントに焦点を当てる」と述べている。造形方式は電子ビーム溶融(EBM)である。ここまでは確認できた。

前任の記述には二つの誤りがあったので訂正する。第一に、対象楽器は「リコーダー型の笛」ではなくフルートである。概要と総説の記述はいずれも flute としており、フィップル笛であるとは書かれていない。第二に、「得られた笛の音響的な振る舞いが従来の金属製フルートに近いと報告している」という要約は裏が取れなかった。Taylor & Francisの本文ページは2026年7月30日時点でHTTP 403を返し、本文に到達できていない。総説が要約している範囲では、この研究の特徴として革新的な設計、生体適合性の高さ、著しく豊かな楽音、長い寿命、硬さ、設計変更の容易さ、シロアリに食われないことが挙げられ、さらに外気温や湿度の変化によって音質が影響を受けないと述べられている。「従来の金属製フルートに近い」ではなく「著しく豊かな音」とされている点は、要約の向きが逆である。また「印刷後の後処理や壁の気密性の課題を扱い」という記述も本文未確認である。

CipherFluteとの関係を述べる。CipherFluteは長期保管の観点から樹脂から金属への展開を将来課題に挙げているため、金属積層造形で笛が実際に鳴ることを示したこの研究は、その将来展望の根拠になる。加えて、総説が伝える「外気温や湿度で音質が変わらない」という主張は、CipherFluteが基準笛による較正を導入した理由と正面から関わるので、本文を入手して真意を確かめる価値が高い。

脅威の度合いは「中」である。符号化とは無関係だが、金属化の実現可能性を語るときに引用が必要になる。

### 10. 3D printing of police whistles for STEM education

- 著者: Masato Makino, Kodai Suzuki, Kyuichiro Takamatsu, Atsuki Shiratori, Azusa Saito, Kazuyuki Sakai, Hidemitsu Furukawa
- 発表: Microsystem Technologies, Vol. 24, No. 1, pp. 745-748, 2017年オンライン公開(2018年の巻号に収載)
- 確認先: https://doi.org/10.1007/s00542-017-3393-x (Crossrefで著者7名・題名・巻号・ページ・年を確認), https://doi.org/10.1007/s42452-021-04170-x (Damodaranらの総説の参考文献[21]としてこの論文が引用され、内容が要約されている。以下の要約はその総説の本文で裏を取った)
- 注意: Springerの本文ページはリダイレクト先の認証画面に飛ぶため、本文そのものには到達できていない。以下の内容はDamodaranらの総説による要約に依拠する。

内容の要約は次のとおりである。山形大学のグループが高校生を対象に、3D CADで警笛(いわゆるホイッスル)を設計し、FDM方式で印刷して機能を検証する教育実践を報告している。総説は「さまざまな設計パラメータのうち、笛の半径が周波数に有意に影響した」と述べ、さらに「高校生が笛の中の空気の循環量が周波数にどう効くかを予測できたことは興味深い」と続けている。前任の記述はこの2点をほぼ正確に写しており、訂正の必要はなかった。

CipherFluteとの関係を述べる。3Dプリントした笛の寸法と周波数の関係を扱った、査読つきの数少ない例である。ただし目標周波数への合わせ込みや情報の符号化はなく、教育実践の報告にとどまる。

脅威の度合いは「中」である。CipherFluteの主張を脅かさないが、「印刷した笛の寸法と音高の関係」という最も基本的な部分の先行例として押さえておく必要がある。

### 11. Acoustic Modeling and Optimization of the Xiao / Acoustics of the xiao: a case study of modern methods for the design of woodwind instruments

- 著者: Y. Lan, C. E. Waltham(前者。Crossrefの登録がイニシャル表記であるため、名を勝手に展開せずそのまま記す) / Yang Lan(後者。DataCiteに「Lan, Yang」と登録されている)
- 発表: Acta Acustica united with Acustica, Vol. 102, No. 6, pp. 1128-1137, 2016年 / ブリティッシュコロンビア大学 博士論文, 2015年
- 確認先: https://doi.org/10.3813/aaa.919024 (Crossrefで著者2名・題名・巻号・ページ・年を確認), https://doi.org/10.14288/1.0167080 (DataCiteで著者名Lan, Yang・題名・大学名・年・概要を確認。ハンドルは 2429/51768)
- この2件は、前任の調査では「未検証のまま残ったもの」に置かれていた。今回の検証で両方とも実在を確認し、あわせて査読誌の論文の存在も新たに見つけたので、この節に移した。前任の記述にあった著者名「Yuan Lan」は誤りである。正しくは Yang Lan である。Dabinらの参考文献[13]が「Y. Lan」と略記していたため、名を取り違えたものと推測される。

内容の要約は次のとおりである。博士論文の概要は次のように述べる。尺八の近縁にあたる中国の縦笛「簫」は千年を超える歴史を持ちながら、竹の形状が一定しないために標準化や現代的な要求への適応が進んでおらず、調律、音域、音の安定性、高音の演奏性に不備がある。音響学の立場ではこれらの不備はすべて音響インピーダンスによって特徴づけられる。設計手法については、Dabinらが本文中で「伝達行列法は中国の簫(笛)の特性のモデル化にも使われている」と述べて参考文献[13]、すなわちこの博士論文を引用しており、伝達行列法にもとづく設計であることは外部の記述で裏が取れる。査読誌版は題名のとおり簫のインピーダンスのモデル化と最適化を扱うが、概要が公開されていないため中身は未確認である。

CipherFluteとの関係を述べる。CipherFluteの近似式 f = A/(L+e) は一次元の経験モデルであり、簫の研究が用いる伝達行列法は同じ一次元の枠組みのなかで管の断面変化と側孔を厳密に扱うものである。すなわちCipherFluteの管長と周波数の対応づけは、この系譜の最も単純な特別な場合にあたる。しかも簫は縦笛であってCipherFluteに形が近い。

脅威の度合いは「中」である。CipherFluteの符号化の主張は崩れないが、「管長から周波数を予測する一次元モデル」の先行研究として、Printoneの境界要素法よりむしろ近い位置にある。設計計算の新規性を主張しないことを明示する材料として引用するのが安全である。

### 12. Walrus Pipes and Waving Panpipes: 3D printed instrument designs for speculative community music

- 著者: Bálint Szabó
- 発表: Jazz Research Journal, Vol. 17, No. 1-2, pp. 193-222, 2024年11月28日
- 確認先: https://doi.org/10.1558/jazz.28243 (Crossrefで著者・題名・副題・掲載誌・巻号・ページ・年・概要を確認)
- この文献は、前任の調査では掲載誌のページがHTTP 402を返したため「未検証のまま残ったもの」に置かれていた。今回、CrossrefのAPIで書誌情報と概要を完全に取得できたので、この節に移した。なお掲載誌の記事ページ https://journal.equinoxpub.com/JAZZ/article/view/28243 は2026年7月30日時点でHTTP 403を返す。

内容の要約は次のとおりである。概要は、大量生産された西洋の楽器が名人の技巧に奉仕し単一の標準的な調律しか鳴らさないのに対し、この3Dプリント管楽器の企画はその対位法をなすと述べる。作られる楽器は単純で特注であり、合奏として共同で吹くことに奉仕する。論文は企画で開発された2つの3Dプリント管楽器の合奏体、すなわち Walrus Pipes と Waving Panpipes の設計過程の全体を明かす。パンフルートは複数の管を1つの物体に並べた楽器である。

CipherFluteとの関係を述べる。「複数の共鳴管を1つの3Dプリント物体にまとめる」という構成の、査読つきの先行例である。ただし目的は共同での音楽演奏であり、音高の並びを符号語として読む発想はない。CipherFluteが「多数の単音笛を融合する」構成そのものは前例がないと主張するなら、パンフルート型の印刷楽器がすでに査読文献にあることを認めた上で、符号として読む点に絞って差分を述べる必要がある。

脅威の度合いは「中」である。技術的な主張は重ならないが、「複数の共鳴管を1つの印刷物にまとめた前例はない」と書いてしまうと即座に反証されるため、引用して差分を述べる必要がある。なお概要までは確認したが本文は未読であり、管の数や調律の決め方は確かめていない。

## 背景として押さえるべき文献

以下は脅威の度合いが「低」であり、背景として引用する程度でよいものである。

- Amit Zoran, "The 3D Printed Flute: Digital Fabrication and Design of Musical Instruments", Journal of New Music Research, Vol. 40, No. 4, pp. 379-387, 2011年。https://doi.org/10.1080/09298215.2011.621541 (Crossrefで著者・題名・巻号・ページ・年を確認)。FDM方式(ABS)とPolyJet方式でコンサートフルートの複製を作った先駆的な事例である。前任の記述は「本文を通読した」としていたが、今回の検証ではTaylor & Francisの本文ページがHTTP 403を返し、Crossrefにも概要が登録されておらず、本文には到達できなかった。したがって「計算による音響設計は行っておらず、セント単位の音高精度の測定も報告していない」という主張は本文で裏を取れていない。ただしDabinら(NIME 2016)がこの論文を引用して「Zoranは3Dプリントでコンサートフルートの複製を作れることを示したが、壁の水密性と材料の劣化に問題があり、楽器として使えるものにはならなかった」と述べており、造形の限界に関する部分は外部の記述で裏が取れる。この点はCipherFluteが薄壁で苦労した経験と対応する。
- Nicholas J. Bailey, Théo Cremel, Alexander South, "Using Acoustic Modelling to Design and Print a Microtonal Clarinet", Proceedings of the 9th International Conference on Interdisciplinary Musicology (CIM14), ベルリン, 2014年12月4日から6日。https://eprints.gla.ac.uk/124083/ (グラスゴー大学の機関リポジトリで著者3名・題名・会議名・開催地・会期を確認)。前任の記述は会議名を「9th Conference on Interdisciplinary Musicology」としていたが、正式には「9th International Conference on Interdisciplinary Musicology」であり、International が抜けていたので補った。C++でオブジェクト指向の音響モデルを作り、OpenSCADで楽器形状を記述して19平均律のクラリネットを印刷し、プロ奏者が評価しているという内容の要約は、本文未取得のため裏が取れていない。
- Christian Ritz, Matthew Dabin, Terumi Narushima, Kraig Grady, Stephen Beirne, "3D printing for custom design and manufacture of microtonal flutes", SPIE Newsroom, 2015年。https://doi.org/10.1117/2.1201508.006082 (Crossrefで著者5名・題名・掲載媒体・年を確認。巻号とページは登録されていない)。上記NIME 2016論文の一般向け短報である。
- Openwind(Inria Makutuチーム)。https://openwind.inria.fr/ (公式ページでチーム名と機能一覧を確認)。管楽器のインピーダンス計算(1次元スペクトル有限要素法または伝達行列法)、リードや唇を管口に結合した時間領域の音の合成、管形状と側孔位置の最適化、測定インピーダンスからの管形状復元をまとめたPythonライブラリである。
- Dingzeyu Li, David I. W. Levin, Wojciech Matusik, Changxi Zheng, "Acoustic Voxels: Computational Optimization of Modular Acoustic Filters", ACM Transactions on Graphics, Vol. 35, No. 4, pp. 1-12, 2016年。https://doi.org/10.1145/2897824.2925960 。すでに現行論文が引用している。共鳴体を組み合わせて伝達関数を設計する研究であり、気鳴楽器の計算設計の隣接領域として位置づけられる。
- Gaurav Bharaj, David I. W. Levin, James Tompkin, Yun Fei, Hanspeter Pfister, Wojciech Matusik, Changxi Zheng, "Computational Design of Metallophone Contact Sounds", ACM Transactions on Graphics, Vol. 34, No. 6, pp. 1-13, 2015年。https://doi.org/10.1145/2816795.2818108 。打楽器(体鳴楽器)の形状を目標周波数と振幅に合わせて最適化する研究である。気鳴ではないが「目標音高に合わせる形状最適化」の代表例である。
- Soizic Terrien, Christophe Vergez, Benoît Fabre, "Flute-like musical instruments: A toy model investigated through numerical continuation", Journal of Sound and Vibration, Vol. 332, No. 15, pp. 3833-3848, 2013年。https://doi.org/10.1016/j.jsv.2013.01.041 。フルート型楽器の発振を数値接続法で解析する物理モデル研究である。
- Péter Rucz, Fülöp Augusztinovicz, Judit Angster, Tim Preukschat, András Miklós, "Acoustic behavior of tuning slots of labial organ pipes", The Journal of the Acoustical Society of America, Vol. 135, No. 5, pp. 3056-3065, 2014年。https://doi.org/10.1121/1.4869679 。同じ著者らによる有限要素モデルの続報が The Journal of the Acoustical Society of America, Vol. 137, No. 3, pp. 1226-1237, 2015年(https://doi.org/10.1121/1.4913460)にある。製造後の調律を目的とした調律スロットの音響を扱っており、印刷後の調律を論じるときの理論的背景になる。
- Taizo Kobayashi, Toshiya Takami, Masataka Miyamoto, Kin'ya Takahashi, Akira Nishida, Mutsumi Aoyagi, "3D Calculation with Compressible LES for Sound Vibration of Ocarina", arXiv:0911.3567, 2009年11月18日投稿。https://arxiv.org/abs/0911.3567 (arXivで著者6名・題名・投稿日・概要を確認)。オカリナをエッジトーンとヘルムホルツ共鳴器の結合系とみなし、圧縮性大渦解法で二次元および三次元の数値解析を行っている。arXivの注記によれば全8ページで、Open Source CFD International Conference 2009 で発表されたものである。
- Sho Iwagami, Ryoya Tabata, Taizo Kobayashi, Yuji Hattori, Kin'ya Takahashi, "Numerical study on edge tone with compressible direct numerical simulation: Sound intensity and jet motion", International Journal of Aeroacoustics, Vol. 20, No. 3-4, pp. 283-316, 2021年。https://doi.org/10.1177/1475472X211003296 (Crossrefで著者5名・題名・巻号・ページ・年を確認)。フィップル笛の発音の中核であるエッジトーンの直接数値計算である。
- Shengze Zhong, Parinya Punpongsanon, Daisuke Iwai, Kosuke Sato, "Estimation of fused-filament-fabrication structural vibro-acoustic performance by modal impact sound", Computers & Graphics, Vol. 115, pp. 137-147, 2023年。https://doi.org/10.1016/j.cag.2023.07.010 (Crossrefで著者4名・題名・巻・ページ・年を確認。前任の記述に欠けていた第115巻を補った)。FDM印刷物の振動音響特性を打音から推定する研究であり、印刷物と音の関係を扱う近年の例である。
- Ajith Damodaran, M. Sugavaneswaran, Larry Lessard, "An overview of additive manufacturing technologies for musical wind instruments", SN Applied Sciences, Vol. 3, No. 2, 論文番号162, 2021年1月20日。https://doi.org/10.1007/s42452-021-04170-x (Crossrefで著者3名・題名・巻号・論文番号・年を確認。オープンアクセスの本文PDFを取得して全文を検索した)。管楽器の積層造形に関する体系的総説である。全文検索により、音高精度をセント単位で示した記述はないこと、Printone(参考文献[35])、Dabinら(同[36])、Ritzら(同[37])、Makinoらの警笛(同[21])、Zoran(同[20])、Avanziniら(同[38])、Kolomietsらのチタン製フルート(同[26])をいずれも紹介していることを確認した。前任の要約は正確であった。
- Antreas Kantaros, Olaf Diegel, "3D printing technology in musical instrument research: reviewing the potential", Rapid Prototyping Journal, Vol. 24, No. 9, pp. 1511-1523, 2018年。https://doi.org/10.1108/RPJ-05-2017-0095 (Crossrefで著者2名・題名・巻号・ページ・年・概要を確認)。概要によれば、楽器への積層造形の応用史を文献調査でたどり、従来の製法では作れない全く新しい管楽器を作れるかを問うものである。既存楽器の意匠を独自にする用途では広く使われているが、まったく新しい音を作る本来の潜在力はほとんど未開拓であると結論している。
- Robert Howe, Sina Shahbazmohamadi, Richard Bass, Prabhjot Singh, "Digital evaluation and replication of period wind instruments: the role of micro-computed tomography and additive manufacturing", Early Music, Vol. 42, No. 4, pp. 529-536, 2014年。https://doi.org/10.1093/em/cau091 (Crossrefで著者4名・題名・巻・号・ページ・年を確認。前任の記述に欠けていた第4号を補った)。歴史的管楽器をマイクロX線CTで計測して積層造形で複製する研究である。CipherFluteの脅威モデル(形状の計測による無音の読み出し)に対して、CTで内部形状を取れることを示す実例として引用できる。
- Javier Esclapés, Almudena Gómez, Ana Ibañez, "Flow. A Socially Responsible 3D Printed One-Handed Recorder", International Journal of Environmental Research and Public Health, Vol. 18, No. 22, 12200, 2021年。https://doi.org/10.3390/ijerph182212200 (Crossrefで著者3名・題名・巻号・論文番号・年・概要を確認)。片手だけが使える児童のために安価な片手用リコーダーを作る設計事例である。造形方式は光造形(ステレオリソグラフィ)であり、20名の小学生に対して補助機器の心理社会的影響尺度(PIADS)による評価を行っている。
- Lior Arbel, François Gautier, "LeMo: an assembly kit for musical acoustics education", Journal of New Music Research, Vol. 51, No. 2-3, pp. 106-120, 2022年。https://doi.org/10.1080/09298215.2022.2150651 (Crossrefで著者2名・題名・巻号・ページ・年を確認。概要はSemantic Scholarで確認)。概要は楽器を振動の生成・共鳴・放射という基本的な音響的性質で分類し、共鳴部と放射部の独立したモジュールから成る組み立てキットを述べるとしている。前任の「励振部・共鳴部・放射部に分解する」という要約は正確である。FlueBricksが「LeMoの概念を拡張する」と明記しているので、直接の下敷きであることも確認できた。
- Federico Avanzini, Adriano Baratè, Luca A. Ludovico, "3D printing in preschool music education: Opportunities and challenges", Qwerty - Open and Interdisciplinary Journal of Technology, Culture and Education, Vol. 14, No. 1, pp. 71-92, 2019年。https://doi.org/10.30557/qw000012 (Crossrefで著者3名・題名・掲載誌・巻号・年を確認。ページ範囲はDamodaranらの総説の参考文献[38]の記載で補った)。
- Francesco Di Maggio, Catharina Maria van Riet, Sergio Picella, Berry Eggen, Bart Hengeveld, "The Aerophone Kit: A Toolkit for Pneumatic Musical Instrument Design", Proceedings of the International Conference on New Interfaces for Musical Expression (NIME '26), 6月24日から27日, ロンドン, 2026年。https://nime.org/proceedings/2026/nime2026_80.pdf (本文PDFを取得し、著者5名の氏名と所属アイントホーフェン工科大学、会議名、会期、開催地、概要を確認)。空気圧回路と流体論理だけで動き、電子部品もデジタル部品も使わない楽器の設計キットである。発音はチューブ形状と弁の特性で調律される笛モジュールが担い、2オクターブすなわち24半音にわたる。前任の記述にあった「電源を使わない点で発想は近い」は不正確なので訂正する。電子的・デジタル的な制御を使わないのであって、正圧を供給するポンプは用いており、電源が不要な機構ではない。音高の計算設計も情報符号化も扱わないという点は本文検索で確認した。
- 有元慶太, 「エアリード楽器のフルー形状と発音特性に関する実験的考察」, 音楽音響研究会資料, 第44巻第8号, pp. 59-61, 2026年2月15日。https://cir.nii.ac.jp/crid/1520026358358670592 (CiNii Researchの機械可読レコードで著者名・題名・掲載誌名・巻・号・ページ・発行日を確認)。フルー(風道)の形状と発音特性の関係を実験的に調べており、CipherFluteの吹き口設計の背景として日本語圏で最も近い最新の研究である。
- 小島正典, 「リコーダーの右手運指を持つケーナの構造と音程」, 音楽音響研究会資料, 第41巻第3号, pp. 1-4, 2022年6月18日。https://cir.nii.ac.jp/crid/1520294740085074432 (CiNii Researchの機械可読レコードで著者名・題名・巻・号・ページ・発行日を確認。前任の記述に欠けていた巻号とページを補った)。管の構造と音程の関係を扱う国内研究である。
- 山田真司, 「オカリナ音に含まれる周波数 振幅ゆらぎとオカリナ音らしさとの関係」, 音楽音響研究会資料, pp. 21-26, 1993年。https://cir.nii.ac.jp/crid/1573668924031425920 (CiNii Researchの機械可読レコードで著者名・題名・掲載誌名・ページ・年を確認。巻号はレコードに登録がない)。国内のオカリナ音響研究として存在を確認した。
- Hiroaki Okada, Sho Iwagami, Taizo Kobayashi, Kinya Takahashi, "Numerical Simulation of Aerodynamics Sound in an Ocarina Model", Proceedings of the International Symposium on Music Acoustics (ISMA 2019), 9月13日から17日, デトモルト, pp. 263-268, 2019年, ISBN 978-3-939296-16-4。http://pub.dega-akustik.de/ISMA2019/data/articles/000010.pdf (予稿集の著者索引で著者4名と題名を確認し、本文PDFを取得して各ページ下部の頁番号263から268を確認)。前任の調査では予稿集ページに到達できず未検証とされていたが、今回ISMA 2019の公式サイトが案内する予稿集の所在(http://pub.dega-akustik.de/ISMA2019)から到達できた。オカリナの胴をヘルムホルツ共鳴器とみなし、圧縮性大渦解法で1億5千万格子を超える三次元モデルを解いている。
- Michael Prairie, "Understanding the Acoustics of the Native American-Style Flute", 2006年10月4日, 全62ページ, 自主公開の文書。http://www.flutopedia.com/refs/Prairie_2006_UnderstandingAcousticsOfTheNAF.pdf (Flutopediaの参考文献一覧 http://www.flutopedia.com/references_p.htm で題名・著者・日付・分量を確認し、PDFの存在も確認した)。前任の調査では査読の有無を含めて確認できないとされていたが、Flutopediaの記載と文書自身の序文により、査読誌の論文ではなく著者が随時更新する自主公開の文書であることが判明した。学術的な先行性の主張には使えない。
- Voichita Bucur, "Digital Fabrication of Some Wind Instruments", Handbook of Materials for Wind Musical Instruments 所収, Springer, 第16章, pp. 593-613, 2019年。https://doi.org/10.1007/978-3-030-19175-7_16 (Crossrefで著者・章題・書名・章番号・ページ・年を確認)。前任の調査ではページを593-612としていたが、正しくは593-613である。章の本文は未読である。
- Paul Hoekje, "A brief summary of A. H. Benade's wind instrument adjustment principles", Catgut Acoustical Society Journal (CASJ), Vol. 2, No. 7, pp. 16-24, 1995年5月。https://purl.stanford.edu/zk714gv4615 (スタンフォード大学デジタルリポジトリで当該号「CAS journal. Volume 2, number 7, 1995-05」の実在、出版者Catgut Acoustical Society、ISSN 1053-7694を確認)。Dabinらが吹き口の管端補正の出典として挙げている。前任の記述は誌名を「Journal of the Catgut Acoustical Society」としていたが、正式には「Catgut Acoustical Society Journal」である。掲載号の実在は確認したが、記事本体は走査画像の閲覧器の中にあり読めていないため、題名とページはDabinらの参考文献[11]の記載に依拠する。

## 未検証のまま残ったもの

前任の調査が挙げていた7件のうち6件は、今回の検証で書誌情報を確定できたので、それぞれ本文の該当する節に移した。移した先は次のとおりである。Walrus PipesとWaving Panpipesは「新規性への脅威が大きい文献」の12番、Lanの博士論文は同11番、Okadaらのオカリナ論文とHoekjeの要約とPrairieの文書とBucurの章は「背景として押さえるべき文献」の末尾である。以下に残るのは、書誌情報は確定したが本文または一部の主張に到達できなかったものである。いずれも「書誌情報は引用してよいが、内容の要約を書くには本文の入手が必要」という状態にある。

1. Blowhole(Tejadaら, Graphics Interface 2018)の本文。予稿集ページはCloudflareのボット判定で、ACM Digital Libraryのページも権限不足で、いずれもHTTP 403を返した。識別クラス数が9個であること、正解率が98パーセントから90パーセントへ落ちること、SLA印刷のほうがヘルムホルツ式の予測に近いことなど、前任が書いた数値はすべて未検証である。CipherFluteの最重要の比較対象であるから、大学図書館経由などで本文を確実に入手すべきである。
2. ProtoHole(Katakura, Watanabe, CHI EA 2018)の概要。ACM Digital LibraryもSemantic Scholarも概要を出さなかった。書誌情報は確定したが、内容の要約は副題からの読み取りにとどまる。
3. Zoran(2011年)の本文。Taylor & FrancisがHTTP 403を返し、Crossrefにも概要の登録がない。「計算による音響設計を行っていない」「セント単位の音高精度を報告していない」という前任の主張は本文で裏が取れていない。
4. Kolomietsら(2020年)のチタン製フルートの本文。同じくTaylor & FrancisがHTTP 403を返した。造形方式がEBMであることと概要の冒頭までは確認したが、後処理や気密性の議論、および音響的な振る舞いの評価は未確認である。
5. Makinoら(2017年)の警笛の本文。Springerが認証画面に飛ばすため到達できていない。内容の要約はDamodaranらの総説による二次的な記述に依拠している。
6. PrintoneのACM Transactions on Graphics版の本文。シミュレーション誤差の定量値(セント換算やパーセント表記)を取れていない。ISMA 2017の短縮版で確認できた「56個の目標周波数のうち53個が実測範囲に入った」という記述までにとどまる。
7. Hoekjeの要約記事(1995年)の本文。掲載号がスタンフォード大学デジタルリポジトリに存在することは確認したが、記事本体は走査画像の閲覧器の中にあり読めていない。題名とページはDabinらの参考文献の記載に依拠する。
8. Bucurの章(2019年)の本文。書誌情報はCrossrefで確定したが、章の中身は未読である。
9. Demakeinの音響モデルの詳細。公式ページとGitHubのREADMEはいずれも設計計算の中身を明示せず、実装コードまで読み込めていない。前任が書いた「枝分かれした管の共鳴周波数を求める」という記述も、公式の文書には対応する記載が見つからなかった。CipherFluteの f = A/(L+e) との関係を厳密に述べるには追加調査が必要である。
10. Bailey, Cremel, South(CIM14)の本文。機関リポジトリの書誌記録は確認したが、本文PDFの内容は確認していない。C++の音響モデルとOpenSCADによる19平均律クラリネットという要約は未検証である。
11. Szabó(2024年)のWalrus PipesとWaving Panpipesの本文。概要までは取得したが、管の本数や調律の決め方は確認していない。

## 検証で削除したもの

削除した文献は1件もない。前任の調査が挙げた文献と事例は、書誌情報の水準ではすべて実在を確認できた。存在しないものを捏造した箇所は見つからなかった。訂正はいずれも、著者名の綴り、会議名の正式表記、公開年、巻号やページの欠落や誤り、内容の要約の行き過ぎ、という種類のものである。

## この切り口で見つからなかったこと

以下は、検索と文献追跡を尽くしたうえで「見つからなかった」と言えることであり、CipherFluteの新規性の主張の根拠になる。

1. 印刷した笛の音高を離散的な符号(スロット)として読み、複数本の音高の並びで数十ビットから百数十ビットの情報を運ぶ研究は見つからなかった。Blowholeは1つの空洞が1つの識別子を表すだけである(ただし識別クラス数の具体的な値は本文未取得のため確認できていない)。パンフルート状に複数の管を並べる工作物は多数あり、査読文献としてもSzabó(2024年)の3Dプリントのパンフルート合奏体が実在するが、それらは音楽を奏でるためのものであって、音高の系列を符号語として扱う設計は査読文献にも非査読の設計物にも見当たらなかった。

2. 基準となる音高が既知の笛を同じ物体に同居させ、他の笛を基準笛との比で読むことで気温や息の強さによる全体のずれを打ち消すという設計は、印刷楽器の文献に見つからなかった。楽器音響には基準ピッチや調律スロットの議論があり、Dabinらは吹く息による音高変動を「奏者の影響」として受け入れ、Printoneは吹く速さによる周波数の幅を実測範囲として示すにとどまる。物体の中に較正用の音源を混ぜて相対量で読むという発想は、通信のパイロット信号からの転用としてCipherFlute固有と言える。

3. 隣り合う笛が同じ音にならない制約(遷移保証)や、Reed-Solomon符号のような誤り訂正を、印刷楽器の形状設計に持ち込んだ例は見つからなかった。印刷楽器の文献における誤差対策は、より精細な造形方式への変更、やすりによる手修正、奏法による補正のいずれかであり、符号レベルの対策は現れない。

4. 円筒を軸方向に半分に割った断面(厚さ4ミリメートル、幅7ミリメートル)の小型フィップル笛を、サポート材なしで平置き印刷し、多数本を融合して1つの日用品に埋め込むという構成は、査読文献に見つからなかった。Printoneは1つの物体を1つの楽器にし、FlueBricksはモジュールを組み替え、Dabinらは管を1本ずつ作る。ただし「多数の管を1つの印刷物にまとめる」ことそのものには前例があるので、ここは注意して書く必要がある。Szabó(2024年)は3Dプリントのパンフルート合奏体を査読誌で報告しており、FlueBricksは1つの息を複数の管へ分配する連結部を備えている。CipherFlute固有と言えるのは、融合そのものではなく、単音笛を情報担体として日用品に偽装して埋め込む点である。

5. 3Dプリントした笛の音高精度をセント単位で系統的に報告した査読文献は、Dabinら(2016年)がほぼ唯一である。しかもそれはPolyJet方式という高精細な装置での結果であり、家庭用のFDM方式で多数本の笛の音高分布を測った報告は見つからなかった。CipherFluteが家庭用FDM機で実測する評価は、この意味で空白を埋める。

6. 日本語圏では、3Dプリント笛の計算設計を扱う研究が見つからなかった。この主張は今回あらためてCiNii ResearchのOpenSearch APIで検証した。2026年7月30日時点で「3Dプリンタ 笛」は0件、「3Dプリント 笛」は0件、「3Dプリンタ オカリナ」は0件、「3Dプリント リコーダー」は0件である。「3Dプリンタ 楽器」は10件出るが、上位はデジタル技術による木管楽器奏者の口腔問題対策、樹脂3Dプリンタ製の双腕協働ロボットによる音符型電子楽器の演奏、産業用ヒューマノイドロボットによる同様の操り動作など、ロボット演奏と口腔装置の研究であり、前任の記述どおりであった。「オカリナ」「気鳴楽器」「エアリード楽器」「リコーダー 音響」ではエアリード楽器の物理と数値流体力学の研究群(安藤由典、吉川茂、足立整治、高橋公也らの系譜)が並ぶが、いずれも印刷や情報符号化とは結びついていない。情報処理学会の音楽情報科学研究会およびWISSの予稿集にも該当する研究は見当たらなかった。

7. 印刷後に音高を測って符号を確定する、あるいは印刷誤差を測定して設計にフィードバックする「印刷後調律」の計算的枠組みは、笛については見つからなかった。オルガンのフルー管の調律スロットに関する音響研究(Ruczら)は存在するが、印刷とは結びついていない。

## 調べ残した穴

1. Printoneの本体であるACM Transactions on Graphics版のPDFに到達できず、シミュレーション誤差の定量値(セント換算やパーセント表記)を取れていない。ISMA 2017の短縮版で確認できた「56個の目標周波数のうち53個が実測範囲に入った」という記述までにとどまる。大学図書館経由などで本文を入手し、精度の表を確認すべきである。

2. ACM Symposium on Computational Fabrication(SCF)の全年次のプログラムを網羅的には見ていない。音響を扱うSCF論文が他にないかを、2017年から2026年までの目次で確認する価値がある。

3. 音響系の会議(ISMA、Forum Acusticum、Stockholm Musical Acoustics Conference、日本音響学会の音楽音響研究会)の各年次プログラムを個別に当たり切れていない。ISMA 2019については今回、公式サイト(http://www.isma2019.de/)から予稿集(http://pub.dega-akustik.de/ISMA2019)に到達し、著者索引を通してオカリナと管楽器の数値解析の論文群があることを確認した。ISMA 2023以降は依然として未確認である。

4. 特許を体系的には調べていない。ただし前任が「検索結果に現れる」とだけ書いていた特許について、今回は実在と識別番号を確認した。米国特許 US 6,348,647 B1 「Fipple flutes having improved airways」は発明者Karl P. Ahrens、優先日2000年3月31日、公告日2002年2月19日である。日本の公開特許公報 特開平7-64562 「Multiple-tone whistle(多音笛)」は出願人Seron Manufacturing Co.、優先日1993年8月12日、公開日1995年3月10日である。いずれもGoogle Patents(https://patents.google.com/patent/US6348647B1/en , https://patents.google.com/patent/JPH0764562A/en)で確認した。すなわち複数の音を出す笛は少なくとも1993年から特許として存在する。音で情報を読み取る玩具の特許は未調査である。

5. 中国語圏および韓国語圏の文献を調べていない。オカリナや尺八型縦笛の設計研究がある可能性がある。

6. ThingiverseやPrintables、MakerWorldなどに投稿された非査読の設計物を網羅していない。「Whistle Pan flute」のように複数の笛を並べた作品が実在するため、先行「作品」としての言及が必要になる場合は、代表例を選んで出典を明示する準備が要る。

7. Demakeinの最適化アルゴリズムの中身と、CipherFluteの経験式との数理的な関係を確かめていない。実装コードを読めば、両者の設計問題の包含関係を明確に書ける。

## 検証の記録

2026年7月30日に、この切り口の文献一覧を最初に書いた担当者とは別の担当者が、書誌情報の実在をすべて独立に検証し直した。以下がその記録である。

検証の対象は、検証前のこのファイルに挙げられていた書誌情報を伴う項目のすべてであり、重複を除いて41件であった。内訳は「新規性への脅威が大きい文献」の節に14件(全10項のうち第1項はACM Transactions on Graphics版とISMA 2017短縮版の2件、第6項と第8項もそれぞれ2件の文献を束ねているため、項の数より文献の数が多い)、「背景として押さえるべき文献」の節に22件(全21項のうちRuczらの項が2件を束ねている)、「未検証のまま残ったもの」の節に文献6件である。openwindは脅威の節と背景の節の両方に現れるため、重複を除いて1件と数えた。加えて、本文中の文献以外の主張として、CiNii Researchの検索結果の件数と、特許の存在についても検証した。

検証の方法は次のとおりである。DOIを持つ文献は、doi.orgに対してコンテンツネゴシエーション(Accept: application/vnd.citationstyles.csl+json)を行い、Crossrefに登録された著者名・題名・掲載誌名・巻号・ページ・年・出版者を直接取り出して照合した。DOIを持たない文献は、学会の予稿集ページ、著者や研究所の公式ページ、DBLP、DataCite、OpenAIRE、Semantic Scholar、CiNii Researchの機械可読レコード、スタンフォード大学デジタルリポジトリ、Google Patentsのいずれかに当たった。数値や事実の主張については、可能な範囲で原典のPDFを取得して本文で裏を取った。実際に本文を取得して精読したのは、PrintoneのISMA 2017短縮版、DabinらのNIME 2016論文、FlueBricksのarXiv版、Damodaranらの総説、OkadaらのISMA 2019論文、Di MaggioらのNIME 2026論文の6件である。

その結果、書誌情報の水準で実在を確認できなかった文献は1件もなかった。存在しない文献を捏造した箇所は見つからなかった。削除した項目も1件もない。

訂正は合わせて21件行った。うち書誌情報そのものの誤りの訂正と欠落の補完が12件である。第一に、Demakeinの公開年を2014年から2012年に直した。PyPIの全リリース履歴により、最初の版0.1の公開が2012年9月28日であることを確認した。2014年という数字は、Dabinらの参考文献が付記した参照年に由来すると考えられる。第二に、Lanの博士論文の著者名を「Yuan Lan」から「Yang Lan」に直した。DataCiteの登録が「Lan, Yang」である。第三に、CIM14の会議名に抜けていた「International」を補い、正式には「9th International Conference on Interdisciplinary Musicology」であることを示した。第四に、Hoekjeの掲載誌名を「Journal of the Catgut Acoustical Society」から正式表記の「Catgut Acoustical Society Journal」に直した。第五に、Bucurの章のページを593-612から593-613に直した。第六に、Blowholeの発表媒体を「Proceedings of Graphics Interface 2018」から、DBLPが記録する正式名称の「Proceedings of the 44th Graphics Interface Conference」に改め、開催地と会期も補った。第七から第十二として、Zhongらの第115巻、Howeらの第4号、小島の第41巻第3号とページ1-4、山田のページ21-26、Avanziniらの第14巻第1号とページ71-92、PrintoneのACM Transactions on Graphics版の論文番号184(pp. 184:1-184:14)を、それぞれ補った。

残る9件は内容の要約の訂正である。第一に、FlueBricksが挙げる6つの内部形状の一覧から「調律スロット」を除き、原文どおりの6つ(フルー管路、空気室、風道、窓、分割エッジ、発音室)に置き換えた。調律スロットは共鳴部の側の別モジュールであり、生成部の内部形状ではない。第二に、Kolomietsらのチタン製の楽器を「リコーダー型の笛」からフルートに直した。第三に、同じ研究の造形方式を電子ビーム溶融と明記した。第四に、同じ研究について「音響的な振る舞いが従来の金属製フルートに近い」という要約が裏を取れず、総説の伝えるところでは「著しく豊かな楽音」と要約の向きが逆であることを注記した。第五に、Di Maggioらの空気圧楽器キットについて「電源を使わない」という記述を、電子部品とデジタル制御を使わないがポンプで送気する構成である旨に直した。第六に、Blowholeについて、前任が書いた識別クラス数9個、正解率98パーセントから90パーセント、SLA印刷が予測に約100ヘルツ近いといった数値が、予稿集ページとACM Digital Libraryのいずれもボット判定と権限不足でHTTP 403を返したために裏を取れなかった旨を明記し、「9クラスで約3.2ビット」という容量の対比も未検証であると断った。CipherFluteの最重要の比較対象であるから、これらの数値を論文に書く前に本文を確実に入手すべきである。第七に、ZoranとKolomietsとMakinoについて、前任が「本文を通読した」と書いていたものを、実際に到達できた資料の範囲に合わせて書き換えた。第八に、Demakeinの音響モデルが「枝分かれした管の共鳴周波数を求める形で組まれている」という記述に、公式の文書に対応する記載がないことを注記した。第九に、DabinらのFDM機での失敗の記述を原文に合わせて精密にした。原文は、ラビウムの望む鋭さが出ないことと、ボア内壁の粗さのために奏者がより高い吹圧を要し、安定した音を立ち上げるまでに市販品より長い時間がかかったことを述べており、「発音が不安定になった」という要約より具体的である。

一方で、確かめた結果として前任の記述が正確であった箇所も多い。Printoneの「56個の目標周波数のうち53個が実測範囲に入った」と「16本の楽器」はISMA 2017版の原文どおりであった。Dabinらのセント値(リコーダー1が+6から+34、リコーダー2が−40から+1、手修正版が−13から+14)と5セント以内という将来目標は、原論文の表1と本文で一字一句合っていた。Damodaranらの総説に音高精度のセント表記がないことと、Printone・Dabinら・Makinoらを紹介していることも全文検索で確認した。Makinoらの警笛について「笛の半径が周波数に大きく効く」「空気の循環量の効果を高校生が予測できた」という要約も、総説の記述と一致していた。CiNii Researchで「3Dプリンタ 笛」が0件であることも再現した。

さらに、前任が「未検証のまま残ったもの」に置いていた7件のうち6件を確定させ、本文の該当する節に移した。Szabóの3Dプリントのパンフルート合奏体(Jazz Research Journal, 2024年)、Lanの博士論文(2015年)、OkadaらのISMA 2019論文、Hoekjeの掲載号、Prairieの自主公開文書、Bucurの章である。この過程で、前任が見落としていた査読誌の論文を1件新たに見つけた。Lan と Waltham による「Acoustic Modeling and Optimization of the Xiao」(Acta Acustica united with Acustica, 第102巻第6号, pp. 1128-1137, 2016年)である。同じ著者による博士論文が伝達行列法で中国の縦笛を設計するものであることはDabinらの記述で裏が取れており、この系譜はCipherFluteの一次元の経験式に最も近い位置にあるので、脅威の度合いを「中」として本文に追加した。ただし査読誌版そのものの概要は公開されておらず、中身は未確認である。あわせて、前任が「検索結果に現れる」とだけ書いていた特許2件について、米国特許US 6,348,647 B1と日本の特開平7-64562という具体的な識別番号、発明者、出願人、日付を確定させた。

残る不確かさは、末尾の「未検証のまま残ったもの」に11項目として整理した。要するに書誌情報はすべて信頼して引用できる状態になったが、内容の数値を論文に書くには、Blowhole、Zoran、Kolomiets、Makino、PrintoneのTOG版の5件について本文の入手がまだ必要である。

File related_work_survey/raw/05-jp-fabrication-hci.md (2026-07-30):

# 日本のHCI分野におけるデジタルファブリケーション研究

本稿は、CipherFluteの投稿先が日本のWISSであることを踏まえ、日本のヒューマンコンピュータインタラクション分野におけるデジタルファブリケーション研究、とくに3Dプリントを扱う研究を洗い出したものである。WISSの予稿集を2014年から2025年まで各年のページで確認し、あわせて情報処理学会のインタラクションシンポジウム、情報処理学会論文誌、ヒューマンインタフェース学会論文誌、芸術科学会論文誌、電子情報通信学会技術研究報告、CiNii Research、およびACM UISTとACM CHIに採録された日本の研究者の業績を調べた。書誌情報は一次資料に当たって確認し、確認先のURLを付した。一次資料で確定できなかったものは末尾の「未検証のまま残ったもの」の節にまとめてあり、本文に書いてあるものと未検証のものを混ぜていない。

## この切り口の要約

日本のHCI分野のデジタルファブリケーション研究は、大きく三つの系統に分かれている。第一は、熱溶解積層方式3Dプリンタの造形挙動そのものを制御して新しい表現や機能を得る系統であり、高橋治輝（立命館大学情報理工学部 講師）を中心に、毛構造、布状構造、ブリッジ造形、複数材料フィラメントなどの成果が積み上がっている。第二は、印刷物や日用品に電気的な機能を付与する系統であり、加藤邦拓（2026年より日本女子大学理学部 講師、2021年から2026年までは東京工科大学メディア学部 准教授）、川原圭博（東京大学）、鳴海紘也（2025年時点で慶應義塾大学）、池松香、石井綾郁らが、導電インク、食用金箔、レーザ炭化による木製回路、自己折り紙などを扱っている。第三は、造形物そのものを識別子や情報の担体として使う系統である。CipherFluteにとって決定的に重要なのは第三の系統であり、日本国内には二つの独立した研究群が存在する。ひとつはNTTの久保勇貴らによるFabAuthの一連の研究で、スライサが生成する内部充填パターンの違いを能動音響センシングと機械学習で識別する。もうひとつは神奈川工科大学の鳥井秀幸と上平員丈らによる一連の研究で、造形物の内部に情報を埋め込み、近赤外線の撮像や透視で読み出す。前者は「造形物に情報を埋め込み、音で読む」という一文でCipherFluteと重なるため、最も注意深く差分を述べる必要がある。一方で、管長と基本周波数の関係を設計変数として扱い、人が吹くだけで電源も計測器もなく多数ビットの符号を読み出す研究は、調べた範囲では国内に存在しなかった。誤り訂正符号や基準笛による正規化まで踏み込んだ国内先行研究も見つからなかった。ただし通信工学の系列設計を物理的な符号に持ち込んだ国内例は存在し、奥山瑞希らがM系列（最大長系列）を円筒バーコードに刻んで回転方向を検出している。この一件は「通信工学の道具立てを物理造形の符号設計へ持ち込んだ国内先行はまったく無い」という言い方を許さないため、後述のとおり主張の書き方を限定した。

## 新規性への脅威が大きい文献

### 1. 内部構造パターンの差異を利用した3Dプリントオブジェクト識別手法（およびFabAuthの一連の研究）

- 題名: 内部構造パターンの差異を利用した3Dプリントオブジェクト識別手法
- 著者: 久保勇貴、江口佳那、青木良輔、近藤重邦、東正造、犬童拓也（いずれも日本電信電話株式会社。所属は予稿1ページ目の脚注で確認した）
- 発表: WISS 2019（第27回インタラクティブシステムとソフトウェアに関するワークショップ）登壇発表8
- 確認先: https://www.wiss.org/WISS2019Proceedings/oral/8.pdf （予稿本文6ページを取得し、全ページを描画して読了）
- 関連する英語版1: Yuki Kubo, Kana Eguchi, Ryosuke Aoki, Shigekuni Kondo, Shozo Azuma, Takuya Indo. "FabAuth: Printed Objects Identification Using Resonant Properties of Their Inner Structures." Extended Abstracts of the 2019 CHI Conference on Human Factors in Computing Systems, pp.LBW2215:1-LBW2215:6. DOI: 10.1145/3290607.3313005 （確認先: Crossref API https://api.crossref.org/works/10.1145/3290607.3313005 で題名・著者6名・掲載巻を確認し、論文番号LBW2215と6ページという体裁は上記WISS 2019予稿の参考文献[4]の自己引用で確認した。著者本人の業績ページ https://www.yukikubo.net/index-e.html でもCHI 2019のLate-breaking Workとして確認した）
- 関連する英語版2: Yuki Kubo, Kana Eguchi, Ryosuke Aoki. "3D-Printed Object Identification Method using Inner Structure Patterns Configured by Slicer Software." Extended Abstracts of the 2020 CHI Conference on Human Factors in Computing Systems, pp.1-7. DOI: 10.1145/3334480.3382847 （確認先: https://api.crossref.org/works/10.1145/3334480.3382847 および上記の著者業績ページ）

内容の要約は次のとおりである。あらゆる物体は形状と素材と境界条件に応じた固有の振動特性を持つという前提に立ち、3Dプリンタのスライサソフトウェアで設定できる充填率と充填パターンを変えることで、外観が同一の物体に固有の音響周波数応答を割り当てる。読み出しは、圧電素子を両面テープで物体に貼り付け、20キロヘルツから40キロヘルツの範囲を20ミリ秒で掃引する信号を一方の圧電素子から入力し、もう一方の圧電素子で振動を取得する能動音響センシングによる。装置はノートパソコン、オーディオインタフェース（Steinberg UR22mkII）、圧電素子（THRIVE K2512BP1）から成る。得られた周波数応答にハミング窓と高速フーリエ変換を施し、そこから作った426個の値を特徴量として、機械学習ライブラリのWEKAで分類する。25ミリメートル角、高さ30ミリメートルの直方体を、スライサのUltimaker Curaで充填率20パーセントと8種類の充填パターンに設定し、3DプリンタのUltimaker S5で造形して、Random Forestによる平均識別精度99.3パーセントで8個を識別できた。ここは原典の数値をそのまま引くと、2グループでそれぞれ100パーセントと98.6パーセントであり、その平均が99.3パーセントである。ただし2台のUltimaker S5で造形した計16個の物体を混ぜてプリンタ単位で交差検証すると、識別精度はRandom Forestで平均47.2パーセント、Support Vector Machineで平均60.2パーセントまで落ち、プリンタ個体差の影響が大きいことも報告している。識別精度が特に低かった2個を除くとRandom Forestで68.1パーセント、Support Vector Machineで87.2パーセントである。関連研究としてAcoustic Barcodes、Acoustic Voxels、AirCode、InfraStructs、Touch & Activate、RadarCat、VibEye、Magic Fingerを引用しており、さらに後述する岩瀬らのインタラクション2018論文も参考文献[13]として引用している。

CipherFluteとの関係は次のとおりである。「家庭用の熱溶解積層方式3Dプリンタで造形した物体に情報を仕込み、音響を通じて読み出す」という一文だけを取り出すと、この研究とCipherFluteはほぼ同じことを述べているように読める。しかも引用している先行研究の集合（Acoustic Barcodes、Acoustic Voxels、AirCode、InfraStructs）がCipherFluteの引用集合と大きく重なっている。したがって国内の査読者は真っ先にこの研究を思い浮かべる可能性が高い。差分は三点ある。第一に、この研究が得るのは「どの個体か」というクラス分類であり、8クラスは情報量にすると3ビットにすぎず、128ビットのリカバリーシードのような多ビットのデータを運ぶ設計にはなっていない。CipherFluteは1本あたり約3.7ビットを運び、40本から49本を束ねて128ビットに到達させる符号設計を持つ。第二に、この研究は圧電素子と音響インタフェースとノートパソコン、および事前の機械学習を必須とするのに対し、CipherFluteは人が息を吹き込むだけで音が鳴り、音高という絶対的な物理量が符号になるため、原理的には耳と音叉だけでも読める。第三に、この研究には「秘密の保管」という応用文脈と脅威モデルがまったくない。

脅威の度合いは「高」である。理由は、一文要約が重なるうえに引用集合まで重なっており、この研究を引用せずにCipherFluteを提案すると、国内査読で「既に日本でやられている」と判断される危険が大きいからである。CipherFluteは必ずこの一連の研究を引用し、識別（クラス分類）とデータ搬送（多ビット符号）の違い、能動計測と人間の呼気による受動発音の違い、機械学習の要否を明示して差分を述べる必要がある。

### 2. ProtoHole: 穴と音響センシングを用いたインタラクティブな3Dプリントオブジェクトの提案

- 題名（日本語版）: ProtoHole: 穴と音響センシングを用いたインタラクティブな3Dプリントオブジェクトの提案
- 著者: 片倉翔平、渡邊恵太（明治大学。予稿の脚注では所属を明治大学と記し、著者名の表記は「渡邊 惠太」となっている）
- 発表: WISS 2017 デモ発表1-A02（登壇発表ではない）
- 確認先: https://www.wiss.org/WISS2017Proceedings/ で目次と発表番号を確認し、https://www.wiss.org/WISS2017Proceedings/demo/1-A02.pdf の予稿本文を描画して読了した
- 英語版: Shohei Katakura, Keita Watanabe. "ProtoHole: Prototyping Interactive 3D Printed Objects Using Holes and Acoustic Sensing." Extended Abstracts of the 2018 CHI Conference on Human Factors in Computing Systems, pp.1-6. DOI: 10.1145/3170427.3188471
- 確認先: Crossref API https://api.crossref.org/works/10.1145/3170427.3188471 （題名、著者2名、掲載巻、ページ1-6を確認した）

内容の要約は次のとおりである。3Dプリントする物体の中身を空洞にし、その表面に複数の穴を開ける。物体に取り付けたスピーカから高周波の掃引信号を送信し、取り付けたマイクで受信して、穴を指でふさいだときに生じる共鳴特性の変化を機械学習で分類する。これにより、内部に電子部品を配置したり配線を通したりすることなく、造形物にインタラクティブな入力機能を付与できる。日本語版はWISS 2017のデモ発表として発表され、英語版は翌年のCHIのExtended Abstractsに採録された。なお本稿の予稿本文には、操作原理はAcoustrumentsを参考にしており、それを穴に焦点を当てて複雑な形状の物体へ適用したものだと明記されている。CipherFluteもAcoustrumentsを引用しているため、この研究はAcoustrumentsから伸びる枝の隣に立っていることになる。

CipherFluteとの関係は次のとおりである。「3Dプリント物体の内部空洞が持つ音響特性を情報として利用する」という着想の骨格が共通している。とくに、空洞と穴という幾何が音を規定するという物理は、CipherFluteの管長と窓の関係とよく似ている。差分は、ProtoHoleが動的なインタラクション（指で穴をふさぐ動作）を検出する入力デバイスであり、静的なデータの符号化ではないこと、および掃引信号を放射する能動音響センシング装置を必要とすることである。CipherFluteの物体は造形が終わった時点で情報が固定されており、読み出しは人間の呼気だけで完結する。

脅威の度合いは「中」である。理由は、主要な主張（データを運ぶ物理媒体としての笛）を直接崩すものではないが、「3Dプリント造形物の空洞の音響を使う」という点で明確に隣接しており、日本の同一コミュニティの成果であるため、引用して差分を述べないと不誠実に見えるからである。

### 3. 3Dプリンター造形物への情報埋め込み技術の一連の研究（神奈川工科大学）

- 研究課題: 3Dプリンタ造形物への情報埋め込み技術の研究、研究代表者は鳥井秀幸（神奈川工科大学）、期間は2019年4月1日から2023年3月31日まで（日本学術振興会 科学研究費助成事業）
- 前身の研究課題: デジタルファブリケーションにおける著作権保護技術の研究、研究代表者は同じく鳥井秀幸（神奈川工科大学）、期間は2015年4月から2019年3月まで（日本学術振興会 科学研究費助成事業）
- 確認先: CiNii Researchで両方の研究課題を確認した。https://cir.nii.ac.jp/all?q=%E9%B3%A5%E4%BA%95%E7%A7%80%E5%B9%B8%20%E4%B8%8A%E5%B9%B3%E5%93%A1%E4%B8%88 および https://cir.nii.ac.jp/all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

主要な発表は次のとおりである。以下の8件はすべて、CiNii Researchの検索結果で題名、著者の並び、誌名、巻号、ページ、年月を一件ずつ照合した（確認先: https://cir.nii.ac.jp/all?q=%E9%B3%A5%E4%BA%95%E7%A7%80%E5%B9%B8%20%E4%B8%8A%E5%B9%B3%E5%93%A1%E4%B8%88 および https://cir.nii.ac.jp/all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 ）。

- 中村耕介、鈴木雅洋、高嶋洋一、鳥井秀幸、上平員丈「石膏材による3Dプリンター造形物への情報埋め込みと読み出し技術」電子情報通信学会技術研究報告 116(34), pp.93-97, 2016年5月
- 中村耕介、鈴木雅洋、高嶋洋一、鳥井秀幸、上平員丈「内壁の構造化による3Dプリンター造形物への情報埋め込み技術」電子情報通信学会技術研究報告 116(132), pp.19-22, 2016年7月
- 鈴木雅洋、中村耕介、髙沢渓吾、高嶋洋一、鳥井秀幸、上平員丈「3Dプリンター造形物への情報埋め込みと近赤外線透視像による読み出し技術」電子情報通信学会技術研究報告 116(176), pp.57-61, 2016年8月（同じ内容が映像情報メディア学会技術報告 40(26), pp.57-61, 2016年8月にも掲載されている。両学会の共催研究会のため書誌が二重に立っているものであり、引用するときはどちらか一方に決めるべきである）
- 中村耕介、鈴木雅洋、髙沢渓吾、高嶋洋一、鳥井秀幸、上平員丈「3Dプリンター造形物への情報埋め込みと近赤外線反射像による読み出し技術」電子情報通信学会技術研究報告 116(501), pp.13-17, 2017年3月（CiNiiの書誌では題名の前に「ポスター講演」が付いている）
- 鈴木雅洋、髙沢渓吾、中村耕介、高嶋洋一、鳥井秀幸、上平員丈「2色造形を用いた内部構造化による3Dプリンター造形物への情報埋め込み技術」画像電子学会研究会講演予稿 16.03, pp.141-145, 2017年
- 中村耕介、松本知久、鈴木雅洋、鳥井秀幸、上平員丈「3Dプリンター造形物への高反射率材料による情報埋め込みと近赤外線撮像による情報読み出し」電子情報通信学会技術研究報告 117(113), pp.29-33, 2017年6月
- 松本知久、中村耕介、鳥井秀幸、鈴木雅洋、高嶋洋一、上平員丈「近赤外蛍光樹脂による3Dプリンター造形物内への情報埋め込み」電子情報通信学会技術研究報告 117(282), pp.13-16, 2017年11月
- 中村耕介、松本知久、鈴木雅洋、鳥井秀幸、上平員丈「メタルライク樹脂による3Dプリンター造形物内への情報埋め込み」電子情報通信学会技術研究報告 117(476), pp.41-44, 2018年3月

検証の途中で、この研究群の応用文脈を直接に裏づける発表をもう1件見つけたので付け加えておく。中村耕介、鈴木雅洋、ピヤラット シラパスパコォンウォン、高嶋洋一、鳥井秀幸、海野浩、上平員丈「3Dプリンター造形物内部に埋め込んだ著作権情報の近赤外線カメラによる読み出し技術」電子情報通信学会技術研究報告 115(479), pp.37-40, 2016年3月である。題名に「著作権情報」と明示してあるため、この研究群が著作権保護を応用に掲げているという記述の根拠になる。同じ確認先で書誌を確認した。

内容の要約は次のとおりである。3Dプリンタで造形する物体の内部に、材料の光学的性質の違い（石膏、高反射率材料、近赤外蛍光樹脂、メタルライク樹脂、2色造形）や内壁の構造化によって情報を埋め込み、近赤外線の反射像や透視像を撮像することで外観を損なわずに読み出す。この研究群は2015年からの「デジタルファブリケーションにおける著作権保護技術の研究」を前身とし、著作権保護と真贋判定を応用として掲げている。前身の研究課題名と期間、および上記の著作権情報の論文の題名がその根拠である。

CipherFluteとの関係は次のとおりである。「造形物の内部に情報を埋め込み、外観を損なわずに読み出す」という問題設定はCipherFluteとまったく同じである。国内における「造形物への情報埋め込み」の先行研究として最も体系的であり、AirCodeやInfraStructsに相当する日本国内の系譜を成している。差分は読み出しの手段であり、この研究群は近赤外線の撮像装置という専用機器を必要とする。CipherFluteは人間の呼気と耳（あるいはスマートフォンのマイク）だけで読める点、および秘密分散を前提とした脅威モデルを持つ点が異なる。

脅威の度合いは「中」である。理由は、読み出しの物理が光学であって音響ではないため主要な主張を崩さないが、国内における造形物への情報埋め込みの先行として必ず引用すべきであり、引用漏れは国内査読で「国内先行を調べていない」という指摘を招くからである。

### 4. 溝間隔の違いによる筆圧変化を活用したシート埋め込み型ID認識手法

- 題名: 溝間隔の違いによる筆圧変化を活用したシート埋め込み型ID認識手法
- 著者: 瀬崎夕陽、関口祐豊、中村聡史（いずれも明治大学。予稿1ページ目の脚注で確認した）
- 発表: WISS 2025 登壇発表23（あわせてデモ発表3-A07としても発表されている）
- 確認先: https://www.wiss.org/WISS2025Proceedings/data/paper/23.pdf （予稿本文7ページを取得し、描画して読了）および https://www.wiss.org/WISS2025Proceedings/ （発表番号と所属を確認）

内容の要約は次のとおりである。一定間隔で溝を設けた透明なアクリル板のシートをディスプレイ上に敷き、デジタルペンで筆記したときの筆圧値のピーク数やピーク間隔からシートの種類を推定して、筆記対象物を識別する。既存のディスプレイとデジタルペンだけで実現でき、RFIDタグや導電パターンや電子部品を物体側に組み込む必要がない。溝の幅が異なる4種類のシートを作成して評価し、識別精度0.78を得た。応用として物理カラーパレットや学習支援教材を実装している。関連研究としてAcoustic Barcodes、DataTiles、Lumino、SLAP Widget、TUICを引用している。

CipherFluteとの関係は次のとおりである。物体側に電子部品を一切持たせず、物理的な溝の幾何そのものが識別子を符号化するという構図がCipherFluteと同型である。Acoustic Barcodesを明示的に参照している点も共通している。差分は、読み手がデジタルペンとディスプレイという電子機器であること、符号の語彙が4種類にとどまること、識別精度が0.78であり誤り訂正の設計がないことである。

脅威の度合いは「中」である。理由は、CipherFluteの主要な主張を崩すものではないが、直近のWISSで「電子部品なしの物理構造でIDを符号化する」という同じ発想が発表されているため、査読者が想起する可能性が高く、引用して符号量と読み出し手段の違いを述べる必要があるからである。

### 5. 棒の引っかきによる音波を用いたインタラクション取得手法の検討

- 題名: 棒の引っかきによる音波を用いたインタラクション取得手法の検討
- 著者: 林吉経、尾崎亮太、上堀まい、岩本涼、菊地萌花、石黒成紀、伊藤雄一（林と尾崎と伊藤は青山学院大学、上堀は青山学院大学と日本学術振興会特別研究員、岩本と菊地と石黒はDAIKEN株式会社）
- 発表: WISS 2025 デモ発表 1-C30
- 確認先: https://www.wiss.org/WISS2025Proceedings/data/demo/1-C30.pdf （予稿本文3ページを取得し、著者行を高解像度で描画して1文字ずつ照合した）および https://www.wiss.org/WISS2025Proceedings/ （所属を確認）

内容の要約は次のとおりである。2本の爪と2列の突起からなる機構を構築し、爪を圧電素子を介して棒の先端に取り付ける。突起列は等間隔に配置し、列の間には位相差を設ける。物体が相対移動すると爪が突起を引っかき、爪は長さに固有の周波数で振動する。周波数の異なる音波の発生順番から移動方向を、発生回数から移動量を推定する。突起列は3Dプリンタで作成し、爪はオルゴールの櫛歯を加工して作成した。音波の取得には圧電素子7BB-20-6を瞬間接着剤で爪に貼り付け、オーディオインタフェースUS-4x4を介してパソコンへ送っている。移動速度が毎秒258度のとき、回転移動を5度ごとに100パーセントの再現率で検知できたと報告している。関連研究としてLamelloとSynthetic Sensorsを引用している。

CipherFluteとの関係は次のとおりである。「物理構造の寸法（爪の長さ）を音の周波数に写像し、造形した幾何から音を発生させる」という中核の物理がCipherFluteと同じである。3Dプリンタで突起を作っている点も共通する。差分は、この研究の目的が運動の計測（方向と量の推定）であり、静的なデータを運ぶ符号の語彙を設計しているわけではないこと、そして圧電素子と音響インタフェースを必要とすることである。

脅威の度合いは「中」である。理由は、Lamelloの日本における延長として同じ物理を使っており、直近のWISSの発表であるため引用が望ましいが、データ搬送という目的を共有していないため主要な主張は崩さないからである。

### 6. アクティブ音響センシングによる日常物体識別と位置推定

- 題名: アクティブ音響センシングによる日常物体識別と位置推定
- 著者: 岩瀬大輝、伊藤雄一、秦秀彦、山下真由、尾上孝雄（いずれも大阪大学大学院情報科学研究科。予稿1ページ目の脚注で確認した）
- 発表: 情報処理学会 インタラクション2018 論文集, pp.62-71, 2018年3月2日、論文番号INT18008
- 確認先: http://www.interaction-ipsj.org/proceedings/2018/data/pdf/INT18008.pdf （予稿本文10ページを取得し、描画して読了した。1ページ目のページ番号が62、最終ページが71であり、pp.62-71と一致する）。さらに久保らのWISS 2019予稿の参考文献[13]がこの論文を「インタラクション2018論文集, pp.62-71, 情報処理学会, 2018」として引用しており、書誌が独立に裏づけられた

内容の要約は次のとおりである。アクリル製平板の表面にマイクとスピーカを配し、特定の音響信号を板の内部に伝搬させ、その応答の周波数解析によって板の上に置かれた物体の種類と位置を推定する。単一物体については種類を98.2パーセント、位置を85.5パーセントの精度で取得でき、複数物体については最大93.8パーセントの精度で取得できた。これらの数値は論文の概要にそのまま書かれているものである。関連研究としてRadarCat、Acoustruments、Lumino、Acoustic Barcodes、Touch & Activateなどを整理している。

CipherFluteとの関係は次のとおりである。日常空間の物体を音響で識別するという構図が、CipherFluteの「日用品に偽装した物体を音で読む」という枠組みと隣接する。差分は、能動計測装置と機械学習が必要であり、物体側に情報を埋め込む設計を持たないことである。

脅威の度合いは「中」である。理由は、日本のHCI分野における音響センシングによる物体識別の代表例であり、CipherFluteの位置づけを述べるうえで参照すべきだが、造形物への情報埋め込みという主張を直接には脅かさないからである。

### 7. Touch & Activate: Adding Interactivity to Existing Objects using Active Acoustic Sensing

- 著者: Makoto Ono（大野誠）, Buntarou Shizuki（志築文太郎）, Jiro Tanaka（田中二郎）（筑波大学）
- 発表: Proceedings of the 26th Annual ACM Symposium on User Interface Software and Technology (UIST 2013), pp.31-40
- DOI: 10.1145/2501988.2501989
- 確認先: Crossref API https://api.crossref.org/works/10.1145/2501988.2501989 （題名、著者3名、掲載巻、pp.31-40を確認した。なおCrossrefに登録された題名の表記は "Touch &amp; activate: adding interactivity to existing objects using active acoustic sensing" と小文字である）および著者所属研究室の業績ページ https://www.iplab.cs.tsukuba.ac.jp/en/paper/6151b7ff551fd46e82abdb1b/ （開催地セントアンドリュース、2013年10月8日から11日という開催情報まで一致した）

内容の要約は次のとおりである。振動スピーカと圧電マイクを一組だけ既存の物体に貼り付け、掃引信号を物体に注入して周波数応答の変化を学習することで、物体への触り方や握り方を認識する。プラスチック玩具に対する5種類のタッチジェスチャの認識精度は個人ごとに99.6パーセントに達した。

CipherFluteとの関係は次のとおりである。この論文は、上に挙げた久保らの研究、片倉らの研究、岩瀬らの研究、林らの研究がいずれも引用している、日本発の能動音響センシングの原典である。CipherFluteが「造形物の音響で情報を読む」系譜のどこに立っているかを日本の読者に説明するときの基準点になる。差分は、能動的に信号を注入して機械学習で状態を推定するのに対し、CipherFluteは物体自身が発音体であり、音高そのものが符号である点である。

脅威の度合いは「中」である。理由は、直接の競合ではないが、日本の音響センシング研究の基点として引用しないと系譜の説明が成立しないからである。

### 8. 予め吹き込まれた音響のないレコード（木、紙、金属、磁器）

- 制作者: 城一裕（Kazuhiro Jo。九州大学大学院芸術工学研究院 准教授）
- 発表形態: 展覧会「木、紙、金属、磁器 – 予め吹き込まれた音響のないレコード – 」（2023年2月14日から26日まで、福岡市中央区大手門のギャラリーEUREKA）。また作品「予め吹き込まれた音響のないレコード」（2020年、オンラインパフォーマンス）が第24回文化庁メディア芸術祭エンターテインメント部門の審査委員会推薦作品に選ばれている
- 対応する査読付き論文: Kazuhiro Jo, Paul DeMarinis. "Life in the groove: Re-visiting the common sense of sound reproduction." Proceedings of RE:SOUND 2019 (8th International Conference on Media Art, Science, and Technology), Electronic Workshops in Computing, pp.72-75, 2019. DOI: 10.14236/ewic/resound19.11
- 確認先: https://www.design.kyushu-u.ac.jp/topics/16705/ （九州大学芸術工学研究院の公式ページ。展覧会の題名を原語のまま照合した）、https://researchmap.jp/jojporg （researchmapの本人ページで氏名の英語表記、所属、准教授という職名、メディア芸術祭の回次と部門、および上記論文のページ数を確認）、Crossref API https://api.crossref.org/works/10.14236/ewic/resound19.11 （論文の題名、著者2名、RE:SOUND 2019という会議名を確認）

内容の要約は次のとおりである。1923年のバウハウス期にモホイ＝ナジが構想した、あらかじめ音を吹き込む工程を経ないレコード盤という着想を、現代のパーソナルファブリケーションの道具で実現する試みである。1860年に記録された民謡「月の光に」の楽譜から周波数を計算し、対応する波形を、木、紙、金属、磁器といった素材の表面に水平方向の溝として直接刻む。録音という工程を経ずに、計算された幾何だけからレコードの音溝を作り、レコードプレーヤで再生すると素材ごとのノイズを伴った音が鳴る。同じ信号データから作っても素材ごとに違う音の質が現れるという点が展覧会の説明で強調されている。

CipherFluteとの関係は次のとおりである。「録音や電子的な記録を経ずに、計算した数値を物理的な造形の幾何へ直接彫り込み、その物体から音として読み出す」という構図が、CipherFluteの「秘密の値を管長へ写像し、吹くと音として読み出せる」という構図と概念的に非常に近い。日本のメディア考古学とデジタルファブリケーションの接点にある実践として、CipherFluteの発想の系譜を語るときに引くべき作品である。差分は、城の作品が運ぶのが音声波形そのもの（オーディオ）であって任意のデジタルデータではないこと、再生にレコードプレーヤという既存の再生機構を必要とすること、そして秘密の保管という目的を持たないことである。

脅威の度合いは「中」である。理由は、扱う情報が音声波形そのものであって任意のデジタルデータではないため主要な主張を崩さないが、「物理造形に音を刻む」という発想の国内における最も近い実践であり、これを知らずにCipherFluteを提案すると発想の独自性が過大に主張されているように見える恐れがあるからである。なお検証の結果、この実践には査読付き会議論文が対応することが分かったので、引用に不足はない。

### 9. M系列円筒バーコードとAR和服帯試着システムへの応用

- 題名: M系列円筒バーコードとAR和服帯試着システムへの応用
- 著者: 奥山瑞希（お茶の水女子大学大学院 人間文化創成科学研究科）、的場やすし（お茶の水女子大学 理学部 情報科学科）、椎尾一郎（お茶の水女子大学大学院 人間文化創成科学研究科）
- 発表: WISS 2017 登壇発表04（あわせてデモ発表2-A08としても発表されている）
- 確認先: https://www.wiss.org/WISS2017Proceedings/ （目次で題名、著者3名、発表番号を確認）および https://www.wiss.org/WISS2017Proceedings/oral/04.pdf （予稿本文6ページを取得し、描画して読了。所属は1ページ目の脚注で確認した）

この文献は、最初の調査では目次だけの確認にとどまり「未検証」に置かれていたものである。検証のために予稿本文を読んだところ、CipherFluteとの関係が当初の見立てより深いことが分かったので、この節へ移した。

内容の要約は次のとおりである。拡張現実感で普通に使う光学マーカは平面に貼ることを前提としているが、実世界の構造物や家具や人体には円柱形の部分が多い。そこで円筒面を持つ立体物に取り付けるための、円筒形のバーコード光学マーカを提案する。マーカは円柱側面に、円柱の高さ方向に平行にバーを並べたものである。この配置ではカメラに向いた側のバーしか見えないという制約があるが、その代わりに円柱の回転方向（相対角度）を検知できる。部分的な認識だけで角度を決められるようにするため、バーコードには、どの部分数列も一度しか現れないというM系列（最大長系列、線形最大周期列）で生成した2進数をエンコードしている。応用として、実物の和服の上に円筒バーコードのベルトを着用したユーザの画像に、CG画像による和服帯を重畳表示するAR試着システムを作った。

CipherFluteとの関係は次のとおりである。物体側に電子部品も電源も持たせず、物体表面の幾何そのものが符号を運ぶという構図が共通している。さらに重要なのは、符号の語彙の設計に通信工学の系列設計（M系列）を持ち込んでいる点である。CipherFluteはReed–Solomon符号による誤り訂正と、隣り合う笛が同じ音にならない遷移保証の制約という、やはり通信工学の道具立てを使う。つまり「通信の符号理論を物理的な符号の設計へ持ち込む」という発想の先例が、同じWISSに存在する。差分は四点ある。第一に、この研究のマーカは円柱の側面にバーコードを巻きつけるように配置した印刷物であり、3Dプリンタで造形物の内部に情報を埋め込むものではないことである。第二に、読み出しの物理が光学であってカメラを必要とすることである。第三に、M系列が担っているのは回転角度の一意決定であって、多ビットの秘密の搬送ではないことである。第四に、誤り訂正符号は用いておらず、環境変動を打ち消す基準の仕組みも持たないことである。

脅威の度合いは「中」である。理由は、CipherFluteの主要な主張である「吹くだけで多ビットを読み出す」を崩すものではないが、「通信工学の符号設計を物理的な造形へ持ち込んだ国内先行は存在しない」という書き方を許さないため、引用してM系列と誤り訂正符号の役割の違いを述べる必要があるからである。

## 背景として押さえるべき文献

以下は脅威の度合いが「低」であり、日本のデジタルファブリケーション研究の地図を描くために背景として引くべき文献である。

### 造形そのものを制御して新しい表現や機能を得る系統

高橋治輝（立命館大学情報理工学部 講師、2023年4月より。2018年4月から2023年3月までは明治大学の助教）は、この系統の日本における中心人物である。所属と経歴は https://researchmap.jp/harukitakahashi および https://www.ritsumei.ac.jp/ise/teacher/detail/?id=252 で確認した。

日本語の論文誌の4件は、CiNii Researchの検索結果 https://cir.nii.ac.jp/all?q=%E9%AB%98%E6%A9%8B%E6%B2%BB%E8%BC%9D%20%E5%AE%AE%E4%B8%8B%E8%8A%B3%E6%98%8E と https://cir.nii.ac.jp/all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 で、巻号とページと年月日まで照合した。英語の5件は、それぞれのDOIをCrossref APIで解決して題名、著者の並び、掲載巻、ページを照合した。

- 高橋治輝、宮下芳明「オーバーエクストルージョンを用いた熱溶解積層方式3Dプリンタのための造形手法」芸術科学会論文誌 15(5), pp.194-207, 2016年12月31日
- 高橋治輝、宮下芳明「水平面の造形を用いて3Dプリンタの造形領域を拡張する手法の提案」ヒューマンインタフェース学会論文誌 19(1), pp.77-86, 2017年2月25日
- Haruki Takahashi, Homei Miyashita. "Expressive Fused Deposition Modeling by Controlling Extruder Height and Extrusion Amount." Proceedings of the 2017 CHI Conference on Human Factors in Computing Systems, pp.5065-5074. DOI: 10.1145/3025453.3025933
- 高橋治輝、宮下芳明「Road単位の造形に着目した熱溶解積層方式3Dプリンタでの質感表現」情報処理学会論文誌 59(2), pp.644-656, 2018年2月15日
- 高橋治輝、宮下芳明「熱溶解積層方式3Dプリンタの造形工程の観察と介入を前提とした一時停止命令の再設計」ヒューマンインタフェース学会論文誌 20(1), pp.135-146, 2018年
- 高橋治輝「熱溶解積層方式3Dプリンタの造形手法を用いた『たんぽぽの綿毛』の制作」芸術科学会論文誌 18(2), pp.87-96, 2019年6月30日
- Haruki Takahashi, Jeeeun Kim. "3D Printed Fabric: Techniques for Design and 3D Weaving Programmable Textiles." Proceedings of the 32nd Annual ACM Symposium on User Interface Software and Technology (UIST 2019), pp.43-51. DOI: 10.1145/3332165.3347896
- Haruki Takahashi, Parinya Punpongsanon, Jeeeun Kim. "Programmable Filament: Printed Filaments for Multi-material 3D Printing." Proceedings of the 33rd Annual ACM Symposium on User Interface Software and Technology (UIST 2020), pp.1209-1221. DOI: 10.1145/3379337.3415863
- Himani Deshpande, Haruki Takahashi, Jeeeun Kim. "EscapeLoom: Fabricating New Affordances for Hand Weaving." Proceedings of the 2021 CHI Conference on Human Factors in Computing Systems, pp.1-13. DOI: 10.1145/3411764.3445600
- Kosei Kamata, Haruki Takahashi, Koji Tsukada. "Conductive, Ferromagnetic and Bendable 3D Printed Hair for Designing Interactive Objects." Adjunct Proceedings of the 36th Annual ACM Symposium on User Interface Software and Technology (UIST 2023), pp.1-3. DOI: 10.1145/3586182.3615823（Crossrefに登録された題名は副題を重ねた形になっているので、引用時は上記の主題だけを書けばよい）
- 鎌田航誠、高橋治輝、塚田浩二「導電性・強磁性・および土台の可撓性を持つ毛構造の造形手法と評価」情報処理学会論文誌 66(2), pp.381-390, 2025年2月15日
- 高橋治輝「熱溶解積層方式3Dプリンタのブリッジ造形における太さ制御を用いた濃淡とモアレ表現」芸術科学会論文誌 23(2), pp.2_1-2_13, 2024年6月26日

このうちProgrammable Filamentは、複数材料を1本のフィラメントの長さ方向に符号化するという意味で「造形素材そのものに情報の列を刻む」発想を含んでおり、CipherFluteの「1本の笛に1シンボル」という設計と比較すると興味深いが、目的は多材料造形であってデータ搬送ではない。

塚田浩二（公立はこだて未来大学システム情報科学部 情報アーキテクチャ学科 教授）も、日用品とファブリケーションを結ぶ研究を継続している。所属と職名は https://www.fun.ac.jp/faculty/tsukada-koji/ で確認した。

- 新山大翔、沖真帆、塚田浩二「3Dプリンターの特性に配慮した汎用ジョイント機構の提案」エンタテインメントコンピューティングシンポジウム2016論文集, pp.252-258, 2016年（確認先: https://cir.nii.ac.jp/all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 。CiNiiの書誌には月の情報が無いため、当初書いてあった「11月」という記載は落とした）
- 菊地勇斗、塚田浩二「3Dプリンタを用いた封蝋表現手法の研究」エンタテインメントコンピューティングシンポジウム2023論文集, pp.270-278, 2023年（確認先は同上。月の情報は同じ理由で落とした。なお同じ研究はWISS 2022でも「3Dプリンタを用いた封蝋表現手法の提案」というやや違う題名のデモ発表3-B04として発表されている）
- 新山大翔、沖真帆、塚田浩二「3Dプリンターによる一体造形式回転機構の提案」WISS 2019 登壇発表6（確認先: https://www.wiss.org/WISS2019Proceedings/oral/6.pdf の予稿本文を描画して題名と著者3名を照合した）
- 島元諒、塚田浩二「RhinestonePrinter: カスタマイズ可能なラインストーン造形手法の提案」WISS 2022 ロングティザー発表T05およびデモ発表2-C02（確認先: https://www.wiss.org/WISS2022Proceedings/ ）。同じ研究がインタラクション2024の登壇発表INT24018でも発表されているが、そのときの題名は「RhinestonePrinter: カスタマイズ可能なラインストーン造形手法の研究」と末尾が「研究」に変わっている（確認先: https://www.interaction-ipsj.org/proceedings/2024/data/oral.html ）。引用するときはどちらの場で発表されたものを指すのかで題名を書き分ける必要がある

### 印刷物に電気的な機能や入力機能を持たせる系統

以下の英語論文4件はすべて、DOIをCrossref APIで解決して題名、著者の並び、掲載巻、ページを照合した。

- Kunihiro Kato, Kaori Ikematsu, Hiromi Nakamura, Hinako Suzaki, Yuki Igarashi. "FoodSkin: Fabricating Edible Gold Leaf Circuits on Food Surfaces." Proceedings of the CHI Conference on Human Factors in Computing Systems 2024, pp.1-17. DOI: 10.1145/3613904.3642372
- Ayaka Ishii, Kunihiro Kato, Kaori Ikematsu, Yoshihiro Kawahara, Itiro Siio. "CircWood: Laser Printed Circuit Boards and Sensors for Affordable DIY Woodworking." Sixteenth International Conference on Tangible, Embedded, and Embodied Interaction (TEI 2022), pp.1-11. DOI: 10.1145/3490149.3501317
- 加藤邦拓、齋藤一哉、川原圭博（発表当時はいずれも東京大学）「Inkjet Printed Speaker: 導電性インクの印刷だけで作る折り紙スピーカー」WISS 2018 デモ・ポスター発表1-A15（確認先: https://www.wiss.org/WISS2018Proceedings/ で題名、著者3名、所属、発表番号を確認した。また https://researchmap.jp/kkunihir で加藤邦拓の経歴を確認した）
- Kaori Ikematsu, Masaaki Fukumoto, Itiro Siio. "Ohmic-Sticker: Force-to-Motion Type Input Device that Extends Capacitive Touch Surface." Proceedings of the 32nd Annual ACM Symposium on User Interface Software and Technology (UIST 2019), pp.1021-1030. DOI: 10.1145/3332165.3347903（関連する短報がExtended Abstracts of the 2019 CHI Conference on Human Factors in Computing Systems, pp.1-6, DOI: 10.1145/3290607.3312936 にある。ただし短報の題名は "Ohmic-Sticker: Force-to-Motion Type Input Device for Capacitive Touch Surface" であり、"that Extends" ではなく "for" になっている。当初「同名の短報」と書いてあったのは誤りであり、題名は同じでないので訂正した）
- 郭安邦、太田高志、加藤邦拓（いずれも発表当時は東京工科大学）「金彩回路を用いたオカリナ演奏支援システム」WISS 2025 デモ発表 2-C23（確認先: https://www.wiss.org/WISS2025Proceedings/data/demo/2-C23.pdf の予稿本文2ページを取得して描画し、題名、著者3名、所属、参考文献まで読了した）

最後の一件は、陶磁器製のオカリナの表面に金彩技法で回路を描いて焼成し、静電容量方式のタッチセンシングによって指孔の押下状態を可視化する演奏支援システムである。予稿によれば、釉薬層の上に陶芸用セラミックマーカーで回路パターンを描き、小型の陶芸窯で摂氏750度、35分で焼成して導電性を得ている。指孔の静電容量変化をArduinoで取得し、パソコン側のWebアプリケーションが五線譜と運指を表示する。日本のHCI分野で「笛」を扱った直近の研究であり、CipherFluteが笛を扱ううえで挨拶として引くべき隣接研究だが、目的は演奏学習の支援であって情報の搬送ではなく、しかも回路とマイコンと電源を必要とするため、CipherFluteの「電源も電子部品も持たない」という主張とは正反対の立場にある。

この演奏支援システムが土台にしている回路作成技術も、書誌を確定できた。坂田亮一（キンミライガッキ現代支部）、吉松駿平（電化工藝）、星川あすか（無所属）、加藤邦拓（東京工科大学）「金彩技法を用いた陶磁器表面への回路作成」インタラクション2025論文集, pp.1221-1225, 2025年、インタラクティブ発表3B-48である。確認先は情報処理学会インタラクション2025のインタラクティブ発表一覧 https://www.interaction-ipsj.org/proceedings/2025/data/interactive.html であり、題名、著者4名、所属、発表番号を確認した。ページ番号は上記オカリナ論文の参考文献[7]の記載による。これは当初「未検証のまま残ったもの」に置かれていた項目であり、検証によって解消したのでここへ移した。

### 紙や布などの素材を計算機で加工する系統

- Koya Narumi, Kazuki Koyama, Kai Suto, Yuta Noma, Hiroki Sato, Tomohiro Tachi, Masaaki Sugimoto, Takeo Igarashi, Yoshihiro Kawahara. "Inkjet 4D Print: Self-folding Tessellated Origami Objects by Inkjet UV Printing." ACM Transactions on Graphics 42(4), pp.1-13, 2023. DOI: 10.1145/3592409
- Yuta Noma, Koya Narumi, Fuminori Okuya, Yoshihiro Kawahara. "Pop-up Print: Rapidly 3D Printing Mechanically Reversible Objects in the Folded State." Proceedings of UIST 2020, pp.58-70. DOI: 10.1145/3379337.3415853
- Koya Narumi, Fang Qin, Siyuan Liu, Huai-Yu Cheng, Jianzhe Gu, Yoshihiro Kawahara, Mohammad Islam, Lining Yao. "Self-healing UI: Mechanically and Electrically Self-healing Materials for Sensing and Actuation Interfaces." Proceedings of UIST 2019, pp.293-306. DOI: 10.1145/3332165.3347901
- Koya Narumi, Hiroki Sato, Kenichi Nakahara, Young ah Seong, Kunihiko Morinaga, Yasuaki Kakehi, Ryuma Niiyama, Yoshihiro Kawahara. "Liquid Pouch Motors: Printable Planar Actuators Driven by Liquid-to-Gas Phase Change for Shape-Changing Interfaces." IEEE Robotics and Automation Letters 5(3), pp.3915-3922, 2020. DOI: 10.1109/lra.2020.2983681
- Mikihito Matsuura, Koya Narumi, Toshiki Aoki, Yuta Noma, Kazutaka Nakashima, Yoshihiro Kawahara, Takeo Igarashi. "Blow-up Print: Rapidly 3D Printing Inflatable Objects in the Compressed State." ACM SIGGRAPH 2022 Posters, pp.1-2. DOI: 10.1145/3532719.3543230

上記5件の書誌はいずれもDOIをCrossref APIで解決して題名、著者の並び、誌名または会議名、巻号、年、ページを照合した。この系統には、五十嵐悠紀による手芸やクラフトの設計支援、山岡潤一（慶應義塾大学大学院メディアデザイン研究科 准教授）による熱膨張素材や粘土素材を用いた造形、筧康明（東京大学大学院情報学環・学際情報学府 教授）によるマテリアルインタラクションの研究が連なる。所属と職名は https://k-ris.keio.ac.jp/html/100012354_ja.html および https://www.iii.u-tokyo.ac.jp/faculty/kakehi_yasuaki で確認した。なお鳴海紘也は、WISS 2025の予稿集一覧では慶應義塾大学の所属として記載されており、東京大学から移っている。上の書誌に並ぶ論文はいずれも東京大学在籍時のものである。

なお日本には、日本画像学会の特別興味研究会として「4D and Functional Fabrication研究会」があり、電子論文誌「The Journal of 4D and Functional Fabrication」（略称J4DFF、オンラインISSN 2435-4767）を2020年から発行している。第1号が2020年、第2号が2021年10月16日、第3号が2024年8月31日、第4号が2025年8月1日の発行であり、第5号は2026年10月初旬の予定と告知されている（確認先: https://sig4dff.org/ および https://sig4dff.org/j4dff/ ）。デジタルファブリケーションの国内の受け皿としてWISS以外にもこの場があることは、投稿先の選択肢としても関連研究の探索先としても押さえておくとよい。

### WISSにおける関連発表（2014年から2025年まで、脅威が低いもの）

WISSの各年の予稿集ページ（https://www.wiss.org/ の各年へのリンク）を1年ずつ開いて確認した結果、デジタルファブリケーション、3Dプリント、音響、タグ、センシングに関わる発表として次のようなものがあった。いずれも背景としての参照にとどまる。検証にあたって、各年の予稿集ページで題名と著者と所属と発表番号を照合し、当初「ほか」で省略されていた著者名を補い、途中で切れていた題名を正した。

- 2014年: 池田昂平、塚田浩二「CapacitiveMarker: 静電パターンを内包した接触認識可能な2次元コード」（デモ発表2A-01）、鈴木良平、坂本大介、五十嵐健夫「AnnoTone: 高周波音の映像収録時埋め込みによる編集支援」（登壇発表）、鷹見洋介、吉田博則、小渕祐介、五十嵐健夫「プロジェクションマッピングを用いた建設用3D積層造形技術」（登壇発表）
- 2015年: 高橋治輝、宮下芳明「3Dプリンタの造形中もモデリング可能なインタラクティブ・ファブリケーション」（デモ発表2-R09）、新山大翔、沖真帆、塚田浩二「ファブ時代に適した新たなジョイント機構の提案」（デモ発表2-R16）
- 2016年: 高橋治輝、宮下芳明「造形高さと樹脂量の設定による熱溶解積層方式3Dプリンタの表現力拡張」（登壇発表26）、秋山耀、宮下芳明「3DプリンタのためのPaper User Interface」（登壇発表25）、上野新葉、宮下芳明「熱溶解積層方式3Dプリンタにおけるエクストルーダ内での相溶性を利用した硬軟制御手法」（デモ発表3-A23）
- 2017年: 奥山瑞希、的場やすし、椎尾一郎「M系列円筒バーコードとAR和服帯試着システムへの応用」（登壇発表04。本稿では脅威が中の文献として上に別項を立てた）、高橋治輝、宮下芳明「ブリッジ構造と樹脂の引き伸ばしを用いた高密度な毛構造の造形手法」（デモ発表2-A21）、加藤邦拓、石塚裕己、梶本裕之、宮下芳明「導電性インクの両面印刷による電気刺激と静電吸着を用いた複合触覚ディスプレイの作成手法」（登壇発表10）
- 2018年: 鳴海紘也、中原健一、佐藤宏樹、新山龍馬、川原圭博「Liquid Pouch Motors：紙のインタフェースのための薄く軽く柔軟なアクチュエータ」（登壇発表01）、片倉翔平、渡邊恵太「PrintMotion: 3Dプリンタに搭載されたアクチュエータを使用して印刷物を動かす手法の提案」（登壇発表13）、野崎玲那、高橋治輝、宮下芳明「Felting Deposition Modeling: フェルティングニードルを用いた羊毛フェルト3Dプリンタ」（デモ発表1-A06）、迎崇久、宮下芳明「FDM方式3Dプリンタにおける重力を利用した表現力拡張手法の提案」（デモ発表1-A10）
- 2019年: 杉山圭、塚田浩二「UVプリンタを用いたレンズ造形手法とその応用」（登壇発表5）、鳴海紘也ほか7名「Self-healing UI: 機械的かつ電気的に自己修復するセンシングインタフェース」（登壇発表10）、石井綾郁、椎尾一郎「BubBowl: 電気分解を利用したカップ型泡ディスプレイ」（登壇発表16）
- 2020年: 野間裕太、鳴海紘也、奥谷文徳、川原圭博「Pop-up Print: 双安定な折りたたみ3Dプリント」（登壇発表08）、島元諒、塚田浩二「カスタマイズ可能な二次元レンチキュラを用いた多視点情報提示手法の提案」（登壇発表05）、西井遥菜、双見京介、村尾和哉「アクティブ音響センシングを用いた食材認識カトラリー」（登壇発表10）、韓燦教、高橋亮、矢作優知、苗村健「糸状の内部支持構造を持つ高剛性インフレータブルの3Dプリント手法」（査読なし発表N-26）
- 2021年: 石井綾郁、加藤邦拓、池松香、川原圭博、椎尾一郎「CircWood: CWレーザー加工機による炭化を利用した木製回路基板」（登壇発表16）、Maria Larsson、吉田博則、梅谷信行、五十嵐健夫「TSUGITE: インタラクティブな木工ジョイントの設計・加工システム」（登壇発表12）、高橋治輝「3Dプリントした毛を用いた触覚ディスプレイの提案」（デモ発表2-A04）、髙倉礼、鈴木健介、國分晴利、志築文太郎「能動的音響計測に基づくスタイラスの把持状態識別手法の検討」（登壇発表20）
- 2022年: 島元諒、塚田浩二「RhinestonePrinter: カスタマイズ可能なラインストーン造形手法の提案」（ロングティザー発表T05、デモ発表2-C02）、菊地勇斗、塚田浩二「3Dプリンタを用いた封蝋表現手法の提案」（デモ発表3-B04）、元村愛美、中村裕美、池松香、五十嵐悠紀、加藤邦拓「金箔回路を用いた食品の機能的拡張」（デモ発表1-C07）
- 2023年: 鎌田航誠、高橋治輝、塚田浩二「導電性・強磁性・及び土台の可撓性を持つ毛構造の造形手法の提案」（ティザー発表T05、デモ発表1-B07と3-B07）、鳴海紘也ほか8名「Inkjet 4D Print: Self-folding Tessellated Origami Objects by Inkjet UV Printing」（登壇発表17）、岡空来、小山和紀、権藤智之、池田靖史、川原圭博、鳴海紘也「目標の立体形状に変形するレーザーカッターで作製可能な連結型パウチモータ」（デモ発表3-B01）
- 2024年: 高橋治輝、臼井義人、松村耕平「ボタンひとつで3Dプリントが体験できるシステムの提案と運用」（登壇発表12）、加藤邦拓、池松香、中村裕美、須﨑比奈子、五十嵐悠紀「FoodSkin: Fabricating Edible Gold Leaf Circuits on Food Surfaces」（国際学会招待発表22）、山岸真人、高田崚介（いずれも神戸市立工業高等専門学校）「MagElePaint: 多様な素材に簡単に回路プロトタイピングが可能な磁性導電性塗料」（登壇発表13）
- 2025年: 吉本健義、大友千宙、宮下芳明「OpticDesigner：多様な光学レンズ効果をカスタマイズ可能な3Dプリントレンズフィルターデザインシステム」（登壇発表04、デモ発表2-B03。当初は題名の末尾の「デザインシステム」が抜けていたので補った）、臼井義人、高橋治輝、松村耕平「Purikura-Fab：3Dプリンタ未経験者の造形プロセス理解と利用意欲を促進する体験型システムの開発」（登壇発表11、デモ発表2-B15。予稿を確認、https://www.wiss.org/WISS2025Proceedings/data/paper/11.pdf ）、山本匠ほか6名「Zip-up Print: ジッパーを用いた高速かつ省サポート材の3Dプリント手法」（デモ発表2-A03）、高橋治輝、松村耕平「リズムゲームへの入力を3Dプリンタ制御に活用する手法の検討」（デモ発表3-B06）

上記のうちCapacitiveMarkerについては、当初「未検証のまま残ったもの」に置かれていたので、予稿本文を取得して読了した。確認先は https://www.wiss.org/WISS2014Proceedings/demo/097.pdf である。内容は次のとおりである。2次元コードを印刷したシール紙と、導電インクでパターンを印刷した透明プラスチックフィルムの2枚を重ね合わせた構造を持ち、カメラと静電容量方式タッチディスプレイのどちらからも認識できる。静電マーカーは周辺部に3点の固定点と中央部に1点の可変点を置き、固定点から見た可変点の相対位置の変化でIDを表す。マーカー全体の大きさは40ミリメートル角であり、ARマーカーは普通のインクジェットプリンターで、静電マーカーは銀ナノインクを使うインクジェットプリンターで出力する。著者の所属は公立はこだて未来大学システム情報科学部情報アーキテクチャ学科である。すなわちこれは紙とフィルムを貼り合わせた印刷物であって、3Dプリンタの造形物の内部に情報を埋め込むものではない。当初この文献について「造形物に静電パターンを内包させるという点で、造形物への情報埋め込みの国内先行として重要な可能性がある」と書かれていたが、それは誤った見立てだったので取り消す。CipherFluteとの関係は「物体側に電源も電子部品も持たず、印刷した幾何そのものが少数ビットのIDを運ぶ」という点にとどまり、脅威の度合いは「低」である。

## 未検証のまま残ったもの

2026年7月30日の検証の時点で、この節に残るのは次の1件だけである。当初この節にあった6件のうち、5件は一次資料に当たって書誌を確定させ、それぞれ本文の該当箇所へ移した。残る1件は実在しない文献だったので削除し、末尾の「検証で削除したもの」に記録した。ただし書誌を確定させた5件のうち1件については、書誌そのものとは別に、受賞との対応関係という枝葉が確認できずに残ったので、それを下に1件として書いてある。

1. 加藤邦拓が2025年3月に情報処理学会インタラクティブ発表賞（一般投票部門）を受賞したという記載。当初の記述はこれを「金彩技法を用いた陶磁器表面への回路作成」に対する受賞として扱っていたが、受賞対象がその発表であるという対応関係を一次資料で確認できていない。論文の書誌自体は確定したので引用に支障はないが、受賞歴を書くのであれば情報処理学会の受賞一覧で確認する必要がある。

書誌を確定させた5件は次のとおりである。

- 坂田ほか「金彩技法を用いた陶磁器表面への回路作成」は、情報処理学会インタラクション2025のインタラクティブ発表一覧で著者4名と所属と発表番号3B-48を確認し、ページ番号はWISS 2025のオカリナ論文の参考文献[7]の記載で確定した。書誌は「印刷物に電気的な機能や入力機能を持たせる系統」の節に移した。
- 城一裕の作品に対応する査読付き論文は、Kazuhiro Jo, Paul DeMarinis. "Life in the groove: Re-visiting the common sense of sound reproduction." Proceedings of RE:SOUND 2019, Electronic Workshops in Computing, pp.72-75, 2019, DOI: 10.14236/ewic/resound19.11 として確定した。DOIをCrossref APIで解決して題名、著者、会議名を確認し、ページ数はresearchmapの本人ページの記載による。書誌は脅威が大きい文献の8番へ移した。
- WISS 2017の「M系列円筒バーコードとAR和服帯試着システムへの応用」は予稿本文を取得して読了し、著者3名と所属も確定した。CipherFluteとの関係が当初の見立てより深いことが分かったため、脅威が大きい文献の9番として独立した項目を立てた。
- WISS 2014の「CapacitiveMarker」も予稿本文を取得して読了した。内容は紙とフィルムを貼り合わせた印刷物であり、3Dプリント造形物への情報埋め込みではなかった。訂正した記述はWISSの各年の一覧の直後に書いた。
- 高橋治輝、宮下芳明「ブリッジ構造と樹脂の引き伸ばしを用いた高密度な毛構造の造形手法」については、WISS 2017のデモ発表2-A21として予稿本文を取得し、題名、著者2名、所属（明治大学大学院先端数理科学研究科）を確認した。対応する学会論文誌版については、CiNii Researchでこの2名の共著論文を検索した結果、毛構造を主題とする論文誌論文は見つからなかった。毛構造に関する論文誌の成果は、高橋治輝の単著「熱溶解積層方式3Dプリンタの造形手法を用いた『たんぽぽの綿毛』の制作」（芸術科学会論文誌 18(2), 2019年）と、鎌田航誠、高橋治輝、塚田浩二の共著（情報処理学会論文誌 66(2), 2025年）であり、いずれも上に書誌を挙げてある。したがって「対応する学会論文誌版が未確定」という状態は解消した。

## この切り口で見つからなかったこと

以下は、複数の検索を尽くしたうえで「日本のHCI分野には存在しない」と述べてよいと考える事柄である。これらはCipherFluteの新規性の主張の根拠になる。

第一に、笛（気鳴楽器）の管長と基本周波数の関係を設計変数として扱い、音高を情報の符号として使う日本の研究は見つからなかった。CiNii Researchで「3Dプリンタ 楽器 音響設計」「笛 音階 設計 3Dプリンタ」「3Dプリンタ 共鳴 設計 音」を検索したが、該当する論文は0件であった（確認先: https://cir.nii.ac.jp/all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 、https://cir.nii.ac.jp/all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 ）。「3Dプリンタ 楽器」で得られた結果は、ロボットによる電子楽器演奏や音楽教育の教材開発であり、笛の音響設計を扱うものではなかった。WISS 2014年から2025年までの予稿集を通しても、笛やオカリナを扱った発表はWISS 2025の「金彩回路を用いたオカリナ演奏支援システム」1件のみで、それは既製のオカリナに回路を描いて演奏を支援するものであり、笛を情報の担体として設計する研究ではなかった。

第二に、人間が息を吹き込むだけで（電源も計測器も機械学習も用いずに）多ビットのデータを読み出せる物理媒体を提案した日本の研究は見つからなかった。国内の音響を用いた読み出し研究は、久保らのFabAuth、片倉らのProtoHole、岩瀬らの日常物体識別、大野らのTouch & Activate、林らの棒の引っかき、いずれも圧電素子やスピーカとマイクによる能動計測を前提としている。CiNii Researchで「電源不要 タグ 音 識別 造形」を検索した結果も0件であった（確認先: https://cir.nii.ac.jp/all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 ）。

第三に、造形物が運ぶ物理的な符号に対して誤り訂正符号を適用した日本の研究は見つからなかった。久保らの研究は機械学習の識別精度で頑健性を確保しており、鳥井らの研究は光学的な読み取りの信頼性で確保している。Reed–Solomon符号のような誤り訂正、隣接シンボルの同一値を禁じる遷移保証の制約、既知の音高を持つ基準笛による全体のずれの正規化のいずれについても、国内の先行研究は見つからなかった。

ただしこの第三の点は、検証の結果として書き方を弱めた。当初は「通信工学の道具立てを物理造形の符号設計に持ち込んだ国内の先行研究は存在しない」と書かれていたが、これは言い過ぎである。奥山瑞希、的場やすし、椎尾一郎のWISS 2017の研究は、M系列（最大長系列）という通信工学の系列設計を円筒バーコードの符号に持ち込み、部分列の一意性という性質を使って回転角度を決めている。これは誤り訂正でも正規化でもないが、通信の符号理論を物理的な造形に持ち込んだ国内の先例である。したがってCipherFluteが主張できるのは「通信工学の道具立てを持ち込んだ最初の国内研究である」ではなく、「誤り訂正符号と遷移保証と基準による正規化という3点の組み合わせを物理造形の符号設計に持ち込んだ国内先行は見つからなかった」という、より限定した言い方である。

第四に、暗号資産のリカバリーシードのような秘密情報を物理媒体へ保管することを扱った日本のHCI研究は見つからなかった。秘密分散そのものについては情報セキュリティ分野に研究があるが、それは計算機上のデータのバックアップや秘密計算の文脈であり、物理的な造形物に秘密を刻んで日用品に偽装するという設計や、そのユーザビリティを扱った国内のHCI研究は見つからなかった。

第五に、造形物への情報埋め込みを「探索コストの引き上げ」という観点から論じ、物理層に暗号学的な秘匿を期待しないと明示的に宣言した日本の研究は見つからなかった。国内の先行研究のうち鳥井らの一連の研究は著作権保護と真贋判定を応用として掲げており、久保らの研究も真贋判定を挙げているが、どちらも「物理層には秘匿の力がまったく無い」と宣言したうえで秘密分散に守りを委ねるという脅威モデルの立て方はしていない。

第六に、WISSにおいて「音を鍵として情報を読み出す」というテーマの発表は、2014年から2025年までを通して見つからなかった。音を扱う発表は多数あるが、その大半は楽器演奏の支援、歌声や音楽コンテンツのインタフェース、音響センシングによる入力認識であり、音を情報の符号として設計するものではなかった。

## 調べ残した穴

第一に、情報処理学会のインタラクションシンポジウムについては、2018年、2024年、2025年のプログラムしか通していない。2025年については検証の際に登壇発表とインタラクティブ発表の一覧を両方開いたが、2024年は登壇発表の一覧だけである。2014年から2023年までのデモ発表とインタラクティブ発表には、まだファブリケーションと音響に関わる発表が埋もれている可能性がある。とくにデモ発表は件数が多く、目次を機械的に読むだけでは拾いきれない。

第二に、情報処理学会ヒューマンコンピュータインタラクション研究会（HCI研究会）の研究報告は、まったく手をつけられなかった。情報処理学会電子図書館の検索インタフェースにWebFetchで直接問い合わせても応答が得られず、これは検証の際に改めて試しても同じであった。CiNii Researchを経由した検索で代替したが、研究報告レベルの発表は網羅できていない。ここには、まだ論文誌に至っていない初期段階の「造形物に情報を埋め込む」研究が存在する可能性がある。

第三に、エンタテインメントコンピューティングシンポジウム（EC）と日本バーチャルリアリティ学会の論文誌については、塚田浩二の業績を通じて一部を確認したにとどまる。日本バーチャルリアリティ学会論文誌には「デジタルファブリケーションとVR」という特集号があり（塚田浩二がゲストエディタを務めた）、そこには国内のファブリケーション研究がまとまっている可能性が高いが、目次を確認できなかった。

第四に、日本画像学会の4D and Functional Fabrication研究会の電子論文誌J4DFFについては、正式名称が「The Journal of 4D and Functional Fabrication」、オンラインISSNが2435-4767であり、第1号（2020年）から第4号（2025年8月1日）までが発行されていることを確認したが、各号の目次を取得できなかった。この研究会は画像工学と材料工学の側からファブリケーションに近づいており、HCI分野からは見えにくい先行研究が含まれている可能性がある。

第五に、有力文献の被引用をたどる作業を十分に行えていない。とくに久保らのFabAuthを引用している後続研究、およびAcoustic BarcodesとLamelloを引用している日本の研究を網羅的に洗い出せば、まだ隣接研究が出てくる可能性がある。検証の作業でも、Semantic ScholarとCrossrefで個別の書誌を解決することはできたが、被引用一覧を横断的にたどるところまでは進めなかった。

第六に、城一裕と松浦知也を中心とするメディアアートとサウンドアートの領域は、査読付き論文の形をとらない実践が多く、学術データベースからは見つけにくい。CipherFluteの発想に最も近い実践がこの領域にある可能性があり、展覧会カタログや作家のウェブサイトを直接当たる作業が残っている。なお城一裕については、検証の過程でRE:SOUND 2019の査読付き論文が見つかったので、この領域の実践にも学術的な書誌が付いている場合があることは分かった。松浦知也については何も確認していない。

## 検証で削除したもの

以下は、2026年7月30日の検証で「実在しない文献である」と判断し、この文書から削除したものである。

1. 久保勇貴らのFabAuthの系列にあるとされたSensors誌の論文。当初は「未検証のまま残ったもの」の3番に、識別子がs20174921と推定される論文が存在するという情報を検索結果で見た、と書かれていた。検証のためにDOI 10.3390/s20174921 をCrossref APIで解決したところ（確認先: https://api.crossref.org/works/10.3390/s20174921 ）、その識別子が指すのはKamil Krasuski, Adam Ciećko, Mieczysław Bakuła, Damian Wierzbickiによる "New Strategy for Improving the Accuracy of Aircraft Positioning Based on GPS SPP Solution"（Sensors 20(17), 論文番号4921, 2020年）であった。航空機の測位精度に関する論文であり、3Dプリントにも音響センシングにも何の関係もない。さらに久保勇貴本人の業績ページ（確認先: https://www.yukikubo.net/index-e.html ）に掲載されている査読付き論文誌の論文は情報処理学会論文誌、IMWUT、IEEE Accessの3件であり、Sensors誌の論文は1件も無い。FabAuthの系列として本人が挙げているのはCHI 2019とCHI 2020のLate-breaking Workの2件だけである。したがって「FabAuthのSensors誌版」は存在しないと判断し、この項目を削除した。誤った識別子から誤った文献を組み立ててしまう典型例なので、記録として残す。

## 検証の記録

2026年7月30日に、この文書に書かれた書誌情報の独立した検証を行った。検証は別の調査担当者が書いた原稿を疑ってかかる立場で進め、Web検索の結果だけで済ませず、一次資料に直接当たることを原則とした。具体的には、ACMなどの文献についてはDOIをCrossref APIで解決して題名と著者の並びと掲載巻とページを照合し、日本語の文献についてはCiNii Researchの検索結果で誌名と巻号とページと年月を照合し、WISSとインタラクションの発表については学会の予稿集ページと予稿本文のPDFそのものを取得して読んだ。予稿本文のPDFは日本語の文字が正しく取り出せないものが多かったため、ページを画像に描画して目で読み、著者名は必要に応じて高解像度に拡大して1文字ずつ確かめた。

確認した文献と事例は合計で75件である。内訳は、脅威が大きいとされた文献の群が9件（うち神奈川工科大学の一連の研究は個別の発表8件と研究課題2件を含む）、背景として挙げられた高橋治輝の業績が12件、塚田浩二の業績が4件、印刷物に電気的な機能を持たせる系統が6件、紙や布の系統が5件、WISSの各年の関連発表が33件、および所属や職名などの事実確認が7件である。

訂正は12箇所に加えた。主なものを挙げる。第一に、WISS 2025の「棒の引っかきによる音波を用いたインタラクション取得手法の検討」の著者名が「岩本諒」と書かれていたが、予稿本文と予稿集一覧はいずれも「岩本涼」であり、1文字の誤りを直した。第二に、久保らのWISS 2019論文について「2台のUltimaker S5で造形した物体を混ぜると識別精度は平均60.2パーセントまで落ちる」と書かれていたが、原典では60.2パーセントはSupport Vector Machineの値であり、Random Forestでは47.2パーセントである。都合のよい方の数字だけを引いていたことになるので、両方の数字を書いた。第三に、Ohmic-StickerのCHI 2019短報を「同名の短報」と書いていたが、題名は "that Extends" ではなく "for" であって同名ではないため、正確に書き直した。第四に、WISS 2025のOpticDesignerの題名が末尾の「デザインシステム」を欠いた形で書かれていたので補った。第五に、城一裕の受賞を「2021年の文化庁メディア芸術祭エンターテインメント部門推薦作品」と書いていたが、正確には第24回文化庁メディア芸術祭エンターテインメント部門の審査委員会推薦作品であり、対象作品は2020年のオンラインパフォーマンスであるため、回次と賞の名称を正した。第六に、RhinestonePrinterの題名がWISS 2022とインタラクション2024で「提案」と「研究」に分かれていることを書き加えた。第七に、塚田浩二の2件の予稿集論文に付いていた発表月は、CiNii Researchの書誌に月の情報が無く裏を取れなかったため落とした。第八に、当初の「通信工学の道具立てを物理造形の符号設計に持ち込んだ国内の先行研究は存在しない」という主張は、M系列を使う奥山らの研究が反例になるため、誤り訂正と遷移保証と正規化の3点の組み合わせに限定した言い方へ弱めた。このほか、当初は「ほか」で省略されていた著者名を予稿集一覧で確かめて補い、発表番号と発表形態（登壇発表かデモ発表か）を各件に書き足した。

実在が確認できず削除したものは1件である。「未検証のまま残ったもの」の3番にあった、FabAuthの系列とされるSensors誌の論文である。推定されていた識別子が指すのは航空機測位の無関係な論文であり、著者本人の業績ページにもSensors誌の論文は無い。詳細は「検証で削除したもの」の節に書いた。

未検証のまま残ったものは、当初の6件から1件に減った。5件は一次資料に当たって書誌を確定させ、それぞれ本文の該当箇所へ移した。とくにWISS 2017の「M系列円筒バーコードとAR和服帯試着システムへの応用」は、予稿本文を読んだ結果としてCipherFluteとの関係が当初の見立てより深いことが分かったため、脅威が中の文献として独立した項目を立てた。逆にWISS 2014の「CapacitiveMarker」は、予稿本文を読んだ結果として3Dプリント造形物への情報埋め込みではなく紙とフィルムの印刷物であることが分かったため、当初の見立てを取り消して脅威を低と判定した。残った1件は、加藤邦拓の2025年3月の情報処理学会インタラクティブ発表賞が「金彩技法を用いた陶磁器表面への回路作成」に対する受賞であるという対応関係であり、これは論文の書誌そのものとは切り離せたので、引用には支障がない。

検証を通じて、この文書に書かれていた書誌情報の大半は正確であった。とくに神奈川工科大学の8件の技術研究報告は、著者の並びの細かい入れ替わりまで含めてCiNii Researchの書誌と一致しており、思い込みで書かれたものではないと判断できる。一方で、実在しない文献が1件混ざっていたこと、数値の引き方に都合のよい選択が1箇所あったこと、題名の一部が落ちていたものが複数あったことは、この種の一覧を論文の参考文献としてそのまま使うことの危うさを示している。CipherFluteの論文に載せる際は、少なくとも本文で言及する文献については、もう一度出版社のページで最終的な体裁を確かめることを勧める。

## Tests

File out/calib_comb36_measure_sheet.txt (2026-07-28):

較正コーム36本（12音 G#6〜G7 を各3本）測定記入表

開くURL: https://qurihara.github.io/ai-fue/cipher/#pitchsplit=1&splitcents=80&minnote=80
吹き方: 「続けて吹く」を押し、最初の0.4秒は静かにする。左から右へ36本を一気に吹く。
        1本0.5から1秒、全体で30秒ほど。吹き終えたら「終了し復号」を押す。
        札が36枚にならなければ splitcents を増減してやり直す。これを3回繰り返す。
鳴らない笛は「この笛は飛ばす」で位置を空け、この表では - と書く。
両端がめくれなどの造形不良で鳴らないときは、生きている連続範囲だけを吹いてよい。
その場合は範囲を指定して集計する: python3 fue/calib_comb.py このファイル --range=4-33
（両端4本ずつまでなら、どの音も2本以上残る。5本ずつだとB6とC7が1本になる。）

集計: python3 fue/calib_comb.py このファイル

室温:        度

[並び（番号と音名、および設計上の管長と狙いの周波数）]
  第1区画
     1 G#6  L= 62.1mm  狙い 1661.2Hz
     2 A6   L= 59.1mm  狙い 1760.0Hz
     3 A#6  L= 56.2mm  狙い 1864.7Hz
     4 B6   L= 53.6mm  狙い 1975.5Hz
     5 C7   L= 51.0mm  狙い 2093.0Hz
     6 C#7  L= 48.7mm  狙い 2217.5Hz
     7 D7   L= 46.4mm  狙い 2349.3Hz
     8 D#7  L= 44.3mm  狙い 2489.0Hz
     9 E7   L= 42.3mm  狙い 2637.0Hz
    10 F7   L= 40.4mm  狙い 2793.8Hz
    11 F#7  L= 38.6mm  狙い 2960.0Hz
    12 G7   L= 36.9mm  狙い 3136.0Hz
  第2区画
    13 C7   L= 51.0mm  狙い 2093.0Hz
    14 C#7  L= 48.7mm  狙い 2217.5Hz
    15 D7   L= 46.4mm  狙い 2349.3Hz
    16 D#7  L= 44.3mm  狙い 2489.0Hz
    17 E7   L= 42.3mm  狙い 2637.0Hz
    18 F7   L= 40.4mm  狙い 2793.8Hz
    19 F#7  L= 38.6mm  狙い 2960.0Hz
    20 G7   L= 36.9mm  狙い 3136.0Hz
    21 G#6  L= 62.1mm  狙い 1661.2Hz
    22 A6   L= 59.1mm  狙い 1760.0Hz
    23 A#6  L= 56.2mm  狙い 1864.7Hz
    24 B6   L= 53.6mm  狙い 1975.5Hz
  第3区画
    25 E7   L= 42.3mm  狙い 2637.0Hz
    26 F7   L= 40.4mm  狙い 2793.8Hz
    27 F#7  L= 38.6mm  狙い 2960.0Hz
    28 G7   L= 36.9mm  狙い 3136.0Hz
    29 G#6  L= 62.1mm  狙い 1661.2Hz
    30 A6   L= 59.1mm  狙い 1760.0Hz
    31 A#6  L= 56.2mm  狙い 1864.7Hz
    32 B6   L= 53.6mm  狙い 1975.5Hz
    33 C7   L= 51.0mm  狙い 2093.0Hz
    34 C#7  L= 48.7mm  狙い 2217.5Hz
    35 D7   L= 46.4mm  狙い 2349.3Hz
    36 D#7  L= 44.3mm  狙い 2489.0Hz

[記入欄] 1行に12個ずつ、3行で1回ぶん。空行で回を区切る。

# 1回目
  ____ ____ ____ ____ ____ ____ ____ ____ ____ ____ ____ ____    #  1〜12番
  ____ ____ ____ ____ ____ ____ ____ ____ ____ ____ ____ ____    # 13〜24番
  ____ ____ ____ ____ ____ ____ ____ ____ ____ ____ ____ ____    # 25〜36番

# 2回目
  ____ ____ ____ ____ ____ ____ ____ ____ ____ ____ ____ ____    #  1〜12番
  ____ ____ ____ ____ ____ ____ ____ ____ ____ ____ ____ ____    # 13〜24番
  ____ ____ ____ ____ ____ ____ ____ ____ ____ ____ ____ ____    # 25〜36番

# 3回目
  ____ ____ ____ ____ ____ ____ ____ ____ ____ ____ ____ ____    #  1〜12番
  ____ ____ ____ ____ ____ ____ ____ ____ ____ ____ ____ ____    # 13〜24番
  ____ ____ ____ ____ ____ ____ ____ ____ ____ ____ ____ ____    # 25〜36番

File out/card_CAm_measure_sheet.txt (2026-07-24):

C/Amカード 測定シート（プレート付き名刺版・f=A/(L+e), A=86338 e=-13.06 で設計）
各笛を1本ずつ吹いて基音Hzを測り『測定Hz』へ。目標Hzは平均律のその音。ズレから式を再フィット。

★2026/7/23 較正確定: 両カード全域(40.6〜68.1mm)を測定し再フィット完了。
  f=A/(L+e), A=85695.9, e=-12.570（RMS 17.8セント）。out/mini10_calib_v11.txt に記録。
  全管が約0.8mm短くなる方向で、デッキを約35セント上げてピッチに合わせる。
  実測フラット量: G7 -12 / F7 -63 / E7 -59 / D7 -35 / C7 -49 / B6 -32 / A6 -27 / G6 -7 セント。
  最終v1.1（全12調）は out/chordika_v11_*.stl に再生成済み。

★2026/7/23 実測メモ（低音版カードを測定・初回）:
  ・並び順は【逆順】と確定。左端から D7 · B6 · G6 · E7 · C7 · A6 · F7 · D7（両端がD7で照合）。
  ・クリーンに読めた6本は全て一貫して低め（−14〜−51セント, RMS39）。設計管長だと実音がやや低く出る。
  ・クリーン6点で暫定再フィット → A=88475, e=-11.20（RMS 7.1セント）。管長は旧値より 0.5〜1.1mm 短くなる方向。
  ・要・再測定（クリーンな基音が取れなかった）:
     - G6（最長68.1mm・左から3番目）… 約2625〜3340Hz=オクターブ上へオーバーブロー。弱く吹き直す。
     - F7（44mm・左から7番目）… 2936Hz=+86セント上ずり。吹き直す。
     - G7（40.6mm）… 高音版カードの位置6。未測定。1本測る。
  ・この3本が揃えば 40〜68mm 全域が埋まり較正を確定できる。→ mini10/refit_calib.py に入れて再フィット。

[低音版 G6〜F#7]  (＊=主音C は 位置4。位置1が y=0 側の端)
  位置 | 音 | 設計管長mm | 目標Hz | 測定Hz(2026/7/23) | メモ
   1  | D7  |   49.8    |  2349  |  2285   | クリーン(-48c)
   2  | F7  |   44.0    |  2794  |  (2936?) | 上ずり=要再測定
   3  | A6  |   62.1    |  1760  |  1746   | クリーン(-14c)
   4＊ | C7  |   54.3    |  2093  |  2039   | クリーン(-45c)
   5  | E7  |   45.8    |  2637  |  2561   | クリーン(-51c)
   6  | G6  |   68.1    |  1568  |  (2625+?) | オクターブへオーバーブロー=要再測定(弱く)
   7  | B6  |   56.8    |  1976  |  1939   | クリーン(-32c)
   8  | D7  |   49.8    |  2349  |  2303   | クリーン(-34c)
  ※上表の物理左端→右端は 位置8,7,6,5,4,3,2,1 の順（逆順）。測定Hzは逆順で吹いた値を該当音へ割当。

[高音版 A6〜G#7]  (＊=主音C は 位置4。位置1が y=0 側の端)
  位置 | 音 | 設計管長mm | 目標Hz | 測定Hz | メモ
   1  | D7  |   49.8    |  2349  |        |
   2  | F7  |   44.0    |  2794  |        |
   3  | A6  |   62.1    |  1760  |        |
   4＊ | C7  |   54.3    |  2093  |        |
   5  | E7  |   45.8    |  2637  |        |
   6  | G7  |   40.6    |  3136  |        | ← v1.1較正の短側端に必要。測ってほしい
   7  | B6  |   56.8    |  1976  |        |
   8  | D7  |   49.8    |  2349  |        |

※2枚の違いは位置6のG音のみ（低音版G6=68.1mm / 高音版G7=40.6mm）。他7本は共通。
※どちらか1枚の8本＋もう1枚の位置6(G)だけでも、40.6〜68.1mmの8種がそろう。

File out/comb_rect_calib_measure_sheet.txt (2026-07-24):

直管rect 較正コーム 測定結果（2026/7/23 実測記入済）
対象STL: out/comb_rect_calib5_zstack_base.stl（5本z積み＋底ベース・H2D印刷済）
再フィット: f=A/(L+e), A=84910, e=-11.24, RMS=25.6cent（rect専用・4本フィット）

  管長mm | 実測Hz | 音名 | 鳴り
     40  |  2895  | F#7 (-38) | ○
     48  |  2350  | D7  (+1) | ○
     56  |  1916  | A#6 (+47) | ○
     64  |  1594  | G6  (+28) | △弱不安定
     72  |   ---  |  --- | ×無音

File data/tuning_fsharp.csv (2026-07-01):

note | length_outside | length_inside | filename | note_in_c
F#5 | 65.3 | 34.7 | fs5.stl | c
G5 | 58.0 | 42.0 | g5.stl | c#
G#5 | 52.1 | 47.9 | gs5.stl | d
A5 | 43.4 | 56.6 | a5.stl | d#
A#5 | 38.4 | 61.6 | as5.stl | e
B5 | 32.7 | 67.3 | b5.stl | f
C6 | 28.0 | 72.0 | c6.stl | f#
C#6 | 22.8 | 77.2 | cs6.stl | g
D6 | 20.6 | 79.4 | d6.stl | g#
D#6 | 15.5 | 84.5 | ds6.stl | a
E6 | 11.5 | 88.5 | e6.stl | a#
F6 | 7.1 | 92.9 | f6.stl | b
F#6 | 3.9 | 96.1 | fs6.stl | c2

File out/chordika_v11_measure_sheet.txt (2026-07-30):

Chordika v1.1 ＋ Recoca  実測記録シート
基準窓 G#6〜G7 ／ 較正 f=A/(L+e)  A=85695.9  e=-12.5701

【測り方】
  ・各カードを左から順に、1本ずつ2回吹く。実測欄にHzを書く。鳴らなければ × と書く。
  ・静かな場所で。息は強すぎないように（強いと1オクターブ上に飛ぶ）。
  ・13枚すべてでなくてよい。まず C/Am と Recoca、次に気になる調、の順で構わない。

================================================================
■ Recoca（音階カード・A♭メジャー）  ※最優先で確認したい1枚
================================================================
  位置1 ど    G#6   目標 1661.2Hz  管長 64.2mm   実測1 ______   実測2 ______
  位置2 れ    A#6   目標 1864.7Hz  管長 58.5mm   実測1 ______   実測2 ______
  位置3 み    C7    目標 2093.0Hz  管長 53.5mm   実測1 ______   実測2 ______
  位置4 ふぁ   C#7   目標 2217.5Hz  管長 51.2mm   実測1 ______   実測2 ______
  位置5 そ    D#7   目標 2489.0Hz  管長 47.0mm   実測1 ______   実測2 ______
  位置6 ら    F7    目標 2793.8Hz  管長 43.2mm   実測1 ______   実測2 ______
  位置7 し    G7    目標 3136.0Hz  管長 39.9mm   実測1 ______   実測2 ______
  位置8 ど    G#7   目標 3322.4Hz  管長 38.4mm   実測1 ______   実測2 ______ ★未検証
  ★位置8（G#7・38.4mm）は8本のうち唯一Chordikaに前例のない長さ。ここが鳴るかが要。

================================================================
■ Chordika 12調（各8本・位置4が主音＊）
================================================================

【C / Am】
  位置  音    目標Hz   管長mm    実測1      実測2
   1    D7     2349.3    49.0    ______     ______
   2    F7     2793.8    43.2    ______     ______
   3    A6     1760.0    61.3    ______     ______
   4＊  C7     2093.0    53.5    ______     ______
   5    E7     2637.0    45.1    ______     ______
   6    G7     3136.0    39.9    ______     ______
   7    B6     1975.5    55.9    ______     ______
   8    D7     2349.3    49.0    ______     ______

【G / Em】
  位置  音    目標Hz   管長mm    実測1      実測2
   1    A6     1760.0    61.3    ______     ______
   2    C7     2093.0    53.5    ______     ______
   3    E7     2637.0    45.1    ______     ______
   4＊  G7     3136.0    39.9    ______     ______
   5    B6     1975.5    55.9    ______     ______
   6    D7     2349.3    49.0    ______     ______
   7    F#7    2960.0    41.5    ______     ______
   8    A6     1760.0    61.3    ______     ______

【D / Bm】
  位置  音    目標Hz   管長mm    実測1      実測2
   1    E7     2637.0    45.1    ______     ______
   2    G7     3136.0    39.9    ______     ______
   3    B6     1975.5    55.9    ______     ______
   4＊  D7     2349.3    49.0    ______     ______
   5    F#7    2960.0    41.5    ______     ______
   6    A6     1760.0    61.3    ______     ______
   7    C#7    2217.5    51.2    ______     ______
   8    E7     2637.0    45.1    ______     ______

【A / F#m】
  位置  音    目標Hz   管長mm    実測1      実測2
   1    B6     1975.5    55.9    ______     ______
   2    D7     2349.3    49.0    ______     ______
   3    F#7    2960.0    41.5    ______     ______
   4＊  A6     1760.0    61.3    ______     ______
   5    C#7    2217.5    51.2    ______     ______
   6    E7     2637.0    45.1    ______     ______
   7    G#6    1661.2    64.2    ______     ______
   8    B6     1975.5    55.9    ______     ______

【E / C#m】
  位置  音    目標Hz   管長mm    実測1      実測2
   1    F#7    2960.0    41.5    ______     ______
   2    A6     1760.0    61.3    ______     ______
   3    C#7    2217.5    51.2    ______     ______
   4＊  E7     2637.0    45.1    ______     ______
   5    G#6    1661.2    64.2    ______     ______
   6    B6     1975.5    55.9    ______     ______
   7    D#7    2489.0    47.0    ______     ______
   8    F#7    2960.0    41.5    ______     ______

【B / G#m】
  位置  音    目標Hz   管長mm    実測1      実測2
   1    C#7    2217.5    51.2    ______     ______
   2    E7     2637.0    45.1    ______     ______
   3    G#6    1661.2    64.2    ______     ______
   4＊  B6     1975.5    55.9    ______     ______
   5    D#7    2489.0    47.0    ______     ______
   6    F#7    2960.0    41.5    ______     ______
   7    A#6    1864.7    58.5    ______     ______
   8    C#7    2217.5    51.2    ______     ______

【F# / D#m】
  位置  音    目標Hz   管長mm    実測1      実測2
   1    G#6    1661.2    64.2    ______     ______
   2    B6     1975.5    55.9    ______     ______
   3    D#7    2489.0    47.0    ______     ______
   4＊  F#7    2960.0    41.5    ______     ______
   5    A#6    1864.7    58.5    ______     ______
   6    C#7    2217.5    51.2    ______     ______
   7    F7     2793.8    43.2    ______     ______
   8    G#6    1661.2    64.2    ______     ______

【Db / Bbm】
  位置  音    目標Hz   管長mm    実測1      実測2
   1    D#7    2489.0    47.0    ______     ______
   2    F#7    2960.0    41.5    ______     ______
   3    A#6    1864.7    58.5    ______     ______
   4＊  C#7    2217.5    51.2    ______     ______
   5    F7     2793.8    43.2    ______     ______
   6    G#6    1661.2    64.2    ______     ______
   7    C7     2093.0    53.5    ______     ______
   8    D#7    2489.0    47.0    ______     ______

【Ab / Fm】
  位置  音    目標Hz   管長mm    実測1      実測2
   1    A#6    1864.7    58.5    ______     ______
   2    C#7    2217.5    51.2    ______     ______
   3    F7     2793.8    43.2    ______     ______
   4＊  G#6    1661.2    64.2    ______     ______
   5    C7     2093.0    53.5    ______     ______
   6    D#7    2489.0    47.0    ______     ______
   7    G7     3136.0    39.9    ______     ______
   8    A#6    1864.7    58.5    ______     ______

【Eb / Cm】
  位置  音    目標Hz   管長mm    実測1      実測2
   1    F7     2793.8    43.2    ______     ______
   2    G#6    1661.2    64.2    ______     ______
   3    C7     2093.0    53.5    ______     ______
   4＊  D#7    2489.0    47.0    ______     ______
   5    G7     3136.0    39.9    ______     ______
   6    A#6    1864.7    58.5    ______     ______
   7    D7     2349.3    49.0    ______     ______
   8    F7     2793.8    43.2    ______     ______

【Bb / Gm】
  位置  音    目標Hz   管長mm    実測1      実測2
   1    C7     2093.0    53.5    ______     ______
   2    D#7    2489.0    47.0    ______     ______
   3    G7     3136.0    39.9    ______     ______
   4＊  A#6    1864.7    58.5    ______     ______
   5    D7     2349.3    49.0    ______     ______
   6    F7     2793.8    43.2    ______     ______
   7    A6     1760.0    61.3    ______     ______
   8    C7     2093.0    53.5    ______     ______

【F / Dm】
  位置  音    目標Hz   管長mm    実測1      実測2
   1    G7     3136.0    39.9    ______     ______
   2    A#6    1864.7    58.5    ______     ______
   3    D7     2349.3    49.0    ______     ______
   4＊  F7     2793.8    43.2    ______     ______
   5    A6     1760.0    61.3    ______     ______
   6    C7     2093.0    53.5    ______     ______
   7    E7     2637.0    45.1    ______     ______
   8    G7     3136.0    39.9    ______     ______

================================================================
■ 同じ音がどれだけ重複するか（較正のずれと個体差を分離する材料）
================================================================
  同じ設計長の管が別々に刷られている。全体が一様にずれていれば較正の問題、
  ばらついていれば製造の個体差。位置1や8（端）に系統的な癖がないかも見る。

  A#6    9本  Recoca-2 , B/G#m-7 , F#/D#m-5 , Db/Bbm-3 , Ab/Fm-1 , Ab/Fm-8 , Eb/Cm-6 , Bb/Gm-4 , F/Dm-2
  C#7    9本  Recoca-4 , D/Bm-7 , A/F#m-5 , E/C#m-3 , B/G#m-1 , B/G#m-8 , F#/D#m-6 , Db/Bbm-4 , Ab/Fm-2
  C7     9本  Recoca-3 , C/Am-4 , G/Em-2 , Db/Bbm-7 , Ab/Fm-5 , Eb/Cm-3 , Bb/Gm-1 , Bb/Gm-8 , F/Dm-6
  D#7    9本  Recoca-5 , E/C#m-7 , B/G#m-5 , F#/D#m-3 , Db/Bbm-1 , Db/Bbm-8 , Ab/Fm-6 , Eb/Cm-4 , Bb/Gm-2
  F7     9本  Recoca-6 , C/Am-2 , F#/D#m-7 , Db/Bbm-5 , Ab/Fm-3 , Eb/Cm-1 , Eb/Cm-8 , Bb/Gm-6 , F/Dm-4
  G#6    9本  Recoca-1 , A/F#m-7 , E/C#m-5 , B/G#m-3 , F#/D#m-1 , F#/D#m-8 , Db/Bbm-6 , Ab/Fm-4 , Eb/Cm-2
  G7     9本  Recoca-7 , C/Am-6 , G/Em-4 , D/Bm-2 , Ab/Fm-7 , Eb/Cm-5 , Bb/Gm-3 , F/Dm-1 , F/Dm-8
  A6     8本  C/Am-3 , G/Em-1 , G/Em-8 , D/Bm-6 , A/F#m-4 , E/C#m-2 , Bb/Gm-7 , F/Dm-5
  B6     8本  C/Am-7 , G/Em-5 , D/Bm-3 , A/F#m-1 , A/F#m-8 , E/C#m-6 , B/G#m-4 , F#/D#m-2
  D7     8本  C/Am-1 , C/Am-8 , G/Em-6 , D/Bm-4 , A/F#m-2 , Eb/Cm-7 , Bb/Gm-5 , F/Dm-3
  E7     8本  C/Am-5 , G/Em-3 , D/Bm-1 , D/Bm-8 , A/F#m-6 , E/C#m-4 , B/G#m-2 , F/Dm-7
  F#7    8本  G/Em-7 , D/Bm-5 , A/F#m-3 , E/C#m-1 , E/C#m-8 , B/G#m-6 , F#/D#m-4 , Db/Bbm-2
  G#7    1本  Recoca-8

================================================================
■ 和音の確認（Chordikaのカードで・耳で聴く）
================================================================
  隣り合う3本を同時に吹く。位置と和音の対応は全カード共通。
    1・2・3 = ii（短三和音）    2・3・4 = IV     3・4・5 = vi
    4・5・6 = I（主和音）       5・6・7 = iii    6・7・8 = V
  同じ位置4・5・6を別の調のカードで吹き、持ち替えるだけで移調になることを確かめる。
    C/Am→C   G/Em→G   D/Bm→D   F/Dm→F  …

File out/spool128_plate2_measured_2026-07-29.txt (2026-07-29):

# スプール128bit「2枚目」（sticker側・厚さ34.1mm・笛24本）の実測 2026-07-29（栗原さん）
# 続けて吹く・区切り 80セント/100ms。
#
# 吹き始めの位置が実物から分からなかったので、A#6と聞こえた笛から始めた。
# 集計にかけたところ、円周を[逆方向]に回り、[設計の5本目]から始まっていたことが分かった。
# 並べ直すと24本すべてが相対スロットまで一致し、鳴らない笛は無かった。
#
# 集計:  python3 scripts/check_plate_measure.py out/spool128_plate2.3mf out/spool128_plate2_measured_2026-07-29.txt
# （吹いた生の順番のまま貼ってよい。道具が回転と向きを総当たりして並べ直す）

1857.4 2216.7 1773.5 2097.8 1875.0 2984.6 2356.1 1892.6 2106.4 3150.3 2492.2 1761.6
2667.9 2819.8 2354.0 3178.1 1993.1 2353.3 2086.1 2791.3 2485.1 2632.4 1971.8 2794.9

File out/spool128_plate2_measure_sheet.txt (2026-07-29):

# スプール128bit「2枚目」（sticker側・厚さ34.1mm・笛24本）の測定シート 2026-07-29
#
# このプレートには基準笛が無い（基準笛のタブは、まだ刷っていないnotch側の1枚目にある）。
# したがってこの1枚だけでは秘密は復元できない。ここで確かめるのは次の3つである。
#   1. 24本すべてがちゃんと鳴るか
#   2. 1本目を仮の基準にしたとき、相対の並びが設計どおりか
#   3. 判定境界（±50セント）までどれだけ余裕があるか
#
# 吹き方: 円周に沿って1本目から順に、続けて24本。隣り合う笛は必ず違う音なので、
# 復号ページの音の変わり目で区切る読み方（pitchsplit）でそのまま拾える。
#   https://qurihara.github.io/ai-fue/cipher/#hi=G7&norepeat=1&mode=sequential&parity=2&pitchsplit=1&splitcents=80
# 鳴らなかった笛は - と書く。1回ぶんを1つのまとまりにして、空行で区切って何回ぶんでも並べてよい。
#
# 集計:  python3 scripts/check_plate_measure.py out/spool128_plate2.3mf このファイル
#
# 番号 音名  狙いの周波数[Hz]  前の笛からの相対[半音]
#    1  A#6     1864.7            
#    2  C7      2093.0            +2
#    3  A6      1760.0            -3
#    4  C#7     2217.5            +4
#    5  A#6     1864.7            -3
#    6  F7      2793.8            +7
#    7  B6      1975.5            -6
#    8  E7      2637.0            +5
#    9  D#7     2489.0            -1
#   10  F7      2793.8            +2
#   11  C7      2093.0            -5
#   12  D7      2349.3            +2
#   13  B6      1975.5            -3
#   14  G7      3136.0            +8
#   15  D7      2349.3            -5
#   16  F7      2793.8            +3
#   17  E7      2637.0            -1
#   18  A6      1760.0            -7
#   19  D#7     2489.0            +6
#   20  G7      3136.0            +4
#   21  C7      2093.0            -7
#   22  A#6     1864.7            -2
#   23  D7      2349.3            +4
#   24  F#7     2960.0            +4

# 1回目（ここに24個の測定値を貼る）

# 2回目

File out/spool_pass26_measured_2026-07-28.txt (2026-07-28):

# スプール「pass_#26」の実測 2026-07-28（栗原さん）。26本を続けて吹く、区切り 40セント/100ms。
# 意図した並び（先頭が基準笛C7）:
#   C7 A6 C#7 G#6 A#6 D7 A#6 E7 B6 C7 C#7 B6 A#6 D#7 F#7 A#6 D7 A#6 A6 G#6 F7 A6 F7 E7 F7 C#7
# 対応づけの結果は3回とも同じであった。
#   10本目(C7)が鳴らない。末尾に余分な音が1つ（円周を1周して基準笛へ戻ったもの）。
#   スロットを誤るのは4本目のG#6だけ（測定-3半音、意図-4半音）。ボアが1.57mm短いため。
# 消失1つと誤り1つは、パリティ2本では訂正できない（2*1+1=3 > 2）。実際に復号は失敗した。
# 10本目を消失として並びを直し、さらにG#6を正しいスロットに置き換えると b'pass_#26' が出る。

# 1回目（末尾の6421.9は倍音を拾ったもの）
2134.6 1787.6 2279.1 1757.8 1904.5 2420.6 1893.8 2736.7 2015.6 2296.2 2052.2 1899.2
2557.7 3070.7 1899.7 2419.9 1890.5 1792.3 1725.1 2892.1 1781.3 2919.0 2757.6 2891.0
2279.3 6421.9

# 2回目
2133.4 1787.1 2272.0 1746.1 1903.5 2412.3 1892.6 2727.2 2024.9 2284.6 2026.5 1889.8
2542.3 3046.9 1886.7 2408.2 1887.5 1783.7 1722.7 2871.5 1776.0 2892.4 2748.3 2877.0
2279.1 2143.2

# 3回目
2132.8 1793.0 2273.3 1746.4 1898.4 2421.6 1894.6 2732.5 2016.7 2289.0 2025.9 1899.0
2554.7 3075.3 1892.6 2408.2 1880.9 1784.6 1723.7 2882.5 1779.0 2905.6 2753.9 2903.4
2286.1 2149.3

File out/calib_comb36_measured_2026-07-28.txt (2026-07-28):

# 較正コーム36本 実測 2026-07-28 17:12-17:14（栗原さん）
# 吹いた向きは 36番側から 1番側へ（逆順）。測定値そのものから判定した。
# 冒頭の - - は「この笛は飛ばす」を2回押したもの。34番から36番は吹いていない。
# 1番から3番（G#6・A6・A#6）は造形不良で鳴らない（2026-07-28 栗原さん確認）。
# 吹き終わりは4番(B6)。この終端を固定して対応づける。
# 区切りは 40セント/100ms。この設定だと1本の吹鳴が2つに分かれることがある。

# 1回目
- - 2133.7 2037.7 1912.4 1793.0 3258.4 3057.0 2933.2 2714.6 1920.2 1846.4
1793.0 3247.1 3070.3 2873.6 2709.0 2540.8 2388.2 2296.4 2191.1 2127.0 3258.2 3073.2
2888.7 2756.5 2654.5 2540.9 2399.5 2276.7 2186.8 2129.5 1986.3

# 2回目
- - 2133.5 2031.9 1931.7 1798.8 3262.8 3048.5 2890.6 2701.2 2009.8 1898.4
1767.0 3267.7 3080.7 2961.9 2862.3 2706.2 2545.5 2438.4 2345.3 2252.8 2132.8 3261.6
3090.5 2896.0 2770.1 2649.0 2553.2 2407.7 2319.2 2147.6 1992.2

# 3回目
- - 2089.3 2002.9 1912.7 1812.3 1761.5 3250.9 3102.5 2919.6 2724.6 1949.5
1862.7 1763.2 1656.5 3283.2 3096.8 2886.0 2760.1 2571.4 2473.2 2404.4 2275.7 2132.8
3268.6 3101.4 2963.1 2826.6 2688.1 2537.0 2396.9 2299.9 2141.9 2003.9

# 最後から3番目の1本だけを3回吹いたもの（画面表示はB6）
2013.1 2015.1 2020.4

# 低音側を1本ずつ測り直したもの（2026-07-28 追記）。位置は低い方の端から数えた番号。
# 21番から24番（G#6 A6 A#6 B6）
1740.2 1804.7 1910.2 2009.8
# 29番から32番（G#6 A6 A#6 B6）
1728.5 1803.6 1917.4 2029.9

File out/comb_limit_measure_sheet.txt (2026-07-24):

mini10 限界コーム 測定シート (再較正 A=86338 e=-13.06)
鳴り: ◎○△×
並び: 短い(26)が手前→長い(120)が奥

  管長mm | 予測Hz | 最寄り音 | 測定Hz | 鳴り | メモ
     26  |  6672  | G#8   (+7) |        |      |
     32  |  4559  | C#8   (+48) |        |      |
     80  |  1290  | E6    (-38) |        |      |
     92  |  1094  | C#6   (-24) |        |      |
    106  |   929  | A#5   (-6) |        |      |
    120  |   807  | G#5   (-49) |        |      |

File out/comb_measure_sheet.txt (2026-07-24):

mini10(半割・深窓・壁1mm) 較正コーム 測定シート  目安 f=A/(L+e), A=89086,e=-10.9
鳴り: ◎非常に安定 / ○安定 / △かすれる / ×鳴らない
5本一体・吸込口を左にそろえ短い笛(40)が手前・長い笛(72)が奥

  管長mm | 予測Hz | 最寄り音 | 測定Hz | 鳴り(◎○△×) | メモ
     40  |  3061  | G7    (-42) |        |             |
     48  |  2401  | D7    (+38) |        |             |
     56  |  1975  | B6    (+0) |        |             |
     64  |  1678  | G#6   (+17) |        |             |
     72  |  1458  | F#6   (-26) |        |             |

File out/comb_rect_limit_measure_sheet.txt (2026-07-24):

直管rect 限界コーム 測定結果（2026/7/23 A1mini印刷・実測記入済）
対象STL: out/comb_rect_limit5_zstack_base_a1m.stl（5本z積み＋底ベース・長い管を下・中央化）
式 f=A/(L+e), A=86677, e=-10.535（両コーム統合フィット）
並び: z積みで長い68が下→短い28が上（各上段が下段の長い管に載る自己支持）。

  管長mm | 実測Hz | 音名 | 鳴り | メモ
     68  |  1515  | F#6(+40) | ◎ | 最下段・よく鳴る
     60  |  1764  | A6 (+4)  | ◎ | よく鳴る
     36  |  ----  |  ---     | × | 無音（塔頂部の造形品質か）
     32  |  ----  |  ---     | × | 無音
     28  |  6240  |  ---     | 過吹 | 1本だけ非常に高い音（崩れた短管の過吹き）

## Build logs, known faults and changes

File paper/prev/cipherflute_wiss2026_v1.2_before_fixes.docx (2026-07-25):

# CipherFlute：3Dプリント可能な笛による秘密情報の日用品への埋め込み手法の提案

# CipherFlute: Embedding Secret Information in Everyday Objects Using 3D-Printable Whistles

# 栗原 一貴†

# †津田塾大学 Tsuda University

概要．　暗証番号や合言葉のような気軽な秘密から，暗号資産の復元用パスフレーズのような重要な秘密まで，少量の秘密情報を，電源も電子部品も持たない3Dプリントの笛を日用品へと埋め込み，吹いて読み出す手法「CipherFlute」を提案する．管の長さを変えると音の高さが変わる笛の音の高さを符号として，複数の笛によりエンコーディングを行う．実装した小型の笛ユニットは F#6からF#7までの13音が活用可能であり，笛1本あたり約3.7bitを担うことができる．暗証番号なら数本，128bitの復元用情報なら基準笛と誤り訂正を含めて約40本というように，求める強度に応じた本数の笛を採用して，カード，アクセサリや置物といった日用品に埋め込める．提案手法はデコード時の守秘性は低いが，日用品に笛を溶け込ませることで秘密の在りかを分かりにくくできること，および正当な利用者が特別な機器を使わず息とスマートフォンだけで読み出せることが特徴であり，秘密情報のバックアップとしての活用が期待できる．気温や息の強さによる音のずれを打ち消す機構を備える．実験により温度差に対する頑健さ，および128bit暗号のエンコードとデコードを検証した．

キーワード：デジタルファブリケーション，音響タグ，秘密分散，鍵管理，ステガノグラフィ，楽器

Copyright is held by the author(s).　栗原 一貴†　†津田塾大学

# 1 はじめに

暗号資産のウォレットや電子署名の普及に伴い，パスワードも端末もすべて失ったときに最後の頼りとなる復元用の秘密（リカバリーシードと呼ばれる百数十bitの情報）を，どのような物理的な形で保管するかが現実の課題になっている．実務では，この秘密を金属板に刻印する製品群が定着しており，火災や水害に強い優れた解である[15]．しかしこれらの担体には共通の弱点がある．見た目が明らかに「秘密の保管物」であるため，侵入者に発見された時点で持ち去りの標的になることを避けられない．一方，日常には，暗証番号や合言葉，贈り物やイベントの合図のように，もっと気軽に扱いたい小さな秘密も数多くある．こうした秘密を，改まった保管庫ではなく身の回りの日用品に埋め込むことを考える．

本研究では，3Dプリントした複数の笛に秘密を符号化し，吹いて生じる音をスマートフォンのマイクで解析して読み出す手法「CipherFlute」を提案する（図1）．CipherFluteは電源も電子部品も持たず，家庭用の3Dプリンタで利用者自身が製造できる．そして笛はカードやアクセサリ，置物といった日用品の形へ溶け込ませられるため，秘密が保管されていること自体を日常の風景に紛れさせられる．すなわちCipherFluteは，特定の用途に限らず，秘密情報を日用品に埋め込んで管理するための汎用の器である．

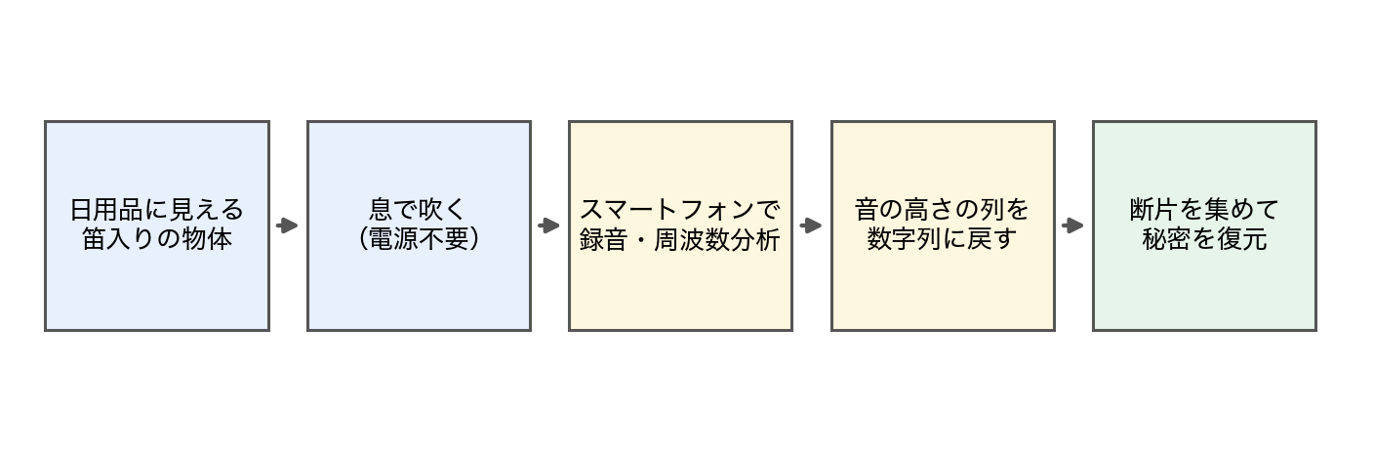
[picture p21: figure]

図1　CipherFluteの全体の流れ．日用品に見える物体を吹き，スマートフォンで音を解析して秘密の情報を取り出す

本研究は，音や物体そのものに秘密を守る力は付与しない．符号である音の高さはマイクによる測定が可能で，また笛の管の長さと音の高さは厳密な対応付けが可能なので，外部からの構造センシング手法により読み取ることは可能であり，複製も容易である．

器としてのCipherFluteの価値は2つある．第一に，日用品への偽装によって，攻撃者にとって「どこを探せばよいか」のコストを引き上げられることである．金属板の保管物は金庫に入れれば安全性は上がるが，金庫は「ここに価値がある」と宣言してしまう．CipherFluteはそれをしない．第二に，正当な利用者にとっての読み出しの手軽さである．特別な読み取り装置は不要で，物体を吹き，スマートフォンの画面を見るだけでよい．

本手法で運べる情報量は，用途に応じて選ぶことができる．暗証番号や合言葉，贈り物やイベントの合図，体験型のセキュリティ教育といった少ないbit数で足りるカジュアルな利用シーンでは，，笛数本から10本程度の小さな構成で足りる．人が記憶して使うパスワードの実効的な情報量も数十bit程度に留まる．一方で，128bitのリカバリーシードを保管することも可能であり，約40本の笛でエンコーディングできる（3章）．このように，気軽な暗証番号から本格的な鍵管理まで，同じしくみを幅広く気軽に使える点が本手法の特徴である．

本研究の貢献は次の4点である．第一に，従来は数bit程度の識別番号を担わせるものだった「吹くと鳴る3Dプリント物」を，求める強度に応じて保管できるデータ担体へ拡張し，そのための設計（管の長さと音の高さの対応式にもとづく符号化，誤り訂正，容量の見積もり）を確立する．第二に，基準となる笛との音の高さの比で読むことで，気温や息の強さによるずれを打ち消す自己補正のしくみを示す．第三に，どの層が秘密を守り，どの層は守らないのかを明示した脅威モデルを提示する．第四に，実物の印刷から復元までを通しで実証し，さらに複数の応用シナリオへ展開する．

# 2 関連研究

# 作った物体への情報埋め込み

物体の内部や製造の副産物に情報を埋め込む研究は多くある．InfraStructs[4]は内部の空隙パターンをテラヘルツ波の撮像で読み，AirCode[3]は表面直下の空気ポケットを特殊な撮影で読む．LayerCode[5]は3Dプリントの積層をバーコードとして通常のカメラで読み，G-ID[6]はスライサ設定の副産物の模様で個体を識別する（約14bit相当）．StructCode[11]はレーザーカットの継ぎ目の寸法に，Seedmarkers[10]は輪郭に溶け込む視覚マーカーに情報を載せる．これらはいずれも光を使った読み出しであり，撮影や走査によって所有者の関与なく読める．また運べる量は識別番号程度で，秘密情報を守るための脅威モデル（どんな攻撃者から何を守るかの整理）を持たない．

# 音で読み出す無電源の物体

音で物体を読む系譜では，Acoustic Barcodes[7]が表面の刻み目をこすった音から識別番号を復元し，Lamello[8]はくし歯の長さと固有振動数の対応で入力位置を検出した．Acoustruments[9]はスマートフォンが発する超音波を3Dプリントの管で変調して操作を認識する．Acoustic Voxels[2]は内部空洞の音響応答を計算で設計し，置物に音の署名を埋め込めることを示した．そして本研究に機構がもっとも近いBlowhole[1]は，3Dプリント物の内部空洞に息を吹き込んで生じる共鳴音でタグを識別する．ただしBlowholeの目的は模型の部位識別であり，多くのbitを運ぶ符号化，狙った音の高さに合わせ込む調律，秘密分散との統合のいずれも扱っていない．本研究はこれらの蓄積の上に立ち，応用を再定義して，運べる量を工学的に広げる（表1）．

表1　先行研究との比較

研究 | 読出装置 | 鳴らし方 | 容量級 | 脅威モデル
InfraStructs[4] | THz撮像 | 受動 | ID級 | なし
AirCode[3] | 投影+カメラ | 受動 | ID級 | なし
LayerCode[5] | カメラ | 受動 | 数十bit | なし
G-ID[6] | スマホカメラ | 受動 | 約14bit | なし
Acoustic Barcodes[7] | 接触マイク | こする | 数十bit | なし
Lamello[8] | 接触マイク | はじく | 入力検出 | なし
Acoustic Voxels[2] | マイク | 外部音源 | ID級 | なし
Blowhole[1] | マイク | 呼気 | ID級 | なし
本研究 | スマホマイク | 呼気 | 約3.7bit/本 | あり

# 秘密の保管と鍵管理の実務

金属板に秘密を刻印する製品群[15]は災害への耐性に特化した担体であり，偽装性と機械での読み取りやすさを持たない．Casascius物理ビットコイン[14]は鍵を封入したコインを製品化したが，製造者が鍵を知り得る構造だった．SLIP-39[12]とSSKR[13]は秘密分散の断片をどう符号化して運用するかの業界標準であり，本研究はこれらの断片を運ぶ「新しい物理的な入れ物」として活用される．物理的な封印がどれほど破られやすいかを体系評価したJohnstonの研究[16]は，物理層に秘匿を負わせないという本研究の位置づけを補強する．鍵管理の使いやすさを定式化したEskandariらの枠組み[17]に対して，本研究は「自分で製造できる・電源なしで機械読み取りできる・偽装できる」という未充足の組み合わせを埋める位置にある．

# 3 CipherFluteの設計

# 笛の構造と，長さから音の高さを決める式

発音体には，小型の円筒型を軸方向に半分に割った断面の笛（厚さ4 mm，幅7 mm）を用いる．家庭用の3Dプリンタにサポート材なしで平置きで印刷でき，複数本を密着させて融合できる（図2）．最終的な応用では，求める暗号強度に応じた本数の笛を採用し，日用品の形に合わせて自由なレイアウトで配置する．管の長さL [mm]と音の高さ（基本周波数f [Hz]）の関係は，f = A/(L+e) という単純な式でよく近似できる（Aは笛の形状で決まる定数，eは管の端の効果を吸収する補正の長さである）．採用した発音体は

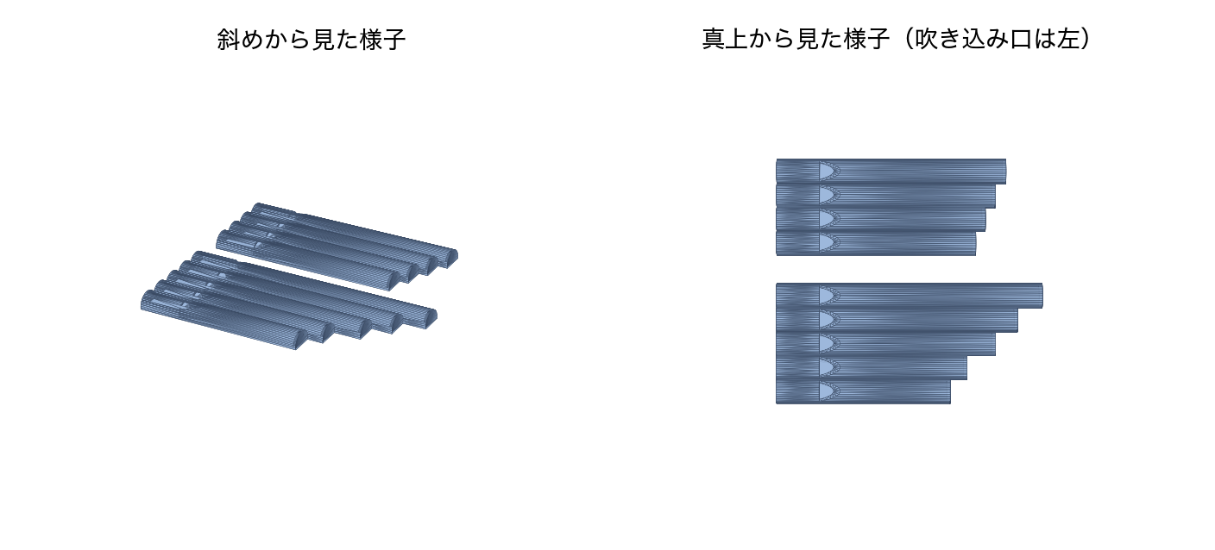
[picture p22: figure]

図2　笛を並べた3Dモデル．長さの違う笛が並び，左端の吹き込み口から吹く．

# 音の高さの置き場（スロット）の決め方

読み取りの語彙は，あらかじめ決めた音の高さの置き場（以下スロット）である．どのスロットで鳴るかで，笛1本が1つの数字を表す．厚壁ヘッドで安定して鳴る音域は，下がF#6（約1480 Hz），上がF#7（約2960 Hz）までである．この音域を半音（100セント）刻みで割ると，スロットは13個になる．較正用の13本を室温で測ると全部が発音し，隣り合う音の間隔は平均でちょうど100セントであった．笛1本が13通りの13進数の数字を表すので，1本あたり約3.7bitを運ぶ．スロット数の13は素数であり，後述の誤り訂正の計算の土台とちょうど1対1で対応する（3.4節）．

スロットを半音刻みにしたのは誤差の大きさから刻み幅を決めた結果である．誤差には，印刷のばらつき（実測で標準偏差およそ10セント），息の強さによる音の動き（基準笛との比でほとんど打ち消される），測定自体の誤差がある．読み間違いを十分に減らすには，刻み幅を残る誤差のおよそ4倍にとるのが一般的な設計目安であり，半音（100セント）はその安全側にある．より誤差の小さい笛を設計・製造できれば，刻みを50セントなどへ細かくしてスロット数を倍近くに増やせる．刻み幅は設計上の可変パラメータであるが，音楽的な「半音」になっていることで，暗号を再生するときに音楽的な意味が付与され，エンタテインメント価値を付与できる．一方でそれが音感に優れた人により認識・記憶されやすいという欠点にもなるため，用途の厳密性に応じたパラメータ設定を行うべきである．

# 基準笛：音の高さの比で読む

管楽器の音の高さは音速に比例するため，気温が10 ℃変わると，全部の笛の音が同じ向きに同じ割合（約1.7%，半音の約3割）でずれる．息の強さの平均的な変化も同様に，全体を同じ向きに動かす．音の高さを絶対値で読むと，このずれがそのまま読み間違いになる．そこで，格納するデータ列の笛に対して音の高さが既知の基準笛を1本含め，他の笛の値を基準笛との比で読むこととした（図3）．全体にかかるずれは比を取ると分子と分母で打ち消し合うため，読み取り結果が変わらない．これは通信で基準用にあらかじめ混ぜて送る信号（パイロット信号）と同じ発想であり，笛自体が温度計を内蔵しているとみなせる．

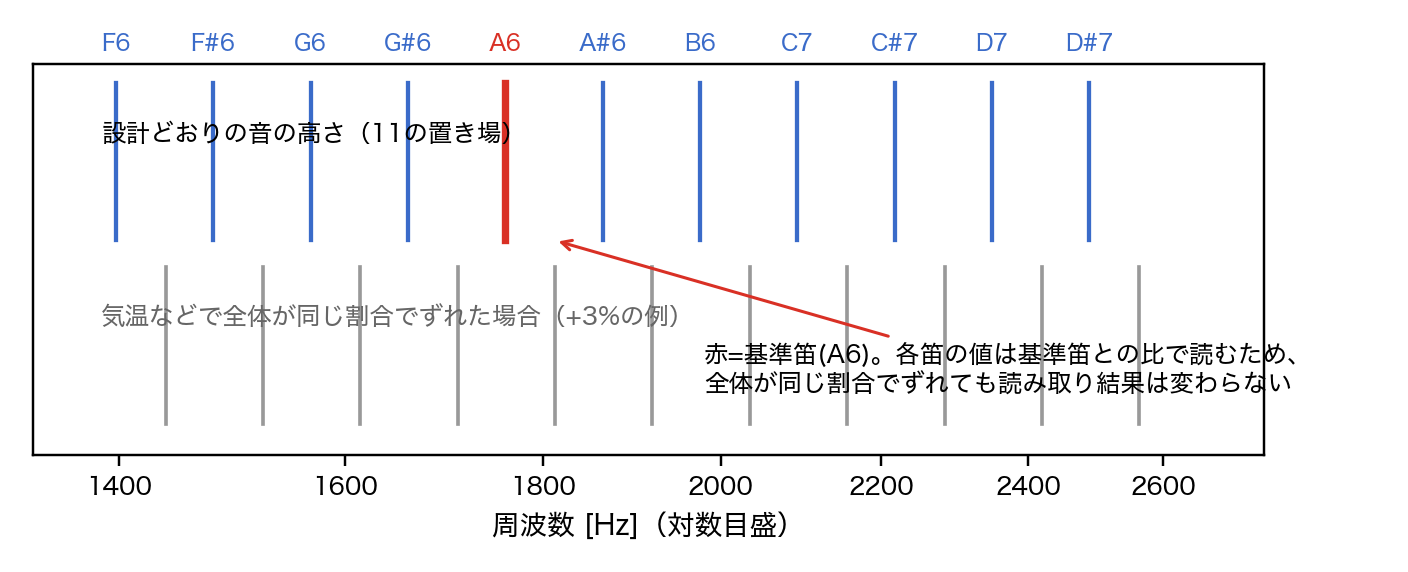
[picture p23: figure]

図3　スロットと基準笛．全体が同じ割合でずれても，基準笛（赤）との比は変わらないので正しく読める

# 読み間違いへの備えと，運べる量

読み間違いは，誤差の構造上，隣のスロットへ1つずれる形が支配的になると想定される（7章で実測により確かめる予定である）．また鳴らなかった笛は「欠け」として扱える．そこで，データの笛に加えて検査用の笛を数本足しておき，一部が読み間違われても全体を正しく復元できるようにする（誤り訂正符号．本研究ではReed–Solomon符号を用いる）．スロット数の13は素数なので，13通りの値の足し算と掛け算からなるこの符号の計算の土台をそのまま組むことができ，笛1本がそのまま計算上の1記号に対応する．検査用の笛の本数は求める確実さに応じて調整できる設計変数であり，0本（誤り訂正なし）から必要なだけ増やせる．また，秘密の長さは笛の本数そのものから一意に決まるため，長さを伝えるための追加の笛は必要ない．運べる情報量は採用する笛の本数で決まる．笛1本あたり約3.7bitなので，暗証番号のような数十bitの秘密なら数本から10本程度で足り，128bitの復元用情報でも基準笛と誤り訂正を含めて約40本で運べる（表2）．

表2　求める強度と必要な笛の本数の対応（笛1本あたり約3.7bit）

用途の例 | 必要な情報量 | 目安の笛の本数
暗証番号（4桁） | 約13ビット | 基準笛込みで5本前後
合言葉・数バイト | 数十ビット | 10本前後
128ビットの復元用情報 | 128ビット | 基準笛・誤り訂正込みで約40本

# 秘密分散との組み合わせと，正しさの確かめ方

秘密そのものを守りたい場合，その保護は秘密分散の数学的性質に任せる．秘密分散は必ず使うものではなく，秘密を複数の物体に分けて分散保管したいときに選べる方法の一つである．たとえば128bitの復元用情報を，業界標準のSLIP-39[12]に準じて「3つの断片のうち2つで復元できる」形に分け，各断片を別々の日用品に符号化して離れた場所に置けば，1か所が破られても秘密は漏れない．復元した値の正しさは，秘密と対になる公開の検証値（公開鍵）との照合で確かめられる．公開鍵をあらかじめ紙や物体，公開の台帳に控えておけば，復元した値から計算し直して一致を見るだけで，正しく復元できたかを誰でも確かめられる．

# 正しさの確かめ方（デコーダー）

暗号のデコードは，マイク入力の周波数分析からなるWebアプリで行い，ネットワークがなくても動作する．図5がその利用の様子である．

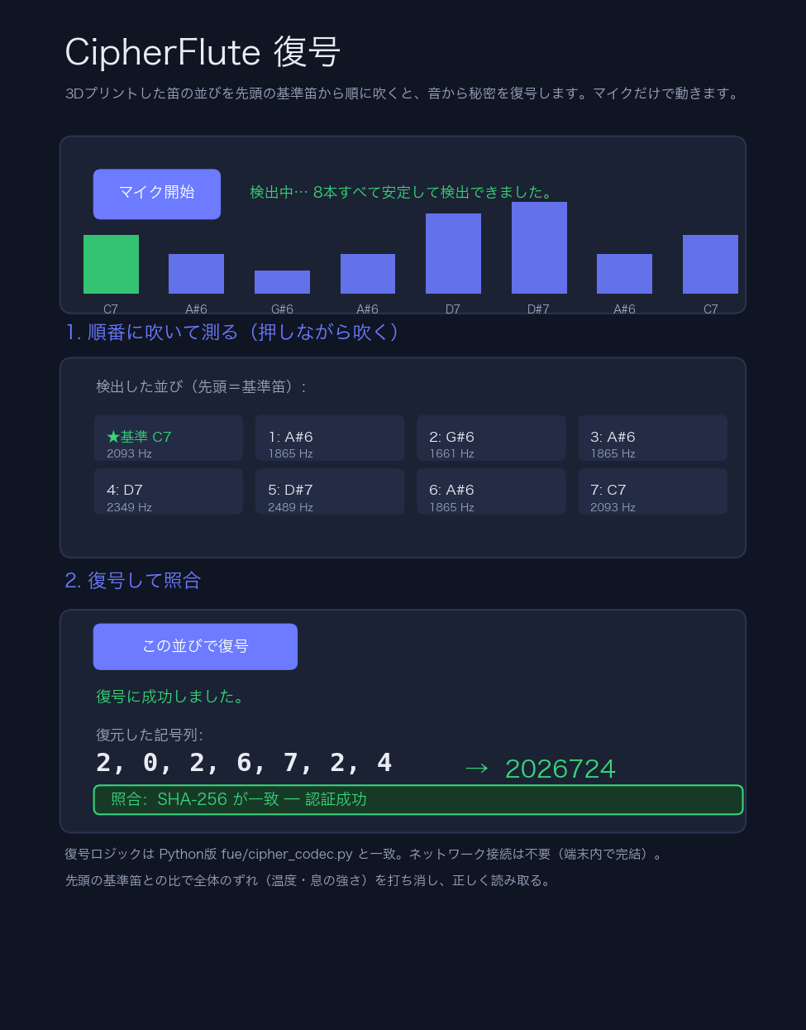
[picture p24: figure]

図5　復号ソフトの画面．吹いた音の周波数を解析し，検出した並びと復元した値を表示する．

# 利用プロファイル

本手法の使い方は，運ぶ秘密の性質に応じて3つのプロファイルに整理できる（表3）．「カジュアル」では，暗証番号や合言葉のような記号の列をそのまま笛に対応させる．誤り訂正は付けず，読み損ねたら吹き直せばよい．暗証番号4記号なら基準笛込みで5本の小さな物体に収まる．「標準」では，秘密をbyte列として符号化し，検査用の笛を2本添えて数byte程度の秘密を運ぶ．「保管」では，128bit級の秘密を対象に検査用の笛を4本以上とし，物体側の冗長によって経年変化にも備える．いずれのプロファイルでも，採用する笛の本数を変えるだけで同じしくみを使える．

表3　利用プロファイル

プロファイル | 秘密の形 | 検査用の笛 | 規模の目安
カジュアル | 記号の列そのもの | なし | 暗証番号4記号＝基準笛込み5本
標準 | バイト列 | 2本 | 数バイトの秘密
保管 | バイト列 | 4本以上 | 128ビット級＝約40本

# 造形と偽装

笛の素材について，食品接触に適合していて扱いが容易なBambu Lab PLA Pureでプロトタイピングした．吹き込み口が口に触れること，不透明であるため管が透けて見えず偽装の観点でも都合がよいこと，そして安定して造形できていることが，この素材を標準とする理由である．より長期の保管に対しては，PETGが正式な選択肢となる．PETGでも問題なく造形でき，加水分解や紫外線への耐性の観点からPLAより優れているため，年単位で保管したい用途にはPETGを選ぶとよい．さらに耐火性や超長期の保存まで求める場合には，金属3Dプリントへの移行が将来の展望となる．笛は日用品に融合でき，息の吹き込み口と音の出る窓だけが外部に見える形となる．印刷は家庭用の3Dプリンタで完結する．なお，印刷データには秘密がそのまま載るため，スライスと印刷はネットワークから切り離した自分の環境で行うことを推奨する．

# 4 脅威モデル

前提として，方式そのものは公開であり，秘密は断片の値だけである（方式は公開でも秘密さえ守れば安全であるべき，という暗号設計の基本原則に従う）．まず，本研究が主張しないことを明示する．第一に，「吹かなければ読めない」とは主張しない．管の長さは静的な形状なので，保管場所を突き止めた攻撃者は，開口部の計測，透過撮影，CTなどにより，無音のまま内容を読み取れる．この場合の防御は，秘密分散の「規定数未満の断片からは何も分からない」という性質と，断片を別々の場所に置く運用だけである．第二に，読み取られたら痕跡が残る，といった改ざん・複製の検知は主張しない．笛は無傷のまま何度でも読めて複製でき，痕跡は残らない．第三に，音や物体の層による暗号学的な秘匿は一切主張しない．想定する攻撃者の類型と，それぞれをどの層が防ぐかを表4に，各層が秘密を守る力の整理を表5にまとめる．

そのうえで主張する性質は次の4点である．(1)存在の分かりにくさ：この方式を知らない侵入者に対して，日用品への偽装は「どれを調べればよいか」の探索コストを引き上げる．方式を知っている標的型の探索者への効果は限定的であり，(2)持ち物としての単純さ：物体側に電子部品がないため，ネットワーク経由の攻撃やファームウェアの改ざんといった攻撃面がそもそも存在しない．また自分で製造できるため，製造業者に秘密を知られる問題[14]を構造的に避けられる．(3)正規の読み出しが目立つこと：正当な復元の手続きは音を伴うので，立会人の前で儀式として実行できる．これは無音で読み取られる光学タグ群[3][4]との対比であり，秘匿のしくみではなく手続きの性質である．(4)読み出しの手軽さ：正当な利用者は特別な機器なしに，息とスマートフォンだけで復元できる．

表4　攻撃者の類型と，それぞれを防ぐ層

攻撃者 | 可能な攻撃 | 守る層
方式を知らない侵入者 | 目視での物色 | 偽装（探索コストの引き上げ）
方式を知る標的型の探索者 | 計測・CT・透過撮影での無音読み取り，複製 | 秘密分散の規定数の性質＋分散配置のみ
復元の場の盗聴者 | 録音1回で断片を複製 | 運用（管理された場で復元し，復元後は新しい秘密へ移す）
遠隔からの攻撃者 | 物体側に攻撃面なし | ―（本方式が最も強い場面）
読み出しアプリへの攻撃者 | 復元値の窃取・すり替え | アプリと端末を別途保護（オフライン動作）
印刷環境への攻撃者 | 印刷データから断片を取得 | ネットワークから切り離した自己環境での製造
所有者への強要 | 脅して吹かせる・場所を聞き出す | 守れない（明示しておく）

表5　どの層がどれだけ秘密を守るか（守る力nbit＝当てずっぽうで破るには2のn乗通りの試行が必要）

層 | 量 | 秘密を守る力
秘密本体（乱数で生成） | 128 bit | ―（守られる対象）
秘密分散（3分の2で復元） | 断片は各148 bit | 128 bit（規定数未満では何も分からない）
物理担体（音の符号） | 1本約3.7 bit×本数 | 0 bit（守る力はないと明示）
偽装（存在の分かりにくさ） | ― | 0 bit（探索コストを上げるだけ）

# 5 実験

本章では，現時点で実機による実測が済んでいる3つの結果を報告する．すなわち，較正と音域の確定，気温に対する頑健性，および印刷から復元までの通しの実証である．未実施の評価は，7章に今後の課題として整理する．

# 較正と音域の確定

厚壁ヘッド（mini10）の笛を用い，狙った音の高さに合わせ込む較正を行った．長さと音の高さの対応式 f = A/(L+e) に対して A = 86718，e = −11.81 を得た．初期の予備測定（図4）では，狙った音の笛9本すべてが±5セント以内で鳴った一方，17本を一列に並べた条件では安定して鳴る上端がD#7までで，それより高い笛は音が高い方へ引っ張られて不安定であった．そこで壁を厚くし窓を深くしたヘッドへ改良したところ，どの笛も安定して鳴るようになり，安定音域の上端がF#7まで広がった．この厚壁ヘッドでは，較正用の13本すべてが狙いから±6セント（二乗平均平方根で5.9セント）以内で鳴り，F#6からF#7までの13スロットを半音刻みで安定して使えることを確認した．

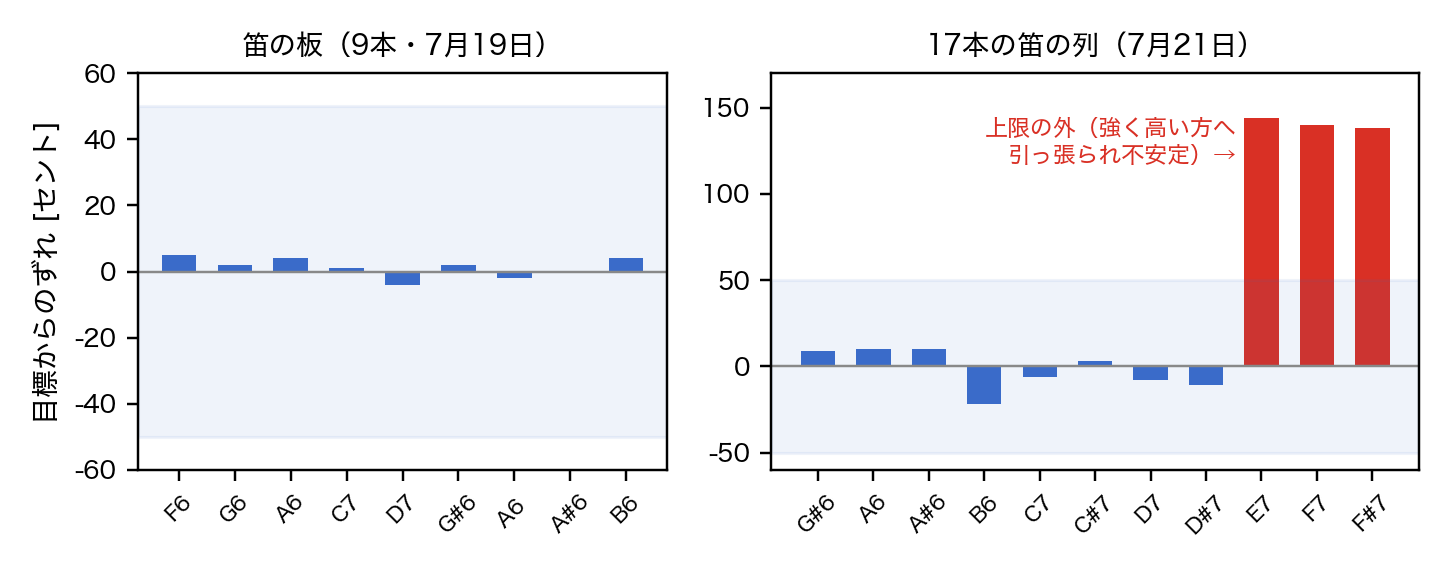
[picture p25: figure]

図4　予備測定（実測）．左：9本は狙い±5セントで鳴った．右：17本の列では上端がD#7で，E7〜F#7は大きく上ずって不安定であった

# 気温が変わっても読めるか

厚壁ヘッドの笛5本（F#6，A6，C7，E7，F#7）を用い，25.2 ℃と41.0 ℃の2つの環境で各笛を6回ずつ吹き，中央値で比べた．音の高さを絶対値で読むと，基準となるC7で41.0 ℃のとき約39セント高くなった．これは音速が絶対温度の平方根に比例することからの予測（約45セント）とよく一致する．一方，基準笛C7との比で読むと，16 ℃近い温度差があっても全笛の残差は±24セント以内に収まり，半音の境界（±50セント）の十分内側であった．したがって，暑い環境でも半音刻みの読み取りは成立し，基準笛による自己補正が働くことを実測で確認した．残る±24セントは，温度そのものよりも2回の測定での息の強さの違いに由来すると見られ，同一の息で吹けばさらに小さくなると考えられる．

# 印刷から復元までの通しの実証

方式が実機で通ることを小さな秘密で実証した．4桁の数「2026」を記号の列としてそのまま符号化し，基準笛C7を先頭に置いた5本の笛を，厚壁ヘッドと食品接触安全のPLA Pureで印刷した．これを先頭から順に吹き，スマートフォンのWebアプリだけで録音・周波数分析・復号を行い，あらかじめ控えておいた検証値（秘密のSHA-256ハッシュ）と一致することを確認した．秘密を符号化し，印刷し，吹いて，スマートフォンだけで取り出して照合するという一連が実機で通ることを確かめた，最初の通しの実証である．

さらに，同じ「2026」の笛をH2Dプリンタと透明なPETGでも印刷したところ，厚壁ヘッド（mini10）の厚い壁のおかげで無事に造形でき，音も鳴ることを確認した．長期保管に適したPETGが，将来の候補ではなく実機で成立する正式な選択肢であることを実装として確かめられた．

# 6 ユースケースシナリオ

本手法は，運ぶ情報量を設計変数として選べるため，気軽な用途から本格的な鍵管理まで幅広く展開できる．ここでは4つの利用場面を，実装の状況（実装済み・作成中・想定）とともに示す．

# カード笛による調の識別とナビゲーション（実装済み）

Chordikaは，1枚が1つの調に対応するカード状の8本笛である．8本を吹くと，読み出しアプリが8音から調を識別し，対応するWebページの案内や，その調のコード進行の再生といった体験を提供する．ここで運ばれる秘密の強度は小さいが，物として吹いて楽しく，音楽の教育や遊びに向く．気軽な用途でも本手法が実際に動くことを示す，実装済みのデモである．

# スプールへの放射状埋め込み（作成中）

3Dプリンタのフィラメントを巻くスプールの円盤に，笛を放射状に埋め込む案を作成中である．スプールを回しながら，外周に並んだ吹き込み口を順に吹くと，演奏するように秘密を読み出せる．ありふれた道具に秘密を溶け込ませ，日常の中に隠す例である．

# 秘密分散によるパートナー間の分散保管（作成中，HeartBeads）

HeartBeadsは，ハート型の小さな置物を2つ用意し，1つの秘密を秘密分散で2つの断片に分けて各ハートに笛として埋め込む案である（作成中）．2人が1つずつ持ち，2つを合わせて初めて秘密を復元できる（2-of-2）．3つに分けて2つで復元できる形（2-of-3）にすれば，1つを失っても復元できる耐性を持たせられる．「2人がそろわないと開けられない」という関係性を，物のかたちで表現する例である．各ハートは約25×32×7 mmで，7 mm厚の中に4 mmの笛を埋め込める．1記号の秘密であれば，各断片は基準笛1本とデータ1本の計2本で足りる．

# 128bitの復元用パスフレーズの保管（想定）

12単語のシード相当の128bitを，多数の笛としてシンプルな箱の底面に埋め込む使い方を想定している．求める強度に応じて笛の本数（128bitなら約40本）を選び，自由に配置する．金庫のように「ここに価値がある」と宣言せず，日常に紛れさせる点が特徴である．これは本手法の容量の上限を，実用の形で示す到達目標である．

# 7 議論と限界，今後の課題

# なぜ音なのか

第一に，読み出し装置であるマイクがすべてのスマートフォンに載っており，正当な利用者の読み出しの敷居が事実上ゼロである．第二に，音を起こす源が呼気であり電源を要しない．第三に，情報が音の高さに載っているため，こする速さに依存する方式[7]よりも人間の操作のばらつきに強い．音の高さは，ゆっくり吹いても速く吹いても変わらない．

# 限界

本方式にはいくつかの限界がある．第一に，容量あたりの物量では金属板1枚や紙片に劣る．ただし日常のカジュアル用途は笛数本から10本で済むため，かさばりが問題になるのは128bit級の保管に限られる．それについても，6.4節で示したように日用品の中に大量の笛を埋め込む余地は比較的確保しやすいと考える．本方式は容量あたりの効率ではなく，偽装のしやすさと読み出しの手軽さを買うための担体であり，性質の異なる予備手段の一つとして併用することが望ましい．第二に，複製が容易で読み取りの痕跡が残らないため，所有者は漏洩に気づけない．第三に，論文として方式を公開する以上，方式を知る攻撃者に対する存在の分かりにくさは限定的である．第四に，読み出しアプリとスマートフォンは信頼せざるを得ない部分であり，物体側に攻撃面がないという利点はソフトウェア側には及ばない．

# 今後の課題（未実施の評価）

本手法の主張を固めるため，以下の5つの評価を計画している．いずれも現時点では未実施であり，ここでは仮想の数値を結果として述べるのではなく，評価の設計として述べる．読み方には，笛を1本ずつ順に吹いて読む方法（以下「順番読み」）と，複数本の吹き込み口を口にまとめてくわえ同時に鳴らして読む方法（以下「同時読み」）の2通りがあり，これらを対象に，物理的な限界の確定，符号設計の確定，セキュリティ主張の定量化，耐久の初期評価の順に進める．

# 複数の笛の同時に鳴らす

複数の笛を同時に鳴らす方式が採用できれば，デコードのための手間を大きく改善可能である．複数の笛を同時に鳴らすと，それぞれの笛に供給される息の圧力と空気量が均一にはならないため，発生する音が単独での音と異なる可能性がある．また，和音として現れる音響スペクトルを分析して複数の笛の音を検出するデコーダーソフトウェアの開発も必要である．これは今後の課題である．

# 読み間違いの傾向と，実効的に運べる量

訓練を受けていない利用者による評価実験を行い，秘密の情報量とデコード成功率，所要時間などを測定し分析するユーザスタディが必要である．これは今後の課題である．

# 隠した物がどれだけ見つかるか

偽装による存在の分かりにくさを，判別性能の指標で定量化することが今後の課題である． CipherFluteを埋め込んだ日用品と，そうでない日用品を混ぜて用意し，方式を知らされていない探索者と，方式を説明された探索者のそれぞれに，秘密の保管物を選ばせる実験による検証が考えられる．

# 時間が経っても読めるか

長期の読み取りに耐えるかを確かめるため，常温での保管，繰り返しの吹奏，および高温高湿の加速環境の後に，音の高さの変化を測る予定である．音を作る鋭い縁の劣化に特に注意し，変化量がスロットの幅（100セント）に対してどれだけの余裕を保つかを評価するとともに，基準笛との比で読む方法で読み間違いが生じないかを確かめる．この評価は，日常利用の標準であるPLA Pureと，長期保管の選択肢であるPETGのそれぞれについて行い，用途に応じて素材を選ぶ判断の根拠とする．

# モスキート音への対応

可聴域外の高い音（いわゆるモスキート音，およそ17〜20 kHz）を使えれば，読み出しの音を周囲に気づかれにくくできる可能性がある．しかし現行のmini10ヘッドは，管長を短くしてもF#7を超えると駆動が破綻して鳴らない見込みである．可聴域外を狙うには，細い風道・短い刃の距離・高い吹圧・小さな共鳴腔からなる専用の高周波ボイシング（ゴルトン笛型）が要る．こうした微細な構造では，FDM方式の造形分解能が性能の限界を決めるため，より細かく造形できる光造形が有利かもしれない．どこまで高い音が出せるかは，短尺のコーム（複数の笛を並べたもの）を実際に印刷し，ナイキスト周波数（サンプリング周波数の半分）までのFFT実測で決着をつける予定である．

# 素材の展望

素材は，まず食品接触に適合していて扱いが容易なPLA Pureでプロトタイピングと日常利用を行うことを当面の標準とする．より長期の保管には，加水分解や紫外線に比較的強いPETGが優れており，実際にPETGでも造形して発音することを確認済みである（5章）．したがってPETGは，将来の候補ではなく，長期保管のための正式な選択肢である．さらに耐火性や超長期の保存まで求める場合には，金属3Dプリントへの移行が将来の展望となる．

# 8 おわりに

秘密情報を日用品に埋め込んで管理するための，電源不要で自作できる3Dプリントの笛「CipherFlute」を提案した．運べる情報量を笛の本数で選べるため，暗証番号のような気軽な用途から128bitの鍵管理まで，同じしくみで幅広く扱える．音や物体の層には秘密を守る力がないことを明示し，秘密を守りたい場合は秘密分散に保護を一元化する誠実な脅威モデルのもとで，符号化・基準笛による自己補正・誤り訂正を含む設計を示した．小さな秘密を印刷して吹き，スマートフォンだけで復号・照合する通しの実証に成功し，25.2 ℃から41.0 ℃でも基準笛との比が半音の幅の内側に収まることを実測で確かめた．今後は，未実施の評価と，可聴域外の音や素材の選択肢を含めた実用化を進める．

未来ビジョン

CipherFluteは，秘密情報を，改まった保管庫ではなく身の回りの日用品にさりげなく宿す文化を切り拓きうる．復元の手続きが音を伴い，立ち会えるという性質は，複数人での鍵の開封式，遺言やデジタル遺産の引き継ぎ，そして楽器としての演奏性を伴う体験型のセキュリティ教育といった，人と人との関係性のなかで秘密を扱う場面に自然に馴染む．音として鳴らし，物として手渡せる秘密は，冷たいデータであった鍵管理を，日常の道具と体験のなかへ溶け込ませていく．なお，本方式を唯一のバックアップにしないことは，引き続き強く注意喚起する．

謝辞

日々の議論と試作に協力いただいた方々に感謝する．

参考文献

[1] [1] Tejada, C., Fujimoto, O., Li, Z. and Ashbrook, D.: Blowhole: Blowing-Activated Tags for Interactive 3D-Printed Models, Proc. Graphics Interface 2018, pp. 131–137 (2018).
[2] [2] Li, D., Levin, D. I. W., Matusik, W. and Zheng, C.: Acoustic Voxels: Computational Optimization of Modular Acoustic Filters, ACM Trans. Graphics, Vol. 35, No. 4, Article 88 (2016).
[3] [3] Li, D., Nair, A. S., Nayar, S. K. and Zheng, C.: AirCode: Unobtrusive Physical Tags for Digital Fabrication, Proc. ACM UIST 2017, pp. 449–460 (2017).
[4] [4] Willis, K. D. D. and Wilson, A. D.: InfraStructs: Fabricating Information Inside Physical Objects for Imaging in the Terahertz Region, ACM Trans. Graphics, Vol. 32, No. 4, Article 138 (2013).
[5] [5] Maia, H. T., Li, D., Yang, Y. and Zheng, C.: LayerCode: Optical Barcodes for 3D Printed Shapes, ACM Trans. Graphics, Vol. 38, No. 4, Article 112 (2019).
[6] [6] Dogan, M. D., Faruqi, F., Churchill, A. D., Friedman, K., Cheng, L., Subramanian, S. and Mueller, S.: G-ID: Identifying 3D Prints Using Slicing Parameters, Proc. ACM CHI 2020 (2020).
[7] [7] Harrison, C., Xiao, R. and Hudson, S. E.: Acoustic Barcodes: Passive, Durable and Inexpensive Notched Identification Tags, Proc. ACM UIST 2012, pp. 563–568 (2012).
[8] [8] Savage, V., Head, A., Hartmann, B., Goldman, D. B., Mysore, G. and Li, W.: Lamello: Passive Acoustic Sensing for Tangible Input Components, Proc. ACM CHI 2015, pp. 1277–1280 (2015).
[9] [9] Laput, G., Brockmeyer, E., Hudson, S. E. and Harrison, C.: Acoustruments: Passive, Acoustically-Driven, Interactive Controls for Handheld Devices, Proc. ACM CHI 2015, pp. 2161–2170 (2015).
[10] [10] Getschmann, C. and Echtler, F.: Seedmarkers: Embeddable Markers for Physical Objects, Proc. ACM TEI 2021 (2021).
[11] [11] Dogan, M. D., Chan, V., Qi, R., Tang, G., Roumen, T. and Mueller, S.: StructCode: Leveraging Fabrication Artifacts to Store Data in Laser-Cut Objects, Proc. ACM SCF 2023 (2023).
[12] [12] SatoshiLabs: SLIP-0039: Shamir's Secret-Sharing for Mnemonic Codes (2017). https://github.com/satoshilabs/slips/blob/master/slip-0039.md
[13] [13] Blockchain Commons: SSKR: Sharded Secret Key Reconstruction. https://developer.blockchaincommons.com/sskr/
[14] [14] Bitcoin Wiki: Casascius physical bitcoins. https://en.bitcoin.it/wiki/Casascius_physical_bitcoins
[15] [15] Lopp, J.: Metal Bitcoin Seed Storage Reviews. https://jlopp.github.io/metal-bitcoin-storage-reviews/
[16] [16] Johnston, R. G.: Tamper-Indicating Seals: Practices, Problems, and Standards, Los Alamos National Laboratory Report (2003).
[17] [17] Eskandari, S., Barrera, D., Stobert, E. and Clark, J.: A First Look at the Usability of Bitcoin Key Management, Proc. NDSS Workshop on Usable Security (USEC 2015) (2015).
[18] [18] Shamir, A.: How to Share a Secret, Communications of the ACM, Vol. 22, No. 11, pp. 612–613 (1979).

CipherFlute：3Dプリント可能な笛による秘密情報の日用品への埋め込みと管理手法の提案

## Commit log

2026-07-01 AI笛作り 再始動: コンパクト音階笛ジェネレータの基盤
    - data/tuning_fsharp.csv: F#チューニング表を復元(消失したgeminiclitestから)
    - fue/notes.py: 音階↔MIDI↔hexマッピング(ToneDecoder auth.htmlとバイト互換, 自己検証済)
    - fue/build.py: straight-bore笛生成 + row/ringレイアウト + 台座
    numpy-stlでメッシュ結合(slicer union方式, FreeCAD boolean不使用)
    water-tight検証あり, プレースホルダヘッドでE2E動作
    - assets/: 生き残った実績ヘッド(slide-recorder-head-v5, v5x8)を退避保存
    要差し替え: 本物のrecorderhead.stl(栗原さん探索中)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
    [slide-recorder-head-v5.stl, slide-recorder-head-v5x8.stl, tuning_fsharp.csv]
2026-07-01 実機モデルv6を組み込み: 笛本体+内挿する棒(length_inside)の実モデルに変更
    - assets/body_v6.stl: OBJから笛本体(14.07x169.48mm)を切り出し部品化
    - assets/rod_v6.stl: 調整棒(7.9x100mm)を参考保存
    - assets/v6_obj/, slide-recorder-head-v6.stl: 受領した原本を退避
    - build.py: 既定本体をbody_v6.stlに、棒直径既定8mm、ボア中心=本体中心で内挿
    ボア中心が本体外形中心とほぼ一致することを確認(2025年の中央寄せ手順と整合)
    - 検証: F#5単音は14.07x14.07x169.48mm、BambuStudioで読込確認済
    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
    [body_v6.stl, rod_v6.stl, slide-recorder-head-v6.stl]
2026-07-01 STL生成時にA1 mini印刷用3mfを自動作成（導電性ゲームコントローラの方式を踏襲）
    - fue/make_3mf.py: 実績あるA1mini設定の骨組みに形状とモデル設定を差し替えて3mf生成
    骨組みのコントローラ3mfは6フィラメント定義で単一素材が弾かれるため、
    BambuStudioがSTLをスライスした単一フィラメント設定を収穫して固定採用
    ベッド180x180中央へ自動配置、単一オブジェクト単一素材へ簡略化
    - templates/a1mini_skeleton.3mf: 骨組み（プラミング一式）
    - templates/a1mini_project_settings.config: 単一フィラメントA1mini印刷設定
    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
    [a1mini_skeleton.3mf]
2026-07-01 目標①コンパクト笛: 実績ヘッド+必要長の閉管で全長を約半分に
    v6の内部形状を解析（断面ASCII可視化）。上端26.5mmが吹き口+ウインドウェイ+
    フィッポル窓の固定ヘッド、その下は音程を決めるだけの直管ボア、下端は閉端と判明。
    - assets/head_v6.stl: v6上端26.5mmを切り出した実績ヘッド（trimeshでz>=143を抽出）
    - fue/compact.py: コンパクト笛=閉端キャップ+中空管(annulus)+ヘッド。棒も死んだ材料も無し
    管長60mmで全長86.5mm（従来169mmの約半分）。高い音ほど短い笛になる
    較正コーム（管長を変えた笛を一列）も生成。1回印刷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
    [head_v6.stl]
2026-07-01 H2D印刷用3mf対応と、音程測定・較正Webアプリを追加
    - make_3mf.py: プリンタ対応(a1mini/h2d)へ一般化。stl_to_3mf(stl, printer=...)
    h2dは栗原さん提供の印刷実績H2D 3mfを骨組みに採用(templates/h2d_skeleton.3mf)
    骨組みのobject_2.model等を掃除しobject_1へ、relsも張り直し。ベッド350x320中央配置
    H2Dのフィラメント最終割り当てはBambu Studio側で調整する前提(MCP/CLIのH2D自動スライスは現状不可)
    a1miniは回帰なし(CLIスライスreturn code 0を再確認)
    - docs/index.html: 音程測定・較正Webアプリ(pitchy)。笛を吹くと周波数・音名・セントを表示
    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
    [h2d_skeleton.3mf]
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2026-07-01 テンプレのフィラメント異常値を修正（見積り時間の乖離の原因）
    harvestした設定に filament_max_volumetric_speed=2（本来21）と density=0 が
    混入しており、CLIスライスだけ吐出を約10倍絞られ時間が過大評価されていた。
    21と1.24へ修正。実機(Bambu Studio)は本物のプリセット値へリセットして印刷するため
    実際の印刷は速い(2時間台)。CLIの見積り時間は当てにせず実機の値を信頼する。
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2026-07-01 compact.py --lengths の間隔バグ修正（開管が接触していた）
    間隔をボア径基準にしていたため、外径14mmに対し狭く笛が重なっていた。
    外径+4mm基準に修正。高音プローブ probe_high を再生成（開管3本が分離）。A1でrc 0。
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2026-07-03 Webデコーダに帯域ルール追加＋リボルバー(ジェノバ)笛の生成器と参考部品
    - docs/index.html: fundamentals() に「最低基音の2倍以上は倍音として無視」を追加
    （1オクターブ設計の前提で、前回6401Hzが基音として残った問題に対処）。整数倍判定も5%へ。
    - fue/revolver_geneva.py: 参考ジェノバ機構を再利用したリボルバー笛の生成器（ロータ/ステータ）。
    - assets/geneva_ref, geneva_ref_split: 参考ジェノバの部品STL（フレーム/歯車/駆動/クランク）。
    [part0.stl, part1.stl, part2.stl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]
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2026-07-08 目標①: mini-c-v2極小笛の実機較正＋パンフルート生成器 fue/mini.py
    - flat極小笛を実機較正: ENDCORR 4.5→1.9、FLAT_FOLD_CORR=3.5mm/折（折り1回ごと実効長縮む）
    C6/E6は狙い±25c以内でドンピシャ。発音性スイートスポット=N2(1折り)。
    - 端穴修正: 蛇行の折返し(半径r)が端キャップを突き抜けて+x端に穴→ H=z_high+r+end_wall で閉端化
    - pan_flute: 1オクターブ(C6..C7)をz方向に積んだ一体ブロック(51×14×56mm・土台なし)。
    mirror_y(段ごとy鏡像=窓の向き)でハーモニカ配置、notesの並べ替えでカリンバ配列(v1/v1.1/v1.2)
    - fold_sweep/flat_comb などの計測コ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
    [recorder-mini-c-v2.stl]
2026-07-08 版STL・印刷3mf/swapをgit管理（コードだけでは再現不可のため）
    - 3D_Print/stl/ … 版スナップショットSTL（v1/v1.1/v1.2・合体）。コードが進化すると
    --pan-flute では再現できないため凍結保存
    - 3D_Print/swap/ … A1 mini印刷用swap.3mf（スライス工程が要り再現不可）
    - 3D_Print/3mf/ … GUI用スライス済み3mf
    - .gitignore: out/ は一時/再生成可で無視、3D_Print/ は版・印刷物として管理する方針を明記
    [mini_foldsweep_C6.swap.3mf, mini_notesweep_N2.swap.3mf, mini_panflute.swap.3mf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]
2026-07-08 トーンホール笛・和音ジグソー・ストリートオルガン・パンフルート版を追加
    fue/mini.py:
    - 吹込口クリアランス（ヘッド-y窓/底の吹込口を胴体で塞がない）＝whistleの吹込口開放。
    折り版は inlet(z<窓下は全周)＋window(-y側のみ)の2切り欠きでleg1ボアのリークを回避。
    - whistle(): 開管トーンホール笛(直管・7穴でC6基音の1オクターブ＋過吹き2oct)。
    - whistle_fold(): 同・1回折り版（89.9×16×8mm・サポート最小・swap化 3mf）。
    - pan_flute に mirror_y（段ごとy鏡像）追加。v1.1(y鏡像C major)/v1.2(カリンバ配列)/
    v1.3(半音込みクロマ・白鍵通常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
    [chordblocks_IVVI.stl, chordwhistle_IVVI.stl, chordwhistle_IVVI.swap.3mf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]
2026-07-13 2オクターブ化(v3ヘッド・大ヘッド較正)とオルガン一体化を反映
    目標①/②/③の数日ぶんの作業ツリーを整理してコミット。
    fue/mini.py
    - MINI_STL を v3(底に外7/内6mmの吸込口 z[-4,0]) へ。窓/ウインドウェイ/共鳴ボアは
    v2と同一で -4mm ずれただけ＝音響不変(C6=1047 / C5=523 で確認)。この吸込口で
    オルガンの管↔ポート接続を精密化できる。
    - 大ヘッド(mini 2倍スケール)を追加: bighead_flat_flute() と較正 f=90165/(2*Lg+5.60)。
    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
    [bighead_cal_v2.swap.3mf, chrom_low_zstack.swap.3mf, eject_only.swap.3mf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]
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2026-07-13 ペンタトニック・ペンダントのストラップ耳を1/3厚(2.33mm)に＋印刷swap
    - strap_lug の既定タブ厚を FOOT→FOOT/3(約2.33mm)。ストラップ紐には
    十分で嵩張らない。穴Ø5貫通・耳の着座は再検証済み。
    - penta_pendant_C6.swap.3mf: MCP slice(box_brim_ams_profile, 65℃/ブリム)
    →make_swap --keep-last。M620×4・サポートはz0.2-0.61のベッド際304点のみ
    （ボア/窓/ストラップ穴は無充填を座標確認）・1.3MB・約55分。A1 mini投入済み。
    [penta_pendant_C6.swap.3mf]
2026-07-14 重大修正: v3ヘッドSTLが180°回転して保存されていた（窓が+y向き＝塞がる）
    栗原さんが印刷したペンタトニック・ペンダントで発覚。v3のSTLはv2に対して
    z軸まわり180°回転しており、窓が+y（flat笛では蛇行ボア側の壁）を向いて
    塞がっていた＝鳴らない。7/13の差し替え時は周波数（管長）だけ確認して
    向きを見ていなかった。
    - mini/recorder-mini-c-v3.stl を(CX,CY)まわりに180°回転して修正。
    修正後はv2と全断面一致（z<0の吸込口追加のみ）、窓は-y向きに復帰。
    - 全消費者はMINI_STL経由なので、この1ファイル修正で全生成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
    [penta_pendant_C6_v2.swap.3mf, recorder-mini-c-v3.stl]
2026-07-14 オルガン: ポート/板/シート穴をØ6化しv3吸込口と同軸整合(前回の無発音を修正)
    前回オルガンが鳴らなかった原因＝笛の吸込口(v3で外Ø7/内Ø6が明確)とリーダー側
    ポートの径・軸がズレて送気が漏れていた。v3吸込口の内径Ø6に全ポートを合わせる。
    - PORT_R 2.0→3.0(Ø4→Ø6)。reader_block/reader_lid/reader_base/reader_monolithic
    のポート、pipe_bankの板穴、punched_sheetのスロットが全てØ6に。各笛の吸込口
    ボア中心(x_i,0)と同軸。
    - pipe_bank: v3吸込口の底(z=-4)を板の上面(z=0)に着座させるよう笛を持ち上げた。
    従来は外Ø7スピゴットが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
2026-07-14 オルガン一体版+テストシートの同時印刷swap(Ø6ポート/1.3mm溝/Ø5シート穴版)
    organ_plate_onepiece_sheet.stl(118.3×144×95, オルガンspigot-up+テストシート)を
    box_brim_ams_profile でスライス→swaps=1。M620×4・展開4.97MB・約2h44m・65℃。
    サポートはz0.2-7.05の最下部のみ(ボア/窓/シート溝は無充填)。薄ピンクPLA(AMS1)で投入。
    [organ_onepiece_plus_sheet_v2.swap.3mf]
2026-07-14 重大修正: 連結板(web)が各笛のボアを貫通して塞いでいた(オルガン無発音の真因)
    栗原さんの指摘「束ねる板状構造が笛の中まで貫通して穴を塞いでいるのでは」が正解。
    organ_panflute の上部連結板(web, z=20-24, y=-4..4, 全x)がボア中心(x_i,0)を通り、
    各笛の共鳴気柱を z=20-23 で分断していた（実測: z20-23がSOLID）。前回の連結チェックは
    head+extだけでwebを含まず見落としていた。
    - organ_panflute に web=True/False を追加。web=True時はボア逃げ穴(半径BORE/2+0.4)を
    開けて桁だけ残す（ボアを塞がない）。
    - pipe_bank(=オルガン本体)は web=Fal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
2026-07-14 web塞ぎ修正版オルガンの印刷swap(単体・swaps=1)
    organ_onepiece_spigotup.stl(連結板のボア塞ぎを修正した版)を単体でスライス。
    M620×4・展開3.3MB・約2h6m・65℃。サポートはz0.2-7.05の最下部のみ(ボア/窓/
    スリットは無充填)。シートは前ジョブの分が使えるため単体。薄ピンクPLA(AMS1)想定。
    [organ_onepiece_v3_webfix.swap.3mf]
2026-07-14 背の高い残留物でも安全な排出swap(Z150版)を追加
    make_swap_only.py --home A の冒頭 G0 Z30 は低い印刷物用で、80mm級の残留物が
    あるとXYホーム時にツールヘッドが衝突する。生成後のgcodeを後処理し、冒頭の
    raise Z を 30→150mm に上げた eject_tallpart_z150.swap.3mf を作成（md5再計算・
    G29無し・排出動作はZ175以上のまま）。中止した88%オルガン(実高~85mm)の排出に使用。
    [eject_only.swap.3mf, eject_tallpart_z150.swap.3mf]
2026-07-14 出力を out/ にフラット統合（3D_Print/ 廃止）＋thin_comb追加
    散在していた出力を一本化：3D_Print/(stl・swap・model3mf) と out/ 内サブフォルダ
    (mm_parts・versions・diag・Geneva Mechanism) をすべて out/ 直下へフラット化し、
    3D_Print/ を廃止。名前衝突は out/ 版を保持（旧版内容はgit履歴に残る）。
    - .gitignore: out/ を丸ごと追跡する方針に変更（STL・印刷3mf/swap・版
    スナップショット・参照OBJまで全部）。例外は PNG レンダーのみ無視(out/*.png)。
    - 移動21・リネーム33(履歴保持)・衝突破棄19・フラット化13。
    - 併せて fue/mini.py に thin_comb（薄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
    [bighead_cal_headsweep.stl, bighead_cal_v2.stl, bighead_cal_v2.swap.3mf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]
2026-07-14 out: chrom2oct_A を v3ヘッド修正後の再生成版に更新(Drive同期ラグ分)
    [chrom2oct_A_C5-Ds5.stl]
2026-07-14 thin_comb に軸オプション追加(Y圧縮)＝窓形状を保ったまま薄型化
    栗原さんの指摘どおり、幅(Y)方向に潰すと:
    - 窓は-y面にあるので窓の形(x-z)が完全に不変（Z圧縮は窓が潰れる）
    - 丸ボアが縦長楕円になり、寝かせ印刷でボア天井スパンが短く自己ブリッジしやすい
    （スライスでサポートがZ版の約1500→599点に減）
    断面比較で確認。thin_comb(axis="z"|"y")、CLI --thin-axis。出力は
    mini_thin_comb_<音>_<軸>.stl（旧 mini_thin_comb_C6.stl は軸付き名に置換）。
    [mini_thin_comb_C6_y.stl, mini_thin_comb_C6_z.stl]
2026-07-14 Y圧縮 極薄コーム(C6)の印刷swap(swaps=1・ピンクPLA)
    mini_thin_comb_C6_y.stl(幅7/5/4/3/2mm)をスライス→swaps=1。M620・約32分。
    Z版よりサポート少(599点)・窓形状保存。「Y方向にどこまで薄く鳴るか」実測用。
    [mini_thin_comb_C6_y.swap.3mf]
2026-07-14 薄型ネイティブ平型ホイッスル(緊急警報用)の生成器 fue/whistle.py
    実績ミニヘッドを潰す方式は7mmが下限と確定したため、最初から薄く設計する
    ネイティブ フィッポル(緊急ホイッスル型)を新設。幅広×薄・平スロットボアで
    -y側に外部windwayの隙間を確保、45°ひさし窓＋縦windwayで立て置き印刷=サポート0。
    TPU前提で壁1.2mm。voicing_comb で flue/cutup/offset を振って発音組合せを探す。
    判明: TPU安全壁だと windway が厚み方向に約4mm積むため T≈8mmが下限
    （7mmミニより薄くはできない）。sub-7mmは windway を面内溝にする次案が要る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
    [whistle_voicing_L26_T8.stl]
2026-07-14 スマホケース一体7mm警報笛のPoC(fue/phonecase.py)＋ホイッスルコームswap
    サブプロジェクト③「日常品に笛を仕込む」。パラメトリックな簡易ケース殻(背板+側壁トレー・
    TPU前提壁2mm)の+x側面周辺に実績7mm flat笛(C6)を一体化(窓は外向き・雑PoC)。
    機種寸法 phone_w/h/t で調整可。out/phonecase_whistle_demo.stl(82x154x10mm・watertight)。
    併せて薄型ホイッスルT8ボイシングコームのswaps=1 swap(M620・2.4MB・約1h31m・サポート0)。
    [phonecase_whistle_demo.stl, whistle_voicing_L26_T8.swap.3mf]
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2026-07-15 一様に薄い(頭も胴も5mm)平型ホイッスル thin_whistle＋Pixel7ケース
    段付き版(頭8mm)は「頭が薄くならなければ意味がない」と却下 → やり直し。
    ミニヘッド実測でwindwayが厚1.5mm・-y寄り・ボアとは別z(軸方向に前後)と判明。
    これに倣い thin_whistle を実装：windwayをボアの-y横でなく軸方向(z)下に置き、
    平ボア(幅広×薄)＋45°ひさし窓で、頭も胴も一様T=5mm(7mmミニより薄い)。
    立て置き印刷サポート0点・予測約2.7kHz(警報向き)。thin_voicing_comb で
    flue/cutup/labiumオフセットを振って発音組合せを実機探索する。
    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
    [phonecase_pixel7_whistle.stl, thin_whistle_voicing_L24_T5.stl, thin_whistle_voicing_L24_T5.swap.3mf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]
2026-07-15 薄型ホイッスルの voicing×幅サーチコーム(size_search_comb)＋swap
    [thin_whistle_search.stl, thin_whistle_search.swap.3mf]
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2026-07-15 オルガンの笛を直管→実績の1回折れ(flat_flute N=2)に置換＝アサイン変更
    栗原さんが分解して直接吹いた結果、直管の笛はこのオクターブでほとんど鳴らな
    かった(レファラシのみ)。直管がこの音域で安定発音するかは未確認だった一方、
    1回折れ(flat_flute N=2・丸ボア面内蛇行)は発音実績あり。
    - flat_flute に flatten=False を追加(寝かせず立てたまま=オルガンの縦笛用)。
    - organ_panflute に fold=2(既定)。実績の折れ笛を立てて縦笛に。吸込口Ø6は
    中心(0,0)でポートと同軸。音は flat_flute N=2 較正(C6=1047等/proven)。
    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
    [organ_onepiece_folded.swap.3mf, organ_onepiece_spigotup.stl]
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2026-07-15 オルガン折れ版を0.20mm積層で再スライス(swap=1)＋新作リコーダーhalf-v2のswap
    organ_onepiece_folded_020.swap.3mf: box_brim_ams_020_profile(layer_height0.28→0.20)で
    再スライス。M620・展開5.3MB・約3h11m・折れ域サポート0点。シートは前回分を再利用(再印刷不要)。
    [organ_onepiece_folded_020.swap.3mf, recorder-mini-c-v3-half-v2.swap.3mf]
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2026-07-16 オルガン無発音を修正(笛胴を重ねて密閉スラブ化)＋スマホケース笛を短辺縁へ再配置
    (1)オルガン: 笛間の1mm隙間で0.5mmボア壁が大気に漏れ全笛無発音だった(実機で確認,直管版も
    同症状)。flat_flute に owall を追加し胴をx方向に増厚、ピッチ8で隣と0.5mm重ねて boolean
    union で一体スラブ化＝実績パンフルートと同じ密閉に。隣接ボア中間7箇所すべて中実を検証。
    ポート/レールはピッチ8のまま対称増厚なので既存シートはそのまま再利用可。organ.OWALL=0.75。
    (3)スマホケース: 笛の一体化面を背面→『短辺(下端)の縁』へ変更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
    [organ_onepiece_spigotup.stl, phonecase_pixel7_whistle.stl]
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2026-07-16 オルガンのデモ楽譜シート＝和音で完結する短い曲(C major)を追加
    owall密閉修正でオルガンが実機発音した達成を受けて、和音で終止する短い曲の穴あきシートを設計。
    fue/organ_song.py：SONGを音名で定義→pipe_bankの逆順対応(C6→port7…C7→port0)でポートに変換→
    organ.punched_sheetで生成。曲=ド-ミ-ソ-ラ-ソ(上昇)→ミ-ファ-ミ-レ(下降)→ドミソ→ドミソド'(最終和音)。
    外形64×120×1mm・13ステップ・watertight。実機で逆に鳴ったら reverse_ports/reverse_time で反転可。
    [organ_song_cadence.stl]
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2026-07-16 半割り笛の音階コーム(A major)と限界探索コームを追加
    実測較正(f=A/(L+e))から length_for_note で各音の管長を逆算。
    scale_comb: A majorオクターブ(A6->A7)=較正範囲に収まる1oct。管長61.5〜36.2mm・8本。
    limit_comb: 既知36-64mmを超え28〜92mmの9本。短側=高音オーバーブロー限界、長側=低音駆動限界
    を実測で確定する用。予測5206〜1098Hz(両端は外挿)。halfcut.py に --scale/--limit を追加。
    どちらもD字断面・平置きサポートフリー・y密着一体(watertight)。
    [halfcut_limit_comb.stl, halfcut_scale_Amajor.stl]
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2026-07-17 半割り笛 Eb major(D#6→D#7)フルオクターブ音階コームを追加
    実測で確定したクリーン音域 F6〜E7(比1.93=長7度)に、フルオクターブを最も収める置き所として
    Eb major(D#6→D#7)を採用。8音中7音がクリーン域、最低音D#6(82.5mm)のみ弱い。上端D#7(46.7mm)は
    オーバーブロー域から離れ安全で、E6-E7(上端E7が境界)より良い。halfcut.py に EB_MAJOR/--scale-eb 追加。
    out/halfcut_scale_Ebmajor.stl(8本・82.5×53.9×4mm・watertight)。
    [halfcut_scale_Ebmajor.stl]
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2026-07-23 CipherFlute復号ページを改修（push-to-talk逐次読み・SHA-256のGET自動入力・不要項目削除）
    - ?sha256=（?hash=も可）で照合用SHA-256を照合欄に自動入力。?spf/?mode/?parityも上書き可
    - 高音プローブ等の測定プリセット表・結果書き出し・和音記録を撤去しCipherFlute復号に特化
    - 押しながら順に吹くpush-to-talk方式（1本あたり秒数を選択）。離すと自動復号。拍表示＋振動
    - 吹いた順・先頭を基準笛としてpositionsKnown=trueで復号（周波数ソートの誤りを修正）
    - cipher_config.jsonを往復デモに一致させ記号列モード・パリティ0へ（実機ブラウ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
2026-08-04 冒頭の黒を出さず、最初から両方が映るようにした
    これまでは和音側を黒画面で待たせて拍を合わせていたので、冒頭1.755秒は片側だけが
    映っていた。待たせるのをやめ、代わりに旋律側の頭を同じ1.755秒ぶん切り落とす。
    ずれの量は変えていないので同期はそのままで、1フレーム目から両方に映像が出る。
    終わりは短いほうに合わせる。vstack/hstackにshortest=1、amixにduration=shortestを
    渡した。これをしないと、先に終わったほうの最後のフレームが残って止まって見える。
    長さは22.5秒から20.7秒になった。旋律の最初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
2026-08-06 鳴らなかった笛を「除外」ではなく「飛ばし」にした（v8）
    栗原さんの指摘。テンポ判定で除外していたもののうち、笛が不具合で鳴らなかった場合は
    そこに笛が存在したのだから、位置を保って消失として扱い、パリティで訂正させるべきである。
    扱いを3つに分けた（tempo_filter.js）
    - drop（除外）… 拍から外れた短い音。咳や物音であって笛ではないので位置ごと取り除く
    - skip（飛ばし）… 拍には乗っているのに読めない音。そこに笛はあったが鳴らなかった
    - keep（採用）… そのまま使う
    さらに、拍の位置に音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
2026-08-09 Recorika A♭をTPU for AMSで刷るためのプロファイルを起こした
    2026/7に半割り笛をTPUで刷って無音だった件を調べ直した。あれはTPU固有の失敗ではなく、
    0.5mm壁を線幅0.42〜0.45で刷ったために壁が単線で途切れて気密が出なかったもので、
    同じ日にPETGも黒PLAも同様に無音だった（[[ai-fue-halfcut-05mm-wall-fail]]）。
    いまのmini10形状は壁を実測すると1.22mm（ボア3.66×2.52、床0.48、天井0.98）で、
    当時の0.5mm壁とは別物である。TPUの記録が処方していた「壁1.2〜2mm」を既に満たしている。
    そのうえで前回のTPU設定から次を改めた。
    壁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
    [recorika_Ab_tpu_h2d.gcode.3mf]
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2026-08-15 子画面の潰れと、映像が途中で切れる誤りを直した
    ★縦に潰れていた★
    コマごとに切り取る高さを変えていたため、動画にするとき ffmpeg が最初のコマの
    大きさへ合わせて縦に圧縮していた。高さを最初に決めて固定し、必要な行数ぶん
    （最低3行）と「認証成功」の行を先に確保する。
    ★映像が14秒で切れていた★
    overlay の shortest により、子画面の録画の長さで出力そのものが終わっていた。
    音声は最後まで残るので format=duration では気づけない。外すと今度は子画面の
    長さまで伸びたので、出力の長さを実演の映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
